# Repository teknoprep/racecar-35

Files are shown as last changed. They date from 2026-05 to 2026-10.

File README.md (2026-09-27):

# racecar-35

Two-MCU dash for a track car.

**Latest Rev C target:** add a third MCU—an on-board ESP32-S3 WiFi coprocessor—to
upload directly from Teensy SD over local SPI, while the screen keeps WiFi for
unchanged OTA and optional upload fallback. Add a replaceable CR2032 on Teensy VBAT
for RTC retention. This is an architecture update, **not an implemented new uplink**;
see [WiFi/RTC requirements](hardware/teensy-integrated-revc/WIFI_RTC_ARCHITECTURE.md).
Rev C has an **internal WiFi PCB antenna** and **all screw terminals on the LEFT
edge**, labelled by function/pin. **Actual 130 × 140 mm routed electrical CAD,
Gerber/drill ZIP, BOM, assembly documents and an assembled view now exist:**
[Rev C engineering prototype](hardware/teensy-integrated-revc/README.md).
It passes ERC/DRC/netlist checks but is unbuilt and not independently approved;
new WiFi firmware, oil/coolant conversions and bench validation remain.
A/B are retired under `hardware/_archive/`, not alternative orderable designs.

**WiFi-only on the CrowPanel since v0.1.148.** Ethernet/W5500 support
and the Internet-route setting have been removed. WiFi credentials/status are
always visible; old saved Ethernet selections are ignored. NTP/OTA/uploads run
through the screen. See [CLAUDE.md](CLAUDE.md) and [BUILD.md](BUILD.md) for current
architecture/toolchains; much of the original overview below is historical.
The integrated Rev C board is an unbuilt electrical prototype. **v0.1.149 source adds
opt-in AFR/lambda logging from the external AEM 30-0300 gauge output** (WHITE signal
and BROWN reference), not a direct oxygen sensor. A protected/scaled ADC input
is implemented in Rev C with clamps and powered-off isolation, but requires
independent review and physical validation. See
[AFR_INTERFACE.md](hardware/teensy-integrated-revc/AFR_INTERFACE.md).

```
+--------------+   Serial2 (UART)   +--------------+   Serial3 (UART)   +--------------+
|              |  pin 7 RX2 / 8 TX2 |              | pin 14 TX3 / 15 RX |              |
|  u-blox GNSS | <----------------> | Teensy 4.1   | -----------------> | CrowPanel S3 |
|              |   38400/9600 baud  |              |    115200 baud     |  7" 800x480  |
+--------------+                    +--------------+                    +--------------+
                                                                         (LovyanGFX UI)
```

The Teensy reads GNSS PVT data from a SparkFun u-blox module and publishes
ASCII CSV lines on Serial3. The CrowPanel ESP32-S3 listens on UART0 and
renders the dash with LovyanGFX. UART is one-way, Teensy → CrowPanel.

## Repository layout

| Path | Project | Target |
| --- | --- | --- |
| `platformio.ini`, `src/main.cpp` | Teensy firmware | Teensy 4.1 |
| `crowpanel-ui/platformio.ini`, `crowpanel-ui/src/main.cpp` | Dash UI | CrowPanel ESP32-S3 7" v3.0 |

Each subproject is its own PlatformIO env. Build them from their own
directory.

## Wire protocol

ASCII CSV lines, `\n`-terminated, 115200 8N1, ~5 Hz:

```
GPS,<fix>,<sats>,<lat_deg>,<lon_deg>,<speed_mph>,<heading_deg>
```

| Field | Meaning |
| --- | --- |
| `fix` | 0=None 1=DR 2=2D 3=3D 4=3D+DR 5=Time-only |
| `sats` | satellites in view |
| `lat_deg`, `lon_deg` | decimal degrees, 6 decimals |
| `speed_mph` | mph, 1 decimal |
| `heading_deg` | course over ground in degrees, 1 decimal |

Example: `GPS,3,12,40.123456,-74.123456,67.5,123.4`

## Wiring

| Link | From | To |
| --- | --- | --- |
| GPS → Teensy | u-blox TX | Teensy pin 7 (Serial2 RX) |
| Teensy → GPS | Teensy pin 8 (Serial2 TX) | u-blox RX |
| Teensy → Dash | Teensy pin 14 (Serial3 TX) | CrowPanel UART0 RX (GPIO 44) |
| Dash → Teensy | Teensy pin 15 (Serial3 RX) | CrowPanel UART0 TX (GPIO 43) |
| Common ground | Teensy GND | CrowPanel GND |
| Power | USB-C to CrowPanel | (Teensy powered separately by its own USB) |

Teensy ↔ CrowPanel is two devices both on 3.3 V logic — no level shifter.
A common ground is required.

## Flashing

### Teensy firmware

```powershell
pio run -t upload
```

The first time, you may need to physically tap the program button on the
Teensy. After that, `teensy_reboot` resets the board over USB.

### CrowPanel firmware

> [!IMPORTANT]
> **Disconnect the two UART jumpers between the Teensy and the CrowPanel
> before flashing the CrowPanel.** UART0 (GPIO 43/44) is shared with the
> CH340 USB-serial chip used to upload firmware. If the Teensy is
> connected, both devices will drive the same wire and the upload will
> fail or corrupt.

```powershell
cd crowpanel-ui
pio run -t upload
```

After the upload finishes ("Hash of data verified"), unplug USB-C, wire
the Teensy back in, then power the CrowPanel via USB-C again.

## End-to-end smoke test

1. Flash both firmwares (Teensy first or CrowPanel first, doesn't matter).
2. Wire everything per the table above. Double-check common GND.
3. Power the CrowPanel via USB-C. The dash should boot and show 0.0 mph
   with `LINK STALE` in red — that's correct: nothing on the wire yet.
4. Plug in the Teensy. Within a second, `LINK` should turn green and you
   should see the speed/heading/lat/lon updating at ~5 Hz, even with no
   GPS fix yet (those fields will read 0 until `FIX` shows `2D`/`3D`).
5. Take it outside or near a window. `FIX` will go yellow → green and
   `SATS` will climb as the module gets a fix.

## Debugging

- Open `pio device monitor` on the Teensy to see the same CSV stream the
  Teensy is sending — useful for confirming the GPS half is working
  before chasing UART issues on the dash side.
- Open `pio device monitor` on the CrowPanel (with the Teensy
  disconnected, and a `Serial.print` of incoming bytes added if you want
  to see what's hitting UART0). Note that with `ARDUINO_USB_CDC_ON_BOOT=0`
  the CrowPanel's `Serial` object IS UART0 — the same wire the Teensy
  uses — so you can't tap it from USB and the Teensy at the same time.
- If the panel boots black, retry the power-only test (USB-C only, no
  Teensy wires) to confirm the panel itself is alive before suspecting
  firmware.

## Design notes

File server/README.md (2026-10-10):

# racecar-35 cloud receiver

Tiny FastAPI service that accepts NDJSON session uploads from the race dash
and stores them on disk. Designed to run as a single Docker container behind
an nginx reverse proxy that terminates TLS — **this service speaks plain HTTP
only**, on port `8089`.

For initial LAN testing you can point the dash directly at this port over
plain HTTP without nginx in the path. Set Internet Protocol = HTTP and use the
LAN IP of the host running the container.

## Endpoints

| Method | Path | Purpose |
| --- | --- | --- |
| POST | `/upload` | Whole-file AfterRace upload (NDJSON). Overwrites by `X-Session-Id` so retries are idempotent. |
| POST | `/stream` | Live-stream append (NDJSON). Reserved for the future Ethernet-mode live path. |
| POST | `/upload/aim` | **Import AiM Race Studio files.** Body = the raw `.xrk` or AiM `.csv`; name via the `X-File-Name` header or `?filename=`. Converted to session NDJSON server-side and filed exactly like a dash upload, so laps/map/replay/coaching all work. The untouched original is archived under `/data/aim/<user>/`. `?coach=0` skips the auto-coach pass. |
| GET | `/` | HTML index of the sessions you're allowed to see (see *Session visibility*). |
| GET | `/sessions` | JSON listing of the sessions you're allowed to see. |
| GET | `/sessions/<user>/<file>` | Download one session file. |
| GET | `/sessions/<user>/<file>/laps` | Auto-detected lap list + times for the review UI (JSON). Start/finish is detected from the GPS trace — no track table needed. |
| POST | `/sessions/<user>/<file>/ai` | **AI corner analysis.** Body `{prompt, region:{points:[[lat,lon],…]}, model?}`. Extracts the telemetry inside the drawn polygon, computes per-lap metrics (entry/min/exit/max speed, time, distance, peak lateral/longitudinal g, max rpm), and asks the LLM for coaching. Returns `{ok, model, metrics, answer}`. Requires `RACECAR_AI_API_KEY`. |
| GET | `/ai/models` | `{enabled, default, models:[{id,name}]}` — the model picker for the review UI. `default` is the resolved analysis model (Haiku 5.5) and is always included in `models`; the gateway catalogue is fetched on a worker thread (cached ~10 min). |
| GET | `/health` | Healthcheck for Docker / nginx. Returns `{"ok":true}`. |
| GET | `/account` | Per-user account page (any signed-in user): view + copy + refresh your upload API key. |
| GET | `/account/apikey` | JSON `{email, api_key}` for the signed-in user (creates a key if missing). |
| POST | `/account/apikey/refresh` | Regenerate the signed-in user's API key. Old key stops working immediately. |
| GET | `/admin` | Admin portal (admins only): add authorized Gmail accounts, grant/revoke admin. |
| GET | `/admin/sessions/targets` | Emails an admin may reassign a session to (all known accounts). Admins only. |
| POST | `/admin/sessions/move` | **Reassign a session to another user.** Body `{user, filename, target}` (target = destination email). Moves the `.ndjson` **and its AI history** into the target's dir; refuses if the target already has a same-named session. Admins only. |
| POST | `/admin/users` | Add an account or change its admin flag (JSON `{email, is_admin}`). Admins only. |
| POST | `/admin/users/delete` | Remove a managed account (JSON `{email}`). Admins only. |
| GET | `/admin/user/<email>` | Per-user screen: ALL USERS toggle + manage who this account can see. Admins only. |
| GET | `/admin/canbus` | CAN-capture portal: upload + list captures, links to review. Admins only. |
| POST | `/admin/canbus/upload?name=` | Upload a CAN sniffer CSV (raw body). Admins only. |
| GET | `/admin/canbus/<file>` | Review a capture: per-ID stats + byte/word signal inspector. Admins only. |
| GET | `/admin/canbus/<file>/data` | Parsed JSON (per-ID frame counts, byte ranges, downsampled series). Admins only. |
| GET | `/admin/canbus/<file>/raw`  | Download the raw CSV. Admins only. |
| POST | `/admin/canbus/<file>/delete` | Delete a capture. Admins only. |
| POST | `/admin/users/visibility` | Set the ALL USERS flag (JSON `{email, view_all}`). Admins only. |
| POST | `/admin/users/grant` | Let an account see another's sessions (JSON `{email, target}`). Admins only. |
| POST | `/admin/users/revoke` | Remove a granted account (JSON `{email, target}`). Admins only. |
| GET | `/docs` | OpenAPI / Swagger UI for poking around. |

## Access control / admin portal

There are three layers, lowest to highest precedence for *display*, but all
additive for *who may sign in*:

1. `RACECAR_ADMIN_EMAILS` (env) — **bootstrap admins**. Always allowed to sign
   in, always admin, and the only accounts that can use `/admin` on a fresh
   deploy. Editable only by changing `.env` + restarting.
2. `RACECAR_ALLOWED_EMAILS` (env) — optional legacy static allowlist (non-admin).
3. **Managed accounts** added from the `/admin` portal at runtime, persisted to
   `/data/users.json` (survives rebuilds; no redeploy needed to add a driver).

If **none** of the three are set, the server stays in open dev mode (any
verified Google account can sign in). Setting `RACECAR_ADMIN_EMAILS` activates
the allowlist: only listed/managed accounts can sign in from then on.

The `/admin` link appears in the header for admin accounts. From there an admin
can add a Gmail address (optionally as admin) and toggle/remove any
portal-managed account. Bootstrap admins show as `locked` and can't be edited
from the UI.

## Session visibility

The sessions index (`/` and `/sessions`) is **scoped per account**:

- Every account always sees **its own** uploaded sessions.
- **Admins** (bootstrap or portal-granted) see **everyone's** sessions.
- A non-admin account can be granted visibility of specific other accounts, or
  of **everyone**, from the admin portal.

In `/admin`, click a managed user (or its **manage** button) to open
`/admin/user/<email>`. That screen has:

- an **ALL USERS** checkbox — tick it and the account sees every user's
  sessions, with no list to maintain (`view_all` on the account record);
- a **can-view list** — type/pick another account's email and **add user** to
  share just that account's sessions; **remove** revokes it.

Visibility is enforced on the index, the JSON listing, downloads, the review
page, the parsed-data endpoint, and web deletes. Device uploads via `X-API-Key`
are unaffected. Settings persist in `/data/users.json` (fields `view_all` and
`can_view`).

## Per-user API keys

Every authorized account gets a unique 12-char API key, minted on first Google
login (or when an admin adds the account) and persisted in `/data/users.json`.
A user views/refreshes their own key from the **account** link in the header
(`/account`). Refreshing replaces the old key immediately.

Send the key as `X-API-Key` on uploads. When no `X-User-Email` header is
supplied, the upload is filed under the key owner's email automatically. This
is independent of the global `RACECAR_API_KEY` env var (which, when set, gates
all ingestion with a single shared secret).

## Request headers honored

These match the dash and Teensy firmware exactly:

```
Content-Type:  application/x-ndjson
X-API-Key:     <secret>           (optional; required if RACECAR_API_KEY is set)
X-User-Email:  user@example.com   (used to namespace files on disk)
X-Session-Id:  1714942567         (used in the saved filename; usually unix epoch)
X-Track-Name:  Lime_Rock_Park     (used in the saved filename)
```

## On-disk layout

```
/data/sessions/<email>/<session_id>_<track>.ndjson
/data/aim/<email>/<session_id>_<original name>.xrk|.csv
```

Where:

- `<email>`, `<track>` are sanitized — anything outside `[A-Za-z0-9._@+-]` becomes `_`.
- `<session_id>` is whatever the dash put in `X-Session-Id` (the start unix epoch).
- `/data/aim/` holds the **unmodified original** of every AiM import, so the
  logger file survives even if a conversion is later found wanting.

## Importing AiM Race Studio files

Race Studio gives you a run in two containers and `POST /upload/aim` takes both:

| | `.xrk` | AiM `.csv` |
| --- | --- | --- |
| how it is read | `libxrk` (chunked, per-channel timecodes, laps table, metadata) | stdlib `csv` |
| units | **metric** — altitude m, speed m/s, WATER_TEMP C, OIL_PRESSURE bar | **imperial** — altitude ft, speed mph, WATER TEMP °F, OIL PRESSURE psi |
| lap boundaries | `laps` table | `Beacon Markers` preamble row |
| sample rate | resampled to 20 Hz | native (20 Hz) |

The two containers do **not** agree on units, so every mapping is driven by the
file's own declaration — Arrow field metadata for `.xrk`, the units row for
`.csv` — and a mismatch aborts the import instead of silently writing wrong
numbers. Cross-check on the reference files: the same run reads 515.25 ft
(CSV) and 157.04 m (XRK) of altitude. (One quirk: AiM labels the `.xrk` AFR
channel `lambda` while the samples are actually A/F, so that channel is
disambiguated from its own values rather than from the label.)

Imported sessions then go through the ordinary `validate_ndjson_body` gate, and
the server's own lap detection reproduces AiM's segment times to within 50 ms.

```bash
# import an .xrk for a given user
curl -X POST 'http://HOST:8089/upload/aim' \
     -H 'X-File-Name: JJ_Summit Main_20261009_152404_a_0318.xrk' \
     -H 'X-User-Email: user@example.com' \
     --data-binary @JJ_Summit_Main.xrk
# {"ok":true,"source":"xrk","session":"1791559444_Summit_Main.ndjson",
#  "samples":30678,"laps":16,...}
```

## Run with Docker

```bash
cp .env.example .env
# edit .env if you want to require an API key

docker compose up -d --build
docker compose logs -f
```

The container exposes port `8089` on the host. Data is persisted to `./data/`
on the host. Health probe runs every 30 s.

To check that everything is responsive:

```bash
curl http://localhost:8089/health
# {"ok":true,"service":"racecar-35 cloud","data_dir":"/data"}
```

## Configure the dash for this server

Settings → cloud rows on the dash, when **Internet mode = WiFi**:

```
Cloud host:   <LAN IP of the docker host>   e.g. 192.168.1.50
Cloud port:   8089
Protocol:     HTTP                          (HTTPS is the default; switch to HTTP for LAN test)
User email:   anything you want (used to namespace files)
API key:      match RACECAR_API_KEY, or any value if RACECAR_API_KEY is empty
Record cloud: ON
```

Then TOOLS → **Start test mode** → wait ~10 s → **Stop test mode**.

If everything is wired up correctly, you'll see (in `docker compose logs -f`):

```
INFO racecar.cloud: received 192.168.1.123 mode=w email=anon session=1714... track=TEST bytes=14352 lines=58 -> sessions/anon/1714..._TEST.ndjson
```

And opening `http://<host>:8089/` in a browser shows the new session in the table.

## Basemap for the session map (review page)

The review page's Leaflet map takes its tiles from `RACECAR_MAP_TILES`, and the
default is **keyless Esri imagery** — the same source `/tools/sfpicker` and the
lineview popout already use.

Why it is configurable: the previous basemap was CARTO's `dark_nolabels`, and
CARTO's raster basemaps now **require an API key**. Without one,
`basemaps.cartocdn.com` returns a 256x256 **“API KEY REQUIRED”** placeholder
tile instead of map data — the giveaway is that two different tile coordinates
come back byte-identical. So no key is needed at all; the map simply moved to a
provider that does not require one.

Read at startup, so **`docker compose up -d` is enough — no `--build`**:

| Var | Default | Notes |
| --- | --- | --- |
| `RACECAR_MAP_TILES` | Esri `World_Imagery` | Tile URL template; empty = no basemap |
| `RACECAR_MAP_ATTRIB` | `Imagery © Esri, Maxar, Earthstar Geographics` | Attribution shown in the corner |
| `RACECAR_MAP_MAXZOOM` | `19` | Leaflet max zoom |
| `RACECAR_MAP_DEM` | AWS `terrarium` tiles | Elevation for `/track3d`; `none` = flat ground |

Dark map instead of imagery (keeps the old look; Esri's canvas basemaps have
native data only to z16, so zooming past that upscales):

```bash
RACECAR_MAP_TILES='https://server.arcgisonline.com/ArcGIS/rest/services/Canvas/World_Dark_Gray_Base/MapServer/tile/{z}/{y}/{x}'
RACECAR_MAP_ATTRIB='Tiles (c) Esri'
```

⚠️ Esri tile paths are `/{z}/{y}/{x}` (row/col) — **not** `/{z}/{x}/{y}`.
Swapping those two gives you a map of the wrong place, not an error.

## 3D drive view (`/track3d/<user>/<file>`)

Opened from the review page's **3D drive ↗** button (or copied straight out of
the URL bar). It is the same session in the driver's seat: satellite imagery
**draped over real terrain**, the line you drove painted on the ground, brake /
apex / throttle markers, a HUD (mph, rpm, lap, lap time, altitude) and a chase
camera that drives the trace on the same playback clock — play/pause,
¼×–8×, scrub, zoom. Drag the map and the camera releases so you can look
around; **follow** grabs it back.

Layers are toggles on one map, so nothing is refetched when you flip them:
**satellite** off = black ground (the lines read like a light table), **terrain**
off = flat. Both choices are remembered per browser (`localStorage`). The same
**satellite** checkbox sits under the map on the review page and on the lineview
popout.

The ground is raster imagery draped on a surface mesh — **not** photogrammetry:
true 3D buildings/trees would need a keyed source such as Google Photorealistic
3D Tiles. Elevation comes from `RACECAR_MAP_DEM` (keyless AWS `terrarium`),
native to ~z15.

Hand a lasso polygon over (`?pts=lat,lon|lat,lon|…`, which the review-page
button does automatically when a section is circled) and the page also draws the
**ideal line** (fastest real traverse on record, green) and **your session best
through it** (blue) over the ground, with that lap's brake point — the
"what I did vs what the data says is fastest" comparison, in the driver's view.

## AI corner analysis (review page)

The review page has an **AI Corner Analysis** card. Click **circle a section**,
then drag a loop around a corner (or a set of corners) on the track map — the
samples inside that polygon, **across every lap**, become the context for an LLM
coaching prompt. Preset buttons cover the common questions (brake zones, entry
speed, exit speed, best line, consistency) and there's a free-text box for
anything else.

How it works:
1. The browser sends the drawn polygon + question to `POST /sessions/<u>/<f>/ai`.
2. The server reprojects every sample through the same auto lap-detector the
   review page uses, keeps the points inside the polygon, and computes **per-lap
   metrics** for that section: entry / min / exit / max speed, time, distance,
   peak lateral & longitudinal g, max rpm.
3. Those metrics become a compact table in a race-engineer system prompt, sent to
   **Open WebUI** (`ai.blueuc.com`) via its OpenAI-compatible
   `POST /api/chat/completions` (Bearer key). The reply is rendered in the card.

**Config (`.env`):**

| Var | Purpose |
| --- | --- |
| `RACECAR_AI_API_KEY` | Open WebUI API key. **Blank = the AI card is hidden entirely.** |
| `RACECAR_AI_BASE_URL` | Open WebUI base (default `https://ai.blueuc.com`). |
| `RACECAR_AI_ANALYSIS_MODEL` | Model for **AI corner analysis + the ideal-line AI** (and the model the review dropdown preselects). **Blank = Haiku 5.5.** |
| `RACECAR_AI_COACH_MODEL` | Model for the **automatic coach checklist** (runs on every upload). **Blank = Haiku 5.5.** |
| `RACECAR_AI_HAIKU_MODEL` | The built-in Haiku id used by the two vars above (default `anthropic.anthropic/claude-haiku-5.5`). |
| `RACECAR_AI_MODEL` | **Legacy/allowlist seed only** — it no longer selects the model for the checklist or the analysis. It seeds `RACECAR_AI_MODELS` when that is unset. |
| `RACECAR_AI_MODELS` | CSV ALLOWLIST: the only models the UI may offer and the server will accept. Unset ⇒ full live catalogue. |
| `RACECAR_AI_TIMEOUT_SECONDS` | Upstream timeout (default 120). |

The two SURFACES (checklist, analysis) default to **Haiku 5.5** because the
checklist runs on every upload and the analysis card is used many times a
session. Their configured id is matched against the gateway's live catalogue, so
a naming variant (`anthropic.anthropic/claude-haiku-5.5` vs `…claude-haiku-5-5`,
provider prefix, date suffix) still resolves; if nothing matches, the configured
id is sent as-is — never silently swapped for another model. `GET /caps` reports
both (`ai_models`) so one curl proves a switch landed.

The review UI also fetches the live model list (`GET /ai/models`) into a
dropdown, so a user can override the model per question; the analysis model is
the fallback (and is always present in the list). After setting these, recreate
the container (`docker compose … up -d`) — no rebuild needed since it's just
env.

**Persistent history + cascade delete.** Every question + answer is saved per
session under `RACECAR_DATA_DIR/ai_history/<user>/<sessionfile>.json` and shown
as a collapsible list in the AI card (newest first; each item has *show region*
— redraws the polygon on the map — and *delete*). `GET .../ai/history` lists them,
`POST .../ai/delete {id}` removes one. **Deleting the session deletes its entire
AI history** (session `DELETE` / `/delete` cascade). Open WebUI's `<details>`
cost/token footer is stripped server-side (admin-only info) so only the coaching
text is stored/shown.

## Lap detection + review page

The review page (`/review/<user>/<file>`) shows a **lap table** and a
**delta-vs-best trace** in addition to the map / playback / G-meter.

Laps are detected server-side (`/sessions/<user>/<file>/laps`) straight from
the GPS trace — the cloud has no track table, so it **auto-detects the
start/finish line**: it anchors on the first moving fix, then closes a lap
each time the car returns within 40 m of that anchor (after leaving by >80 m),
guarded by a 20 s minimum lap time. Lap boundaries come back as
seconds-from-start so the browser can map them onto its sample array at any
stride. Constants live at the top of `_detect_laps()` in `app/main.py`
(`_LAP_RADIUS_KM`, `_LAP_MIN_SEC`, `_LAP_MOVING_MPH`).

On the page:
- the **lap table** lists every lap with its time, gap to best, and max speed;
  the fastest lap is highlighted.
- clicking a lap makes it the **primary lap**: it's highlighted on the map
  (the reference/ghost lap overlaid as a dashed green line), playback is
  scoped to just that lap, and the **delta trace** redraws — a
  distance-aligned time delta of the primary lap vs the reference lap (below
  zero / green = faster, above / red = slower).
- a **follow-dot** rides the delta trace in sync with playback (and with the
  map marker), so you can scrub to any corner and read whether you were up or
  down there. The live delta at the cursor is shown to the right of the chart.

### Comparison mode (incl. across sessions)

By default the reference lap is **this session's best lap**. You can instead
compare against **any lap from any session you're allowed to see** — e.g. an
admin diffing their own quick lap against another driver's lap in the same car:

- a **filterable session picker** (type to filter; backed by `/sessions`)
  chooses the comparison session;
- a **lap picker** then lists that session's laps, each labelled with its time
  and either `(fastest)` or the gap from that session's fastest lap;
- **best lap** resets back to this session's best.

Cross-session laps are fetched on demand (`/data` + `/laps`) and cached. The
delta is distance-aligned, so it only makes sense for laps of the **same
track**.

### Sync mode

A **sync** toggle controls how the comparison lap is sampled against the
primary lap during playback:

- **time** — the comparison car is shown at the **same elapsed time** into the
  lap, which is generally a *different* place on track, so it gets its own
  **red map dot** alongside the amber primary dot. Watch the gap open/close.
- **location** — the comparison is sampled at the **same place** on track (one
  dot), and its telemetry (speed / RPM / heading) is shown in **red** beneath
  the primary values so you can read "here I was 112 vs 118 mph" corner by
  corner.

The dash firmware does its own on-car lap timing (predictive lap time + live
delta vs the session best, shown in the middle column of the dash). The cloud
view is the post-session analysis counterpart.

## CAN-bus captures (admin)

The dash's CAN sniffer (Tools → Start CAN capture) writes a CSV per run
(`t_ms,id,ext,dlc,d0..d7`, data bytes in hex) to reverse-engineer the MS3Pro
broadcast byte layout. Instead of pulling the SD card, you can now upload that
CSV straight into the **admin → CAN captures** portal and analyse it in the
browser:

- **Upload** is a plain file picker (sent as a raw POST body — no extra deps).
  Files land in `RACECAR_DATA_DIR/canbus/<name>.csv`.
- The **review page** parses the capture server-side and shows, per CAN ID,
  the frame count + rate and each data byte's min/max/range. Pick an ID and:
  - the **bytes plot** draws d0–d7 over time (the changing bytes are enabled by
    default — a flat line means that byte never moved, a ramp means it carries
    a live signal);
  - the **16-bit word inspector** combines an adjacent byte pair (selectable
    start byte + big/little-endian) into a single value and plots it, so you
    can confirm e.g. "0x5F0 bytes 6–7 BE" ramps cleanly with RPM.

Capture while sweeping the throttle: the byte/word that tracks engine speed is
your RPM field. Note the ID + start byte + endianness and lock them into
`pumpCAN()` in `src/main.cpp`. Everything here is **admin-only** and the
filename is sanitised (no path traversal, single `.csv` on disk).

## Firmware / OTA hosting

The server also hosts the dash OTA feed, so updates don't depend on GitHub
raw's CDN (which ignores query-string cache-busting and serves ~5 min stale
after a push — the "new version isn't immediately available" problem).

| Method | Path | Auth | Notes |
| --- | --- | --- | --- |
| GET | `/firmware/manifest.json` | none | Served **`Cache-Control: no-store`** → dash sees a new version instantly |
| GET | `/firmware/list` | none | JSON: each stored artifact's name + size + sha256 |
| GET | `/firmware/{file}` | none | Serves a stored `.bin`/`.hex` (device verifies sha256 from the manifest) |
| POST | `/firmware/upload?name=<file>` | `X-API-Key` | Body = raw artifact bytes. Only `.bin`/`.hex`/`.json` names allowed |

Stored under `RACECAR_DATA_DIR/firmware/` (survives container rebuilds). The
dash firmware's `OTA_MANIFEST_URL` points at `/firmware/manifest.json`; the
manifest's artifact URLs point back at `/firmware/<file>`.

### Publishing a release to the server

Build the four artifacts (see [../BUILD.md](../BUILD.md)), then:

```bash
RACECAR_API_KEY=<server RACECAR_API_KEY> \
  ./server/publish_firmware.sh 0.1.73 https://racecar.api.blueuc.com
```

This uploads all four binaries, then a **server-pointed manifest** (artifact
URLs = `<base>/firmware/<file>`, every `version` = the arg, legacy `crowpanel`
alias = `crowpanel7`), and prints the live manifest to verify. Binaries upload
first so the manifest never references a not-yet-present artifact.

### One-time transition off GitHub

Devices only start reading the server after they run firmware whose
`OTA_MANIFEST_URL` is the server. So the switch is a **single transition
release** published to BOTH places:

1. Rebuild + redeploy this container (so `/firmware/*` exists).
2. `publish_firmware.sh <ver>` → populate the server.
3. Cut the transition firmware (the one with the server `OTA_MANIFEST_URL`) to
   **GitHub** as usual, so devices still on the old GitHub-pointed firmware can
   OTA up to it one last time.
4. From then on, publish only with `publish_firmware.sh` — no CDN lag.

## The “update server” button (host updater)

The `/admin` header has an **update server** button. It cannot rebuild the app
from inside the container (no docker socket, no git checkout), so it only
**writes a request** (`<data>/update_request.json`); a small host-side watcher,
`server/host_updater.sh`, runs `git pull && docker compose … up -d --build` and
writes progress back to `<data>/update_status.json`, which the button polls.

### One-time install (on the server host, as root)

```bash
cd /docker/racecar.api.blueuc.com
sudo bash ./server/host_updater.sh --install    # use `bash` — see the note below
sudo apt-get install -y inotify-tools          # optional: instant instead of 10 s polling
```

It installs `racecar-updater.service` (blocks on inotify, reacts instantly) and
a 5-minute safety timer that catches a request the watcher missed. Do **not**
copy the script to `/usr/local/bin` — it self-locates the repo/data paths from
its own position.

⚠️ Call it as `bash ./server/host_updater.sh` (or `chmod +x` it once). If the
executable bit is missing, `sudo ./server/host_updater.sh --install` just says
`Permission denied` — an easy 30 minutes to lose.

### “It just says queued… waiting for host watcher”

That means the request file is there and **nothing consumed it** — nearly always
the watcher was never installed. One command answers it:

```bash
sudo bash ./server/host_updater.sh --doctor     # read-only health check + verdict
```

It checks the checkout, compose file, docker daemon, data-dir writability,
inotify, the systemd units, the watcher/timer state and origin reachability, then
prints either `VERDICT: the updater is healthy` or the exact fix. Related:

| Symptom | Cause | Fix |
| --- | --- | --- |
| queued forever, `host: …` never appears | watcher not installed / not running | `--doctor`, then `--install` |
| `Permission denied` on install | exec bit missing in the checkout | call it with `bash` (fixed in git, but old checkouts are 644) |
| `host: failed` — `git pull: …` | host checkout can’t reach/authenticate to origin | fix the remote on the host; `--doctor` tests it |
| `host: failed` — `compose: …` | image build error | read the tail in `update_status.json`, fix, `--now` |
| button appears to do nothing at all | request written but UI had no answer | the admin UI now shows the reason + the command to run |

Ship a pending change **right now**, synchronously, printing the result:

```bash
sudo bash ./server/host_updater.sh --now
```

## Behind nginx (production)

Minimal nginx server block, assuming you've already got TLS termination on
some public hostname:

```nginx
server {
    listen 443 ssl http2;
    server_name racecar.api.blueuc.com;

    # ... ssl_certificate / ssl_certificate_key / etc ...

    client_max_body_size 96M;          # allow long sessions

    location / {
        proxy_pass http://127.0.0.1:9000;   # RACECAR_HOST_PORT (default 9000)
        proxy_set_header Host              $host;
        proxy_set_header X-Real-IP         $remote_addr;
        proxy_set_header X-Forwarded-For   $proxy_add_x_forwarded_for;
        proxy_set_header X-Forwarded-Proto $scheme;
        proxy_read_timeout 120s;
    }
}
```

uvicorn is started with `--proxy-headers --forwarded-allow-ips "*"` in the
Dockerfile so it will trust the `X-Forwarded-*` headers nginx sets.

## Local sanity test without the dash

```bash
echo '{"t":1,"speed_mph":42.0}' > /tmp/one.ndjson
curl -i -X POST http://localhost:8089/upload \
     -H 'Content-Type: application/x-ndjson' \
     -H 'X-User-Email: test@example.com' \
     -H 'X-Session-Id: 1714999999' \
     -H 'X-Track-Name: BenchTest' \
     --data-binary @/tmp/one.ndjson
# {"ok":true,"mode":"upload",...}

curl http://localhost:8089/sessions
# {"sessions":[{"user":"test_example.com","filename":"1714999999_BenchTest.ndjson",...}],"count":1}
```

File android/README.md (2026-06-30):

# RaceDash Mobile (Android)

A standalone, **phone-only** track dash + data logger for non-MS3Pro cars. Uses
the phone's own sensors — no car wiring required:

| Channel | Source on the phone |
| --- | --- |
| GPS (position / speed / heading / sats) | `FusedLocationProvider` + `GnssStatus` |
| Gyro + accelerometer (lateral / longitudinal G) | `SensorManager` (TYPE_GYROSCOPE / TYPE_ACCELEROMETER) |
| **RPM** | **Microphone** — acoustic estimate from the engine's firing frequency, configured by cylinders + stroke |
| Lap timing | GPS start/finish geofence + ghost-lap predictive engine (ported from the firmware dash) |
| Recording | NDJSON to app storage (same descriptive-key shape the web analyzer consumes) |

## How the acoustic RPM works
A 4-stroke engine fires `cylinders/2` times per crank revolution, so the exhaust
note has a fundamental at `f_fire = (RPM/60) × (cylinders/2)` Hz — **hundreds of
Hz, not thousands** (an 8000-RPM four-cylinder is ~267 Hz; an F1 V8 at 18,000 RPM
is ~1.2 kHz). The "high-pitched scream" your ear hears is the *harmonics*, not the
fundamental.

Pipeline (`sensors/AcousticRpm.kt`): `AudioRecord` (UNPROCESSED, no AGC) →
box-decimate → Hann window → FFT → **Harmonic Product Spectrum** over the firing
band (rejects 2×/½× octave errors) → parabolic peak interp → confidence gate →
EMA + slew-limit smoothing. Set **Cylinders / Stroke / Idle / Redline** in
Settings — these define the search band and the Hz→RPM conversion.

> Honest expectation: a *rough* tach (≈±200–500 RPM in good conditions), not
> logging-grade. It's the price of "no extra hardware." Confidence is shown live
> next to the RPM number (`mic NN%`); low-confidence frames read `----`.

## Build
No Gradle wrapper jar is committed — open the **`android/`** folder in
**Android Studio** (Hedgehog or newer) and let it sync; it provisions Gradle
8.7 from `gradle/wrapper/gradle-wrapper.properties` automatically. Then Run on a
device.

CLI alternative (with a local Gradle 8.7 + Android SDK installed):
```bash
cd android
gradle wrapper          # one-time: generates the wrapper jar/scripts
./gradlew assembleDebug # -> app/build/outputs/apk/debug/app-debug.apk
```

Requirements: JDK 17, Android SDK 34, a device on Android 8.0+ (minSdk 26) with
Google Play Services (for fused location). Grant **Location** + **Microphone**
when prompted.

## Project layout
```
app/src/main/java/com/racedash/mobile/
  data/      Tracks, Settings (SharedPreferences), SessionRecorder (NDJSON)
  sensors/   LocationProvider, MotionProvider, AcousticRpm (+ Fft)
  lap/       LapTimer (ghost-lap predictive)
  vm/        DashViewModel (sensor fusion, 20 Hz state + logging), DashState
  ui/        MainActivity, DashScreen, SettingsScreen, TrackPickerScreen, theme/
```

## Recorded data
`<app external files>/sessions/session_<unixtime>_<track>.ndjson`, one JSON
object per ~50 ms:
```json
{"t":1714942567.234,"fix":3,"sats":12,"lat":40.123456,"lon":-74.123450,
 "alt_m":123.4,"speed_mph":67.5,"heading_deg":123.4,"rpm":5800,"rpm_conf":0.74,
 "ax":-0.92,"ay":0.31,"az":0.05,"gx":1.2,"gy":-3.4,"gz":0.8,"lap":2,"lap_ms":48213}
```
Pull via `adb pull` or USB MTP, or wire up the upload endpoint later.

## Not done yet (deliberately, v0.1.0)
- Foreground service for screen-off / backgrounded recording (currently the
  screen is kept on and the app must stay foreground).
- Cloud upload (the NDJSON shape is already analyzer-compatible).
- Editable track list / on-device start-finish naming.
- On-device validation of the acoustic estimator against a known tach.

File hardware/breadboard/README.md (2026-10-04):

# Solderable breadboard — Teensy 4.1 (no Rev C PCB)

This is the **build you solder**. Rev C Gerbers are parked. All car wires land on
**screw terminals along the LEFT edge**. The Teensy sits on the right, USB facing
out for flashing.

Open [BREADBOARD.svg](BREADBOARD.svg) in a browser for the picture. This file is
the soldering notes + parts list. **For the wire-by-wire pinout sheet see
[PINOUT.md](PINOUT.md)**, and for the tach front end see
[OPTO_WIRING.svg](OPTO_WIRING.svg) (PC817 pinout, schematic, bench check).

**Pi 5 is a separate box.** Only three 3.3 V UART wires come here (J3). Cameras
and the USB stick do **not** plug into this board.

## What goes on this board

| On the protoboard | Off the board |
| --- | --- |
| Teensy 4.1 | CrowPanel (cabin) via J2 |
| PC817 tach opto + 1 kΩ + 4.7 kΩ | Raspberry Pi 5 video box via J3 |
| Oil 10 kΩ / 20 kΩ divider | ELP cameras + USB stick (on the Pi) |
| Coolant 150 Ω pull-up | AEM 30-0300 **gauge** (powered from the car, not us) |
| AEM 20 kΩ / 20 kΩ + 1 kΩ / 100 nF | 12 V → 5 V buck (feeds J1, not raw 12 V) |
| Optional: GPS + IMU modules | |

## Screw terminals — LEFT edge, top to bottom

Same idea as Rev C: one edge, labelled, nothing on the other three sides.

| Block | Positions (left → right as you face the screws) | Car / cable |
| --- | --- | --- |
| **J1 POWER** | `5V` · `GND` | Output of a **5 V** buck (3 A+). **Never 12 V.** Also feeds J2 5V. Cut Teensy **VUSB–VIN** if USB and J1 are both live. |
| **J2 SCREEN** | `GND` · `5V` · `TX` · `RX` | CrowPanel **J10 only** (XH2.54, the large one). `TX` = Teensy pin 14 → screen RX. `RX` = Teensy pin 15 ← screen TX. **Never CrowPanel J2 / HY2.0** (5 V there kills the ESP32). |
| **J3 VIDEO** | `GND` · `TX` · `RX` | Pi 5 header 6 / 10 / 8. `TX` = Teensy pin 1 → Pi GPIO15. `RX` = Teensy pin 0 ← Pi GPIO14. **3.3 V only. No 5 V.** 1 kΩ in series on both data lines on this board. |
| **J4 TACH** | `SIG` · `GND` | Conditioned ECU / cluster tach **only**. Not coil-neg, spark, or injector. |
| **J5 OIL** | `5V` · `SIG` · `GND` | 5 V 0.5–4.5 V transducer (150 PSI typical). |
| **J6 NTC** | `SIG` · `GND` | Two-wire coolant sender. Dedicated GND — do not rely on the engine block. |
| **J7 AEM** | `WHT` · `BRN` | AEM 30-0300 Power/IO **pin 9 WHITE** and **pin 10 BROWN**. Gauge keeps its own 12 V / 5 A fuse. We take analogue only. |

## Circuits you solder (values are firmware contracts)

### Tach — PC817 on the board (J4 → pin 9)

Full diagram: **[OPTO_WIRING.svg](OPTO_WIRING.svg)**. The LED is inside the PC817
(1 = anode, 2 = cathode); you never add one.

```
J4 SIG ── 1 kΩ ── PC817 pin 1 (anode)
J4 GND ────────── PC817 pin 2 (cathode) ── board GND

3.3 V ── 4.7 kΩ ──┬── PC817 pin 4 (collector) ── Teensy pin 9
                  └── 100 nF to GND (optional, right at pin 9)
GND ─────────────── PC817 pin 3 (emitter)
```

DIP-4, notch up: pin 1 is top-left. Output is inverted; firmware does not care.
Tach at pin 9 must swing 0–3.3 V. LOW must go below ~0.8 V.

### Oil — 10 kΩ / 20 kΩ (J5 → pin 16 / A2)

Firmware expects `V_adc = V_sensor × 2/3`.

```
J5 5V  ──────── Teensy 5V (or J1 5V)
J5 GND ──────── board GND
J5 SIG ── 10 kΩ ── Teensy pin 16 (A2) ── 20 kΩ ── GND
                         └── 10 nF to GND (optional, at the pin)
```

At atmosphere a 0.5–4.5 V sender reads ~0.5 V on J5 SIG (~0.33 V on A2).

### Coolant — 150 Ω to 3.3 V (J6 → pin 17 / A3)

VDO 1600–22 Ω curve. Different sender = different pull-up (see WIRING.md).

```
3.3 V ── 150 Ω ──┬── Teensy pin 17 (A3)
J6 SIG ──────────┘
J6 GND ──────────── board GND
```

### AEM AFR — 0.500 gain, NEVER raw 5 V (J7 → pin 20 / A6)

WHITE can be 5 V. Teensy ADC dies at 3.6 V. This divider is not optional.

```
J7 WHT ── 20 kΩ 0.1% ──●── 20 kΩ 0.1% ── J7 BRN ── board GND
                       │
                       └── 1 kΩ ── Teensy pin 20 (A6) ── 100 nF ── GND
```

Settings → **AEM 30-0300 AFR input** stays OFF until this is soldered and
metered: 5.00 V on WHT-BRN must read ~2.50 V on pin 20.

## UART (two different links — do not mix)

| Link | Teensy | Other end | Baud | Levels |
| --- | --- | --- | --- | --- |
| Dash | 14 TX, 15 RX, GND | CrowPanel **J10** RX / TX / GND (+5 V if the screen is powered from J1) | 921600 | Screen J10 is 5 V-tolerant via its shifters |
| Video | 1 TX, 0 RX, GND | Pi 5 GPIO15 / GPIO14 / GND | 115200 | **3.3 V both ends** |

TX/RX are **crossed** on both cables.

## Optional modules on the protoboard (no extra terminals)

| Module | Teensy | Power |
| --- | --- | --- |
| u-blox NEO-M9N | pin 7 RX ← GPS TX, pin 8 TX → GPS RX | 3.3 V / GND |
| GY-521 MPU-6050 | pin 18 SDA, pin 19 SCL | **3.3 V** (not 5 V), AD0 to GND |
| CAN transceiver module | pin 22 TX, pin 23 RX | **5 V VCC + 3.3 V VIO — NOT 3.3 V on VCC. See the warning below.** |

⚠️ **The Amazon "3-Pack SN65HVD230 CAN Transceiver Module" (ASIN B0FDLDXCK9) is
MISLABELLED — the SOIC-8 on it behaves as a TJA1051T/3-class chip, not an SN65HVD230.**
The two parts share the footprint but not the pin meanings, so wire it as a TJA1051T/3:

| Module pin | SN65HVD230 would be | What the fitted chip actually needs |
| --- | --- | --- |
| 3 (VCC) | 3.3 V | **5 V** (needs 4.5–5.5 V; the driver is locked out below that) |
| 5 | Vref — leave floating | **VIO = 3.3 V** — floating it lets TXD phantom-feed RXD (measures ~2.1 V) |
| 8 | Rs | **S / standby → GND** (high = receive-only, never ACKs) |

Wired the SN65HVD230 way (VCC = 3.3 V, pin 5 floating, pin 8 floating) the logger
**receives but never transmits a dominant bit**, so it never ACKs; the sender then
retransmits ~3,800 identical frames/s and values update only a few times a second.
With VCC 5 V / pin 5 3.3 V / pin 8 GND it runs at exactly 200 frames/s, both IDs, 0
errors. Full analysis and the un-foolable acceptance tests:
`../CAN-TRANSCEIVER-FINDINGS-2026-10-04.md`.

## Parts to buy for this board

| Qty | Part | Why |
| ---:| --- | --- |
| 1 | Solderable protoboard ≥ 100 × 150 mm (plated holes, 2.54 mm) | Everything lives here |
| 1 | Teensy 4.1 + 2× 24-pin headers (socket if you want it removable) | |
| 7 | Screw-terminal blocks, 5.08 mm, mix of 2- and 3-position (J2 is 4-pos) | Left-edge harness |
| 1 | PC817 (or 4N35) DIP-4 | Tach |
| 1 | 1 kΩ ¼ W (tach LED) | |
| 1 | 4.7 kΩ ¼ W (tach pull-up) | 10 kΩ is also fine |
| 1 | 150 Ω ¼ W (coolant) | |
| 1 | 10 kΩ ¼ W (oil series) | |
| 1 | 20 kΩ ¼ W (oil bottom) | |
| 2 | 20 kΩ **0.1%** (AEM divider) | Gain is a firmware constant |
| 1 | 1 kΩ (AEM filter) | |
| 2 | 1 kΩ (video UART series) | |
| 3 | 100 nF ceramic | AEM filter + decoupling |
| 1 | 10 nF ceramic | Oil (optional) |
| 1 | 5 V ≥ 3 A buck, 12 V in, screw terminals out | Feeds J1. Not the Pi 5 supply. |

## Solder order

1. Headers / socket for the Teensy. Confirm pin 0 is the corner next to GND/USB.
2. Seven terminal blocks on the **left** edge. Label them **before** wires go in.
3. Star GND: one fat jumper from J1 GND to a ground rail, then every circuit GND to that rail. Do not daisy-chain sensor grounds through each other.
4. Tach PC817 + 1 kΩ + 4.7 kΩ. Bench: pulse J4 SIG with 12 V through the 1 kΩ, pin 9 should toggle.
5. Oil divider. Meter A2 < 3.3 V with the sender at 5 V full-scale.
6. Coolant 150 Ω.
7. AEM divider. Meter pin 20 with a 5 V bench supply on J7 **before** enabling `afraem`.
8. J2 four wires to CrowPanel J10. Disconnect them whenever you USB-flash the screen.
9. J3 three wires + 1 kΩ series to the Pi 5. Power the Pi from its own 5 V 5 A USB-C.

Firmware v0.1.150: Settings → **Video interconnect** ON only after J3 is wired.
Settings → **AEM 30-0300 AFR input** ON only after J7 is metered.

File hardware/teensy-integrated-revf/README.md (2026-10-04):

# Rev F — four-layer integrated trunk logger

**UNBUILT ENGINEERING PROTOTYPE. NOT INDEPENDENTLY REVIEWED OR PHYSICALLY
VALIDATED.** A clean CAD report is not electrical approval, a thermal test, an
RF measurement, or evidence that the board works.

Produced to close three gaps in Rev C: the missing Raspberry Pi video UART and the
missing throttle-position and brake-pressure analog inputs.

**Rev E closed two more:** the 5 V rail is **our own TPS54560B converter** instead of a
Pololu module that could not be sourced, and the **car's own input voltage is measured on
the board** instead of being inferred from the ECU or a Bluetooth dongle.

**Rev F closes the CAN gap.** The external SN65HVD230 plug-in module and its `J7` header
are **deleted**; a **TCAN1042HGV-Q1** is soldered on with its **STB pin hard-tied to GND**,
and `J14` presents `CANH` / `CANL` / `GND` with switchable split termination. See
[Onboard CAN (Rev F)](#onboard-can-rev-f--no-plug-in-module).

## Deliverable

- **`Racecar-RevF-GERBERS-ENGINEERING-PROTOTYPE.zip`** — 11 Gerber layers
  (4 copper + both masks/silkscreens/pastes + Edge.Cuts), separate metric
  **PTH and NPTH** Excellon drills with maps, schematic PDF, BOM, assembly
  positions CSV, fabrication/assembly/bring-up notes, editable CAD, validation
  reports and a SHA-256 manifest. Verified CRC and per-file hashes.

## Status at export

| Check | Result |
|---|---|
| ERC | **0 violations** |
| DRC (full severity) | **0 violations** |
| Unconnected items | **0** |
| Pin-contract / geometry / calculation assertions | **749 passed** |
| Schematic ↔ PCB connected pads | **538 agree** |
| Footprints / nets / routed items | 193 / 104 / 1,647 segments with 131 vias |

## Onboard CAN (Rev F) — no plug-in module

**Problem (root-caused on the bench, 2026-10-04).** The external CAN module on `J7` received
frames but **never drove the bus**, so it never ACKed and the sender retransmitted ~3,800
identical frames/s. The module — sold as an "SN65HVD230" — actually carries a
**TJA1051T/3-class chip**, and the two share a footprint but not a pinout: pin 3 (VCC) needs
**5 V** (the driver locks out below 4.5 V), pin 5 is **VIO** not Vref, and pin 8 is **S /
standby**. Driven the SN65HVD230 way (VCC = 3.3 V, pin 5 floating, pin 8 floating) the driver
was locked out, and a floating VIO was phantom-fed from TXD (~2.1 V), so RXD collapsed
whenever TXD went low — an internal echo that made every Teensy-side self-test *look* like a
working transmitter. Rewired as VCC 5 V / pin 5 3.3 V / pin 8 GND it ran at exactly 200
frames/s, both ids, 0 errors. Full analysis:
`../../CAN-TRANSCEIVER-FINDINGS-2026-10-04.md`.

A plug-in module therefore has three failure modes the carrier cannot control: the wrong chip
on the board, the wrong wiring to it, and no 5 V rail on a USB-only bench. Rev F removes all
three by **soldering down a known part with the rails and mode pin hard-wired**.

**Fix: a soldered transceiver whose supply and mode pin cannot be wrong.**

* `U21` = **TI TCAN1042HGVDRQ1** (`TCAN1042HGV-Q1`), SOIC-8, AEC-Q100, ±70 V bus fault
  protection, **`VIO` on pin 5** for 3.3 V logic. **Authorized distribution only; no
  substitution without written approval.** Approved alternates, in order: `TCAN1042VDRQ1`,
  then NXP `TJA1051T/3/1J` (its pin 8 `S` must also go to GND).
  ⚠️ **The `V` suffix is mandatory** — it *is* the VIO pin. `TCAN1042DRQ1` / `TCAN1042HDRQ1`
  / `TCAN1042GDRQ1` have **pin 5 = NC**, so RXD would swing to 5 V and destroy Teensy pin 23.
  **Never** an SN65HVD23x, a plain `TJA1051T` (no `/3`), a `TJA1050`, or any clone.
* Pins: 1 `TXD`→`CAN_TX` (Teensy pin 22 = U1 pad 29), 2 `GND`, 3 `VCC`→`+5V_MAIN`,
  4 `RXD`→`CAN_RX` (Teensy pin 23 = U1 pad 28), 5 `VIO`→`+3V3_MCU`, 6 `CANL`, 7 `CANH`,
  **8 `STB` hard-tied to GND**. `STB` high is standby = receive-only with no ACK — exactly
  the state being designed out — so there is no pull-up, no resistor and no jumper on it.
* Decoupling `C49`/`C50` 100 nF at VCC/VIO and `C51` 1 µF on VCC. `U21` needs the 5 V rail,
  so **CAN does not work on Teensy-USB power alone**; the bench needs `J1` powered. That a
  powered `VIO` with `VCC` off (USB-only bench) leaves the bus passive must be confirmed
  against the TCAN1042 datasheet — this document does not claim it.
* `J14` "CAN" (Phoenix **1729021**, 3-position 5.08 mm, the same family as J4/J11/J12):
  **1 `CANH`, 2 `CANL`, 3 `GND`** (signal-ground reference to the ECU).
* **Switchable split termination**: `R58` + `R59` = two **60.4 Ω 1 %** in series (120.8 Ω
  across the pair), midpoint to GND through `C52` 4.7 nF (50 V), in series with **`JP2`**.
  **Fit the JP2 shunt only if this board is an end of the bus.**
* `D25` = **onsemi NUP2105LT1G** dual CAN TVS at `J14` (alternates: Nexperia `PESD2CAN,215`
  or TI `ESD2CAN24DBZRQ1`).
* Test points `TP6` (`CAN_TX`) and `TP7` (`CAN_RX`). `J7` and its BOM line are deleted —
  two RXD drivers would otherwise fight on U1 pad 28.
* **No common-mode choke.** The optional TDK `ACT45B-510-2P-TL003` with 0 Ω bypass links is
  **omitted**: there was no room for it and its links beside `U21` without displacing the
  analog front ends. Add it on a future revision only if conducted/radiated emissions
  measurements show it is needed.
* **No firmware change:** 500 kbit/s, normal (ACKing) mode. The TCAN1042's TXD dominant
  time-out (≈1 ms) will cut the firmware's `CANHOLD` diagnostic short — that is expected,
  real CAN traffic never holds dominant that long.
* **Not claimed:** automotive transient qualification or a working vehicle bus. The ESD
  and termination parts are selected but `CAN` has not been built, measured or reviewed.

**Also new in Rev F — the silkscreen was restored.** Rev C–E's generator moved *every*
footprint's silk to `F.Fab`, which left the fabricated board with **no component markings
at all** (0 of 193 footprints had any `F.SilkS`): no pin-1 dots, no diode cathode bands, no
electrolytic polarity marks, no outlines. Rev F keeps them (only the ESP32 module's
outline, which crosses the antenna-notch edge, stays on `F.Fab`) — so `U21` now carries a
pin-1 dot and every diode/electrolytic shows its polarity on the board.
* **Layout limitation of this pass:** the autorouter routed the logic pair
  `CAN_TX`/`CAN_RX` at roughly **80–90 mm** over two inner layers and `CANH`/`CANL` at
  roughly **30–45 mm** (`U21`↔`J14` ≈23 mm). Longer than a hand layout would give and
  harmless at 500 kbit/s — the lengths vary between autorouter runs and are quoted as a
  range — but a future pass should shorten the logic-side pair to U1 pads 29/28.

## Rev E — our own 5 V rail and the on-board input monitor

* **The 5 V rail is our own converter.** U2 is a **TI TPS54560B** 60 V / 5 A asynchronous
  buck at 400 kHz, built from TI's own 5 V/5 A design example (SLVSBN0C 8.2) with the input
  range narrowed to the car's real 10–20 V: `RT/CLK` 240 k (400 kHz), feedback 52.3 k/10 k
  (5.0 V), UVLO 680 k/100 k (**~9.4 V start** — car-appropriate, not TI's 6.5 V),
  compensation 16.9 k + 4.7 n + 47 p, output 3 × 47 µF, inductor 6.8 µH, catch diode `SS56`.
  The **Pololu D36V50F5 module and its 2×6 socket are gone**.
* **Reverse-polarity protection is explicit and ours.** The module provided it internally via
  `VRP`; Q3 (`AO4485` P-channel) now sits high-side with its **DRAIN on the raw input and
  SOURCE on the protected load** so the body diode blocks a reversed battery. R51 holds the
  gate low, D24 (`BZX84C15`) clamps |Vgs| against the 32 V TVS clamp. ⚠️ Wired the other way
  round the body diode conducts — asserted in `electrical/verify.py`.
* **Car input voltage monitor.** 180 k/20 k **0.1 %** divider (1:10) on the protected input
  with its own LM4040 3.0 V shunt, Schottky clamp, 1 k/100 nF filter, switched by the free
  4th channel of U15 (TMUX1511) onto **Teensy pin 40 = A16 = U1 pad 41** (an **ADC1** pin;
  A14/A15 are ADC2-only). 8 mV/LSB, saturating near 30 V.
* ⚠️ **The new buck dissipates ~1.5 W more** than the synchronous module it replaces (catch
  diode instead of a low-side FET; ≈87 % vs ≈90 % at 5 A). The continuous-5 A claim stays
  **gated on bench thermal testing**, and the PowerPAD depends on the copper it is given.

## What changed from Rev C

- **Four copper layers.** `In1.Cu` is a **continuous ground reference plane**
  (declared to the router as a plane layer so signals cannot consume it), with
  the WiFi antenna and GNSS RF rule areas cut out of it. `F.Cu`, `In2.Cu` and
  `B.Cu` carry routing. This is the single biggest electrical improvement: the
  Rev C two-layer board had to buy ground return out of the signal layers.
- **No long locked ground trunk.** Rev C required a hand-locked 4 mm `B.Cu`
  ground path. With a real plane that trunk became unnecessary — and as a
  **wall** it left `DASH_RX_5V`, `+5V_SCREEN→C33` and `NET_RESET_ASSERT`
  unroutable. Removing it is what allowed the autorouter to finish.
- **ICM-42670-P** replaces the MPU-6050 on I²C 18/19 at address 0x68
  (`AP_AD0`=GND, `AP_CS`=VDDIO selects I²C), polling only, INT1/INT2 unconnected.
  **Its land pattern is DERIVED** from DS-000451 (TDK publishes none) and has
  been checked against the datasheet: 0.50 mm pitch, 0.26 x 0.55 mm pads, 1.00 mm
  edge span, 0.14 mm mask web — all match and all are inside fab capability.
- **Throttle (J11) and brake (J12)** analog inputs on Teensy **A7 (pin 21)** and
  **A10 (pin 24)** — the last two free ADC-capable outer-row pins. Both use the
  same protected 0.500-gain front end as oil/AFR/NTC (20k/20k 0.1 %, LM4040 3.0 V
  shunt, Schottky clamp, 1 kΩ/100 nF, TMUX1511 isolation) and their own
  PTC-fused 5 V branch. Oil/coolant/AFR stay on A2/A3/A6.
- **Raspberry Pi 5 video UART (J13)** on Teensy pins 0/1, 3.3 V, with 1 kΩ
  series resistors and ESD. Deliberately separate from the 5 V screen UART.
- **Second TMUX1511** for the two new analog channels.

## Envelope and mechanical

**150 × 155 mm** (Rev C was 130 × 140 mm). The board had to grow: eight screw
terminals at 5.08 mm pitch plus three analog front ends do not fit the old
outline. All eight field terminals still face **one left edge**:

`J3` TACH · `J4` OIL · `J5` NTC · `J6` AEM AFR · **`J11` THROTTLE** ·
**`J12` BRAKE** · `J1` POWER · `J2` SCREEN

Power/tach terminals first, then the analog terminals, so high-current wiring
stays away from sensor routing. The Pi video UART is a **JST XH** rather than a
screw terminal, which saved ~16 mm of edge.

**`J14` (CAN) is the one field terminal that is NOT on the left edge.** The left edge
cannot take a ninth 5.08 mm screw terminal without ~1 mm body gaps, and no room would
remain beside it for the transceiver, termination and TVS. `J14` therefore sits
mid-board at the old `J7` position, where `U21` is within ~20 mm of it and `CANH`/`CANL`
stay short. The eight left-edge field terminals and their order are unchanged.

WiFi antenna notch is at the bottom edge (x 44–92), all-layer keepout retained.

## Manufacturing notes

1. **ICM-42670-P land pattern** — derived from DS-000451 rev 1.2 s10.2 and
   verified against the datasheet (pitch, pad size, edge spans, mask web). It is
   not a vendor-published pattern, but it is arithmetically correct and
   manufacturable. A pin-1 silkscreen marker is on the board.
2. **Copper weight** — 1 oz. The screen branch fuse is **3 A** (`F2`,
   Littelfuse `0451003.MRL`), so the 3.5 mm `+5V_MAIN` trunk is adequate at 1 oz.
3. **GNSS feed** — 0.38 mm microstrip over `In1.Cu`. The standard 4-layer 1.6 mm
   stackup (7628 x1 prepreg, H = 0.1955 mm, eps_r 4.2-4.6) gives **49.6-50.6 ohm**.
   Order with impedance control and state the 50 ohm target.
4. **Silkscreen** — Rev F keeps each footprint's own silk: **pin-1 dots, diode cathode
   bands, electrolytic polarity marks and outlines.** Rev C–E moved *all* footprint silk
   to `F.Fab`, so the board carried none of them (0 of 193 footprints had any `F.SilkS`).
   The only exception is the ESP32 module, whose outline crosses the antenna-notch board
   edge. Six terminal pin labels are still dropped where the dense left column cannot
   clear the solder-mask apertures; the `J14` pin labels and the `CAN TERM FIT ONLY AT BUS
   END` note are placed clear of every mask aperture. Full pinouts are in
   `design/ASSEMBLY.md`.

## Firmware is NOT done

This is hardware only. Still required:

- **ICM-42670-P driver** plus automatic identity detection (`0x67`) alongside
  legacy MPU-6050 (`0x68`). Tag the `ImuCalStore` EEPROM record with a sensor type
  so a removable Teensy cannot reuse the wrong offsets.
- **Throttle and brake channels** need conversions, plausibility limits and
  logging fields.
- Sensor axis mapping depends on final physical placement.
- Oil/coolant conversions must match the Rev C/D analog front end, not the
  legacy firmware values.
- The ESP32-S3 network coprocessor firmware/transport is still unimplemented;
  **Teensy pin 13's heartbeat must stop before SPI is enabled.**

## BOM revision 1 — procurement substitutions (2026-09-29)

Applied after the PCBWay quote **T-2SJ3W1113248A** (5 units) came back with five
out-of-stock lines. **No footprint, net, or routing change** — every substitution
below is the same package, so the Gerbers are unchanged; the shipped fab package
was re-exported so its `BOM.csv` matches. Details and sourcing:
`pcbway/PARTS-AVAILABILITY-REVIEW.md`; the reply sent to PCBWay:
`pcbway/PCBWAY-REPLY-2026-09-29.pdf`.

| Ref | Was | Now | Why |
|---|---|---|---|
| F3 F4 F5 | `1206L010/30YR` | `1206L010/60WR` | the old part number does not exist in the Littelfuse 1206L series |
| D5 | `PESD3V3U1UL,315` | `PESD5V0F1BL,315` | unobtainable; same SOD-882, 5.5 V standoff (antenna bias is 3.3 V) and 0.4 pF instead of 2.6 pF |
| D2 | `SS14` (Diodes Inc) | `SS14` (**onsemi**) | the bare MPN is not orderable from Diodes Inc |
| C10 | `GRM21BR71H103KA01L` | `CL21B103KBANNNC` (Samsung) | no stock; same 10 nF 50 V X7R 0805 |
| C11 | `GRM21BR71H225KA01L` | `CC0805KKX7R9BB225` (Yageo) | no stock; X7R (PCBWay's proposed X5R part is only rated to 85 °C) |
| C18 | `GRM21BR71H102KA01L` | `CC0805KRX7R9BB102` (Yageo) | no stock; same 1 nF 50 V X7R 0805 |

**U2 is a converter we build, not a module.** PCBWay sources and fits every part from stock:
TI `TPS54560BDDAR`, Vishay `IHLP4040DZER6R8M01`, `AO4505`-class `AO4485`, `SS56`, `BZX84C15`
and Murata ceramics (see `pcbway/Racecar-RevF-BOM-pcbway-assembly.csv`). No consignment and
no Pololu module. **The only sockets on the board are the two 1x24 headers at U1** — that
part of the BOM reads `SSW-124-01-G-S` because the **Teensy 4.1 is customer supplied**
(buy it with pins installed) and PCBWay must NOT fit one; they fit the two sockets and we
plug the Teensy in. Left to us: the CR2032 cell (never reflowed), the JP1 and JP2 shunts
(JP1 after unloaded rail tests; **JP2 only at a CAN bus end**), plugging in the Teensy, and
the 2-wire J9 RTC lead.

The files to send are `pcbway/Racecar-RevF-PCBWAY-GERBERS.zip` (Gerbers+drills),
`pcbway/Racecar-RevF-BOM-pcbway-assembly.csv` and `pcbway/Racecar-RevF-CPL.csv`;
`pcbway/make_package.py` regenerates all three from `components.json` and the routed PCB,
so they cannot drift from the exported design. Board settings, the U1 fitting rule and the
CAN notes are in `pcbway/PCBWAY-ORDER-GUIDE.md`.

## Reproducing

```sh
python3 electrical/make_icm_footprint.py     # derived LAND pattern
python3 electrical/generate.py               # overwrites the routed PCB
python3 electrical/schematic.py
python3 electrical/route.py                  # locked power/RF + DSN
java -jar freerouting-1.9.0.jar -de design/racecar-integrated-revf.dsn \
     -do design/racecar-integrated-revf.ses -mp 60
python3 electrical/route.py --finish         # import SES, fill the GND plane
python3 electrical/complete_routes.py        # last connections + cleanup
python3 electrical/verify.py
python3 fabrication/export.py --engineering-prototype
python3 pcbway/make_package.py               # PCBWay BOM + CPL + gerber-only ZIP
```

Rev C is retained unchanged at `../teensy-integrated-revc/`.

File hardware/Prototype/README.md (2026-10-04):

# Prototype board — wiring sheets

Hand-soldered Teensy 4.1 protoboard. **These are the sheets for everything
except the tach optocoupler** — that one lives next door in
[../breadboard/OPTO_WIRING.svg](../breadboard/OPTO_WIRING.svg) (PC817, pins
1–4, R1 1 kΩ, R2 4.7 kΩ). Physical board layout:
[../breadboard/BREADBOARD.svg](../breadboard/BREADBOARD.svg).

Open the `.png`; the `.svg` is the source. Same visual language as the opto
sheet: schematic on top, warnings, then a tick-list.

| Sheet | Covers |
| --- | --- |
| [00-Teensy-pin-map.png](00-Teensy-pin-map.png) | Every wire on the Teensy, pin by pin, plus the J1–J7 terminal map |
| [01-Power-and-ground.png](01-Power-and-ground.png) | 12 V → buck → J1, the 5 V and 3.3 V rails, star ground, pre-power checks |
| [02-UART-screen-and-video.png](02-UART-screen-and-video.png) | J2 → CrowPanel J10 (921600) and J3 → Pi 5 (115200, 3.3 V) |
| [03-GPS-and-IMU.png](03-GPS-and-IMU.png) | NEO-M9N on Serial2, MPU-6050 on Wire, boot banner, IMU mounting |
| [04-Analogue-inputs.png](04-Analogue-inputs.png) | Oil 10k/20k, coolant 150 Ω, AEM 20k/20k, optional CAN transceiver + SD |

## Terminals — left edge, top to bottom

| Block | Positions | Goes to |
| --- | --- | --- |
| J1 POWER | 5V · GND | 5 V buck output only (never 12 V) |
| J2 SCREEN | GND · 5V · TX · RX | CrowPanel **J10** only (XH2.54), 921600 |
| J3 VIDEO | GND · TX · RX | Pi 5 header 6 / 10 / 8, 3.3 V, 115200 |
| J4 TACH | SIG · GND | PC817 input via R1 1 kΩ |
| J5 OIL | 5V · SIG · GND | 0.5–4.5 V transducer, divider at A2 |
| J6 NTC | SIG · GND | Coolant sender, 150 Ω pull-up at A3, own ground wire |
| J7 AEM | WHT · BRN | AEM 30-0300 pin 9 / pin 10, divider at A6 |

## Numbers that are firmware contracts

- Oil divider **10 kΩ / 20 kΩ** ⇒ `V_adc = V_sensor × 2/3`, 150 PSI full scale.
- Coolant pull-up **150 Ω** to 3.3 V, VDO 1600–22 Ω curve (Steinhart-Hart in `src/main.cpp`).
- AEM divider **20 kΩ / 20 kΩ 0.1%** + 1 kΩ/100 nF ⇒ 0.500 gain, `AFR = 2.3750·V + 7.3125`.
- Tach: PC817 plus **4.7 kΩ** pull-up to 3.3 V on pin 9; pulses/rev default **2.0**.
- Teensy 3.3V pin: about **250 mA** of external load (PJRC). GPS + IMU + pull-ups only.
- Baud: screen **921600**, Pi **115200**, GPS raised to **230400**.

## Regenerating

```bash
python3 generate.py        # writes the .svg and, with cairosvg, the .png
```

Edit `generate.py` rather than the generated files. Keep this folder in sync with
[../breadboard/PINOUT.md](../breadboard/PINOUT.md) — that file is the full
pin-by-pin build sheet, and `WIRING.md` at the repo root is the older
reference (its baud and GPS sections have been corrected).

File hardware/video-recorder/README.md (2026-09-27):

# Dual USB camera video box — Raspberry Pi 5

**Locked hardware: Raspberry Pi 5** (you already have them). This is a
**separate box**. The Teensy breadboard only gains a 3-pin 3.3 V UART header.
USB cameras and the stick plug into the Pi, never into the Teensy.

```
Pi 5 box                                         Teensy breadboard
+--------------------------------------+         +------------------+
| USB2: ELP front 1080p MJPEG          |  UART   | pin 1 TX1 ------> Pi GPIO15 RX (hdr 10)
| USB2: ELP rear  1080p MJPEG (opt)    | 115200  | pin 0 RX1 <------ Pi GPIO14 TX (hdr 8)
| USB3: thumb drive / T7               | 3-wire  | GND ------------- GND (hdr 6)
| ffmpeg: 1080p front + rear PIP BR    |         |                  |
|         + HUD from UART stats        |         | CrowPanel START  |
| own 12V → 5V 5A USB-C (not Teensy)   |         | still owns REC   |
+--------------------------------------+         +------------------+
```

Screen START/STOP already sends `REC,1` / `REC,0` to the Teensy. Firmware
forwards those to this box **only when Settings → Video interconnect is ON**.
The same UART carries overlay stats. Files stay on the USB stick — not on
Teensy SD.

## Why Pi 5 is enough (and what it is not)

You do **not** encode two 1080p files. The Pi:

1. Pulls **MJPEG** 1080p30 from each ELP (already compressed on the camera).
2. Decodes both, scales rear to 480×270, PIP bottom-right.
3. Burns HUD text onto **one** 1920×1080 frame.
4. Software-encodes that **one** stream with `libx264 veryfast` (~8 Mbps, ~4 GB/h).

Pi 5 has **no** H.264 hardware encoder. One 1080p30 x264 + dual MJPEG decode
is a normal A76 workload. Dual *independent* 1080p encodes would not be.

Must-haves on Pi 5 or USB/cameras starve and frames drop:

- **Official active cooler** (or equivalent fan). Not optional in a car.
- **5 V 5 A** on USB-C. A Pi 4 3 A supply will brown out under REC.
- `/boot/firmware/config.txt` must contain `usb_max_current_enable=1`
  (without PD handshake, Pi 5 caps USB peripherals at ~600 mA — two cameras
  plus a stick exceed that).

## What you still need (you have the Pi 5s)

| Qty | What | Notes |
| ---:| --- | --- |
| 1 | Pi 5 you already have + **active cooler** | 4 GB is enough |
| 2 | [ELP 1080p USB varifocal](https://www.amazon.com/ELP-Varifocal-Definition-Android-Industrial/dp/B07D57PQB7/) | Front / rear. UVC MJPEG only — never YUYV |
| 1 | Samsung BAR Plus 128 GB **or** T7 SSD | USB 3. Cheap sticks drop frames. exFAT |
| 1 | **12 V → 5 V 5 A USB-C** buck | Fuse 5 A on 12 V. **Do not** use Teensy 5 V |
| 1 | 3-wire 22 AWG + 2× 1 kΩ | Teensy 0/1/GND ↔ Pi header 8/10/6 |
| 1–2 | USB 2.0 **active** 5 m extension if a camera won’t reach | Passive USB 2 dies ~3–5 m |

Ports: FRONT → USB 2.0, REAR → USB 2.0, stick → USB 3.0, power → USB-C.

## Breadboard UART (3.3 V only)

Both ends are 3.3 V. **Never** CrowPanel J10 (5 V). Common GND is mandatory.

```
Teensy 4.1                         Pi 5 40-pin
pin 1  TX1  ── 1 kΩ ──>            GPIO15 RXD  header pin 10
pin 0  RX1  <── 1 kΩ ──            GPIO14 TXD  header pin 8
GND         ──────────             GND         header pin 6
```

Pi 5 also has a tiny 3-pin JST UART by the RTC battery — ignore it; use the
40-pin so you can use DuPont/breadboard wire.

Firmware: Teensy `Serial1` 115200 8N1. Dash NVS `viden`, `CFG,viden,0|1`.
Breadboard UART header is **J3 VIDEO** — see [hardware/breadboard](../breadboard/).

## Protocol (Teensy Serial1 ↔ Pi)

`\n`-terminated.

Teensy → Pi:

```
VIDEN,1
TRACK,Summit Point
REC,1
HUD,<rpm>,<mph_x10>,<lap>,<last_ms>,<pred_ms>,<best_ms>,<oil_x10>,<clt_x10>,<afr_x10>,<lat>,<lon>
REC,0
VIDEN,0
```

`HUD` ~10 Hz while interconnect is on and a session is running. Times are
milliseconds; `-1` = unknown. Dash sends `HUDLAP,...` to the Teensy so PRED
matches the screen.

Pi → Teensy (forwarded to Settings → **Video box**):

```
VID,HELLO,<ver>
VID,READY,<ncam>,<usb_ok>
VID,REC,1,<filename>
VID,REC,0
VID,ERR,<reason>          nousb / nocam / ffmpeg / ...
```

No second record button. START on the dash is the only trigger.

## Pi 5 image (once cameras + stick are on the desk)

1. Raspberry Pi OS **Lite 64-bit**, SSH on. Boot.
2. `sudo raspi-config` → Interface Options → Serial Port:
   login shell **No**, serial hardware **Yes**.
3. Append to `/boot/firmware/config.txt`:

   ```
   dtparam=uart0=on
   usb_max_current_enable=1
   ```

   Reboot. `ls -l /dev/serial0 /dev/ttyAMA0` — serial0 should point at a real UART.

4. `sudo apt update && sudo apt install -y ffmpeg v4l-utils python3-serial fonts-dejavu-core exfatprogs`
5. Copy this directory to `/home/pi/racecar-video/`.
   `cp config.env.example config.env` and edit if needed.
6. Stick: `sudo mkfs.exfat /dev/sda1` if needed, mount at `/media/usb`
   (see `racecar-video.service`).
7. Cameras: `v4l2-ctl --list-devices`. Set `FRONT=` / `BACK=` in `config.env`
   if the ports come up swapped. **Force MJPEG** — YUYV 1080p will fail.
8. Bench: `python3 recorder.py` then `REC,1` on the UART. Confirm an `.mp4`.
   `REC,0` finalizes. Files are **fragmented MP4** so a master-cut is still
   playable. 15 s UART silence while recording stops the file.
9. `sudo cp racecar-video.service /etc/systemd/system/ && sudo systemctl enable --now racecar-video`

`recorder.py` uses stock ffmpeg `libx264` (no Rockchip MPP, no Pi-4 v4l2m2m).

## Not doing

- Video on the CrowPanel / a second screen UART (no free RGB pins)
- Recording video onto Teensy SD
- Live preview on the dash
- Rev C PCB — parked; this is a box + one header
- Pi updates via dash OTA — scp/git until we decide otherwise

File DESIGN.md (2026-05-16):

---
version: alpha
name: Pit Wall
description: >
  Visual identity for the racecar-35 cloud review UI. A dark, instrument-cluster
  aesthetic that mirrors the in-car dash so the at-home review surface feels
  continuous with the at-track experience.
colors:
  primary: "#FFB020"
  secondary: "#8A92A3"
  tertiary: "#6CD07A"
  neutral: "#E6E8EE"
  bg: "#0E1014"
  surface: "#181B22"
  surface-2: "#20242E"
  surface-3: "#2A2F3A"
  line: "#2A2F3A"
  on-surface: "#E6E8EE"
  on-surface-muted: "#8A92A3"
  on-primary: "#1A1300"
  accent-dim: "#6A4A10"
  error: "#FF5D5D"
  warn: "#F2C14E"
  good: "#6CD07A"
  track-line: "#FFB020"
  car-dot: "#FFB020"
typography:
  display:
    fontFamily: Inter
    fontSize: 28px
    fontWeight: 600
    lineHeight: 1.1
    letterSpacing: -0.01em
  headline:
    fontFamily: Inter
    fontSize: 16px
    fontWeight: 600
    lineHeight: 1.2
    letterSpacing: 0.02em
  body-md:
    fontFamily: Inter
    fontSize: 14px
    fontWeight: 400
    lineHeight: 1.45
  body-sm:
    fontFamily: Inter
    fontSize: 13px
    fontWeight: 400
    lineHeight: 1.45
  label-caps:
    fontFamily: Inter
    fontSize: 11px
    fontWeight: 600
    lineHeight: 1
    letterSpacing: 0.08em
  telemetry-lg:
    fontFamily: JetBrains Mono
    fontSize: 36px
    fontWeight: 600
    lineHeight: 1
    fontFeature: "'tnum' 1, 'zero' 1"
  telemetry-md:
    fontFamily: JetBrains Mono
    fontSize: 18px
    fontWeight: 500
    lineHeight: 1.1
    fontFeature: "'tnum' 1, 'zero' 1"
  telemetry-sm:
    fontFamily: JetBrains Mono
    fontSize: 13px
    fontWeight: 400
    lineHeight: 1.3
    fontFeature: "'tnum' 1, 'zero' 1"
rounded:
  none: 0px
  sm: 4px
  md: 8px
  lg: 12px
  xl: 16px
  full: 9999px
spacing:
  xs: 4px
  sm: 8px
  md: 16px
  lg: 24px
  xl: 32px
  xxl: 48px
  gutter: 16px
  margin: 24px
components:
  surface-card:
    backgroundColor: "{colors.surface}"
    textColor: "{colors.on-surface}"
    rounded: "{rounded.md}"
    padding: 16px
  button-primary:
    backgroundColor: "{colors.primary}"
    textColor: "{colors.on-primary}"
    rounded: "{rounded.sm}"
    padding: 8px
    typography: "{typography.label-caps}"
  button-primary-hover:
    backgroundColor: "#FFC04A"
  button-ghost:
    backgroundColor: "{colors.surface-2}"
    textColor: "{colors.on-surface}"
    rounded: "{rounded.sm}"
    padding: 8px
  input-text:
    backgroundColor: "{colors.surface}"
    textColor: "{colors.on-surface}"
    rounded: "{rounded.sm}"
    padding: 8px
  pill:
    backgroundColor: "{colors.surface-2}"
    textColor: "{colors.on-surface-muted}"
    rounded: "{rounded.full}"
    padding: 2px
    typography: "{typography.label-caps}"
  row-hover:
    backgroundColor: "#1F1A0F"
  telemetry-tile:
    backgroundColor: "{colors.surface}"
    textColor: "{colors.on-surface}"
    rounded: "{rounded.md}"
    padding: 16px
  slider-track:
    backgroundColor: "{colors.surface-3}"
    height: 4px
    rounded: "{rounded.full}"
  slider-thumb:
    backgroundColor: "{colors.primary}"
    size: 16px
    rounded: "{rounded.full}"
---

## Overview

**Pit Wall** is the visual identity for the at-home review surface of the
racecar-35 telemetry system. The driver sees a dark dash in the car (RPM bar
across the top, big saffron speed digits, technical labels in mono). The
review UI is its continuation: when an engineer pulls up a session after
the session, the screen should feel like *the same instrument*, not a
generic web app.

The product feels closest to **a pit-wall timing tool** (think MoTeC i2,
AiM RaceStudio, Garmin Catalyst): purposeful, dense without being crowded,
high-contrast, and unambiguously technical. Levity and decoration are
deliberately absent. The brand's whole personality is in:

- the saffron accent (`#FFB020`) inherited from the in-car RPM bar,
- monospaced telemetry numerals with tabular figures,
- generous negative space around dense data so the eye can lock on
  one value at a time.

Target user is a driver/engineer reviewing a session on a laptop or a tablet
trackside, usually outdoors, usually in a hurry. Decisions favor legibility
under glare over visual delight.

## Colors

Two-tier dark palette with a single warm accent. Every saturated color does
exactly one job — there is no "decorative" color in this system.

- **Primary / Saffron (#FFB020):** The single interaction and live-data accent.
  Used for the car dot on the map, the slider thumb, the recording indicator,
  the in-car RPM bar, and exactly one primary action per screen. Never use
  for body text or decorative elements.
- **Secondary / Slate (#8A92A3):** Captions, axis labels, metadata, table
  headers. The "quiet" text that supports without competing.
- **Tertiary / Track Green (#6CD07A):** Reserved for positive state — fix
  acquired, upload complete, recording started.
- **Background (#0E1014):** Near-black. Not pure black, to avoid OLED blooming
  on glossy laptop screens and to leave room for a deeper "void" below cards.
- **Surface / Surface-2 / Surface-3 (#181B22 / #20242E / #2A2F3A):** Three
  flat elevation tiers. Cards sit on surface; nested controls (chips,
  pills, slider track) sit on surface-2; pressed/hovered states use surface-3.
- **Error (#FF5D5D):** Reserved for upload failure, RPM redline, no-fix.
  Never used for ambient state.

## Typography

The system uses two type families:

- **Inter** for all UI prose, headlines, labels, table content.
- **JetBrains Mono** for any telemetry numeral, timestamp, lat/lon, RPM,
  speed, file size. Tabular figures (`tnum`) are mandatory so digits do
  not shift left/right as values tick — the dash uses a fixed-width
  background pad for the same reason, and the review surface inherits
  the discipline.

Sizes are deliberately few. The hierarchy is `display` (page title) →
`headline` (card title) → `body-md` (default prose) → `label-caps`
(uppercase, tracked-out, used for column headers and unit annotations).
Telemetry comes in three sizes: `telemetry-lg` for the current-value
hero readout (speed, RPM), `telemetry-md` for secondary tiles (lat, lon,
heading), `telemetry-sm` for in-table cells.

**Label-caps** is uppercase with `0.08em` letter-spacing. This is the
single typographic "tell" of the system; it should appear on every
card title strip and column header.

## Layout

Max content width is **1400px**, centered. Below that the layout is fluid.

The review page uses a two-pane composition:
- **Left pane (60%)**: map. Track centerline drawn from the GPS samples,
  car dot rendered at the currently-scrubbed sample.
- **Right pane (40%)**: telemetry tiles, stacked. Hero speed at top,
  RPM + lat/lon + heading + fix below in a 2×2 grid.

Below both panes spans the full-width **scrub bar**: a slider whose value
is the sample index, plus play/pause, plus a timestamp readout.

Spacing follows a strict 8-px scale (`spacing.sm` = 8, `md` = 16, `lg` = 24).
Card internal padding is always `md`. Gap between cards in a grid is `md`.
Page padding (`margin`) is `lg`.

## Elevation & Depth

Flat. No shadows, no blurs. Hierarchy is conveyed by **tonal layering**:
content on `surface` is above the page, nested controls move up to
`surface-2`, hover/pressed states move up to `surface-3`. The 1-px
`line` border between cards and rows replaces the role a shadow would
play in a light theme.

The single exception is the saffron accent glow on the header status dot
(`box-shadow: 0 0 8px primary`) — a deliberate echo of an instrument-cluster
indicator lamp, used only on the small "live" indicator and the car dot
on the map.

## Shapes

Slightly soft. `rounded.sm` (4px) for inputs, buttons, pills inside dense
tables. `rounded.md` (8px) for cards and tiles. `rounded.full` for the
small status dot, the slider thumb, and the car dot. **Never mix sharp
and rounded corners in the same composition** — every interactive shape
in this system has at least `rounded.sm`.

## Components

- **Buttons.** Primary buttons use the saffron accent on near-black text
  (`on-primary`). One per screen — usually "Play" on the review page or
  "Download" on the index. Ghost buttons (surface-2 background) for
  everything else.
- **Input fields.** Surface background, 1-px line border. On focus the
  border switches to saffron — no glow, no shadow. The search input on
  the index page is the canonical example.
- **Pills.** Tiny rounded-full chips used for inline metadata (sample
  count, file size badges). Uppercase label-caps text in muted slate
  on surface-2.
- **Telemetry tiles.** Surface card with a label-caps title strip at the
  top in muted slate, followed by the telemetry-lg/md value in saffron
  for "live" readouts and on-surface white for static metadata.
- **Slider (scrub bar).** 4-px tall surface-3 track, 16-px saffron thumb,
  no tick marks. Below the track sits a tiny mono-typed timestamp that
  updates as you drag.
- **Map.** OpenStreetMap "dark" tiles. Track centerline drawn as a 3-px
  saffron polyline at 40% opacity. Car position drawn as an 8-px saffron
  filled circle with a 2-px solid stroke at 100% opacity — high enough
  contrast to stay readable when the centerline runs underneath it.

## Do's and Don'ts

- **Do** use the saffron accent for exactly one purpose per surface:
  current state / current position / primary action.
- **Don't** use saffron for prose, dividers, or decoration. If it appears
  more than ~3 times on a screen, something is wrong.
- **Do** use JetBrains Mono with tabular figures for every numeral that
  changes over time (RPM, speed, lat/lon, file size, timestamp).
- **Don't** use Inter for telemetry numerals — proportional digits will
  jitter horizontally as values tick.
- **Do** maintain WCAG AA contrast (4.5:1) for all body text against
  surface. The neutral-on-surface pair clears 13:1.
- **Don't** introduce a second saturated accent color. New states map onto
  the existing tertiary (green, success) or error (red, failure).
- **Do** uppercase + letter-space all card and column titles (`label-caps`).
- **Don't** add drop shadows, glows, or gradients to cards. Tonal layering
  only. The single permitted glow is the header status dot.

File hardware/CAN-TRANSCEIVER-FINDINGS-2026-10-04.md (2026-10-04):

# CAN transceiver root cause (bench, 2026-10-04) — what Rev F must guarantee

**For the agent owning the Rev F PCB / PCBWay order. Read all of it.**

## What happened
The bench logger (Teensy 4.1 + Amazon "3-Pack SN65HVD230 CAN Transceiver Module", ASIN
B0FDLDXCK9) received CAN perfectly but **never transmitted a single dominant bit**, so it
never ACKed. A lone sender (CANable / MS3) then retransmits its highest-priority frame
forever: ~3,800 identical frames/s, values updating only 3–4×/s, 0x701 never arriving.
Swapping to another module from the same pack changed nothing.

**Root cause: the chip on those boards is NOT an SN65HVD230.** It behaves as a
TJA1051T/3-class part (same SOIC-8 footprint, different pin meaning):

| Pin | SN65HVD230 (what the board is built for) | Chip actually fitted |
|---|---|---|
| 3 VCC | 3.3 V | **needs 4.5–5.5 V** — transmitter locked out below that |
| 5 | Vref (output, left floating) | **VIO** = logic supply for TXD/RXD |
| 8 | Rs | **S / standby** — high = receive-only |

With VCC = 3.3 V the driver was locked out; with VIO floating it was phantom-fed from
TXD (measured **2.1 V**), so RXD collapsed whenever TXD went low — an internal TXD→RXD
echo that made every Teensy-side self-test look like a working transmitter.
**Fix that worked: VCC 5 V, pin 5 (VIO) 3.3 V, pin 8 to GND** → exactly 200 frames/s,
both IDs, 0 errors.

## Rev F status — design is correct, verified from `design/checked-netlist.xml`
`U21` (TCAN1042HGV-Q1): pin 3 VCC = `+5V_MAIN` (C49, C51), **pin 5 VIO = `+3V3_MCU`**
(C50), **pin 8 STB = GND**, pin 1 TXD = `CAN_TX` → U1.29 (pin 22), pin 4 RXD = `CAN_RX`
→ U1.28 (pin 23). **Do not change this.** The remaining risks are below.

## Required actions
1. **No unapproved substitution of U21.** In the PCBWay order notes and BOM comment:
   "U21 = TI `TCAN1042HGVDRQ1` from authorized distribution only (TI / Mouser / Digi-Key /
   LCSC-original). Do NOT substitute without written approval. No clones, no re-marked parts."
   Approved alternates only: `TCAN1042VDRQ1`, then NXP `TJA1051T/3/1J` (pin 8 S → GND).
   - ⚠️ The **`V` suffix is mandatory** (it is the VIO pin). `TCAN1042DRQ1`, `TCAN1042HDRQ1`,
     `TCAN1042GDRQ1` etc. have **pin 5 = NC** → RXD swings to 5 V → destroys Teensy pin 23.
   - **Never** an SN65HVD23x, plain `TJA1051T` (no /3), `TJA1050`, or any "pin-compatible"
     Chinese equivalent (SIT/clone) for U21.
2. **Incoming inspection when the boards arrive:** read U21's top marking and compare it
   with the "Device Marking" column of TI's Package Option Addendum for the ordered part
   number. Photo it into `logs/`. Mismatch = reject before power-up.
3. **Bring-up must be done with J1 (12 V) powered.** `+5V_MAIN` comes from the buck; on
   Teensy-USB power alone U21 VCC = 0 and the board shows the **identical "no ACK"
   symptom**. That is not a fault, and nobody should "fix" it.
4. **Make `design/BRINGUP.md` CAN acceptance un-foolable** (it already has DC levels and
   the CANable test — add/keep these, they are the tests that actually discriminate):
   - DC: U21.3 = **5.0 V**, U21.5 = **3.3 V** (NOT ~2 V — a floating VIO reads ~2 V),
     U21.8 = **0 V**.
   - **Single-frame ACK test (decisive):** CANable (Elmue slcan, `ME` error reports on)
     sends **one** frame; the logger's `CANDIAG total` must rise by **exactly 1**.
     Thousands = no ACK = FAIL. CANable must report no `E?3……` (protocol error 3 = No ACK).
   - Bench feed at 100 Hz: logger `CANDIAG frames/s` ≈ **200 (= sent rate ±2 %)**, both
     `0x700` and `0x701`, `oil`/`afr`/`batt` ≠ -1. **~3,800 frames/s is a retransmit
     storm and is a FAIL even though it looks like "receiving".**
   - `CANTX,10` from the Teensy: CANable receives each frame exactly once; Teensy TEC stays 0.
5. **Known misleading diagnostics — do not use them as pass criteria:**
   - Firmware `CANDRIVE` / `CANPROBE` "TX PATH OK": an internal TXD→RXD echo passes it.
   - Bench console verdict "fps ≥ 50 → ACKING": a storm passes it.
   - `CANHOLDON` + multimeter on CANH–CANL: on Rev F the **TCAN1042 TXD dominant time-out
     (~ms) releases the bus**, so a healthy board reads ~0 V. Not a valid test on Rev F.
     (It was valid on the old module only because that chip had no time-out.)
6. **Bench modules (pre-Rev F) from that Amazon pack:** document in `WIRING.md` /
   `hardware/breadboard/README.md`: **VCC = 5 V, pin 5 = 3.3 V, pin 8 = GND** — never
   3.3 V on VCC, never 5 V on pin 5.

No firmware change is needed for Rev F (500 kbit/s, normal ACKing mode).

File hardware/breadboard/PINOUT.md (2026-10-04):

# Solderable breadboard — complete wire-by-wire pinout

**This is the hand-soldered protoboard build (Teensy 4.1 + discrete parts), NOT the
Rev C/Rev D PCBway board and NOT the Rev A carrier.** Everything the car connects to
lands on screw terminals along the **left edge**; the Teensy sits on the **right**,
USB-C facing out. Picture: [BREADBOARD.svg](BREADBOARD.svg). Build order/parts:
[README.md](README.md).

Firmware target: **v0.1.150** (`FIRMWARE_VERSION` in [src/main.cpp](../../src/main.cpp)).

```
         12 V battery
              |
      [fuse]  |  5 V buck  3 A+        (Pi 5 has its OWN 5 V 5 A supply)
              v
   J1 5V ──┬── Teensy VIN
           ├── J2 5V   ──> CrowPanel J10 +5V_IN
           └── J5 5V   ──> oil transducer

   Teensy 3.3V ──┬── GPS VCC
                 ├── IMU VCC
                 ├── 4.7k tach pull-up
                 ├── 150R coolant pull-up
                 └── SN65HVD230 VCC (optional)

   GND RAIL (star) ── every GND below + Teensy GND + J1 GND
```

---

## 1. Teensy 4.1 pin map — every pin this build touches

`[bracketed]` = wire on this board. Verify against the silkscreen on *your* board
before soldering; pin numbers below are the GPIO numbers used in code.

```
                              +-------[USB-C]-------+      <- USB outboard (flash here)
                         GND -|                     |- 5V (VIN)   [<- J1 5V]
        [J3 RX  <- Pi TX]  0 -|                     |- GND         [-> GND rail]
        [J3 TX  -> Pi RX]  1 -|                     |- 3.3V        [-> 3.3V rail]
                           2 -|                     |- 23  A9      [CAN1 RX  (opt)]
                           3 -|                     |- 22  A8      [CAN1 TX  (opt)]
                           4 -|                     |- 21  A7
                           5 -|  [RESERVED NET]     |- 20  A6      [J7 AEM (divided)]
                           6 -|  [RESERVED NET]     |- 19  SCL     [IMU SCL]
        [GPS TX -> RX2]     7 -|                     |- 18  SDA     [IMU SDA]
        [GPS RX <- TX2]     8 -|     T E E N S Y     |- 17  A3      [J6 coolant]
        [J4 TACH (opto out)]9 -|        4 . 1        |- 16  A2      [J5 oil]
                          10 -|  [RESERVED NET]     |- 15  RX3     [J2 RX <- screen TX]
                          11 -|  [RESERVED NET]     |- 14  TX3     [J2 TX -> screen RX]
                          12 -|  [RESERVED NET]     |- 13  LED     [heartbeat - LEAVE ALONE]
                        3.3V -|                     |- GND         [-> GND rail]
                          24 -|                     |- 41
                          25 -|                     |- 40
                          26 -|                     |- 39
                          27 -|                     |- 38
                          28 -|                     |- 37
                          29 -|                     |- 36
                          30 -|                     |- 35
                          31 -|                     |- 34
                          32 -|                     |- 33
                              |   +-------------+   |
                              |   |  SD (SDIO,  |   |
                              |   |   built-in) |   |
                              +---+  no wiring  +---+
```

| Pin | Net on this board | Don't |
| --- | --- | --- |
| 0 / 1 | Serial1 → Pi 5 video box (RX / TX), 115200, **3.3 V only** | never 5 V |
| 5, 6, 10, 11, 12, 13 | **Reserved** for the unimplemented trunk WiFi/SPI module | don't reuse, don't remove the LED heartbeat yet |
| 7 / 8 | Serial2 ← GPS TX / → GPS RX, raised to 230400 at boot | don't skip pin 8 — firmware configures the module over it |
| 9 | Tach, `FreqMeasureMulti` (opto output only) | plain `FreqMeasure` uses pin 22 — wrong here |
| 14 / 15 | Serial3 → screen RX / ← screen TX, **921600** | unplug before USB-flashing the screen |
| 16 (A2) | Oil pressure ADC | Serial4 lost |
| 17 (A3) | Coolant NTC ADC | Serial4 lost |
| 18 / 19 | Wire SDA / SCL → MPU-6050 (0x68) | 3.3 V only, keep wires short |
| 20 (A6) | AEM 30-0300 gauge output through the 20k/20k divider | **never** AEM WHITE directly |
| 22 / 23 | CAN1 TX / RX → SN65HVD230 (only for MegaSquirt mode) | never an MCP2551 (5 V — it will damage the Teensy) |
| 3.3V | GPS, IMU, tach pull-up, coolant pull-up, CAN transceiver | don't hang the screen or a 5 V load off it |
| 5V (VIN) | J1 5 V in | cut **VUSB–VIN** (pad on the Teensy underside) if USB and J1 are both live |

Alt-function notes for anything you add later: Serial6 = 24 TX / 25 RX, Serial7 = 28 RX /
29 TX, SPI1 = 26 MOSI / 27 SCK / 39 MISO, extra ADC = A7 (pin 21).

---

## 2. J1 POWER — do this first

| From | To | Note |
| --- | --- | --- |
| 12 V battery (+), fused 5 A | buck IN+ | buck must be **5 V out, 3 A or better** |
| buck OUT+ | **J1 pin `5V`** | ~5.0 V measured before connecting the Teensy |
| buck OUT− | **J1 pin `GND`** | also the buck's reference for OUT |
| battery (−) | buck IN− | ground the buck to the car at one point only |

Then, with J1 still **off**:

| From | To | Note |
| --- | --- | --- |
| J1 `5V` | Teensy **5V (VIN)** | top-right header pin |
| J1 `5V` | J2 `5V` | feeds the CrowPanel J10 +5V_IN |
| J1 `5V` | J5 `5V` | oil transducer supply |
| J1 `GND` | **GND rail** | fat jumper — this is the star point |
| Teensy GND (both header GNDs) | GND rail | |

- **Never 12 V on J1. Never 5 V on the Teensy 3.3V pin.**
- Powering from USB on the bench with J1 also live requires the **VUSB–VIN cut pad**
  on the Teensy's underside, or the two 5 V sources fight.
- The Teensy 3.3V rail feeds GPS + IMU + pull-ups only. Don't add servos/displays.
- The Raspberry Pi 5 gets its **own** 5 V 5 A USB-C supply; J3 is a 3-wire 3.3 V UART,
  no power.

---

## 3. J4 TACH — PC817 optocoupler you build by hand

**Diagram: [OPTO_WIRING.svg](OPTO_WIRING.svg)** (open in a browser) — physical pinout,
full schematic, bench check, and the weak-tach-line variant.

### 3.0 What "by hand" means here — the LED is INSIDE the chip

The PC817 is a **bare DIP-4 chip**, not a module. It contains everything: an infra-red
**LED across pins 1 (+) and 2 (−)** and a **phototransistor across pins 4 (collector) and
3 (emitter)**. You add **no LED** and there is nothing to configure or range-jumper.

- A plain silicon diode (1N4148 / 1N4007 / any rectifier) **emits no light** and can never
  be the input of an optocoupler. The only diode you add here is **D1**, the *optional*
  reverse clamp across pins 1–2.
- If you literally have no PC817 and want to build the isolation from loose parts you need
  an **IR LED (≈940 nm)** facing a **phototransistor or photodiode**, black-heatshrunk face
  to face. A PC817 is cheaper, matched, and far more reliable than that.

**Source limit: ECU / instrument-cluster conditioned tach ONLY.** Never coil negative,
ignition lead, spark, or injector drive. Read
[TACH_INTERFACE.md](../teensy-integrated-revc/TACH_INTERFACE.md) before wiring it to a car.

### 3a. Pinout — DIP-4, TOP view, notch up (pin 1 is left of the notch)

```
        ┌───── notch ─────┐
        │   ┌─────┐       │
   ─────┤1  │     │      4├─────       1 = LED anode     (+)    ← R1 1 kΩ ← J4 SIG
   pin1 │   │     │       │  pin4      2 = LED cathode   (−)    → J4 GND / board GND
        │   │     │       │            4 = collector            → 3.3 V via R2 + Teensy pin 9
   ─────┤2  │     │      3├─────       3 = emitter              → board GND
   pin2 │   └─────┘       │  pin3
        └─────────────────┘
```

The dot or dimple on the package also marks pin 1. If you have an SMD/optically-similar
part, check its datasheet before assuming this order.

### 3b. The circuit (simple version — what the SVG and README show)

```
                    3.3 V
                      │
                    [4.7 kΩ]  R2
                      │
 PC817                ├───────────────► Teensy pin 9
 ┌───────────┐        │                   │
 │ 1 (A) ──►|  (LED)  4 (C) ──────────────┘
 │                     │                [100 nF]  (optional, at pin 9)
 │ 2 (K)         3 (E) │                   │
 └──┬──────────┬───────┘                  GND
    │          │
    │        GND (board star)
    │
 J4 SIG ──[1 kΩ]──┬── pin 1            R1 = 1 kΩ ¼ W → ≈11 mA LED current at 12 V
                  │                    R2 = 4.7 kΩ (10 kΩ also fine) → pull-up, REQUIRED
               [D1 1N4148]  optional   D1 = cathode to pin 1, anode to pin 2 (reverse clamp)
 J4 GND ──────────┴── pin 2
```

| Part | Value | Why |
| --- | --- | --- |
| `R1` J4 SIG → pin 1 | **1 kΩ ¼ W** | 12 V pulse minus the LED drop ⇒ ~11 mA through the internal LED |
| `R2` 3.3 V → pin 9 | **4.7 kΩ** (10 kΩ fine) | the phototransistor is a bare transistor — the pull-up IS the signal |
| `C1` pin 9 → GND | 100 nF | optional, kills tach hash |
| `D1` across pins 1–2 | 1N4148, anti-parallel | optional; the PC817's reverse rating is only ~6 V |

Output is **inverted** (pin 9 pulled LOW while the tach pulses). Firmware doesn't care —
`FreqMeasureMulti` counts edges either way.

### 3c. ⚠️ If the tach line is a weak ECU/cluster/open-collector output

The simple version draws **~11 mA out of the car's tach wire at 12 V**. A healthy ECU
tach driver or instrument cluster usually tolerates that, but a factory
cluster output with a weak internal pull-up may not — and that's exactly the failure
mode the Rev C interface document forbids. If in doubt, don't load the line: add a
**2N3904 pre-driver** so the opto LED current comes from your board's 5 V instead.

```
 J4 SIG ── 100 kΩ ──┬── base  2N3904
                    │
                  10 kΩ  (to board GND)              collector ── 1 kΩ ── PC817 pin 1
                    │                                emitter   ── board GND
 J4 GND ────────────┴─ 2N3904 emitter/GND            5 V ───────────── PC817 pin 2 (return)
```

Input impedance is now ~110 kΩ, ~0.5 mA out of the car's line. The opto
output half is unchanged (4.7 kΩ to 3.3 V → pin 9). Either version gives the same
firmware behaviour; the pre-driver version is the one that matches the Rev C
electrical contract.

### 3d. Bench test before it goes near the car

1. Power off, ohm meter: `J4 SIG` → `J4 GND` should **not** read 0 Ω (that would be a short).
2. Power on, no pulses: pin 9 must sit at **~3.3 V** (pull-up high, opto off).
3. Feed `J4 SIG` with **12 V pulses** (bench supply through the 1 kΩ, or the car's signal)
   at a few hundred Hz: pin 9 must swing to **below 0.8 V** on each pulse.
   A pin that only dips to ~1.5 V is the classic "reads constant HIGH, RPM = 0" fault —
   check the LED current and the ground, not the firmware.
4. 8000 RPM at 2 pulses/rev = **267 Hz**. PC817 is fine to several kHz.
5. `RPM_PULSES_PER_REV` defaults to **2.0** in `src/main.cpp`; if idle reads 2× or ½×,
   change it (Settings → tach pulses/rev, NVS `rpmppr`, sent as `CFG,rpmppr,<x10>`).

---

## 4. J5 OIL — 10 kΩ / 20 kΩ divider → pin 16 (A2)

5 V output transducer, Teensy ADC is **not** 5 V tolerant. The divider is mandatory.

```
 J5 5V  ── Teensy 5V / J1 5V
 J5 GND ── board GND
 J5 SIG ── 10 kΩ ──●── Teensy pin 16 (A2)
                   │
                  20 kΩ
                   │
                  GND            (+ optional 10 nF from A2 to GND, right at the pin)
```

Firmware contract: `V_adc = V_sensor × 2/3`, `OIL_V_AT_ZERO_PSI = 0.5 V`,
`OIL_PSI_FULL_SCALE = 150 PSI`.

| Input at J5 SIG | Expect on A2 |
| --- | --- |
| 0.5 V (0 PSI at atmosphere) | ~0.33 V |
| 4.5 V (150 PSI) | ~3.00 V |

Meter both ends before trusting a reading. Note the Teensy has a ~50 kΩ **internal
pull-down** enabled on A2 by firmware (`INPUT_PULLDOWN`) which sits in parallel with the
20 kΩ leg — readings can come out roughly 10 % low; that's expected, do not "fix" it by
changing the resistors (it would break the firmware ratio). Wire colour check: a genuine
0.5–4.5 V sender reads **~0.5 V at atmosphere**; a 0–5 V variant reads ~0 V and needs a
firmware constant change instead.

---

## 5. J6 NTC — 150 Ω pull-up to 3.3 V → pin 17 (A3)

```
 3.3 V ── 150 Ω ──●── Teensy pin 17 (A3)
 J6 SIG ───────────┘
 J6 GND ────────────── board GND     <- dedicated wire, NOT the engine block
```

- Sender: VDO 1600–22 Ω curve (firmware is fitted to 100 F = 700 Ω, 180 F = 110 Ω,
  250 F = 22 Ω via Steinhart-Hart `COOLANT_SH_A/B/C`).
- A **different** sender needs a different pull-up (GM-style ~3.3 kΩ @ 100 F → ~2.2 kΩ)
  and new Steinhart-Hart coefficients.
- Single-terminal senders **must** get a dedicated return wire — grounding through the
  threads injects ignition noise straight into the ADC.
- Firmware also enables an internal ~50 kΩ pull-down on A3, so a disconnected sender
  reads ~0 V and reports a fault instead of a plausible temperature.

---

## 6. J7 AEM 30-0300 gauge output — 0.500 gain → pin 20 (A6)

The gauge's WHITE analogue line can be **5 V**; A6 dies at 3.6 V. This divider is not
optional, and its ratio is a firmware constant (`AFR = 2.3750·V + 7.3125`).

```
 J7 WHT ── 20 kΩ 0.1% ──●── 20 kΩ 0.1% ── J7 BRN ── board GND
                        │
                       1 kΩ
                        │
                    Teensy pin 20 (A6) ── 100 nF ── GND
```

- Use **both** AEM wires: the Power/IO harness's solid **WHITE = pin 9** (analogue +)
  and solid **BROWN = pin 10** (reference). BROWN is the divider's bottom — not a
  random chassis point.
- The gauge keeps its own 12 V supply and fuse; we take analogue only. No onboard
  heater/controller, no direct-sensor connector.
- Bench check: **5.00 V WHITE-to-BROWN must read ~2.50 V on pin 20.**
- Settings → **AEM 30-0300 AFR input** stays **OFF** until that measurement checks out.
- Valid range 0.50–4.50 V ⇒ 8.50–18.00 AFR. This is the gasoline-equivalent
  (14.65) AFR the firmware reports.
- The hand-built version has only the divider — it does **not** have the Rev C board's
  LM4040 shunt clamps, Schottky clamps or TMUX1511 powered-off isolation. Treat the
  gauge wiring and grounds with that in mind; see
  [AFR_INTERFACE.md](../teensy-integrated-revc/AFR_INTERFACE.md).

---

## 7. J2 SCREEN — CrowPanel UART, 921600

| From | To | Note |
| --- | --- | --- |
| J2 `GND` | CrowPanel **J10 GND** | shared ground is mandatory |
| J2 `5V` | CrowPanel **J10 +5V_IN** | or power the screen from its own USB-C |
| J2 `TX` (Teensy **pin 14**) | CrowPanel **J10 RXD0_H** | crossed |
| J2 `RX` (Teensy **pin 15**) | CrowPanel **J10 TXD0_H** | crossed |

- **Use J10 only — the larger XH2.54 4-pin header.** Its `+5V_IN` is the only
  power-capable pin; TX/RX sit behind level shifters.
- **NEVER the small HY2.0 header (J2 on the screen).** Its `3V3_OUT` is an *output*
  from the ESP32's 3.3 V rail — 5 V there kills the chip.
- **Disconnect J2 TX/RX before USB-flashing the CrowPanel** (UART0 is shared with the
  CH340) or the flash silently corrupts.
- Baud **921600 8N1**, line-oriented `\n`.

---

## 8. J3 VIDEO — Raspberry Pi 5, 115200, 3.3 V (v0.1.150)

| From | To | Note |
| --- | --- | --- |
| J3 `GND` | Pi header **pin 6** (GND) | |
| J3 `TX` → 1 kΩ → Teensy **pin 1** | Pi header **pin 10** (GPIO15 RXD) | crossed |
| J3 `RX` ← 1 kΩ ← Teensy **pin 0** | Pi header **pin 8** (GPIO14 TXD) | crossed |

- **3.3 V logic both ends. Never put 5 V on J3 or on a Pi GPIO.**
- Pi side: `dtparam=uart0=on`, `usb_max_current_enable=1`.
- Cameras and the USB stick live on the Pi, not on this board.
- Settings → **Video interconnect** only after this cable is verified. With it OFF the
  Teensy ignores Serial1, and a missing Pi does not block START.
- Firmware forwards `REC` / `TRACK` / `HUD` and relays `VID,...` status to the dash.

Two links, two voltages, two bauds — do not mix them up.

---

## 9. GPS — u-blox NEO-M9N (Serial2)

| Module pin | Teensy | Note |
| --- | --- | --- |
| `VCC` / `3V3` | **3.3V** | SparkFun RTK boards tolerate 3.3–5 V in; feed 3.3 V |
| `GND` | **GND rail** | star, not through the engine block |
| `TX` | **pin 7** (RX2) | module → Teensy |
| `RX` | **pin 8** (TX2) | **required** — boot config + baud change go over it |

- Boot scan: `230400 → 38400 → 9600` (SparkFun default 38400, bare module 9600), then
  the firmware raises the link to **230400** and calls `saveConfiguration()` so a module
  brownout reboots straight back into UBX auto-PVT.
- Settings → **GPS baud** can change it live; the firmware rescans if the pick fails.
- External active antenna on the SMA; the module body needs a clear sky view.
- Keep GPS wires short and away from the tach/oil harness — this module's resets are a
  known symptom of power/ground noise.

---

## 10. IMU — MPU-6050 on a GY-521 breakout (Wire)

| GY-521 pin | Teensy | Note |
| --- | --- | --- |
| `VCC` | **3.3V** | **not 5 V** — the module's pull-ups reference VCC |
| `GND` | **GND rail** | |
| `SDA` | **pin 18** | Wire (I2C0) |
| `SCL` | **pin 19** | Wire (I2C0) |
| `AD0` | **GND** | floating/high ⇒ address 0x69 ⇒ "MPU-6050 NOT found" |
| `XDA`, `XCL`, `INT` | leave open | not used |

- Address **0x68**, 400 kHz, raw 14-byte burst at 0x3B, ±2 g / ±250 °/s, DLPF 44 Hz.
- 3.3 V only; I2C0 (18/19) — not 16/17 (`Wire1`, those are the ADCs), not 24/25.
- Detection is **one-shot at boot**. If it isn't ACKed then, every `IMU` line is
  `0.00,...,0.0` for the whole session — that's "not detected", not a calibration
  artifact. Re-seat/solder the header before suspecting code.
- Boot auto-cal (`calibrateIMU()`) removes gyro bias and normalizes accel to 1.00 g,
  gated by a stillness check, and caches last-good values in Teensy EEPROM (addr 0).
  Boot the car **stationary** or the cal is rejected (the previous good cal stands).
- Mounting: board **flat, component side up, header pins toward the rear** ⇒
  +X forward, +Y right, +Z up.

---

## 11. CAN — MS3Pro via SN65HVD230 (optional, only for `sensor_type = 1`)

| Transceiver pin | Goes to |
| --- | --- |
| `3V3` / `VCC` | Teensy **3.3V** |
| `GND` | **GND rail** |
| `CTX` / `TXD` | Teensy **pin 22** (CAN1 TX) |
| `CRX` / `RXD` | Teensy **pin 23** (CAN1 RX) |
| `CANH` | MS3Pro CAN-H |
| `CANL` | MS3Pro CAN-L |

- Must be an **SN65HVD230 / VP230 (3.3 V)**. An MCP2551 is 5 V and will damage the Teensy.
- The blue breakout usually has the 120 Ω terminator onboard (`R2 = 121`); it must sit at
  the **end** of the bus (Teensy ↔ MS3Pro = correct).
- TunerStudio: `CAN-Bus / Testmodes → Dash Broadcasting → Enable`, Automatic mode,
  500 kbps, base ID 1512 (0x5E8).
- Not required if you only use Direct sensors (opto tach + ADCs). RPM still comes off the
  tach in Direct mode either way — both sources always run.

---

## 12. SD card

Nothing to wire — the Teensy 4.1's built-in **SDIO socket** on the back of the board.
FAT32 micro-SD. Settings → Format SD card if the card is blank. Leave the socket clear of
the protoboard so the card can be removed.

---

## 13. Passive netlist — what to actually solder

| Qty | Part | End A | End B |
| --- | --- | --- | --- |
| 1 | 1 kΩ | J4 `SIG` / pre-driver collector | PC817 pin 1 (anode) |
| 1 | 4.7 kΩ | 3.3 V rail | PC817 pin 4 **and** Teensy pin 9 |
| 1 | 100 nF | Teensy pin 9 | GND |
| 1 | 1N4148 (opt) | PC817 pin 2 (cathode, K side) | PC817 pin 1 (anode, A side) |
| 1 | 10 kΩ | J5 `SIG` | Teensy pin 16 (A2) |
| 1 | 20 kΩ | Teensy pin 16 (A2) | GND |
| 1 | 10 nF (opt) | Teensy pin 16 (A2) | GND |
| 1 | 150 Ω | 3.3 V rail | J6 `SIG` **and** Teensy pin 17 (A3) |
| 1 | 20 kΩ 0.1 % | J7 `WHT` | divider midpoint |
| 1 | 20 kΩ 0.1 % | divider midpoint | J7 `BRN` / GND |
| 1 | 1 kΩ | divider midpoint | Teensy pin 20 (A6) |
| 1 | 100 nF | Teensy pin 20 (A6) | GND |
| 2 | 1 kΩ | Teensy pin 1 / pin 0 | J3 `TX` / J3 `RX` (series, in the cable) |
| 1 each | 100 nF ×3, 10 µF (opt) | 5 V rail / 3.3 V rail | GND (decoupling, near the Teensy) |
| — | PC817 (DIP-4) | see §3 | |
| — | 2N3904 + 100 kΩ + 10 kΩ | only for the §3b high-impedance version | |

Bare-wire jumpers: J1 `5V` → Teensy 5V; J1 5V → J2 5V; J1 5V → J5 5V;
J1 `GND` → GND rail → Teensy GND ×2 + every terminal GND below.

---

## 14. Continuity / meter checks before first power-up

With the 5 V buck **off** and the Teensy **out of its socket** if possible:

- [ ] `5V` rail to `GND` rail is **not** a short (expect >1 kΩ, or your DMM's diode reading).
- [ ] `3.3V` rail to `GND` rail is **not** a short.
- [ ] J4 `SIG` to J4 `GND` is not a short.
- [ ] J6 `SIG` to 3.3 V = **150 Ω**; J6 `SIG` to Teensy pin 17 = **0 Ω**.
- [ ] J5 `SIG` to Teensy pin 16 = **10 kΩ**; pin 16 to GND = **20 kΩ**.
- [ ] J7 `WHT` to J7 `BRN` = **40 kΩ** (both 0.1 % legs); midpoint to pin 20 = **1 kΩ**.
- [ ] J2 `TX`/`RX` land on Teensy **14**/**15** (not swapped, not 43/44).
- [ ] J3 `TX`/`RX` land on Teensy **1**/**0**, with the 1 kΩ in series.

Then power up and check in order: 5.0 V on J1, 3.3 V on the Teensy rail, GPS fix,
`MPU-6050 ready` on the USB serial banner, `FreqMeasureMulti on pin 9: armed`,
and RPM/Coolant/Oil responding before turning on AEM or the video link.

---

## 15. Settings to enable, and only when the wire exists

| Setting | Enable when |
| --- | --- |
| Sensor data source | Direct (opto tach + ADCs) unless you wired CAN or BLE |
| Tach pulses/rev | after comparing tach RPM against a trusted reference |
| AEM 30-0300 AFR input | J7 soldered and **pin 20 meters 2.50 V at 5.00 V in** |
| Video interconnect | J3 wired and the Pi UART answers |
| Debug logging (SD) | only when chasing a problem (default OFF) |
| RPM spike filter / GPS drift filter | default Normal — leave alone until the car runs |

---

## 16. Not on this board (don't go looking for them)

These exist only on **Rev D** (`hardware/teensy-integrated-revd/`) and have **no
firmware**: the ESP32-S3 trunk WiFi coprocessor over SPI0 (pins 10/11/12/13 + 5/6),
the CR2032 VBAT cell, the ICM-42670-P IMU (this build uses the MPU-6050), the
THROTTLE/BRAKE analogue inputs, and the Rev D oil/coolant gain changes. Pin 13 stays the
heartbeat LED here. The screen's own WiFi remains the only network path, and the OTA
path is unchanged.

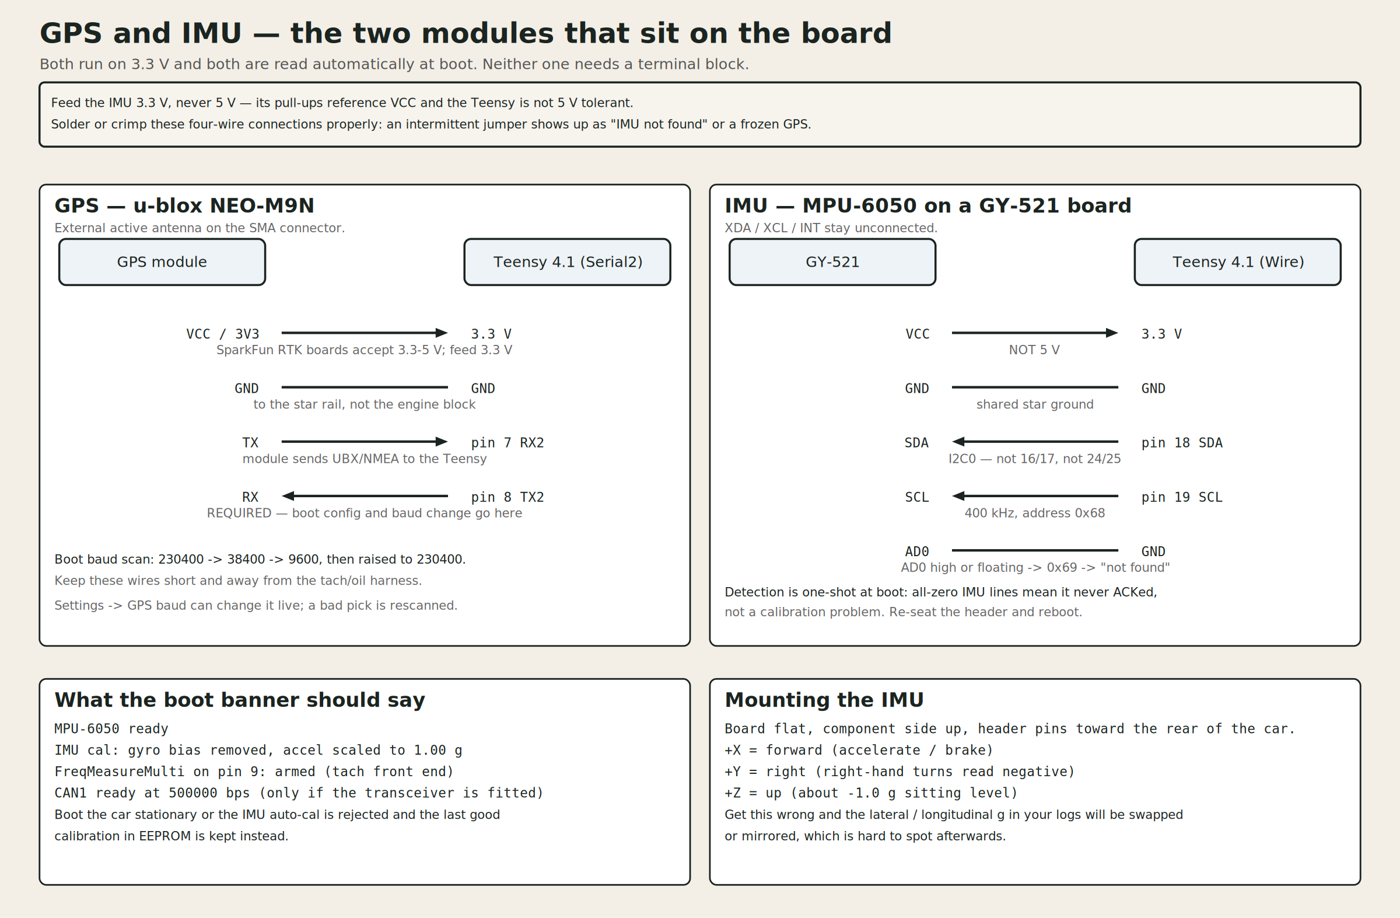
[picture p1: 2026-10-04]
hardware/Prototype/03-GPS-and-IMU.png

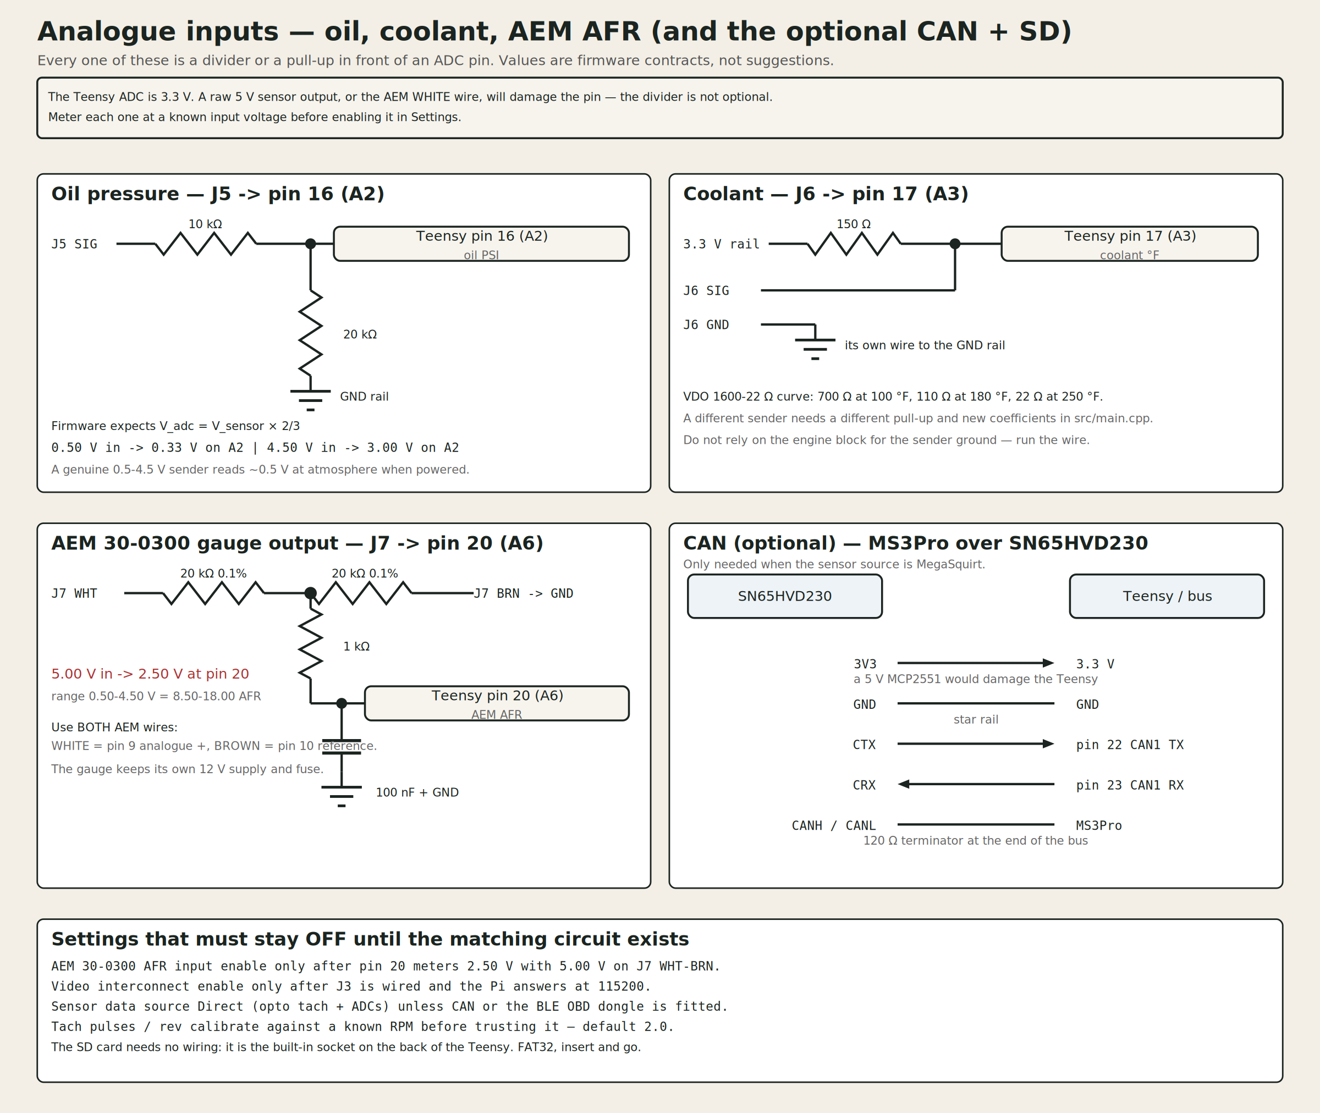
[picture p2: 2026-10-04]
hardware/Prototype/04-Analogue-inputs.png

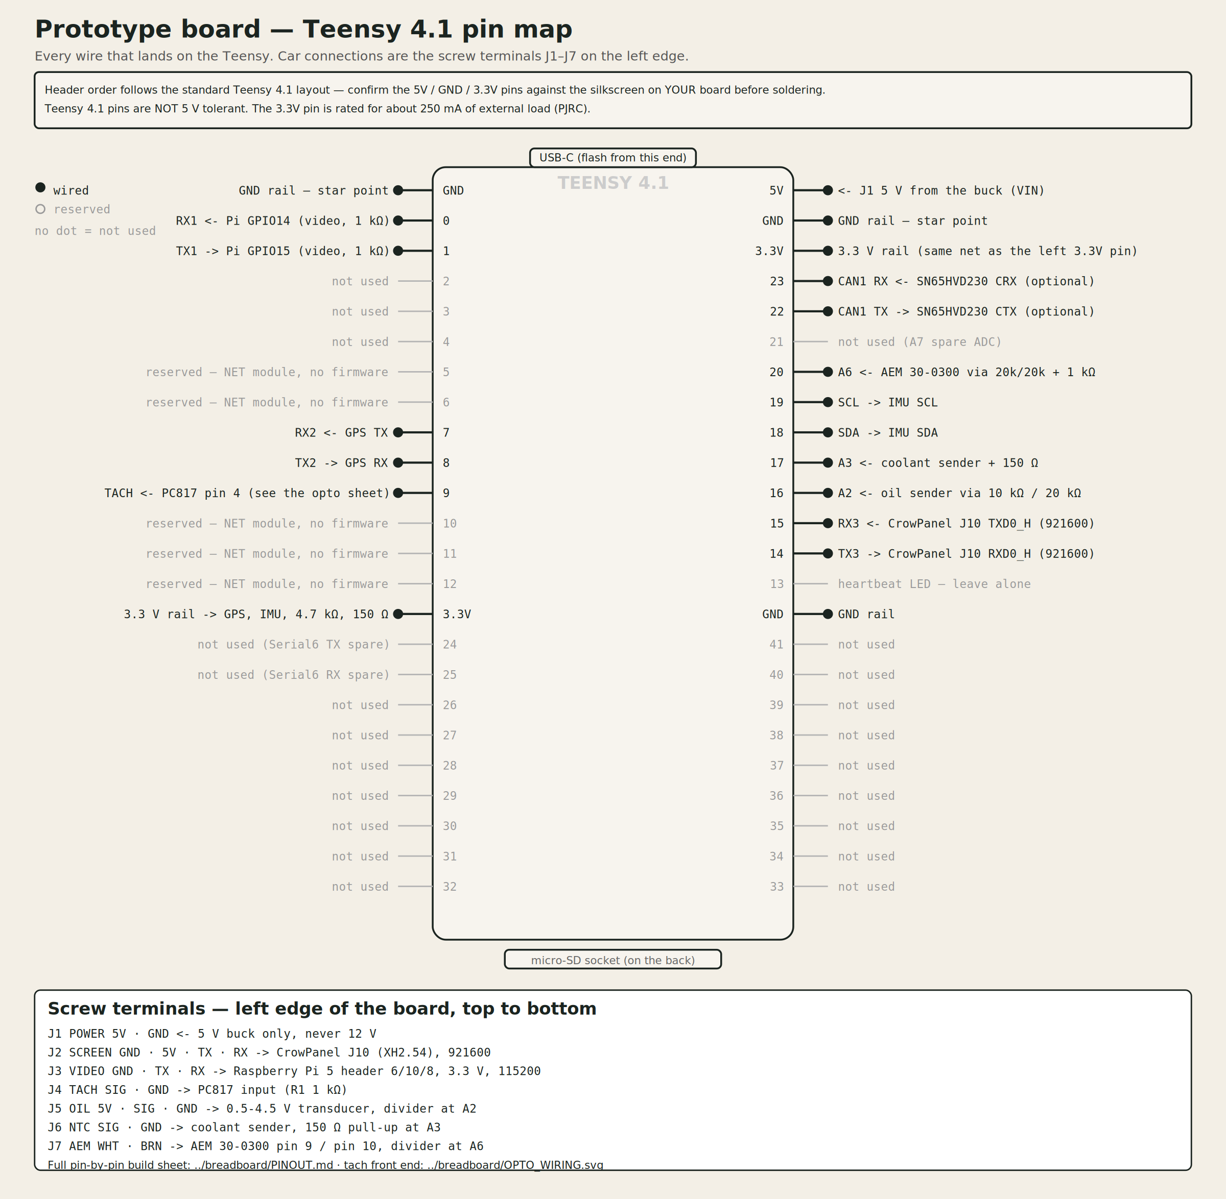
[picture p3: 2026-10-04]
hardware/Prototype/00-Teensy-pin-map.png

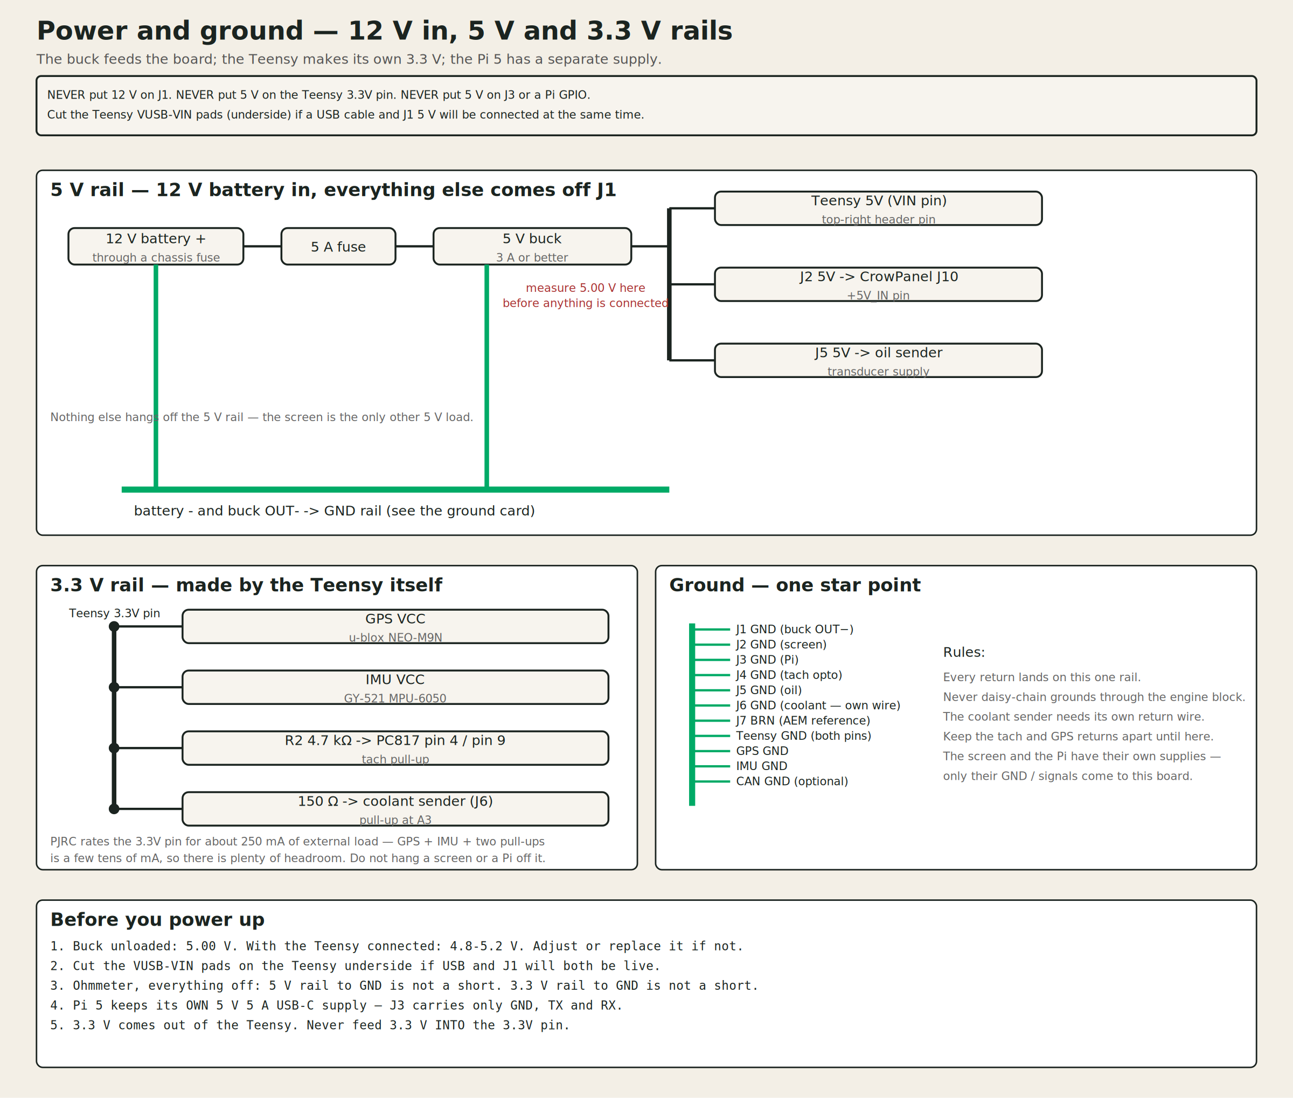
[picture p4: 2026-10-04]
hardware/Prototype/01-Power-and-ground.png

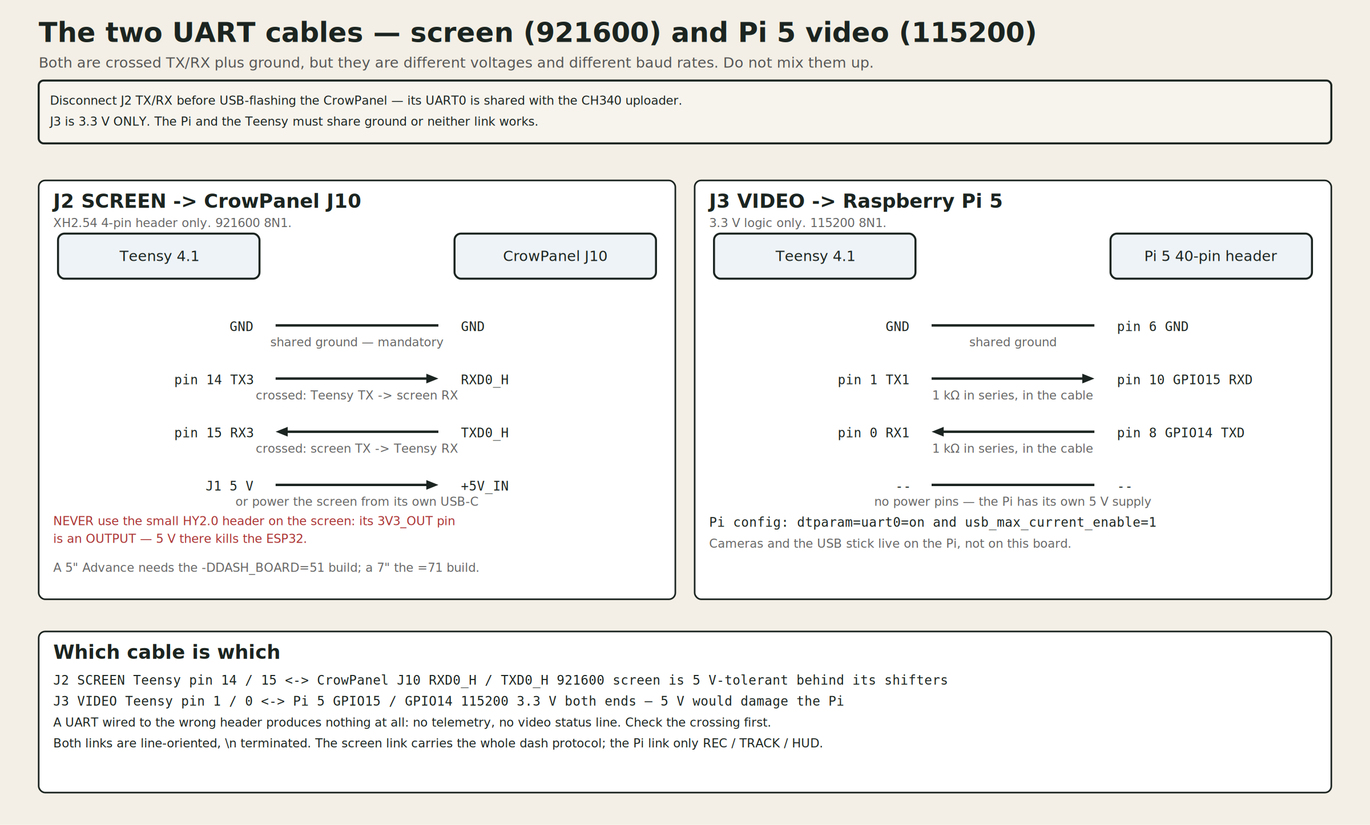
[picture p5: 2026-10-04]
hardware/Prototype/02-UART-screen-and-video.png

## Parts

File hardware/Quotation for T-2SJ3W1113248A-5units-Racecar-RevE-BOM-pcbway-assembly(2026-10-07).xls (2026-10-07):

PCBWay Bom Quotation, Product No.:T-2SJ3W1113248A
Item # | *Designator | *Qty | Manufacturer | *Mfg Part # | Description / Value | *Package/Footprint | *Unit Price(5 units) | *Total | *Delivery Time | *Actual Purchase Mfg Part # | *PCBWay Note | Customer Reply | PCBWay Update
1 | Q3 | 1 | Alpha & Omega Semiconductor | AO4485 | AO4485 P-FET 40V (Q_REV) | SOIC-8_3.9x4.9mm_P1.27mm | $0.370 | $1.850
2 | R51 R54 R3 R4 R9 R12 R37 R38 R39 R44 | 10 | Yageo | RC0805FR-0710KL | 10k 1% (R_REVG) | R_0805_2012Metric | $0.012 | $0.600
3 | D24 | 1 | Nexperia | BZX84C15 | BZX84C15 (D_REVZ) | SOT-23 | $0.055 | $0.275 |  | BZX84-C15,215 | The part we will supply is BZX84-C15,215 OK？
4 | C43 C3 C5 C7 C8 C9 C12 C15 C16 C17 C19 C20 C21 C22 C23 C24 C25 C26 C40 C27 C28 C29 C30 C31 C32 C33 C35 C37 C38 C39 | 30 | Murata | GRM21BR71H104KA01L | 100n (C_BOOT) | C_0805_2012Metric | $0.051 | $7.650
5 | U2 | 1 | Texas Instruments | TPS54560BDDAR | TPS54560B 5V 5A BUCK (U2) | SOIC-8-1EP_3.9x4.9mm_P1.27mm_EP2.41x3.3mm | $0.932 | $4.660
6 | C41 C42 | 2 | Murata | GRM32ER71H106KA12L | 10uF 50V X7R 1210 (C_IN1) | C_1210_3225Metric | $1.274 | $12.740
7 | D23 | 1 | MDD | SS56 | SS56 catch diode (D_MAIN) | D_SMB | $0.137 | $0.685 |  |  | The correct package for the listed Part Number [SS56] is indeed [SMA(DO-214AC)], not [SMB].Please confirm.
8 | L2 | 1 | Vishay | IHLP4040DZER6R8M01 | 6.8uH 8A RMS SHIELDED (L_MAIN) | L_Vishay_IHLP-4040 | $1.098 | $5.490
9 | C44 C45 C46 | 3 | Murata | GRM32ER61C476KE15L | 47uF 16V X5R 1210 (C_OUT1) | C_1210_3225Metric | $0.802 | $12.030
10 | R53 | 1 | Yageo | RT0805BRD0752K3L | 52.3k 0.1% (R_FBH) | R_0805_2012Metric | $0.270 | $1.350
11 | R55 | 1 | Yageo | RC0805FR-0716K9L | 16.9k 1% (R_COMP) | R_0805_2012Metric | $0.033 | $0.165
12 | C47 | 1 | Samsung | CL21B472KBANNNC | 4.7n (C_COMP) | C_0805_2012Metric | $0.087 | $0.435
13 | C48 | 1 | Samsung | CL21C470JBANNNC | 47p (C_CPOLE) | C_0805_2012Metric | $0.068 | $0.340
14 | R52 R8 | 2 | Yageo | RC0805FR-07240KL | 240k 1% (R_RT) | R_0805_2012Metric | $0.028 | $0.280
15 | R56 | 1 | Yageo | RC0805FR-07680KL | 680k 1% (R_UV1) | R_0805_2012Metric | $0.049 | $0.245
16 | R57 R13 R40 | 3 | Yageo | RC0805FR-07100KL | 100k 1% (R_UV2) | R_0805_2012Metric | $0.022 | $0.330
17 | U3 U6 | 2 | TRACO Power | TSR 1-2433 | TSR 1-2433 (U3) | Converter_DCDC_TRACO_TSR-1_THT | $9.475 | $94.750 | 7-10 Workdays
18 | C4 C6 C13 C34 | 4 | Murata | GRM21BR61E106KA73L | 10u (C_U3O) | C_0805_2012Metric | $0.450 | $9.000
19 | J1 J3 J5 J6 | 4 | Phoenix Contact | 1729018 | POWER IN (J1) | TerminalBlock_Phoenix_MKDS-1,5-2-5.08_1x02_P5.08mm_Horizontal | $0.419 | $8.380
20 | F1 | 1 | Littelfuse | 0451005.MRL | 5A fuse (F1) | Fuse_Littelfuse-NANO2-451_453 | $0.638 | $3.190
21 | F2 | 1 | Littelfuse | 0451003.MRL | 3A fuse (F2) | Fuse_Littelfuse-NANO2-451_453 | $0.250 | $1.250
22 | D1 | 1 | Littelfuse | SMBJ20CA | SMBJ20CA (D1) | D_SMB | $0.144 | $0.720
23 | C1 | 1 | Panasonic | EEU-FR1H101 | 100uF 50V (C1) | CP_Radial_D8.0mm_P3.50mm | $1.249 | $6.245
24 | C2 | 1 | Panasonic | EEU-FR1A471B | 470uF 10V (C2) | CP_Radial_D8.0mm_P3.50mm | $1.743 | $8.715 | 7-10 Workdays
25 | D2 | 1 | onsemi | SS14 | SS14 (D2) | D_SMA | $0.146 | $0.730
26 | JP1 | 1 | Samtec | TSW-102-07-G-S | MCU POWER (JP1) | PinHeader_1x02_P2.54mm_Vertical | $0.777 | $3.885
27 | U1 | 1 | PJRC | TEENSY41 | Teensy 4.1 SOCKETED (U1) | Teensy41_Socket |  |  |  |  | [It's out of stock. Please recommend substitutes or you can supply this part to us.]
28 | BT1 | 1 | Keystone | 1058 | CR2032 HOLDER (BT1) | BatteryHolder_Keystone_1058_1x2032 | $2.514 | $12.570 | 7-10 Workdays |  | The quoted part number is [1058], not [CR2032] as specified in description
29 | J9 | 1 | JST | B2B-XH-A(LF)(SN) | TO TEENSY VBAT/GND (J_BAT) | JST_XH_B2B-XH-A_1x02_P2.50mm_Vertical | $0.059 | $0.295
30 | J7 J13 | 2 | JST | B4B-XH-A(LF)(SN) | CAN MODULE LOGIC (J6) | JST_XH_B4B-XH-A_1x04_P2.50mm_Vertical | $0.111 | $1.110
31 | R1 R2 R18 R21 R24 R27 R30 R50 | 8 | Yageo | RC0805FR-071KL | 1k 1% (R_VIDTX) | R_0805_2012Metric | $0.008 | $0.320
32 | D3 D4 D19 D20 | 4 | Nexperia | PESD5V0S1BA,115 | UART ESD (D_VIDTX) | D_SOD-323 | $0.083 | $1.660
33 | U7 | 1 | TDK InvenSense | ICM-42670-P | ICM-42670-P (U_IMU) | InvenSense_LGA-14_2.5x3.0mm_P0.50mm | $3.140 | $15.700
34 | C10 | 1 | Samsung | CL21B103KBANNNC | 10n (C_IMUL) | C_0805_2012Metric | $0.074 | $0.370
35 | C11 | 1 | Yageo | CC0805KKX7R9BB225 | 2.2u (C_IMUR) | C_0805_2012Metric | $0.888 | $4.440
36 | U8 | 1 | u-blox | NEO-M9N-00B | NEO-M9N-00B (U_GPS) | ublox_NEO | $21.176 | $105.880
37 | J8 | 1 | Amphenol RF | 901-143 | GPS SMA FEMALE (J_ANT) | SMA_Amphenol_901-143_Horizontal | $41.123 | $205.615 | 7-10 Workdays
38 | C14 | 1 | Murata | GRM1555C1H101JA01D | 100pF C0G (C_RF) | C_0402_1005Metric | $0.069 | $0.345
39 | L1 | 1 | Murata | LQG15HS27NJ02D | 27nH RF choke (L_RF) | L_0402_1005Metric | $0.120 | $0.600
40 | D5 | 1 | Nexperia | PESD5V0F1BL,315 | RF ESD (D_RF) | D_SOD-882 | $0.132 | $0.660
41 | U9 | 1 | Texas Instruments | TPS2553DBVR | TPS2553 (U_ANT) | SOT-23-6 | $0.459 | $2.295
42 | R5 | 1 | Yageo | RC0805FR-0710RL | 10R 1% (R_ANT_FILTER) | R_0805_2012Metric | $0.072 | $0.360
43 | U10 U20 | 2 | Texas Instruments | SN74LVC1G125DBVR | SN74LVC1G125 (U_GTX) | SOT-23-5 | $0.065 | $0.650
44 | R6 | 1 | Yageo | RC0805FR-07180KL | 180k 1% (R_TTOP) | R_0805_2012Metric | $0.057 | $0.285
45 | R7 | 1 | Yageo | RC0805FR-0722KL | 22k 1% (R_TBOT) | R_0805_2012Metric | $0.035 | $0.175
46 | C18 | 1 | Yageo | CC0805KRX7R9BB102 | 1n (C_TFILTER) | C_0805_2012Metric | $0.049 | $0.245
47 | D6 | 1 | Texas Instruments | LM4040AIM3-2.5/NOPB | LM4040 2.5 (D_TPOS) | SOT-23 | $4.022 | $20.110 | 7-10 Workdays
48 | D7 D9 D11 D13 D15 D17 D22 D18 | 8 | Nexperia | PMEG2010ER,115 | PMEG2010ER (D_TNEG) | Nexperia_CFP3_SOD-123W | $0.226 | $9.040
49 | U11 | 1 | Texas Instruments | LM2903BIDR | LM2903B (U_CMP) | SOIC-8_3.9x4.9mm_P1.27mm | $0.093 | $0.465
50 | R10 | 1 | Yageo | RC0805FR-072M2L | 2.2M 1% (R_THYST) | R_0805_2012Metric | $0.044 | $0.220
51 | R11 R15 | 2 | Yageo | RC0805FR-074K7L | 4.7k 1% (R_TPULL) | R_0805_2012Metric | $0.030 | $0.300
52 | Q1 Q2 | 2 | Nexperia | MMBT3904,215 | MMBT3904 (Q_TLED) | SOT-23 | $0.072 | $0.720
53 | R14 | 1 | Yageo | RC0805FR-07680RL | 680 1% (R_TLED) | R_0805_2012Metric | $0.039 | $0.195
54 | U12 | 1 | Vishay | VO617A-3X017T | VO617A-3 (U_OPTO) | SMDIP-4_W9.53mm | $0.249 | $1.245
55 | U13 | 1 | Texas Instruments | SN74LVC2G17DBVR | SN74LVC2G17 (U_INPUT) | SOT-23-6 | $0.190 | $0.950
56 | J4 J11 J12 | 3 | Phoenix Contact | 1729021 | OIL 0.5-4.5V (J_OIL) | TerminalBlock_Phoenix_MKDS-1,5-3-5.08_1x03_P5.08mm_Horizontal | $0.727 | $10.905
57 | F3 F4 F5 | 3 | Littelfuse | 1206L010/60WR | 100mA PTC (F_SENSOR) | Fuse_1206_3216Metric | $0.226 | $3.390
58 | R16 R17 R19 R20 R22 R23 R25 R26 R28 R29 R49 | 11 | Yageo | RT0805BRD0720KL | 20k 0.1% (R_OILH) | R_0805_2012Metric | $0.184 | $10.120
59 | D8 D10 D12 D14 D16 D21 | 6 | Texas Instruments | LM4040AIM3-3.0/NOPB | LM4040 3.0 (D_OILP) | SOT-23 | $1.698 | $50.940
60 | R48 | 1 | Yageo | RT0805BRD07180KL | 180k 0.1% (R_VINMONH) | R_0805_2012Metric | $0.384 | $1.920
61 | R31 | 1 | Yageo | RC0805FR-07150RL | 150 1% (R_NTC_BIAS) | R_0805_2012Metric | $0.058 | $0.290
62 | U14 | 1 | Texas Instruments | LM4040AIM3-4.1/NOPB | LM4040 4.1 (U_NTC_REF) | SOT-23 | $2.095 | $10.475
63 | R32 | 1 | Yageo | RT0805BRD072K49L | 2.49k 0.1% (R_NTC_PU) | R_0805_2012Metric | $0.357 | $1.785
64 | U15 U16 | 2 | Texas Instruments | TMUX1511PWR | TMUX1511 (U_ADC) | TSSOP-14_4.4x5mm_P0.65mm | $0.537 | $5.370
65 | J2 | 1 | Phoenix Contact | 1729034 | SCREEN J10 ONLY (J2) | TerminalBlock_Phoenix_MKDS-1,5-4-5.08_1x04_P5.08mm_Horizontal | $3.638 | $18.190 | 7-10 Workdays
66 | U4 U5 | 2 | Texas Instruments | SN74LVC1T45DBVR | SN74LVC1T45 (U4) | SOT-23-6 | $0.065 | $0.650
67 | R33 R34 | 2 | Yageo | RC0805FR-07100RL | 100 1% (R_DTX) | R_0805_2012Metric | $0.024 | $0.240
68 | R35 R36 R45 R46 R47 | 5 | Yageo | RC0805FR-0747KL | 47k 1% (R_DTIDLE) | R_0805_2012Metric | $0.019 | $0.475
69 | U17 | 1 | Espressif | ESP32-S3-WROOM-1-N8R2 | ESP32-S3-WROOM-1-N8R2 (U_NET) | ESP32-S3-WROOM-1 | $4.226 | $21.130
70 | C36 | 1 | Murata | GRM21BR71H105KA12L | 1u (C_NETEN) | C_0805_2012Metric | $0.272 | $1.360
71 | U18 | 1 | Texas Instruments | SN74LVC125APWR | SN74LVC125A (U_SPI_TX) | TSSOP-14_4.4x5mm_P0.65mm | $0.280 | $1.400
72 | R41 R42 R43 | 3 | Yageo | RC0805FR-0733RL | 33 1% (R_NETCS) | R_0805_2012Metric | $0.018 | $0.270
73 | U19 | 1 | Texas Instruments | SN74LVC2G125DCUR | SN74LVC2G125 (U_SPI_RX) | VSSOP-8_2.3x2mm_P0.5mm | $0.163 | $0.815
74 | J10 | 1 | Samtec | TSW-103-07-G-D | NET 3V3 UART SERVICE (J_NET_SERVICE) | PinHeader_2x03_P2.54mm_Vertical | $0.848 | $4.240 | 7-10 Workdays
75 | H1 H2 H3 H4 | 4 | Assembly | M3 insulated hardware | M3 MOUNT (H1) | MountingHole_3.2mm_M3 |  |  |  |  | pls provide exact part number and brand
76 | TP1 TP2 TP3 TP4 TP5 | 5 | PCB | PCB test pad | GND (TP1) | TestPoint_THTPad_D2.0mm_Drill1.0mm |  |  |  |  | pls provide exact part number and brand
 |  |  |  |  |  |  | Component Cost | $716.77
 |  |  |  |  |  |  | Assembly Cost | $88.00
 |  |  |  |  |  |  | PCB Cost | $174.05
 |  |  |  |  |  |  | All Total 5 Units | $978.83

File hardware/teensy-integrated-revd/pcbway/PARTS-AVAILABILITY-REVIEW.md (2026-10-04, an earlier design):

# Rev D — parts availability review (PCBWay quote T-2SJ3W1113248A, 5 units)

> **STATUS: APPLIED (2026-09-29), with U1/U2 handled in the reply letter.** The six
> substitutions below are baked into `../components.json`, `../electrical/generate.py`,
> `../design/BOM.csv` and both `pcbway/*BOM*.csv`; the engineering fab ZIP was
> re-exported so its shipped `BOM.csv` matches (ERC/DRC 0 violations, 531
> assertions, 456 pads).
>
> **STATUS update (2026-09-30): U2 is now a SOCKET.** PCBWay's second attempt
> (quote `T-2SJ3W1113248A`, 2026-09-30) again could not source the Pololu 4091, so
> the module is **de-scoped from their sourcing**: they fit a **2×6 0.1 in THT female
> socket** (Samtec `SSW-106-01-G-D` proposed) into the U2 footprint and **we buy the
> five modules and plug them in**. No footprint change, no respin. See §4b.
>
> **Decision on the two modules:**
> * **U2 (Pololu D36V50F5) — socket fitted by PCBWay, module supplied by us.** It is
>   not an LCSC part; Pololu direct is *Rationed* and neither source would sell to
>   PCBWay. We buy 5× Pololu 4091 (US$36.75 ea at qty 5), solder their supplied pin
>   strips on, and plug them in; consignment to PCBWay for that step is offered in
>   the 09-30 letter.
> * **U1 (Teensy 4.1) — customer supplied**, bought *with pins* so the module needs
>   no soldering; PCBWay fits the two 1×24 sockets, we plug the Teensy in.
> * Left to us, all plug-in or hand steps: the CR2032 cell, the JP1 shunt (after
>   bench tests), plugging in the Teensy and the Pololu module, and the 2-wire J9
>   RTC lead.
>
> ⚠️ **The module can be plugged in the mirrored way round and that destroys it**
> (VIN would meet the 5 V rail, VOUT would meet 10–20 V). The carrier footprint has
> no silkscreen labels at all, so the orientation keys are the module's own four
> **square** GND holes, the **single rectangular U2 pad 1**, and the pre-power
> continuity check in `../design/BRINGUP.md` step 3 — all three are in §4b.
>
> The reply to send is **`PCBWAY-REPLY-2026-09-29.pdf`** with
> **`Racecar-RevD-BOM-pcbway-assembly-REV1.csv`** (identical content to the
> canonical `Racecar-RevD-BOM-pcbway-assembly.csv`, under a distinct name so
> PCBWay can tell it from the file they already have; the Comment column carries
> the U1/U2 fitting instructions).

Reviewed **2026-09-29** against the PCBWay Bom Quotation
`Quotation for T-2SJ3W1113248A-5units-Racecar-RevD-BOM-pcbway-assembly(2026-09-29).xls`
and the local `Racecar-RevD-BOM-pcbway-assembly.csv`.

**Result: 6 BOM lines need correcting** — three are outright bad MPNs (F3–F5,
D5, D2) and three are Murata capacitors with no LCSC stock (C10, C11, C18); on
the latter, two of PCBWay's proposed substitutes are fine and one must be
counter-proposed. There is also one clarification (BT1) and one price risk
(U8, u-blox). Everything else in the BOM is obtainable — the remaining risk is
*who* buys the consignment parts (see §4).

---

## 1. What PCBWay actually flagged

| Item | Ref | MPN | PCBWay note |
|---|---|---|---|
| 1 | U2 | `4091 / D36V50F5` | out of stock — recommend a substitute or supply it |
| 11 | D2 | `SS14` | out of stock — substitute or supply |
| 13 | U1 | `TEENSY41` | out of stock — substitute or supply |
| 28 | D5 | `PESD3V3U1UL,315` | out of stock — substitute or supply |
| 48 | F3 F4 F5 | `1206L010/30YR` | out of stock — substitute or supply |
| 21 | C10 | `GRM21BR71H103KA01L` | will supply `CL21B103KBANNNC` — OK? |
| 22 | C11 | `GRM21BR71H225KA01L` | will supply `CL21A225KBQNNNE` — OK? |
| 35 | C18 | `GRM21BR71H102KA01L` | will supply `CC0805KRX7R9BB102` — OK? |
| 14 | BT1 | `1058` | "the quoted part number is 1058, not CR2032 as in the description" |
| 24 | U8 | `NEO-M9N-00B` | "price is changing higher, final price subject to real price at order" |

Lead-time notes (7–10 workdays, i.e. ordered-in, **not** a problem): TSR 1-2433,
EEU-FR1A471B, 1058, 901-143, RT0805BRD0720KL, 1729034.

---

## 2. Required BOM changes

| # | Ref | Old MPN | Problem (verified) | New MPN | LCSC | LCSC stock | Other sources |
|---|---|---|---|---|---|---|---|
| 1 | F3 F4 F5 | `1206L010/30YR` | **This part number does not exist.** Littelfuse's own 1206L datasheet (rev BA 12/04/20) lists the 0.10 A device as **1206L010/60** only; there is no `/30` 100 mA variant (`/30` exists only at 0.20 A and 0.35 A). The `YR` reel code belongs to the 0.20–1.1 A rows. | **`1206L010/60WR`** | C2153714 | 6,922 | Digi-Key 4,861; Newark 10,764 |
| 2 | D5 | `PESD3V3U1UL,315` | Effectively unavailable: LCSC 2 pcs, Newark/Digi-Key/TME/Avnet all 0. | **`PESD5V0F1BL,315`** (recommended) or `PESD5V0U1UL,315` | C45961 / C85401 | 51,874 / 9,875 | standard Nexperia line |
| 3 | D2 | `SS14` (Mfr: Diodes Inc) | Bare `SS14` is not an orderable Diodes Inc PN, so PCBWay's supplier had nothing to match. | **onsemi `SS14`** (or Vishay `SS14-E3/61T`) | C83852 | 139,581 | LCSC also has 1.2 M generic-brand SS14; Digi-Key onsemi SS14 200,489 |
| 4 | U2 | `4091 / D36V50F5` | Not an LCSC part; Pololu direct is **Rationed / backorder-only**; PCBWay could not source it in **two** attempts. | **fit a 2×6 0.1 in THT female socket** (`SSW-106-01-G-D`); we plug the module in (§4b) | — | — | **Digi-Key 2183-4091-ND, 264 pcs, $39.95**; Pololu direct $36.75 @5 |
| 5 | U1 | `TEENSY41` | Not an LCSC part. | keep `TEENSY41` | — | — | **Digi-Key / SparkFun `DEV-16771`, 1,169 pcs, $31.50**; PJRC direct |
| 6 | C11 | `GRM21BR71H225KA01L` | Murata part has no LCSC stock. PCBWay's proposed `CL21A225KBQNNNE` is **X5R (85 °C)** — the original is **X7R (125 °C)**. | **`CC0805KKX7R9BB225`** (Yageo) or `CL21B225KBYNNNE` (Samsung) | C125847 / C2762602 | 110,671 / 83,283 | Digi-Key CC0805KKX7R9BB225 248,725 |

### Approve as-is (PCBWay's proposals are electrically equivalent)

| Item | Ref | Proposed | Verdict |
|---|---|---|---|
| 21 | C10 | `CL21B103KBANNNC` | **OK** — Samsung 10 nF 50 V **X7R** 0805, exactly the original spec (LCSC C1710, 2.3 M). |
| 35 | C18 | `CC0805KRX7R9BB102` | **OK** — Yageo 1 nF 50 V **X7R** 0805, exactly the original spec (LCSC C94121, 1.66 M). |
| 22 | C11 | `CL21A225KBQNNNE` | **Not as-is** — X5R/85 °C. Use the X7R part in row 6 above. |

### Clarification (no change needed)

| Item | Ref | Answer |
|---|---|---|
| 14 | BT1 | `1058` **is** the correct part. It is Keystone's SMD 20 mm coin-cell holder ("BATTERY HOLDER COIN 20MM SMD", Digi-Key `36-1058-ND`); *CR2032* in the description is the **cell**, which the BOM does not include and which is fitted by hand after reflow. Nothing to change — just confirm 1058 to PCBWay. |

---

## 3. Note on D5 — a better part than the original

`D5` sits on the **RF_ANT** net, i.e. the SMA antenna port
(`RF_ANT = C14 · D5 · J8 · L1`), and that port carries the **switched 3.3 V
active-antenna bias** (`+3V3_AUX → U9 TPS2553 → ANT_SWITCH → R5 10 R → ANT_BIAS → L1 → RF_ANT`).
The original `PESD3V3U1UL` has a **3.3 V standoff**, i.e. zero margin on a 3.3 V
bias line. Both replacements are in the same **SOD-882 / DFN1006-2** footprint
(no layout change) and are strictly better:

| Part | Standoff | Cd @ 0 V | Note |
|---|---|---|---|
| PESD3V3U1UL (original) | 3.3 V | 2.6 pF typ | out of stock |
| PESD5V0U1UL,315 | 5.0 V | 2.0 pF typ | unidirectional, closest like-for-like |
| **PESD5V0F1BL,315** | 5.5 V | **0.4 pF typ / 0.55 max** | bidirectional, femtofarad class, sold for antenna protection |

`PESD5V0F1BL` loses ~2 pF of shunt capacitance on a 1575 MHz feed, which is the
right direction for GNSS. Pin 1 marking is irrelevant on a bidirectional part.

---

## 4. Parts that are not LCSC line items — who gets them

Stock verified 2026-09-29. **U2 and U1 are the only two the quote's automatic
sourcing failed on; the letter asks PCBWay to buy U2 from Digi-Key/Pololu and ship
the sockets, and we supply the Teensy.** Everything else in this table PCBWay can
quote directly (they already price most of it in the quote).

| Ref | Part | Source (verified) | Stock | Price |
|---|---|---|---|---|
| U2 | Pololu 4091 / D36V50F5 | **Digi-Key 2183-4091-ND** | 264 | $39.95 (1) |
| U1 | Teensy 4.1 — **order the "with pins" version** | **Digi-Key** (SparkFun `DEV-16771`) or PJRC | 1,169 | $31.50 |
| U8 | u-blox NEO-M9N-00B | **LCSC C5119087** | 516 | $16.31 |
| U17 | ESP32-S3-WROOM-1-N8R2 | **LCSC C2913204** | 2,794 | $4.63 |
| U7 | TDK ICM-42670-P | **LCSC C3288646** (alt Newark) | 10,525 (LCSC) / 2,298 (Newark) | $2.28 |
| U3 U6 | TRACO TSR 1-2433 | **Digi-Key** (alt TME / Newark / Sager) | 9,405 / 5,162 / 573 / 11,697 | $6.28 (1) |
| J8 | Amphenol 901-143 SMA | **Digi-Key** | 1,730 | $26.31 (1) / $22.36 (10) |
| BT1 | Keystone 1058 | **Digi-Key 36-1058-ND** / TME | 1,610 / 458 | $1.34 (1) |
| J1 J3 J5 J6 | Phoenix 1729018 | **Digi-Key** | 13,434 | $0.95 (1) |
| J4 J11 J12 | Phoenix 1729021 | LCSC C3817836 (alt TME / Dynamic Solutions) | 857 / 180 / 1,800 | $0.78 |
| J2 | Phoenix 1729034 | **Digi-Key** 2,058 / Newark 2,630 | — | $1.94 (1) |
| J10 | Samtec TSW-103-07-G-D | **Digi-Key** (alt Avnet; LCSC only 73) | 10,111 / 16,238 | $0.69 (1) |
| J7 J9 J13 | JST B2B/B4B-XH-A | LCSC C158012 / C144395 | 344 k / 93 k | $0.04 / $0.06 |
| U12 | Vishay VO617A-3X017T | Digi-Key (alt LCSC C3035004) | 22,072 / 466 | — |

**⚠️ TRACO clone on LCSC:** LCSC *does* list a "TSR 1-2433" (C53183919, 1,791
pcs, $5.46) but the brand is **YLPTEC**, not TRACO Power. Do not accept it as the
TRACO part or as a PCBWay substitution. Buy the genuine part from Digi-Key /
TME / Newark / Sager.

**⚠️ Not in the BOM at all (assembly extras + hand-fit items).** `../design/ASSEMBLY-EXTRAS.csv`
is the full list; the ones that matter for this order:

| Qty/board | Part | Who | Stock / price |
|---|---|---|---|
| 2 | 1×24 2.54 mm female socket (Samtec `SSW-124-01-G-S`) — soldered into the U1 footprint | **PCBWay to fit** | Newark 427 @ $4.20 · Digi-Key 175 (we can consign the Samtec parts) |
| 1 | 2×6 0.1 in THT **female socket** (Samtec `SSW-106-01-G-D`) — soldered into the U2 footprint | **PCBWay to fit** | ≥3 A/pin; ~$1 (we can consign) |
| 1 | Pololu 4091 module + its two 1×6 pin strips — **plugs into that socket** | us — we solder the strips into the module, then plug it in | Pololu $36.75 ea @ qty 5 |
| 1 | Teensy 4.1 **with pins** (PJRC sells this variant) | us — plugs into the sockets, no soldering | Digi-Key / PJRC, $31.50 |
| 1 | CR2032 primary cell — **never reflowed**, fitted after cleaning | us | any |
| 1 | JP1 shunt (Harwin `M7566-05`) — **only after unloaded rail tests** | us | Digi-Key 5,393 · Newark 15,847, $0.30 |
| 1 | RTC lead: JST `XHP-2` housing + 2× `SXH-001T-P0.6` contacts + hook-up wire (J9 → Teensy VBAT/GND pads) | us | Digi-Key 262,854 · 1,329,000 |

---

### 4b. U2 — de-scoped to a fitted socket (2026-09-30)

PCBWay's second attempt (quote `T-2SJ3W1113248A`, 2026-09-30) still could not
source the Pololu 4091: item 1 is the **only unpriced line** in the quote and
neither Digi-Key nor Pololu would sell to them. Rather than ask a third time, the
module comes off their sourcing entirely.

| | Before (09-29 letter) | Now (09-30) |
|---|---|---|
| U2 BOM line, PCBWay | source **and fit** the Pololu 4091 | fit a **2×6 0.1 in THT female socket** (`SSW-106-01-G-D` proposed) |
| Pololu 4091 module | PCBWay buys it (Digi-Key `2183-4091-ND`) | **we buy 5×** (Pololu $36.75 ea at qty 5) and plug them in |
| Footprint, nets, Gerbers, CPL | — | **unchanged** — the socket uses the same 12 through-holes, so no respin and no re-export |
| Fitted cost | part + sourcing fee + shipping | ~$1 commodity socket; we pay the module ourselves |

Why this way round:

- It removes the **last unpriced line** immediately and depends on nobody's stock.
- A socket is a commodity part any assembler has in the house, and it has **no
  polarity** — the "which way round" problem moves to a mechanical key on the
  module instead of a soldering decision.
- Consignment (ship the five $40 modules to PCBWay so they solder the strips too)
  remains available **in writing** from them; the 09-30 letter asks them to quote
  it. Under the socket plan the only hand joint left is **soldering each module's
  two 1×6 strips into the module itself** — 12 joints, ~5 minutes each, nothing on
  the board.

Socket candidates (LCSC stock/ratings read 2026-09-30):

| LCSC | MPN | Rating | Body | Stock | Note |
|---|---|---|---|---|---|
| **C3323352** | Samtec `SSW-106-01-G-D` | **4.7 A/pin** | 8.51 mm, gold, −55…+125 °C | 17 | **primary** — same SSW family as the U1 socket PCBWay already bought |
| C2894967 | HCTL `PZ254-2-06-Z-8.5` | 3 A/pin | 8.5 mm, −40…+105 °C | 3,446 | commodity fallback |
| C239346 | CJT `A2541HWV-2x6P` | 3 A/pin | 8.5 mm | 2,134 | second fallback |

At the **5 A total** budget VIN and VOUT are each carried by 2 socket pins, so the
worst case is 2.5 A/pin: **≥3 A/pin is the requirement**, and the Samtec part has
real margin. Mounted stack height is ~19 mm above the carrier (8.5 mm socket +
9.5 mm module) against ~15 mm for the socketed Teensy beside it — a note for the
future enclosure, not a conflict: nothing else sits inside the U2 courtyard and the
nearest other pad is 10.4 mm away, so the extra height and the socket body are clear.

⚠️ **Orientation is now load-bearing.** The U2 footprint carries **no silkscreen
label at all** (verified: courtyard + fab lines only; pads are 1 rectangular + 11
round), and a socket accepts either orientation, so the module can be **inserted
the mirrored way round**. That puts the module's VIN where +5 V is and its VOUT
where 10–20 V is — immediate destruction. Three keys exist without touching the
board:

1. On the module the **four square plated holes are GND**; the **VOUT column is one
   column in** from them and the **EN/PG column is three columns** from them. True
   from either face, because they are the same physical holes.
2. **U2 pad 1 is the only rectangular pad** in the footprint (all others are round).
   It is VOUT, at the **north** end of the block (toward the terminal blocks) — the
   layout matches Pololu's *"top view with labels"* drawing (image 0J10742), so
   "VOUT at the north end" is the correct insertion.
3. **Continuity check before power:** inserted and unpowered, the four middle-row
   socket pads are GND and must read ~0 Ω to J1 pin 2 / the ground plane. In the
   mirrored orientation the module's VIN/VRP sit in those positions and the reading
   is not a solid short.

A **silk "VOUT / GND / VIN / VRP / EN·PG" label** and a pad-1 arrow next to the
block would remove the trap entirely. That is a **silkscreen-only** change (no
copper, no re-route, DRC unaffected) — but it does change the silkscreen Gerber, so
it needs a re-export before the PCB order is placed. Flagged, deliberately NOT done
in this revision.

---

## 5. Cost notes where the PCBWay quote is well above distributor pricing

| Line | Part | PCBWay unit | Distributor | Saving/board |
|---|---|---|---|---|
| 25 | Amphenol 901-143 | $39.32 | Digi-Key $26.31 (1) / $22.36 (10) | ~$13–17 |
| 2 | TRACO TSR 1-2433 | $9.48 | Newark $4.87, TME $5.35, Digi-Key $6.28 | ~$3.2–4.6 |
| 59 | Phoenix 1729034 | $3.64 | Digi-Key $1.94, Newark $2.69 | ~$1–1.7 |
| 20 | TDK ICM-42670-P | $3.56 | LCSC $2.28, Newark $2.42 | ~$1.1 |
| 14 | Keystone 1058 | $2.40 | Digi-Key $1.34, TME $1.19 | ~$1 |
| 63 | ESP32-S3-WROOM-1-N8R2 | $4.23 | LCSC $4.63 (comparable) | — |

Supplying the SMA jack, the two TRACO modules and the Keystone holder ourselves
saves roughly **$19–24 per board** before shipping, i.e. ~$100 on the 5-unit run.

---

## 6. The reply actually sent

**`PCBWAY-REPLY-2026-09-29.pdf`** (source: `PCBWAY-REPLY-2026-09-29.md`) — a
5-page letter answering every note in the quotation, plus
**`Racecar-RevD-BOM-pcbway-assembly-REV1.csv`** as the corrected BOM to re-match
from. Both are also copied to `~/Downloads/`. The letter's key asks:

1. approve C10/C18, counter-propose X7R `CC0805KKX7R9BB225` for C11;
2. use onsemi `SS14`, `PESD5V0F1BL,315`, `1206L010/60WR`;
3. **purchase and fit U2** (Digi-Key `2183-4091-ND` / Pololu 4091) — we pay part +
   sourcing fee, consignment only if they refuse;
4. **fit the two 1×24 sockets for U1**; we supply the Teensy (with pins) and plug it in;
5. do not fit the CR2032 cell, the JP1 shunt or the J9 lead;
6. confirm the `NEO-M9N-00B` price before production; genuine TRACO only.

---

## 7. Method and confidence

- **PCBWay notes** — read directly from the quotation `.xls` (converted with
  LibreOffice; single sheet, 68 line items).
- **LCSC stock/price** — JLCPCB's public component-search API
  (`jlcpcb.com/api/overseas-pcb-order/v1/shoppingCart/smtGood/selectSmtComponentList`),
  exact-MPN match, queried per BOM line. This is the same inventory PCBWay's
  turnkey flow draws on, so it is the relevant number for them.
- **US/EU distributor stock** — Findchips aggregation (Digi-Key, Newark, RS,
  Avnet, TME, Sager, Rochester, plus independents), exact-MPN match.
- **Datasheet facts** (Littelfuse ordering codes, Nexperia capacitance) — read
  from the manufacturer PDFs fetched from LCSC's document mirror, not from
  memory.
- **Vendor-direct** — pololu.com product page (rationed/backorder status),
  SparkFun/Adafruit listings, pjrc.com.

**Caveats.** Digi-Key and Mouser both block automated queries, so their numbers
come only via the Findchips feed — which returns **0** for some perfectly
ordinary parts (e.g. it reports Digi-Key 0 for `LM2903BIDR`,
`SN74LVC1G125DBVR`, `GRM21BR71H105KA12L`). Treat any single-source "0" as
*unverified, ask the distributor*, and treat "in stock with a price break" as
good. Every part above is backed by at least two independent sources except the
Teensy/Pololu consign items (vendor + Digi-Key) and the u-blox module (LCSC
only, which is exactly the price risk PCBWay flagged).

**U2 socket change (2026-09-30).** Swapping the fitted module for a fitted
**socket** changes no copper either: the 12 through-holes, their nets, the
footprint and the CPL are untouched, so the Gerbers and the PCBWay Gerber ZIP stay
valid and nothing needs re-exporting. Only the BOM Comment/part mapping and the
assembly documents changed. (Adding silkscreen labels to the U2 footprint — §4b —
*would* change a Gerber and is deliberately not done.)

**Nothing in this document changes the schematic, the PCB or the Gerbers.** The
two part changes (D5, F3–F5) and the three capacitor substitutions are
same-footprint substitutions. `1206L010/60WR` is a 1206 PPTC like the part it
replaces, and `PESD5V0F1BL` is SOD-882 like `PESD3V3U1UL`. What *has* changed in
the repo is the parts metadata (`components.json`, `design/BOM.csv`, the
`pcbway/*.csv` files, and the notes/rationale in `electrical/generate.py`), plus a
freshly re-exported fab ZIP carrying the corrected BOM.

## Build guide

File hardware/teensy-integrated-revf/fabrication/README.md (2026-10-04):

# Rev F Gerber/drill exporter

The real electrical PCB is `../design/racecar-integrated-revf.kicad_pcb`, with a
fully annotated schematic and assigned nets — distinct from the netless
`../../teensy-integrated-revc/preview/` illustration. Two intentionally different
modes exist:

```sh
# Explicit UNAPPROVED engineering-prototype files (no invented human review):
/usr/bin/python3 hardware/teensy-integrated-revd/fabrication/export.py --engineering-prototype

# Reviewed release; remains BLOCKED until a genuine independent review exists:
/usr/bin/python3 hardware/teensy-integrated-revd/fabrication/export.py
```

Engineering output is `Racecar-RevF-GERBERS-ENGINEERING-PROTOTYPE.zip`. Its
status/manifest explicitly say **no independent approval and no physical
validation**. It is not the reviewed-release `Racecar-RevF-GERBERS-PROTOTYPE.zip`.
Both modes fail closed on missing documents or actual CAD failures and remove their
own stale output before attempting export.

Common checks: genuine integrated components and routing; independent pin-contract
assertions; full-severity ERC/DRC with zero unconnected items; exact real schematic /
PCB connected-pad equality; all copper/mask/silk/paste/outline layers; separate
PTH/NPTH Excellon drills; current assembled-image identity when included; unchanged
source hashes; ZIP CRC and SHA256 manifest verification. Editable CAD, schematic
PDF, BOM/positions and the fabrication/assembly/bring-up documents travel in the ZIP.

Reviewed mode additionally requires `design-review.json`: revision D, a named actual
reviewer, `approved_for_prototype_fabrication:true`, every `REVIEWS` check genuinely
completed, and an exact `source_sha256` mapping for all design sources/documents
listed by `preflight()`. **Do not generate an approval to get past this gate.**

The engineering export path has been exercised on the routed Rev F; unit rejection
tests alone would not establish that. Independent CAM re-reading, footprint/power/RF
review and measured bring-up are separate requirements before an order or vehicle
use. Neither mode claims validated firmware or automotive ratings.

**Note:** the documents in the engineering ZIP (`FABRICATION.md`, `ASSEMBLY.md`,
`DESIGN_NOTES.md`, `BRINGUP.md`) describe **Rev F**. The file sent to the fabricator
is the gerber-only `../pcbway/Racecar-RevF-PCBWAY-GERBERS.zip`, which contains no
documents — order settings must be taken from `../pcbway/PCBWAY-ORDER-GUIDE.md`.

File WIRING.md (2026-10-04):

# racecar-35 — Wiring Reference

Wiring reference for the existing two-MCU system. **WiFi-only on the CrowPanel
since v0.1.148: no Ethernet module or Internet-route setting.**
The current **solder-it-yourself** build is a protoboard, not Rev C:
[hardware/breadboard/](hardware/breadboard/) (terminals on the LEFT edge,
Teensy on the right, Pi 5 video box on Serial1). Rev C Gerbers stay parked.
**For the wire-by-wire build sheet — power, hand-built PC817 tach opto, GPS, IMU,
CAN, the passive netlist and the pre-power meter checks — use
[hardware/breadboard/PINOUT.md](hardware/breadboard/PINOUT.md).** Sections 5/5b/5c
and 9 below still describe the circuits, but the pinout sheet is the authoritative
build order. v0.1.149 firmware supports ONLY an external AEM 30-0300 gauge's
WHITE/BROWN analogue output through a reviewed scaled/protected input. No direct
oxygen sensor, onboard heater/controller or source-selection jumper.
See [CLAUDE.md](CLAUDE.md) and
[AFR_INTERFACE.md](hardware/teensy-integrated-revc/AFR_INTERFACE.md).

**New Rev C reservations (NOT wired or driven by current firmware):** on-board
ESP32-S3 WiFi over SPI0 (10/11/12/13 + IRQ5/reset6) and CR2032 backup to dedicated
Teensy VBAT/GND. Screen WiFi/OTA stays. See
[WIFI_RTC_ARCHITECTURE.md](hardware/teensy-integrated-revc/WIFI_RTC_ARCHITECTURE.md).
Never attach a cell to a generic GPIO; add the missing auxiliary VBAT contact.

```
Cabin (driver)                         Trunk (data + connectivity)
+-------------------+                 +-----------------------------+
|  CrowPanel ESP32  | <==UART (3 wires) ==>  Teensy 4.1            |
|  (cabin display)  |                 |  GPS (NEO-M9N)              |
|                   |                 |  Tach input (opto)          |
|                   |                 |  IMU (MPU-6050)             |
|  WiFi / NTP      |                 |  No network hardware        |
|                   |                 |  SD card (built-in slot)    |
+-------------------+                 +-----------------------------+
```

---

## 1. Teensy 4.1 — full pin assignments

| Teensy 4.1 pin | Function | Notes |
|---:|---|---|
| **3.3V** | Legacy GPS/IMU and logic pull-ups | Respect the MCU current budget; proposed carrier has a separate auxiliary rail |
| **GND** | Common ground for everything | Multiple GND pins on the header — any will do |
| **VIN / 5V** | Power in (5 V, USB or ext) | Or use USB-C |
| **5V** | Output — feed downstream 5 V devices if needed | Same rail as VIN |
| Pin 0 | Serial1 RX1 — **from Pi 5 TX** | Video box UART, 3.3 V, 115200. See [hardware/breadboard](hardware/breadboard/) |
| Pin 1 | Serial1 TX1 — **to Pi 5 RX** | Crossed with pin 0; common GND; NEVER 5 V |
| Pins 5 / 6 | Proposed NET READY / reset | Reserved for new WiFi coprocessor; not implemented |
| Pin 7 | Serial2 RX2 — **GPS TX** | u-blox NEO-M9N TX → here |
| Pin 8 | Serial2 TX2 — **GPS RX** | Optional (config); often unused |
| Pin 9 | **Tach input via FreqMeasureMulti** | Conditioned opto output only; plain FreqMeasure uses pin 22 and is WRONG here |
| Pins 10–12 | Proposed NET CS / MOSI / MISO | Reserved for local WiFi SPI; not yet driven |
| Pin 13 | Current heartbeat / proposed SCK  | MUST disable heartbeat GPIO writes before SPI |
| Pin 14 | Serial3 TX3 — to CrowPanel `RX` | Dash telemetry out (921600 baud) |
| Pin 15 | Serial3 RX3 — from CrowPanel `TX` | Dash commands in (REC, TRACK, TZ, SDFORMAT) |
| Pin 16 / A2 | **Oil pressure ADC** | 0.5–4.5 V transducer via 10 kΩ / 20 kΩ divider |
| Pin 17 / A3 | **Coolant temp ADC** | NTC thermistor with 150 Ω pullup to 3.3 V |
| Pin 18 | Wire SDA — **IMU SDA** | I²C data |
| Pin 19 | Wire SCL — **IMU SCL** | I²C clock |
| Pin 20 / A6 | AEM 30-0300 gauge-output ADC | Opt-in `afraem`; requires protected 0.500 gain front end; NEVER raw 5 V |
| Pins 22 / 23 | CAN1 TX / RX | Used by MS3Pro; requires a CAN transceiver |
| (built-in SDIO)| **SD card slot** | Dedicated socket on the board, no header pins |

---

## 2. CrowPanel ESP32-S3 V3.0 — relevant pins

The CrowPanel uses most of its GPIOs internally for the LCD, touch, and
expander. The only thing **we** wire on the back-side header is UART0 to the
Teensy.

| CrowPanel pin | Function | Notes |
|---:|---|---|
| **3.3V / 5V** | Power in (USB-C or 5V pin) | Don't share with Teensy unless you tie the grounds first |
| **GND** | Must be **common with Teensy GND** | Critical — UART won't work without shared ground |
| GPIO 43 | UART0 TX → Teensy pin 15 (RX3) | Dash → trunk commands |
| GPIO 44 | UART0 RX ← Teensy pin 14 (TX3) | Trunk → dash telemetry |

> **Critical — UART0 is shared with USB upload.** Disconnect the two UART
> jumpers (43 / 44) before flashing the CrowPanel via `arduino-cli upload`.
> If the Teensy is driving GPIO 44 while esptool is trying to upload, the
> upload silently corrupts or fails with `The serial TX path seems to be down`.

---

## 3. UART telemetry link (Teensy ↔ CrowPanel)

Three wires total. **The TX/RX pair is crossed.**

On the prototype carrier / protoboard this lands on the screen's **J10** (XH2.54)
header, not bare GPIO pins:

| Teensy 4.1 | Direction | CrowPanel J10 |
|---:|:---:|:---|
| Pin 14 (TX3) | → | RXD0_H |
| Pin 15 (RX3) | ← | TXD0_H |
| GND | — | GND |

Baud: **921600** 8N1 (not 115200 — both sides must agree), line-oriented with `\n` terminators. Wire format is
documented in [CLAUDE.md](CLAUDE.md#wire-protocol-teensy--crowpanel-uart).

---

## 4. GPS — u-blox NEO-M9N (or any UBX-compatible u-blox)

4 wires.

| u-blox module pin | Teensy 4.1 pin | Notes |
|---:|:---|---|
| `VCC` (3V3) | **3.3V** | NEO-M9N is 3.3 V; SparkFun RTK boards have onboard regulator and accept 3.3–5 V |
| `GND` | **GND** | |
| `TX` | **Pin 7** (RX2) | Module sends UBX/NMEA *to* Teensy |
| `RX` | **Pin 8** (TX2) | Optional — only used if you want to send config to the module |

Bauds tried at boot: **230400** (persisted by `saveConfiguration()` on a module we
have already configured, and the target rate), **38400** (SparkFun RTK default),
then **9600** (bare module factory default). The firmware then raises the link to
230400 so 25 Hz UBX-NAV-PVT has headroom (38400 was ~65 % utilised → chronic STALE).
If none handshakes the lib goes "raw bytes" mode and just observes Serial2.

Antenna: external active GPS antenna recommended for moving vehicle. SMA
connector on most modules.

---

## 5. Tach input — opto-isolated pulse to pin 9

The Teensy measures pulse frequency on pin 9 via `FreqMeasure` (FlexPWM
input capture — pin 9 is the *only* pin this works on for T4.x).

### Recommended front-end

```
Engine tach signal (12 V noisy)         Teensy 4.1
┌──────────────────────────┐            ┌──────────┐
│  Coil-neg / ECU tach out │            │          │
│         ─o─              │            │          │
│          │               │            │   3.3V o─┴──┐
│  ┌───────┴──────┐        │            │          │  │
│  │  PC817 opto  │        │            │   Pin 9  │  │
│  │   1───┐ ┌──4 │────────┼────────────┤──────────│──┤  
│  │       │ │    │        │            │          │  R = 4.7 kΩ – 10 kΩ pull-up
│  │   2───┘ └──3 │────────┼────────────┤   GND    │  │  (3.3V → pin 9)
│  └──────────────┘        │            │          ├──┘
│  R_in: 1k from tach      │            └──────────┘
│       → opto pin 1       │
│  Pin 2 → engine GND      │
└──────────────────────────┘
```

| Component | Value | Notes |
|---|---|---|
| Optocoupler | PC817-class | Plenty of margin for ≤270 Hz (4-cyl × 2-pulse-per-rev @ 8k RPM) |
| `R_in` (input side) | 1 kΩ | Limits LED current at 12 V (~11 mA) |
| `R_pullup` (output) | **4.7 kΩ – 10 kΩ** | From 3.3 V to pin 9; required, opto output is open-collector |

Output is **inverted** (opto pulls pin 9 low when tach pulses), but
FreqMeasure counts edges either way — no software change needed.

`RPM_PULSES_PER_REV` in [src/main.cpp](src/main.cpp) defaults to **2.0**
(typical 4-cyl 4-stroke from coil-neg or ECU tach output). Calibrate against
a known idle RPM if it reads 2× / ½×.

---

## 5b. Oil pressure — generic 5 V 0.5–4.5 V transducer to pin 16 (A2)

3 wires from the transducer; **divider on the signal line is mandatory** (sensor is 5 V output, Teensy ADC is not 5 V tolerant).

```
Sensor 5V ──── Teensy 5V (or external clean 5V rail)
Sensor GND ─── Teensy GND (star point)
Sensor SIG ──┬─── R1 = 10 kΩ ──── Teensy pin 16 (A2)
             │                    │
             │                    R2 = 20 kΩ
             │                    │
             │                   GND
             └─── (optional 10 nF cap from A2 to GND, right at the pin)
```

Sensor output 0.5 V (0 PSI) → ADC 0.33 V; sensor 4.5 V (full scale) → ADC 3.00 V. Conversion math lives in `readOilPsiX10()` in [src/main.cpp](src/main.cpp); change `OIL_PSI_FULL_SCALE` if you swap to a 100 PSI or 200 PSI variant.

Wire colour check before trusting the listing photo: signal-to-GND should read **~0.5 V at atmosphere** when powered. If it reads ~0 V instead, you have a 0–5 V (not 0.5–4.5 V) variant — change `OIL_V_AT_ZERO_PSI` to 0.0f.

## 5c. Coolant temp — NTC thermistor (VDO 1600–22 Ω curve) to pin 17 (A3)

2-wire (with dedicated ground if the sender is single-terminal — do NOT rely on engine-block grounding through threads, the noise will trash readings).

```
                    Teensy 3.3V ─┬─── R_pullup = 150 Ω
                                 ├─── Teensy pin 17 (A3)
Sender signal ───────────────────┘
Sender body  ────── dedicated 18 AWG wire ──── Teensy GND (star)
```

Pullup is sized for ~22–700 Ω working range (full-scale span 100–250 °F). If using a different thermistor (GM-style ~3.3 kΩ at 100 °F, AEM 30-2014), bump the pullup to ~2.2 kΩ.

Calibration: the Steinhart-Hart `COOLANT_SH_A/B/C` constants in [src/main.cpp](src/main.cpp) are fitted to the typical VDO 1600–22 Ω curve. For your specific sender, measure R at three known temps (ice bath, room, boiling), feed into [the SRS NTC calculator](https://www.thinksrs.com/downloads/programs/therm%20calc/ntccalibrator/ntccalculator.html), and replace the coefficients.

## 6. IMU — MPU-6050 (GY-521 module)

4 wires. I²C address `0x68` (with AD0 tied low — most GY-521 boards have
this internally).

| GY-521 pin | Teensy 4.1 pin | Notes |
|---:|:---|---|
| `VCC` | **3.3V** | Module has onboard regulator and accepts 3.3 or 5 V; 3.3 V is safer |
| `GND` | **GND** | |
| `SCL` | **Pin 19** | Wire SCL |
| `SDA` | **Pin 18** | Wire SDA |
| `XDA`, `XCL`, `AD0`, `INT` | **leave floating** | Not used |

### Mounting orientation

For the dash to read forward/lateral G correctly, mount the GY-521 with:
- **board flat** (component side up)
- **header pins facing the rear** of the car

Then:
- **+X axis = forward** (longitudinal — braking/accel)
- **+Y axis = right** (lateral — right-hand turns read **negative** Ay)
- **+Z axis = up** (vertical — gravity ≈ −1.0 g on Az when level)

---

## 7. Networking — WiFi only (v0.1.148)

No Ethernet/W5500 module is used or probed. Set WiFi SSID/password on the
CrowPanel; those settings are always visible. Uploads and OTA use that WiFi link.
NTP runs on the screen and relays `SETTIME` over UART. Current source does NOT
set the RTC from GPS UTC (older documentation overstated that behaviour).
The WiFi/BLE arbiter still turns WiFi off while Bluetooth owns the radio.

Old saved `inet=0` selections are ignored. The new dash sends `CFG,inet,1` only
for compatibility with old Teensy firmware. Retired `ETH,` lines cannot overwrite
the screen's WiFi address/status.

---

## 7b. CAN transceiver — MS3Pro / bench (Teensy CAN1, pins 22 / 23)

The Teensy's `FlexCAN1` is on **pin 22 (CTX/TX) and pin 23 (CRX/RX)**. Wiring the module
to those pins is trivial; **powering it correctly is what has bitten us**, so read this
before wiring any plug-in board.

### The Amazon "SN65HVD230" modules are mislabelled

The "3-Pack SN65HVD230 CAN Transceiver Module" (ASIN B0FDLDXCK9) carries a SOIC-8 that
behaves as a **TJA1051T/3-class** part. Same footprint as an SN65HVD230, different pin
meanings. Bench-verified 2026-10-04 — see `hardware/CAN-TRANSCEIVER-FINDINGS-2026-10-04.md`.

| Module pin | If it were an SN65HVD230 | What the fitted chip needs |
| --- | --- | --- |
| 3 (VCC) | 3.3 V | **5 V** — below 4.5 V the transmitter is locked out |
| 5 | Vref — leave floating | **VIO = 3.3 V** — floating it phantom-feeds RXD from TXD (~2.1 V) |
| 8 | Rs | **S / standby → GND** — high means receive-only, no ACK |

**Correct bench wiring: `VCC = 5 V`, pin 5 = `3.3 V`, pin 8 = `GND`**, plus of course
`TXD → pin 22`, `RXD → pin 23`, `CANH`/`CANL` to the bus, common ground, 120 Ω at the
ends. Wrong wiring gives the exact "receives but never ACKs" symptom: ~3,800 identical
frames/s retransmitted. Correct wiring gives ~200 frames/s at a 100 Hz feed, both IDs,
0 errors.

⚠️ Never put **3.3 V on VCC**, and never put **5 V on pin 5**.

### On Rev F the transceiver is on the board

Rev F (and later) has a soldered **`U21` = TI `TCAN1042HGV-Q1`** — VCC = `+5V_MAIN`,
VIO = `+3V3_MCU`, STB tied to GND. There is no module to wire. Because `VIO` is the
Teensy's own 3.3 V rail, **CAN needs both `J1` (12 V, for the 5 V buck) and the Teensy
seated**; on Teensy-USB power alone VCC = 0 and CAN re-shows the same "no ACK" symptom.
That is not a fault. Acceptance tests: `hardware/teensy-integrated-revf/design/BRINGUP.md`.

---

## 8. SD card

The Teensy 4.1 has a **built-in SDIO socket** on the back of the board.
Insert a FAT32-formatted micro-SD card. No external wiring needed.

If the card has no filesystem, the dash settings page surfaces a
"Format SD card" action. The Teensy formats it in place via `FatFormatter`
on `SDFORMAT` command.

---

## 9. Power

| Source | Goes to |
|---|---|
| 12 V battery  | DC-DC step-down to 5 V (~2 A) |
| 5 V (regulated) | Teensy `VIN` (or USB-C if bench testing) |
| 5 V (regulated) | CrowPanel USB-C input (or 5 V pin) |
| Teensy `3.3V` | Legacy GPS, IMU and tach pull-up within the rail budget |
| **Common GND**| **All grounds tied together** — engine, Teensy, CrowPanel, every module |

> **Star-ground rule of thumb:** run separate ground wires from each module
> back to a single common point at the Teensy GND header. Don't daisy-chain
> grounds through the engine block; tach noise will couple into the GPS.

---

## 10. Quick wiring checklist

When rebuilding:

- [ ] 5 V supply common to Teensy + CrowPanel
- [ ] All grounds tied together at one star point
- [ ] UART crossover: T14↔C44, T15↔C43, plus shared GND (3 wires)
- [ ] GPS: 4 wires (VCC, GND, TX→T7, RX←T8)
- [ ] Tach: opto front-end + 4.7–10 kΩ pull-up from 3.3 V to T9
- [ ] Oil PSI: 5V, GND, signal via 10 kΩ/20 kΩ divider → T16 (A2)
- [ ] Coolant temp: 150 Ω pullup from 3.3 V → T17 (A3); dedicated body ground
- [ ] IMU: 4 wires (VCC, GND, SCL→T19, SDA→T18)
- [ ] WiFi SSID/password configured on the CrowPanel; no Ethernet module
- [ ] SD card inserted in Teensy 4.1 built-in socket
- [ ] **Disconnect the UART jumpers before flashing the CrowPanel**

---

## 11. COM port mapping (Windows dev machine)

| COM | Device | Used by |
|-----|---|---|
| COM3| CrowPanel CH340 USB-UART | `arduino-cli upload`, ESP32 monitor |
| COM4| Teensy native USB-CDC | PlatformIO upload + monitor |

Pinned in [platformio.ini](platformio.ini) (`monitor_port = COM4`) so the
PIO monitor can't grab the wrong port when both are plugged in.

---

## 12. Teensy 4.1 pinout — quick reference

Orientation: USB-C at the top, component side facing you, SD card slot at the
bottom (built-in SDIO socket on the back of the board). Pin numbers are the
GPIO numbers used in code (`pinMode(N, ...)`). Labels on the outside are the
peripheral alt-functions; `[bracketed]` callouts are the pins **this project
currently uses**.

```
                              +-------[USB-C]-------+
                         GND -|                     |- 5V (VIN)
     [Video Pi] RX1    0 -|                     |- GND
     [Video Pi] TX1    1 -|                     |- 3.3V
                           2 -|                     |- 23   A9          [CAN1 RX]
                           3 -|                     |- 22   A8          [CAN1 TX]
                           4 -|                     |- 21   A7 / RX5
                           5 -|                     |- 20   A6 / TX5    [AEM AFR via scaled/protected input]
                           6 -|                     |- 19   A5 / SCL    [IMU SCL]
       [GPS] RX2           7 -|                     |- 18   A4 / SDA    [IMU SDA]
       [GPS] TX2           8 -|     T E E N S Y     |- 17   A3 / TX4    [Coolant temp ADC]
     [Tach in]             9 -|        4 . 1        |- 16   A2 / RX4    [Oil PSI ADC]
                          10 -|                     |- 15   A1 / RX3    [Dash RX  <- CrowPanel TX]
                          11 -|                     |- 14   A0 / TX3    [Dash TX  -> CrowPanel RX]
                          12 -|                     |- 13   SCK / LED   [Heartbeat LED]
                        3.3V -|                     |- GND
                          24 -|                     |- 41   A17
      Serial6 TX          25 -|                     |- 40   A16
      Serial6 RX          26 -|                     |- 39   A15
                          27 -|                     |- 38   A14
      Serial7 RX          28 -|                     |- 37
      Serial7 TX          29 -|                     |- 36
                          30 -|                     |- 35
                          31 -|                     |- 34
                          32 -|                     |- 33
                              |                     |
                              |   +-------------+   |
                              |   |             |   |
                              |   |     S D     |   |
                              |   |   (SDIO,    |   |
                              |   |   built-in) |   |
                              |   +-------------+   |
                              +---------------------+
```

### What's free vs spoken for

| Status | Pins | Notes |
|---|---|---|
| **In use** | 7, 8, 9, 13, 14, 15, 16, 17, 18, 19, 22, 23, SDIO | CAN1 uses 22/23; network module removed |
| **Opt-in AFR** | 20 / A6 | AEM gauge output through reviewed 0.500 gain front end; no internal pull |
| **Reserved for new WiFi** | 5, 6, 10–13 | Local SPI/READY/reset proposal; no new driver yet |
| **No firmware assignment** | 0–4, 21, 24–41 | Review carrier/peripheral wiring before reuse |
| **Caveat** | Pins 16/17 used as analog (A2/A3) | Serial4 (RX4/TX4) is no longer available |
| **Caveat** | Pin 13 doubles as SPI0 SCK and the on-board LED | Stop heartbeat GPIO writes before enabling new WiFi SPI |
| **FreqMeasureMulti** | Pin 9 | The configured tach pin; plain FreqMeasure incorrectly uses CAN TX pin 22 |

### Common alt-functions for currently-unused pins

If you need to add something, these are the natural pin choices:

| Function | Best free pin | Alt |
|---|---|-----|
| Another UART | Serial6 (pins 24=TX, 25=RX) | Serial7 (28=RX, 29=TX) |
| Another I²C bus | Wire1 (SDA 17 / SCL 16) is already occupied by the ADC inputs | Wire2 (SDA 25 / SCL 24); verify any other allocations first |
| Another SPI bus | SPI1 (pins 26=MOSI1, 27=SCK1, 39=MISO1) | — |
| More ADC inputs | A7 (21) | A6 (20) reserved for AEM AFR; 22/23 already used by CAN1 |
| CAN bus | CAN1 (TX 22 / RX 23) is ALREADY IN USE | Verify PJRC pin mapping before assigning another controller |
| PWM output | Most pins support FlexPWM; 2, 3, 4, 33 are clean | See PJRC PWM table |

Full reference: [Teensy 4.1 pinout card](https://www.pjrc.com/store/teensy41.html).

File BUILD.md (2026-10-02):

# BUILD.md — full build requirements for racecar-35

This documents **everything** required to build all four release artifacts from a clean
machine, plus the exact commands that produce them. It is the operational companion to the
release contract in [CLAUDE.md](CLAUDE.md) ("STANDING ORDERS" / "OTA release").

There are **two independent toolchains** — they are NOT interchangeable (see CLAUDE.md):

| Artifact(s) | Toolchain | Source |
| --- | --- | --- |
| `teensy41-dash.hex` | **PlatformIO** (`platform = teensy`, `board = teensy41`) | `src/main.cpp`, `platformio.ini` |
| `crowpanel5adv-dash.bin`, `crowpanel7adv-dash.bin` | **arduino-cli** + `esp32:esp32@2.0.14` | `crowpanel-arduino/RaceDash/` |

> The two CrowPanel bins are one source (`RaceDash.ino`) built twice with a different
> `-DDASH_BOARD` (51 = 5" Advance, 71 = 7" Advance); both are `FlashSize=16M`.
>
> **RETIRED after v0.1.146: the Basic panels (`crowpanel7` / `crowpanel5`, 4M).** That
> hardware was scrapped. They are no longer built, published, or in the manifest, and
> `board_config.h` makes `-DDASH_BOARD=7|5` a hard `#error` (override with
> `-DDASH_ALLOW_RETIRED_BOARDS` only for archaeology).

---

## 0. Host prerequisites

- Linux x86-64 (this was built on one; macOS works with path changes).
- **`python3`** on `PATH`. Note: a stock python3 may ship **without `pip`/`ensurepip`** — the
  steps below bootstrap pip manually with `get-pip.py`, so that's fine.
- `curl`, `tar`, `unzip`, `git`, `sha256sum`, `stat`.
- Internet access to GitHub + PyPI + the Espressif package index on first setup.
- **~2–3 GB free disk** for the two toolchains + cores.

### ⚠️ Where to install the tools

On this machine `~/chrisrawlings/…` (the repo lives under
`~/chrisrawlings/Documents/vscode/racecar-35`) is **OneDrive-synced** — do NOT put toolchains,
caches, or venvs there (sync churn + huge upload). Install everything to a **non-synced**
location. This doc uses:

```
/home/chris/racecar-tools/          # all build tooling lives here (NOT synced)
  bin/arduino-cli                    # arduino-cli binary
  arduino-cli.yaml                   # config: data/downloads/user dirs -> adata/
  adata/                             # esp32 core + libraries (arduino-cli data dir)
  pylibs/                            # pyserial (pure-python) on PYTHONPATH for esptool
  pio-venv/                          # python venv holding PlatformIO
  pio-core/                          # PLATFORMIO_CORE_DIR (teensy platform + packages)
```

---

## 1. arduino-cli + ESP32 core (the three CrowPanel bins)

### 1a. Install arduino-cli
```bash
mkdir -p /home/chris/racecar-tools/bin && cd /home/chris/racecar-tools
curl -fsSL https://github.com/arduino/arduino-cli/releases/download/v1.0.4/arduino-cli_1.0.4_Linux_64bit.tar.gz -o acli.tgz
tar xzf acli.tgz -C bin arduino-cli
./bin/arduino-cli version   # -> 1.0.4
```

### 1b. Config file (keeps all data OFF the synced tree)
`/home/chris/racecar-tools/arduino-cli.yaml`:
```yaml
directories:
  data: /home/chris/racecar-tools/adata/data
  downloads: /home/chris/racecar-tools/adata/downloads
  user: /home/chris/racecar-tools/adata/user
board_manager:
  additional_urls:
    - https://raw.githubusercontent.com/espressif/arduino-esp32/gh-pages/package_esp32_index.json
```

### 1c. Install the ESP32 core — **pinned to 2.0.14** (newer boot-loops this board; see CLAUDE.md)
```bash
CLI="./bin/arduino-cli --config-file /home/chris/racecar-tools/arduino-cli.yaml"
$CLI core update-index
$CLI core install esp32:esp32@2.0.14
```

### 1d. Libraries
Two from the registry, one bundled in `_vendor/`:
```bash
LIBDIR=/home/chris/racecar-tools/adata/user/libraries
$CLI lib install "LovyanGFX"     # 1.2.24 verified
$CLI lib install "TAMC_GT911"    # 1.0.2 verified — GT911 touch on Wire (see CLAUDE.md)

# PCA9557 is NOT in the registry — copy it from the vendor course files + add library.properties
V=_vendor/CrowPanel-ESP32-Display-Course-File/CrowPanel_ESP32_Tutorial/File/PCA9557
mkdir -p "$LIBDIR/PCA9557"
cp "$V/PCA9557.cpp" "$V/PCA9557.h" "$LIBDIR/PCA9557/"
cat > "$LIBDIR/PCA9557/library.properties" <<'EOF'
name=PCA9557
version=1.0.0
author=Elecrow
maintainer=Elecrow
sentence=PCA9557 IO expander (bundled from CrowPanel vendor course files)
paragraph=
category=Device Control
url=
architectures=*
EOF
```
(paths above are relative to the repo root.)

### 1e. pyserial for esptool (the non-obvious gotcha)
The esp32 core's post-compile image step runs `esptool.py`, which `import serial`. A stock
python3 without pip can't provide it, so drop the **pure-python** pyserial wheel onto
`PYTHONPATH` and export it for every compile:
```bash
cd /home/chris/racecar-tools && mkdir -p pylibs
curl -fsSL https://files.pythonhosted.org/packages/07/bc/587a445451b253b285629263eb51c2d8e9bcea4fc97826266d186f96f558/pyserial-3.5-py2.py3-none-any.whl -o pyserial.whl
unzip -oq pyserial.whl -d pylibs
PYTHONPATH=/home/chris/racecar-tools/pylibs python3 -c "import serial; print(serial.__version__)"  # 3.5
```
Symptom if you skip this: build fails with `ModuleNotFoundError: No module named 'serial'` at
the "Creating esp32s3 image" step (compile itself is fine — it dies in the image tool).

### 1f. Build the three dash bins
```bash
cd <repo root>
export PYTHONPATH=/home/chris/racecar-tools/pylibs          # <-- required (1e)
CLI="/home/chris/racecar-tools/bin/arduino-cli --config-file /home/chris/racecar-tools/arduino-cli.yaml"
base="esp32:esp32:esp32s3:USBMode=default,CDCOnBoot=default,MSCOnBoot=default,DFUOnBoot=default,UploadMode=default,CPUFreq=240,FlashMode=qio,PartitionScheme=default,DebugLevel=none,PSRAM=opi,LoopCore=1,EventsCore=1,EraseFlash=none"
# NimBLE size trim (v0.1.109): we are BLE central+observer only — compiling out the
# peripheral/broadcaster roles + single connection saves ~15.5 KB of the 1.31 MB OTA slot.
# Must go to BOTH c and cpp flags (the NimBLE host core is C).
trim="-DCONFIG_BT_NIMBLE_ROLE_PERIPHERAL_DISABLED -DCONFIG_BT_NIMBLE_ROLE_BROADCASTER_DISABLED -DCONFIG_BT_NIMBLE_MAX_CONNECTIONS=1"

# (7"/5" Basic builds REMOVED — retired hardware, see the note at the top.)
# 5" Advance (crowpanel5adv), 16M
# v0.1.152: upload.maximum_size MUST match the 6 MB app slot from the sketch-local
# partitions.csv, or the compile-time percentage is a lie (it would say 96 % not 20 %).
$CLI compile --fqbn "${base},FlashSize=16M" --build-property "compiler.cpp.extra_flags=-DDASH_BOARD=51 $trim" --build-property "compiler.c.extra_flags=$trim" --build-property "upload.maximum_size=6291456" --build-path /tmp/rdadv_build --output-dir /tmp/rdadv_out crowpanel-arduino/RaceDash
# 7" Advance (crowpanel7adv), 16M  (v0.1.145+; same electrical config as the 5" Advance)
$CLI compile --fqbn "${base},FlashSize=16M" --build-property "compiler.cpp.extra_flags=-DDASH_BOARD=71 $trim" --build-property "compiler.c.extra_flags=$trim" --build-property "upload.maximum_size=6291456" --build-path /tmp/rd7adv_build --output-dir /tmp/rd7adv_out crowpanel-arduino/RaceDash
```
**A fresh `--build-path` compiles the whole ESP32 core (~10+ min).** Run first-time builds
of a new variant in the background (`nohup … &`) or they'll blow past an agent's command
timeout; subsequent builds in the same path take under a minute.
Rules (from CLAUDE.md): use `compiler.cpp.extra_flags` (NOT `build.extra_flags`, which carries
the required USB-mode flags), and a **distinct `--build-path` per board** so the `-DDASH_BOARD`
define can't cross-contaminate the cache. The APP binary is `RaceDash.ino.bin` in each
`--output-dir`.

**Flash-size ceiling (v0.1.152).** `crowpanel-arduino/RaceDash/partitions.csv` is picked up
automatically by arduino-esp32's prebuild hook (a **sketch-local** `partitions.csv` wins over
the platform tables), giving **two 6 MB A/B OTA slots** (`app0` 0x10000, `app1` 0x610000) plus
a 3 MB reserved data partition, with `nvs`/`otadata` left at their stock offsets so deployed
units keep their settings. That is why the builds above pass
`--build-property "upload.maximum_size=6291456"`: it makes the compiler's size report truthful
(`20 %` instead of `96 %`). **The partition table can only be written by a USB flash** — OTA
writes the app slot only — so **every unit needs one bench flash** to adopt the 6 MB layout;
until then its OTA is capped by its own table and an oversized image fails cleanly inside
`Update.begin()` (no brick). Verify a unit with `esptool read_flash 0x8000 0x600`.

---

## 2. PlatformIO (the Teensy hex)

### 2a. Bootstrap pip into a venv, then install PlatformIO
Stock python3 here has no `ensurepip`, so create the venv `--without-pip` and bootstrap:
```bash
cd /home/chris/racecar-tools
python3 -m venv --without-pip pio-venv
curl -fsSL https://bootstrap.pypa.io/get-pip.py -o get-pip.py
./pio-venv/bin/python get-pip.py
./pio-venv/bin/pip install platformio        # 6.1.19 verified
./pio-venv/bin/pio --version
```

### 2b. Build (core dir kept off the synced tree)
```bash
cd <repo root>
export PLATFORMIO_CORE_DIR=/home/chris/racecar-tools/pio-core
/home/chris/racecar-tools/pio-venv/bin/pio run     # -> .pio/build/teensy41/firmware.hex
```
First run downloads the `teensy` platform + toolchain into `pio-core/`. `platformio.ini` pins
`monitor_port = COM4` (Windows) — harmless on Linux; monitor via `-t monitor` with the right
`/dev/tty*` if needed. Do **not** add a CrowPanel env to `platformio.ini` (PIO boot-loops that
board — see CLAUDE.md).

---

## 3. Assemble the release (the four artifacts + manifest)

```bash
cd <repo root>
cp .pio/build/teensy41/firmware.hex firmware/teensy41-dash.hex
cp /tmp/rdadv_out/RaceDash.ino.bin  firmware/crowpanel5adv-dash.bin
cp /tmp/rd7adv_out/RaceDash.ino.bin firmware/crowpanel7adv-dash.bin

sha256sum firmware/teensy41-dash.hex firmware/crowpanel5adv-dash.bin firmware/crowpanel7adv-dash.bin
stat -c'%n %s' firmware/teensy41-dash.hex firmware/crowpanel5adv-dash.bin firmware/crowpanel7adv-dash.bin
```
Then hand-edit `firmware/manifest.json`: set **every** `version` to the new number, paste the
recomputed `sha256` + `size` into each entry, keep each `board` field. (The legacy `crowpanel`
alias and the Basic entries are gone since 0.1.146.) A stale sha aborts OTA on the device.

**Version bump (do FIRST, before building):** both defines must match:
```bash
NEW=0.1.69
sed -i "s/#define FIRMWARE_VERSION .*/#define FIRMWARE_VERSION \"$NEW\"/" src/main.cpp
sed -i "s/#define FIRMWARE_VERSION .*/#define FIRMWARE_VERSION \"$NEW\"/" crowpanel-arduino/RaceDash/RaceDash.ino
```

---

## 4. Flashing (optional — OTA is the normal path)

- **CrowPanel over USB**: disconnect the Teensy↔CrowPanel UART jumpers first (shared with the
  CH340). ALWAYS `esptool flash_id` first: **16M = an Advance** (the only live panels); a 4M
  reading is a retired Basic — do NOT flash it. Flash-size can't tell the 5" Advance from the
  7" Advance (both 16M) — go by the glass in front of you, then read the boot banner @ 921600 to
  confirm the `crowpanel-…-adv` board id + version. See CLAUDE.md "ALWAYS verify which board".
- **Teensy over USB**: `pio run -t upload` (HalfKay; press the button if "Error opening USB
  device").
- **OTA**: bump + rebuild all four + publish `manifest.json` (below); devices self-update.

---

## 5. Publish

```bash
git add src/main.cpp crowpanel-arduino/RaceDash/RaceDash.ino crowpanel-arduino/RaceDash/board_config.h firmware/ BUILD.md CLAUDE.md
git commit -m "Release vX.Y.Z: <what changed>"
git push origin main
curl -s https://raw.githubusercontent.com/teknoprep/racecar-35/main/firmware/manifest.json   # verify
```
Auth: the remote is HTTPS token auth (`https://github.com/teknoprep/racecar-35.git`). On the
original build host `$HOME` was unset, so git ops needed a `HOME=/root` prefix (store helper) or
an explicit token URL. On this host `$HOME=/home/chris`; use whatever supplies the token.

---

## Publishing OTA to the server (racecar.api.blueuc.com) — the normal path (v0.1.74+)

Since **v0.1.73** the dash checks our OWN server for updates, not GitHub. This means a future
agent can ship an OTA **entirely from this build host with no laptop** — build the four
artifacts, then push straight to the server, which serves them `no-store` (instantly fresh, no
CDN lag). See [server/README.md](server/README.md) for the endpoint reference.

### The firmware-upload API key (already provisioned)
- **Value** lives OFF the repo at **`/home/chris/racecar-tools/secrets/racecar_api_key.env`**
  (mode 600, outside the git tree — never committed). Read it with `grep RACECAR_API_KEY <file>`
  or `grep -oE '[0-9a-f]{64}' <file>`.
- The SAME value is set on the server as env **`RACECAR_FIRMWARE_KEY`** (gates `POST
  /firmware/upload`). It is DELIBERATELY separate from `RACECAR_API_KEY` (session-upload auth) —
  reusing one key for both previously 401'd every dash session upload mid-stream.
- The server is reachable over public HTTPS from this host; no SSH needed to publish.

### Publish command (after building all four — sections 1–2 above put them in `firmware/`)
```bash
export RACECAR_API_KEY=$(grep -oE '[0-9a-f]{64}' /home/chris/racecar-tools/secrets/racecar_api_key.env)
./server/publish_firmware.sh 0.1.NN https://racecar.api.blueuc.com
```
`publish_firmware.sh` uploads the THREE binaries (teensy, crowpanel5adv, crowpanel7adv) then a
server-pointed manifest (artifact URLs = `<base>/firmware/<file>`, every `version`=the arg) and
prints the live manifest to verify. The script sends `X-API-Key: $RACECAR_API_KEY` — that env
var is the FIRMWARE key here, matching the server's `RACECAR_FIRMWARE_KEY` (naming is a bit
confusing: the script variable is `RACECAR_API_KEY` but it must hold the firmware key).

### Verify a server release
```bash
curl -s https://racecar.api.blueuc.com/firmware/manifest.json | grep -E '"version"|"url"'
curl -s https://racecar.api.blueuc.com/firmware/list                 # name+size+sha256 of all
# hash-check one artifact against the manifest:
curl -s https://racecar.api.blueuc.com/firmware/crowpanel5adv-dash.bin | sha256sum
```

### GitHub is now only the transition channel (frozen at 0.1.73)
GitHub `firmware/manifest.json` stays at **0.1.73** (the build whose `OTA_MANIFEST_URL` is the
server) so any panel still on ≤0.1.72 can OTA that far from GitHub and then hop to the server.
**0.1.74+ ship server-only** via the script above; do NOT add them to the GitHub manifest, and
keep the committed GitHub `firmware/` binaries at the 0.1.73 build (see the racy-index note
below). You still commit the SOURCE (both `FIRMWARE_VERSION` defines + `RaceDash.ino`) to GitHub
for provenance on every release.

### ⚠ Networked-FS racy git index (bites every release)
This working tree is on a filesystem whose stat-cache confuses git: an artifact that changed but
kept the **same byte length** (the teensy `.hex` is always 610714 B; the manifest is a fixed
size) gets treated as “clean” and silently NOT committed. Symptoms: `git show HEAD:firmware/x`
differs from the working file while `git status` says clean. **Always** stage firmware/manifest
changes with an index eviction:
```bash
git rm --cached firmware/teensy41-dash.hex firmware/manifest.json ... 2>/dev/null; git add firmware/ ...
git cat-file -p :firmware/manifest.json | grep -m1 version   # CONFIRM the staged blob is right
```
And for GitHub releases, pin the manifest's artifact URLs to the commit SHA (immutable path →
GitHub CDN can never serve a stale bin): commit artifacts first, `X=$(git rev-parse HEAD)`,
`sed -i "s#/main/firmware#/$X/firmware#g" firmware/manifest.json`, evict+add+commit+push.

## Verified versions (this build, 2026-07-01)

| Tool / lib | Version |
| --- | --- |
| arduino-cli | 1.0.4 |
| esp32:esp32 core | 2.0.14 (pinned) |
| LovyanGFX | 1.2.24 |
| TAMC_GT911 | 1.0.2 |
| PCA9557 | bundled (`_vendor/…/File/PCA9557`) |
| pyserial (for esptool) | 3.5 |
| PlatformIO Core | 6.1.19 |
| teensy platform | installed on first `pio run` |

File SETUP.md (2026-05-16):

# racecar-35 — Dev Environment Setup

This document is written for an AI coding agent (Claude Code, Cursor, etc.) to drive a clean install of the toolchains needed to build and flash this repo on a fresh machine. Both **Windows** and **Linux** are supported. macOS is not covered but mostly mirrors Linux.

The repo has **two MCUs with two separate toolchains**, both of which must be installed:

| Target | MCU | Toolchain | Source location |
| --- | --- | --- | --- |
| Trunk | Teensy 4.1 | **PlatformIO** | [src/main.cpp](src/main.cpp) |
| Cabin dash | CrowPanel ESP32-S3 V3.0 | **arduino-cli** + `esp32:esp32@2.0.14` | [crowpanel-arduino/RaceDash/RaceDash.ino](crowpanel-arduino/RaceDash/RaceDash.ino) |

⚠️ **Do not try to build the CrowPanel sketch with PlatformIO.** PIO's `espressif32@^6.7.0` bootloader boot-loops on the V3.0 board. Use arduino-cli only. See [CLAUDE.md](CLAUDE.md) for the full reasoning.

---

## 0. Prerequisites (both OSes)

- **Git**
  - Windows: `winget install Git.Git` (or [git-scm.com](https://git-scm.com/))
  - Linux (Debian/Ubuntu): `sudo apt install git`
  - Linux (Fedora/RHEL): `sudo dnf install git`
- **Python ≥ 3.9** (for PlatformIO)
  - Windows: `winget install Python.Python.3.12`
  - Linux: usually preinstalled; otherwise `sudo apt install python3 python3-pip python3-venv`
- **A USB cable for each board** (CrowPanel uses CH340 over USB-C; Teensy uses USB micro-B native CDC)

Clone the repo:

```bash
git clone <repo-url> racecar-35
cd racecar-35
```

---

## 1. Install PlatformIO (for Teensy 4.1)

PlatformIO is OS-portable. Either the VS Code extension or the CLI works; the CLI is what the build/flash commands assume.

### Windows
```powershell
python -m pip install --user platformio
```
PIO ends up at `%USERPROFILE%\.platformio\penv\Scripts\platformio.exe`. The commands in [CLAUDE.md](CLAUDE.md) use this absolute path.

### Linux
```bash
python3 -m pip install --user platformio
# Add to PATH if not already:
echo 'export PATH="$HOME/.local/bin:$PATH"' >> ~/.bashrc
source ~/.bashrc
```
PIO ends up on PATH as `pio` / `platformio`.

### Teensy-specific extras (Linux only)
Linux needs a udev rule so non-root users can flash the Teensy:
```bash
sudo wget -O /etc/udev/rules.d/00-teensy.rules https://www.pjrc.com/teensy/00-teensy.rules
sudo udevadm control --reload-rules
sudo udevadm trigger
```
Also add your user to `dialout` (covers serial AND Teensy programming port):
```bash
sudo usermod -aG dialout $USER
# log out and back in for this to take effect
```

### Verify
```bash
# Windows
& "$env:USERPROFILE\.platformio\penv\Scripts\platformio.exe" --version
# Linux
pio --version
```
First-time `pio run` will auto-download the Teensy GCC toolchain and required libraries (~5 min, one-time).

---

## 2. Install arduino-cli (for CrowPanel ESP32-S3)

### Windows
The Arduino IDE 2.x installer ships `arduino-cli.exe` inside its install dir:
```
C:\Users\<you>\AppData\Local\Programs\Arduino IDE\resources\app\lib\backend\resources\arduino-cli.exe
```
Either install Arduino IDE 2.x (`winget install ArduinoSA.IDE.unstable`) and use that path, **or** download the standalone CLI:
```powershell
# Standalone (recommended for headless / scripted use)
Invoke-WebRequest -Uri "https://downloads.arduino.cc/arduino-cli/arduino-cli_latest_Windows_64bit.zip" -OutFile arduino-cli.zip
Expand-Archive arduino-cli.zip -DestinationPath "$env:USERPROFILE\arduino-cli"
# Add $env:USERPROFILE\arduino-cli to PATH
```

### Linux
```bash
curl -fsSL https://raw.githubusercontent.com/arduino/arduino-cli/master/install.sh | BINDIR=$HOME/.local/bin sh
```
(Or use a distro package if one is current — most are stale.)

### Configure arduino-cli
```bash
# Create the config file if it doesn't exist
arduino-cli config init

# Add the ESP32 board package URL
arduino-cli config add board_manager.additional_urls https://raw.githubusercontent.com/espressif/arduino-esp32/gh-pages/package_esp32_index.json

# Update the index
arduino-cli core update-index

# Install the EXACT version. 2.0.14 is required — newer versions have not been validated against the V3.0 board's PCA9557 / GT911 init sequence.
arduino-cli core install esp32:esp32@2.0.14
```

### Point arduino-cli at this project's libraries directory
The CrowPanel build depends on a bundled **PCA9557 library** that is not in the Arduino registry. It lives at [_vendor/CrowPanel-ESP32-Display-Course-File/CrowPanel_ESP32_Tutorial/Code/7.0 v3.0 touch new code/File/PCA9557/](_vendor/CrowPanel-ESP32-Display-Course-File/CrowPanel_ESP32_Tutorial/Code/7.0%20v3.0%20touch%20new%20code/File/PCA9557/).

Find your `directories.user` path:
```bash
arduino-cli config dump | grep -i user
```
Default locations:
- **Windows:** `C:\Users\<you>\Documents\Arduino\` (or wherever your Documents folder redirects — on this dev machine it's OneDrive: `C:\Users\<you>\OneDrive - <Org>\Documents\Arduino\`)
- **Linux:** `~/Arduino/`

Copy the bundled PCA9557 library into `<directories.user>/libraries/PCA9557/`:

**Windows (PowerShell):**
```powershell
$src = ".\_vendor\CrowPanel-ESP32-Display-Course-File\CrowPanel_ESP32_Tutorial\Code\7.0 v3.0 touch new code\File\PCA9557"
$dst = (arduino-cli config dump | Select-String 'user:').ToString().Split(':',2)[1].Trim() + "\libraries\PCA9557"
New-Item -ItemType Directory -Force -Path $dst | Out-Null
Copy-Item "$src\*" $dst -Recurse -Force
```

**Linux:**
```bash
src="./_vendor/CrowPanel-ESP32-Display-Course-File/CrowPanel_ESP32_Tutorial/Code/7.0 v3.0 touch new code/File/PCA9557"
dst="$HOME/Arduino/libraries/PCA9557"
mkdir -p "$dst"
cp -r "$src"/* "$dst"/
```

The PCA9557 directory must contain a `library.properties` file. If it's missing, see [CLAUDE.md](CLAUDE.md) — the agent should hand-write one.

### Other libraries the CrowPanel sketch uses
TFT_eSPI, LovyanGFX, etc. are pulled in as needed. Install via:
```bash
arduino-cli lib install "TFT_eSPI"
```
Re-run `arduino-cli compile` (below) and install whatever it complains about until it links cleanly.

---

## 3. Identify serial ports

Both boards must be plugged in to flash, but **NOT at the same time during a CrowPanel flash** (see warning below).

### Windows
```powershell
[System.IO.Ports.SerialPort]::GetPortNames()
# Or check Device Manager → Ports (COM & LPT)
```
- **CrowPanel** enumerates as a `USB-SERIAL CH340` device → typically `COM3`
- **Teensy 4.1** enumerates as `USB Serial Device` (native CDC) → typically `COM4`

### Linux
```bash
# Plug in one board at a time and watch:
dmesg -w
# Or list current:
ls /dev/serial/by-id/
```
- **CrowPanel** → `/dev/ttyUSB0` (CH340, kernel built-in)
- **Teensy 4.1** → `/dev/ttyACM0` (native CDC)

Update [platformio.ini](platformio.ini) `monitor_port =` to match the Teensy's port if it differs from `COM4`.

---

## 4. Build & flash

### Teensy (both OSes — the only difference is the `pio` binary path)

**Windows:**
```powershell
& "$env:USERPROFILE\.platformio\penv\Scripts\platformio.exe" run -t upload
& "$env:USERPROFILE\.platformio\penv\Scripts\platformio.exe" device monitor
```

**Linux:**
```bash
pio run -t upload
pio device monitor
```

The Teensy upload uses the GUI loader (`teensy-gui`) which pops a window asking you to press the reset button if it's not already in HID-bootloader mode.

### CrowPanel — ⚠️ READ THIS BEFORE FLASHING

**Disconnect the Teensy↔CrowPanel UART jumpers (GPIO 43/44) before flashing the CrowPanel.** UART0 is shared with the CH340 used for upload; Teensy contention silently corrupts the flash, or you get `The serial TX path seems to be down` from esptool.

The exact FQBN is mandatory — every option matters:
```
esp32:esp32:esp32s3:USBMode=default,CDCOnBoot=default,MSCOnBoot=default,DFUOnBoot=default,UploadMode=default,CPUFreq=240,FlashMode=qio,FlashSize=4M,PartitionScheme=default,DebugLevel=none,PSRAM=opi,LoopCore=1,EventsCore=1,EraseFlash=none
```

**Windows:**
```powershell
$cli = "C:\Users\ChrisRawlings\AppData\Local\Programs\Arduino IDE\resources\app\lib\backend\resources\arduino-cli.exe"
# Or if installed standalone:
# $cli = "arduino-cli"
$fqbn = "esp32:esp32:esp32s3:USBMode=default,CDCOnBoot=default,MSCOnBoot=default,DFUOnBoot=default,UploadMode=default,CPUFreq=240,FlashMode=qio,FlashSize=4M,PartitionScheme=default,DebugLevel=none,PSRAM=opi,LoopCore=1,EventsCore=1,EraseFlash=none"
$sketch = ".\crowpanel-arduino\RaceDash"
& $cli compile --fqbn $fqbn $sketch
& $cli upload  --fqbn $fqbn -p COM3 $sketch
```

**Linux:**
```bash
fqbn="esp32:esp32:esp32s3:USBMode=default,CDCOnBoot=default,MSCOnBoot=default,DFUOnBoot=default,UploadMode=default,CPUFreq=240,FlashMode=qio,FlashSize=4M,PartitionScheme=default,DebugLevel=none,PSRAM=opi,LoopCore=1,EventsCore=1,EraseFlash=none"
sketch="./crowpanel-arduino/RaceDash"
arduino-cli compile --fqbn "$fqbn" "$sketch"
arduino-cli upload  --fqbn "$fqbn" -p /dev/ttyUSB0 "$sketch"
```

To watch the CrowPanel serial output after flash:
```bash
# Windows
& "$env:USERPROFILE\.platformio\penv\Scripts\platformio.exe" device monitor --port COM3 --baud 115200
# Linux
pio device monitor --port /dev/ttyUSB0 --baud 115200
# Or any terminal: minicom, screen, picocom, etc.
```

---

## 5. Smoke tests

After both boards are flashed:

1. **Teensy alone** — open serial monitor at 115200, you should see `GPS,...` lines (even with `gps_status=0` if antenna unplugged) and a 1 Hz heartbeat.
2. **CrowPanel alone** — display should boot to the dash page, show `RPM 0`, `0.0 mph`, `FIX 0`, `SATS 0`. Touch START → track picker should open.
3. **Both connected via UART jumpers** (only after each is verified solo) — dash should start showing real GPS/RPM values from the Teensy. Tapping START on the dash should make the Teensy serial monitor print `[dash] REC=1 ...`.

---

## 6. Common install-time problems

| Symptom | Cause | Fix |
| --- | --- | --- |
| `arduino-cli: command not found` after install on Linux | `$HOME/.local/bin` not on PATH | `export PATH="$HOME/.local/bin:$PATH"` in `~/.bashrc` |
| `Permission denied` opening `/dev/ttyUSB0` on Linux | User not in `dialout` group | `sudo usermod -aG dialout $USER` + relogin |
| Teensy upload hangs | Teensy not in bootloader mode | Press the white button on top of the Teensy |
| CrowPanel upload: `The serial TX path seems to be down` | UART jumpers to Teensy still connected | Unplug jumpers, retry |
| CrowPanel boots but display is black | Stale arduino-esp32 version installed | Verify `arduino-cli core list` shows `esp32:esp32 2.0.14` exactly — `arduino-cli core install esp32:esp32@2.0.14` if not |
| `PCA9557.h: No such file or directory` | Bundled library not copied to user libs dir | Re-run section 2's PCA9557 copy step; verify path with `arduino-cli config dump \| grep user` |
| PIO compile fails on Linux with `libudev not found` | Missing build dep | `sudo apt install libudev-dev` |

---

## 7. Things to NOT do (project-specific footguns)

These are documented in [CLAUDE.md](CLAUDE.md) but worth surfacing to anyone setting up fresh:

- **Don't create a PlatformIO env for the CrowPanel.** The PIO bootloader boot-loops the V3.0 board. arduino-cli only.
- **Don't flash the CrowPanel with the Teensy↔CrowPanel UART wires connected.** Disconnect, flash, reconnect.
- **Don't install `esp32:esp32` at a version other than `2.0.14`** without testing the full PCA9557 + GT911 + 15 MHz pclk init sequence end-to-end.
- **Don't edit code under [crowpanel-baseline/](crowpanel-baseline/) or [crowpanel-ui/](crowpanel-ui/)** — those are dead PIO experiments kept for reference only. Live CrowPanel code is [crowpanel-arduino/RaceDash/RaceDash.ino](crowpanel-arduino/RaceDash/RaceDash.ino).

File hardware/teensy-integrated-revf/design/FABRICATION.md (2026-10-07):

# Rev F — ENGINEERING-PROTOTYPE fabrication specification

**UNBUILT, UNAPPROVED, NOT INDEPENDENTLY REVIEWED.** This is a first-build
electrical prototype, not an automotive-qualified product. It passes CAD checks
(ERC/DRC zero, exact schematic/netlist pad equality) but has had no independent
review, no fabricator DFM sign-off and no physical validation. Do not order
production quantities and do not put it in a vehicle before the `BRINGUP.md`
sequence. A clean CAD report is not proof that an unbuilt board works.

## Board and process

- **Envelope 150 × 155 mm** (Edge.Cuts 150.05 × 155.05 with the 0.05 mm outline
  stroke). Use the supplied Edge.Cuts, including the **48 × 6 mm internal-WiFi
  antenna notch** cut into the bottom edge at x = 44…92. Never manufacture the
  netless illustration under `../teensy-integrated-revc/preview/`.
- **Four copper layers**, 1.60 mm finished FR-4, Tg ≥ 150 °C, **ENIG**, green mask,
  white legend, lead-free process compatible with the supplied modules.
  - `F.Cu` — signals + GND pour
  - `In1.Cu` — **continuous GND reference plane, no routing** (declared to the
    router as a plane layer so signals cannot consume it)
  - `In2.Cu` — signals
  - `B.Cu` — signals + GND pour
- **1 oz / 35 µm outer copper.** That is adequate because the screen branch is fused
  at **3 A** (`F2`, Littelfuse `0451003.MRL`) and the `+5V_MAIN` trunk is 3.5 mm
  wide. Do **not** raise the screen fuse back to 4 A on this build, and do not
  silently substitute a thinner outer copper weight. Inner layers use the
  fabricator's standard 4-layer construction.
- Design rules actually used: **0.20 mm minimum track width and 0.15 mm minimum
  clearance** (CAD rule floor 0.15 mm), 0.30 mm copper-to-edge, 0.30 mm minimum
  hole, 0.25 mm hole-to-hole and hole-to-copper, **0.60 mm via land / 0.30 mm via
  drill** (0.15 mm annular ring), vias **tented** on both sides.
- Separate metric Excellon **PTH and NPTH** files. Four **3.2 mm NPTH** mounting
  holes. The ESP32 ground-pad vias are 0.30 mm drills / 0.60 mm lands — not laser
  microvias. Do not plug/change land connectivity.
- Main 5 V / screen and return trunks are deliberately wide (up to 3.5 mm); local
  regulator pad fanouts are narrower parallel branches. **Do not let CAM thin these
  into signal tracks.** 5 A is a TOTAL supply design target, not a tested continuous
  rating.
- Four 3.2 mm NPTH mounting holes; insulated standoffs, clearance below soldered
  leads. Do not clamp a metal enclosure against traces, the cell holder or headers.
- Inspect all mask slivers, annular rings, plane necks, module lands, drill
  alignment, outline and silkscreen in the CAM viewer before ordering.

## Impedance control — the GNSS feed

Order with **impedance control ON** and state the target: **50 Ω single-ended on
`RF_ANT` / `RF_GNSS`, from J8 to the NEO-M9N `RF_IN`.**

The trace is **0.38 mm wide microstrip over `In1.Cu`**. With the standard 4-layer
1.6 mm construction (one 7628 prepreg each side of a 1.065 mm core → prepreg
H = 0.1955 mm, εr 4.2–4.6) that gives **49.6–50.6 Ω**. An `F.Cu` ground pour runs
alongside it at 0.15 mm, which makes the real impedance partly coplanar and pulls it
slightly below 50 Ω.

**Ask for the finished stackup first.** If the L1→L2 dielectric is not ≈0.1955 mm
the width must change: 0.10 mm → 0.19 mm, 0.15 mm → 0.29 mm, 0.20 mm → 0.38 mm,
0.25 mm → 0.48 mm, 0.36 mm → 0.69 mm (50 Ω at εr 4.4). This is a starting geometry,
not an impedance certificate; coupon/VNA measurement remains outstanding.

## RF / enclosure requirements

- WiFi is **ESP32-S3-WROOM-1-N8R2 with its built-in PCB antenna**. Its stock
  all-layer antenna keepout is retained and the carrier is notched away beneath the
  antenna tip. **No copper, vias, traces, screws, battery, cable or metal enclosure
  may intrude into the antenna region.** Use a plastic enclosure or an
  RF-transparent window; a closed metal trunk/enclosure can still block the signal.
- The **SMA is GPS only**, Amphenol **901-143-6RFX** (the brass-body variant of the 901-143: same
  PCB hole pattern and same SMA interface at ~1/3 the price; its body is ~0.65 mm longer). Inspect its
  mechanical drawing against
  the actual board edge, solder tails and enclosure hole before assembly.
- Active GPS antenna: **3.3 V bias**, current limited by a TPS2553 whose ILIM is tied
  to IN → datasheet-limited to **50 / 75 / 100 mA** (min/typ/max). Specify an antenna
  whose draw works at the minimum limit. The external gauge, display and WiFi antenna
  are **not** powered through this SMA.

## Before an order

Obtain independent schematic/footprint/power-off review and fabricator DFM feedback.
Check availability of genuine **ICM-42670-P** (its land pattern is derived from
DS-000451, not vendor-published), **NEO-M9N-00B**, **ESP32-S3-WROOM-1-N8R2**,
**TI TPS54560BDDAR** (U2 — there is no Pololu module in this revision),
**TI TCAN1042HGVDRQ1** (U21, or the listed VIO alternates) and genuine
**TRACO TSR 1-2433** (a same-name LCSC module is not TRACO Power). No
pin-compatible-looking substitutions without a design/firmware revision.

Firmware for the ICM-42670-P, the throttle/brake channels, the Pi 5 video link and
the ESP32 network coprocessor **does not exist**, and the revised oil/coolant
conversions are not implemented. See `ASSEMBLY.md` and `DESIGN_NOTES.md`. The
archive's Rev A Gerbers and the Rev C illustration are not substitutes for these
layers.

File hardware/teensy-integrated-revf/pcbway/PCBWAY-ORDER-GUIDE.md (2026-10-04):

# Racecar-35 Rev F — PCBWay order guide

Everything needed to quote and order is in this folder. **Read "Before you click Buy"
at the end — it lists the things PCBWay's DFM check will ask about.**

Revision F · four-layer · 150.05 × 155.05 mm · 193 placements · 104 nets.

> ⚠️ **This is an UNAPPROVED engineering prototype.** The CAD passes ERC/DRC/unconnected
> at zero and the pin contract is asserted by script, but there is **no independent
> human review and no physical, thermal or RF validation**. Ordering prototypes is
> exactly what that status permits; winning races is not.

---

## Files in this folder

| File | What it is |
|---|---|
| `Racecar-RevF-PCBWAY-GERBERS.zip` | **This is the file you upload for the bare board.** 16 files: 4 copper layers, both masks, both silkscreens, both pastes, `Edge.Cuts`, separate **PTH** and **NPTH** Excellon drills with maps, and the `.gbrjob`. |
| `Racecar-RevF-BOM-pcbway-assembly.csv` | Turnkey-assembly BOM in PCBWay's column layout, with the "fit this, not that" instructions in the Comment column. |
| `Racecar-RevF-CPL.csv` | Pick-and-place, origin at the board lower-left, Y positive up, 182 rows (mounting holes and test pads are deliberately absent — nothing to place). |
| `REVF-CHANGES-AND-ORDER.md` | What changed since Rev D/E and why (the CAN fix, the 5 V rail, the input monitor). |
| `make_package.py` | Regenerates the three files above from `components.json` + the routed PCB. |

The full engineering package (schematic PDF, editable CAD, reports, manifest) is the
parent folder's `Racecar-RevF-GERBERS-ENGINEERING-PROTOTYPE.zip`. The fab file you
upload is the gerber-only ZIP above; **every order setting still comes from this guide.**

---

## Step 1 — Order the bare PCB

**pcbway.com → PCB Instant Quote → Quote Now → Upload Gerber File**, select
`Racecar-RevF-PCBWAY-GERBERS.zip`. PCBWay auto-detects size, layer count and outline —
**check these against the table before continuing**; if auto-detection disagrees, stop and
find out why.

| Setting | Value | Why |
|---|---|---|
| Board type | **FR-4** | |
| Layers | **4** | Auto-detected. `In1.Cu` is a continuous ground plane. |
| Dimensions | **150.05 × 155.05 mm** | Auto-detected. |
| Quantity | 5 (minimum) | |
| Thickness | **1.6 mm** | Matches the native stackup. |
| Min track / spacing | **0.20 mm / 0.15 mm** | The design's real minimums. |
| Min hole size | **0.30 mm** | The via drill. Standard for 4 layers. |
| Copper weight | **1 oz outer** | The screen branch is fused at **3 A** (`F2`), which is what makes 1 oz adequate. |
| Surface finish | **ENIG** | |
| Solder mask | **Green** | |
| Silkscreen | **White** | |
| Impedance control | **Yes** | The GNSS feed needs 50 Ω. |
| Castellation / edge plating / gold fingers | **No** | |

### About the outline
The profile includes a **48 × 6 mm WiFi antenna notch** cut into the bottom edge — it is
part of `Edge.Cuts`, just normal profile routing, **not** an internal slot. Four
**3.2 mm NPTH** mounting holes are in the NPTH drill file. Leave PCBWay's panelisation
**off** (connectors on one edge + a battery holder).

---

## Step 2 — Turnkey assembly: fit this, NOT that

Upload `Racecar-RevF-BOM-pcbway-assembly.csv` **and** `Racecar-RevF-CPL.csv` in PCBWay's
**Assembly → Turnkey** flow. The BOM Comment column carries the rules; the important ones:

| Ref | Fit | Do **NOT** fit |
|---|---|---|
| **U1** | 2× 1×24 2.54 mm THT female socket (`SSW-124-01-G-S`) | **a Teensy** — it is customer supplied, bought with pins, plugged in |
| **U2** | the soldered TI `TPS54560BDDAR` buck | — (there is no Pololu module and **no socket** at U2) |
| **JP1 / JP2** | the two 2-pin headers (`TSW-102-07-G-S`) | **the 2.54 mm shunts** — customer fits JP1 after rail tests, JP2 only at a bus end |
| **BT1** | the Keystone `1058` holder | **the CR2032 cell** — customer fits it after reflow/cleaning (primary cell, never charge) |
| **J9** | the JST `B2B-XH-A` connector | the two-wire RTC lead — hand-made by the customer to the Teensy VBAT/GND pads |

Check every MPN/package PCBWay matches against LCSC before paying — expect a few to be
unmatched and to need the substitutes already agreed (see `REVF-CHANGES-AND-ORDER.md` §4).

### Customer-supplied / hand-fitted (not ordered here)
Full list in `../design/ASSEMBLY-EXTRAS.csv`: Teensy 4.1 + its two male strips, the JP1/JP2
shunts, the CR2032 cell, the J9 RTC lead (housing + contacts + wire), M3 standoffs, and the
3.3 V active GPS antenna.

---

## Step 3 — CAN (new in Rev F)

The external CAN module and its `J7` header are **gone** — don't expect them in the
Gerbers or BOM. In their place the board is built with a soldered **`TCAN1042HGV-Q1`**
(`U21`) whose `STB` pin is tied to GND, a **`NUP2105L`** bus TVS, a third Phoenix
**`1729021`** field terminal (`J14` = **1 CANH / 2 CANL / 3 GND**) and a switchable
**split 120.8 Ω** termination behind the **`JP2`** shunt.

⚠️ **`U21` must not be substituted.** Order `TCAN1042HGVDRQ1` from **authorized
distribution only**, and do not swap it without written approval — no clones, no re-marked
parts. The reason is a bench-proven one: the module this replaces was **mislabelled** (a
TJA1051T/3-class chip sold as an SN65HVD230), and the pinout difference caused the failure.
Approved alternates, in order: `TCAN1042VDRQ1`, then NXP `TJA1051T/3/1J` (its pin 8 `S` must
also go to GND). The **`V` suffix is mandatory** — `TCAN1042DRQ1` / `TCAN1042HDRQ1` /
`TCAN1042GDRQ1` have **pin 5 = NC**, which would put 5 V on Teensy pin 23 and destroy it.
**Never** an SN65HVD23x, a plain `TJA1051T` (no `/3`), a `TJA1050`, or a "pin-compatible"
clone.

**When the boards arrive, check `U21`'s top marking against TI's *Device Marking* for
`TCAN1042HGVDRQ1` before power-up and reject on mismatch** (procedure in
`../design/BRINGUP.md`).

CAN is **not built or measured**. Bring-up acceptance (U21 VCC/VIO/STB voltages, ~60 Ω at
J14 with the jumper, a CANable `CANTX,10` test) is in `../design/BRINGUP.md`.

---

## Before you click Buy

1. **Quote, don't guess.** Send the quote to us first — a wrong layer stack or copper
   weight is expensive to discover after fabrication.
2. **U1 is a socket pair, not a Teensy.** If your BOM tool flags `SSW-124-01-G-S`, that is
   correct and intended.
3. **Do not fit the shunts or the CR2032 cell.**
4. **The board is not panelised** on purpose.
5. **No independent review has happened.** Do not present this package as reviewed or
   production-qualified.

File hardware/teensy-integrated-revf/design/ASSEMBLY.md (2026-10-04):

# Rev F — engineering-prototype assembly

Use the actual `BOM.csv`, `COMPONENT-ALIASES.json`, schematic, editable PCB and
placement CSV together. Function aliases are descriptive names used by source;
physical reference designators are fully annotated (U1, U2, R1…). Placement CSV
rotations are KiCad conventions: the assembler must inspect IC pin 1 and polarity.
SMT/THT/module mixed assembly is required; a bare PCB is not a complete unit.

## External terminal bank — ALL EIGHT face LEFT in top view

Pin numbers increase **top to bottom**; connector entries point outward.

| PCB connector | Function | Pins, top to bottom |
|---|---|---|
| J3 | TACH | 1 conditioned SIGNAL, 2 RETURN |
| J4 | OIL | 1 +5 V sensor OUT, 2 RETURN, 3 analog SIGNAL |
| J5 | COOLANT | 1 dedicated NTC lead, 2 RETURN |
| J6 | AEM AFR | 1 solid WHITE signal+, 2 BROWN reference return |
| J11 | THROTTLE | 1 +5 V sensor OUT, 2 RETURN, 3 analog SIGNAL |
| J12 | BRAKE | 1 +5 V sensor OUT, 2 RETURN, 3 analog SIGNAL |
| J1 | POWER | 1 +10–20 V IN, 2 GND |
| J2 | SCREEN | 1 GND, 2 fused +5 V OUT, 3 RX FROM screen, 4 TX TO screen |

⚠️ **`J14` (CAN) is mid-board, not on the left edge.** It is a third Phoenix
**1729021** 3-position 5.08 mm terminal, next to the onboard transceiver rather than
with the left-edge bank (that edge cannot hold a ninth screw terminal with usable
clearances). Pinout, **left to right** in the board's normal orientation — the
**square pad is pin 1**:
**1 = CANH, 2 = CANL, 3 = GND** (signal-ground reference to the ECU).
`JP2` ("CAN TERM") is a 2-pin shunt **in series with the split-termination pair**:
**fit the shunt only if this board is an end of the CAN bus**; remove it on a mid-bus tap
and remove it entirely if the ECU end is already terminated at 120 Ω. `TP6`/`TP7` are the
`CAN_TX`/`CAN_RX` logic-side test points. **`U21` orientation:** the footprint's own
silkscreen is kept on the board (Rev F restores library footprint silk board-wide), so the
usual SOIC-8 **pin-1 dot** is printed at the `TXD` corner — the corner nearest `J14`/U1;
pin 8 (`STB`, already tied to GND on the board) is the far end of that row.

Other field connectors: **J8** GPS SMA, **J9** RTC cell lead, **J10** NET 3V3
service/programming 2×3 header, **J13** Pi 5 video UART (JST XH), **J14** CAN
(Phoenix 1729021). The old `J7` CAN-module header is deleted — the transceiver is on
the board and its `STB` pin is tied to GND, so there is no receive-only module to fit.

**J2 goes ONLY to the verified screen J10 5V_IN / TXD0_H / RXD0_H interface.** It must
NEVER feed the small screen HY2.0/J2 **3V3_OUT** pin — +5 V there destroys the
ESP32-S3. Verify the particular screen's connector orientation and levels before
connecting. Disconnect both UART conductors before a screen USB flash. These are TTL
UART signals, not RS232.

⚠️ **J4 / J11 / J12 supply +5 V to the sensor.** Connect only sensors that this board
powers. **Do not** parallel these +5 V pins onto a transducer the ECU or vehicle
harness already feeds — two supplies on one node can backfeed the other regulator.
If the sensor is already powered by the car, leave the recorder's +5 V pin
unconnected and take signal + ground only (verify the sensor's ground reference
first).

⚠️ **J5 is a dedicated two-wire NTC.** Do not tee into an ECU-biased coolant sender.

⚠️ **J6 takes the AEM 30-0300 gauge analog output, not an oxygen sensor.** The gauge
and its heater stay externally powered and fused per AEM (10–18 V gauge rating); do
not power them from this board, and do not apply the recorder's 20 V test input to
the gauge.

⚠️ **TACH (J3) is a conditioned ECU/cluster signal only.** No coil negative, ignition
or injector drive, VR pickup, or default pull-up into the vehicle. Verify the
specific car's waveform and pulses/revolution with a scope.

## Module / through-hole operations

1. Fit the BOM SMT parts with the verified manufacturer pinouts. Inspect bridges at
   the ICM-42670-P, the two analog switches (U15/U16) and the logic buffers before
   any module is installed.
2. Fit all terminals, SMA, TRACO modules, electrolytics, fuse parts and service
   headers. Observe C1/C2 polarity. **C1 positive is on VIN_PROTECTED, after the Q3
   reverse-polarity FET**, not on the raw/reversible input.
3. **U2 is a soldered TI `TPS54560BDDAR` buck — there is NO socket and NO Pololu module.**
   Do not fit a socket at U2 and do not source or fit a Pololu 4091 / D36V50F5: Rev E
   removed the module. Reflow U2 as an ordinary SMT part and confirm the **PowerPAD
   (pad 9) is fully soldered to the ground copper** — it carries the heat, and the
   continuous-5 A claim is gated on bench thermal testing. **C1 positive is on
   `VIN_PROTECTED`**, i.e. *after* the Q3 P-channel reverse-polarity FET, not on the
   raw/reversible input. Observe L2, D23 and the input/output ceramic positions as placed;
   the switch node is the noisy node to keep probes and fingers away from.
4. **U1 — fit two 1×24 2.54 mm female sockets; do NOT fit a Teensy.** Samtec
   `SSW-124-01-G-S` or any standard 1×24 socket, matching male pins on the Teensy.
   The socket is **mandatory for the RTC feature** (the J9 lead lands on the Teensy's
   underside VBAT/GND pads). If sockets cannot be sourced, **leave U1 completely
   unpopulated — do not substitute, and do not solder a Teensy down.** Confirm mating
   height and access to USB, SD and the Program button.
5. **Physically cut and verify the Teensy VUSB–VIN bridge before simultaneous USB and
   carrier power.** The carrier diode/jumper is NOT a substitute. Leave JP1 open until
   power-stage tests pass; fit a standard 2.54 mm shunt afterward.
6. RTC: J9 uses a short, keyed two-wire lead (JST XHP-2 housing, matching
   SXH-001T-P0.6 contacts) to the Teensy's labelled auxiliary **VBAT and GND** pads.
   J9 pin 1 → VBAT; pin 2 → GND. This manual lead is REQUIRED: the outer-row sockets
   do not carry VBAT. Leave Program and On/Off unconnected. Insulate and
   strain-relieve the lead; unplug it before removing the Teensy. Do NOT connect it
   to adjacent 3V3.
7. Fit the **Panasonic CR2032 primary 3 V cell** into the Keystone 1058 holder only
   AFTER soldering and cleaning. Verify `+` polarity. No LIR2032, no charger, no
   direct soldering or reflow of a coin cell. The battery retains RTC only — not the
   processor, SD, GPS, WiFi or screen.
8. Fit the soldered NEO-M9N and ESP32 modules, respecting orientation, underside
   ground/paste and antenna clearance (the module antenna sits over the board notch).
   Obtain a **genuine ICM-42670-P**; reject an unreviewed substitute, counterfeit or
   unknown salvage in a supplied assembly.

## Assembly extras (deliberately not BOM lines)

`ASSEMBLY-EXTRAS.csv` is the full list; the ones that matter:

| Qty | Part | Who |
|---|---|---|
| 2 | 1×24 2.54 mm female socket (Samtec SSW-124-01-G-S) into the U1 footprint | assembler, else customer |
| 2 | 1×24 2.54 mm male strip on the Teensy | customer |
| 1 | CR2032 cell — never reflowed | customer |
| 1 | JP1 shunt (Harwin M7566-05) — only after unloaded rail tests | customer |
| 1 | JP2 shunt (same 2.54 mm type as JP1) — **only if this board is a CAN bus end** | customer |
| 1 | RTC lead: JST XHP-2 + 2× SXH-001T-P0.6 + hook-up wire (J9 → Teensy VBAT/GND) | customer |
| 4 | M3 insulated standoffs and screws | customer |
| 1 | 3.3 V active GNSS antenna, SMA male, draw compatible with the 50 mA minimum bias limit | customer |

## Programming / firmware limitations — important

- Source/build version at this hardware checkpoint is **0.1.169**. These files do not
  flash or publish anything.
- **CAN (Rev F):** the onboard TCAN1042 needs **no firmware change** — 500 kbit/s, normal
  ACKing mode. `CANTX,<n>` and `ACKTEST` on the USB serial console are the bench
  transmit self-tests (see `BRINGUP.md`). The TCAN1042's TXD dominant time-out (~1 ms)
  cuts the firmware's `CANHOLD` diagnostic short; that is expected.
- **IMU:** the board carries an **ICM-42670-P**, register-incompatible with the
  MPU-6050 the current firmware drives. A new driver, identity detection (WHO_AM_I
  0x67 vs the legacy 0x68 path) and an `ImuCalStore` sensor-type tag are required
  before any IMU value is believable.
- **Oil** input gain is now **0.500**, not the legacy 2/3. **Coolant** uses
  **4.096 V / 2.49 kΩ excitation with a 0.500 sense divider**, not the old 150 Ω
  circuit. New conversions/calibration and a verified sender curve are required
  before believing those displayed values.
- **Throttle (A7) and brake (A10)** need conversions, plausibility limits and logging
  fields. They are not implemented.
- AEM retains the existing nominal 0.500 gain contract; calibrate measured ADC
  reference/gain and test fault/stale behaviour. The AEM setting remains default OFF.
- The **Pi 5 video link** (Serial1, pins 0/1) needs the `VID,` protocol implemented;
  the Pi-side recorder is a separate project.
- The **network ESP32 is a third programmable MCU**; its SPI upload / provisioning /
  recovery firmware is still required. **Teensy pin 13's old heartbeat must stop
  before SPI use.** No faster-upload claim follows from merely populating the module.
- J10 **on this carrier** is the network programming header (not the screen J10):
  1 GND, 2 3V3 reference OUT, 3 TX from NET, 4 RX to NET (buffered), 5 BOOT0, 6 EN.

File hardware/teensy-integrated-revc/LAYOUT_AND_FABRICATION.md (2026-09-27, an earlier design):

# Rev C layout and required Gerber release

**Active revision: C.** A/B are retired. The current C artwork remains a placement
concept, not an electrical PCB. **The user requires Gerber + drill files as the
final deliverable. A preview/review ZIP is NOT a substitute.**

## Connector bank — one edge, labelled

All six screw-terminal blocks are along the **LEFT edge in the top view**, with
wire entries facing LEFT and screwdriver access from above. Function names sit
above each block; proposed numbered pin labels sit alongside, not underneath it.
Reserve wire bend radius, tool access and enclosure openings in the mechanical design.

**Proposed order, top-to-bottom (NOT released wiring):**

| Block | Proposed pad 1 → last pad, top-to-bottom |
|---|---|
| TACH | 1 SIGNAL / 2 RETURN — conditioned ECU/cluster only, never coil/injector |
| OIL | 1 +5V OUT / 2 RETURN / 3 SIGNAL |
| COOLANT | 1 NTC / 2 RETURN |
| AEM AFR | 1 SIG+ (solid WHITE) / 2 RETURN (BROWN), gauge output only |
| POWER IN | 1 +10–20V IN / 2 GND |
| SCREEN | 1 GND / 2 +5V OUT / 3 RX FROM SCREEN / 4 TX TO SCREEN |

Final schematic nets, connector pad numbering and purchased part drawings must
agree before this becomes a wiring diagram. The earlier Rev A tach connector
used a different order and only accepted an external opto output; do NOT copy its
netlist or harness wiring into this proposal. Screen connection is verified
Advance J10 ONLY, never HY2.0/J2 3V3_OUT; verify the particular clone's pinout.

GPS SMA remains external. Service headers, optional CAN logic header and Teensy
USB/SD are NOT screw terminals; they still need enclosure/service access.

## Internal WiFi antenna

Use **ESP32-S3-WROOM-1-N8R2**, not the 1U module. Built-in PCB antenna; no WiFi
antenna jack, pigtail or external antenna. The antenna points down in the top
view and overhangs a proposed **48 x 6 mm carrier notch**. Its stock RF rule area
is retained. This changes the carrier outline but not its nominal **130 x 140 mm**
envelope. The notch/clearance remains subject to module-manufacturer RF/mechanical
review, not a proven layout recommendation for every enclosure.

Keep ALL host copper/layers, components, metal fixtures, battery and wire bundles
out of the antenna clearance. Use a plastic enclosure/RF-transparent window and
verify installed performance; short distance does not defeat metal shielding.
GPS RF, dual-WiFi upload ownership, screen-led OTA and RTC backup remain as specified
in `WIFI_RTC_ARCHITECTURE.md`.

## What still blocks actual Gerbers

1. **Electrical design:** no Rev C schematic/netlist exists. Complete GPS power/RF/
   antenna bias, selected IMU support, sensor protection/calibration, opto front
   end, AEM power-off isolation, new WiFi supply/SPI/reset and VBAT contact circuitry.
2. **Exact components/footprints:** representative packages and candidate BOM are
   not final. Verify pad numbering, genuine ordering codes, current/voltage/thermal
   budgets, source loading, power sequencing, USB backfeed and connector ratings.
3. **Actual layout/routing:** place final parts, define stackup/impedance/copper
   weights, route all nets, size power paths, pour planes and enforce RF keepouts.
4. **Checks/review:** electrical review plus ERC; compare every connected PCB pad
   with the exported schematic; DRC including unconnected items; footprint and
   silkscreen accessibility inspection. Passive-block ERC alone is insufficient.
5. **Export and inspect:** generate all used copper layers, both solder masks,
   silkscreens, appropriate paste, board outline and separate plated/non-plated
   Excellon drills. Inspect them in a Gerber viewer, verify outline/drill alignment
   and include fabrication specifications, approved BOM and assembly data.

`fabrication/export.py` is the fail-closed export pipeline for that future board.
It accepts only `design/racecar-integrated-revc.kicad_pcb` and its matching schematic,
not `preview/PLACEMENT-ONLY-NOT-FOR-FAB.kicad_pcb`. It requires a hash-pinned design
review, genuine nets/tracks, clean ERC/DRC and schematic/PCB net agreement. Its
current expected result is **BLOCKED: missing electrical design**, not a Gerber ZIP.
The exporter itself has not been validated against a completed Rev C board.

**No routing, electrical approval or Gerbers have been created by the preview
regeneration.** Do not rename the netless preview PCB or the archived Rev A Gerbers
to bypass these missing engineering steps. Even a future clean CAD export will
still be an unvalidated prototype requiring current-limited bring-up and physical
RF/thermal/load/vehicle testing before use.

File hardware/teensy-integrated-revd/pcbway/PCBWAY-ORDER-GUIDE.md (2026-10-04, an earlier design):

# Racecar-35 Rev D — PCBWay order guide

Everything in this folder is ready to upload. **Read the "Before you click Buy"
section at the end — there are two items PCBWay's DFM check may push back on.**

Revision D · four-layer · 150.05 × 155.05 mm · 158 placements · 89 nets

---

## Files in this folder

| File | What it is |
|---|---|
| `Racecar-RevD-PCBWAY-GERBERS.zip` | 16 files: 4 copper layers, both masks, both silkscreens, both pastes, `Edge.Cuts`, separate **PTH** and **NPTH** Excellon drills, drill maps, `.gbrjob`. This is the file you upload. |
| `Racecar-RevD-BOM-pcbway-assembly.csv` | Turnkey-assembly BOM in PCBWay's column layout. |
| `Racecar-RevD-BOM-purchasing.csv` | 68 unique parts aggregated by MPN with references — use this if you buy parts yourself. |
| `Racecar-RevD-CPL.csv` | Pick-and-place, origin at board lower-left, Y positive up, 158 rows. |
| `PARTS-AVAILABILITY-REVIEW.md` | **Read before replying to the PCBWay quote.** Six BOM lines must change, two capacitor subs need a counter-proposal, plus verified where-to-buy for the 12 consignment parts. |
| `BOM-CHANGES.csv` | The same change list in machine-readable form. |

> **⚠️ The BOM files in this folder are CORRECTED to BOM revision 1**
> (`1206L010/30YR` → `1206L010/60WR`, `PESD3V3U1UL,315` → `PESD5V0F1BL,315`,
> bare `SS14` → onsemi `SS14`, and three Murata caps with no stock → Yageo/Samsung
> X7R equivalents). The file to send to PCBWay is
> **`Racecar-RevD-BOM-pcbway-assembly-REV1.csv`** — it is the corrected BOM with
> **U1/U2 fitting instructions in its Comment column**: for **U2** PCBWay fits only
> a **2×6 0.1 in THT female socket** (`SSW-106-01-G-D`) — **we supply the Pololu 4091
> module and plug it in** (they could not source it in two attempts); for **U1** the
> Teensy 4.1 is customer supplied **with pins** — PCBWay fits the two 1×24 sockets
> and we plug the Teensy in.
> The canonical copy of the same BOM is
> `Racecar-RevD-BOM-pcbway-assembly.csv`. Reply document:
> **`PCBWAY-REPLY-2026-09-29.pdf`**. Background: `PARTS-AVAILABILITY-REVIEW.md`.

The full engineering package (schematic PDF, editable CAD, reports, manifest) is
the parent folder's `Racecar-RevD-GERBERS-ENGINEERING-PROTOTYPE.zip`. Its documents
(`FABRICATION.md`, `ASSEMBLY.md`, `DESIGN_NOTES.md`, `BRINGUP.md`) were regenerated
for **Rev D** — but the fab file you upload is the gerber-only zip above, and every
order setting still comes from **this** guide.

---

## Step 1 — Order the bare PCB

Go to **pcbway.com → PCB Instant Quote → Quote Now**, then **Upload Gerber File**
and select `Racecar-RevD-PCBWAY-GERBERS.zip`.

PCBWay will auto-detect the size, layer count and outline. **Check these against
the table before continuing** — if auto-detection disagrees, stop and look at
why rather than clicking past it.

| Setting | Value | Why |
|---|---|---|
| Board type | **FR-4** | |
| Layers | **4** | Auto-detected. `In1.Cu` is the ground plane. |
| Dimensions | **150.05 × 155.05 mm** | Auto-detected. |
| Quantity | 5 (typical minimum) | |
| Thickness | **1.6 mm** | Matches the native stackup. |
| Min track / spacing | **0.20 mm / 0.15 mm** | The design's real minimums. |
| Min hole size | **0.30 mm** | The via drill. Within standard for 4 layers. |
| Copper weight | **1 oz** | The screen branch is now fused at **3 A**, so 1 oz is adequate — see below. |
| Surface finish | **ENIG** | Specified in the design. |
| Solder mask | **Green** | |
| Silkscreen | **White** | |
| Impedance control | **Yes** | The GNSS feed needs 50 Ω. |
| Castellation | No | |
| Edge plating | No | |
| Gold fingers | No | |

### About the outline

The board profile includes a **48 × 6 mm WiFi antenna notch** cut into the bottom
edge. It is part of `Edge.Cuts` and is routed as normal board profile — you do
**not** need to order an internal slot. Four **3.2 mm NPTH** mounting holes are in
the NPTH drill file.

Leave the "Panel by PCBWay"/panelisation option **off** — this board has connectors
on one edge and a battery holder; a v-cut or tab panel will make assembly harder,
not easier.

---

## Step 2 — Decide how it gets assembled

**This board is mostly hand assembly.** Only 46 of the 68 unique parts are normal
SMD. The other 22 are modules, screw terminals and through-hole parts that
pick-and-place machines don't handle.

| Approach | What PCBWay does | What you do |
|---|---|---|
| **A — Bare PCB (recommended)** | Fabricates the board only | Buy parts from the purchasing BOM; hand-solder everything. |
| **B — Partial turnkey** | Machine-places the SMD passives and ICs | Hand-solder the 22 modules/connectors/THT parts. |
| **C — Full turnkey** | Would need every part consigned | Not practical — see below. |

**Recommendation: start with A.** It is the cheapest, it removes all part-availability
risk, and this board was designed for hand assembly of the connectors and modules.

If you want **B**, use PCBWay's **PCB Assembly → Turnkey** flow and upload
`Racecar-RevD-BOM-pcbway-assembly.csv` plus `Racecar-RevD-CPL.csv`. Their BOM tool
matches your MPNs to LCSC stock; **check every match it proposes** against the
MPN and package in the purchasing BOM. Expect some to be unmatched.

**Why C doesn't work:** these parts are not LCSC line items and would have to be
consigned (shipped to PCBWay) or sourced by them at a premium —

Teensy 4.1 · Pololu D36V50F5 · 2× TRACO TSR 1-2433 · u-blox NEO-M9N-00B ·
ESP32-S3-WROOM-1-N8R2 · TDK ICM-42670-P · Amphenol 901-143 SMA · Keystone 1058
holder · 8× Phoenix MKDS terminals · VO617A-3 optocoupler

---

## Step 3 — Ordering the parts yourself (approach A)

`Racecar-RevD-BOM-purchasing.csv` is grouped by MPN with quantities and reference
designators. Sourcing notes:

- **Passives (Yageo 0805, Murata 0805)** — Digi-Key / Mouser / LCSC. Note the BOM
  marks the analog divider resistors as **0.1 % thin-film** and the 150 Ω / 2.49 kΩ
  as precision. Do not substitute 1 % parts there; the analog front end depends on
  the ratio.
- **Teensy 4.1** — PJRC direct. Buy two 1×24 2.54 mm **female** headers as well
  (they are not in the BOM as a purchasable line — see assembly notes).
- **ICM-42670-P** — buy genuine, not a marketplace re-mark.
- **36 of the 158 placements are not purchased parts**: 5 test pads, 4 mounting
  holes, and the Pololu/TRACO modules' mechanical lines.

---

## Step 4 — Assembly notes that will bite if ignored

1. **Socket the Teensy — do not solder it.** Two 1×24 2.54 mm female headers go on
   the board; matching male headers go on the Teensy. This is what makes it
   removable and repairable.
2. **Cut the Teensy's VUSB–VIN bridge before USB and car power are ever both
   connected.** JP1 is *not* a substitute. Leave JP1 open until the rails have
   been tested unloaded.
3. **Fit the CR2032 cell last**, after reflow and cleaning. It is a primary cell —
   never reflow it, never solder a non-tabbed cell, never substitute a rechargeable
   LIR2032.
4. **J9 is a hand-made lead**, not a socket contact. It runs to the Teensy's
   labelled auxiliary **VBAT and GND pads**. The outer socket rows do not carry
   VBAT — do not hunt for it there.
5. **Fit JP1's shunt only after bring-up.**
6. **U1 — sockets, or nothing.** If PCBWay cannot source the two 1×24 sockets, tell
   them to leave U1 **completely unpopulated**: do not substitute, and never solder a
   Teensy down (the J9 RTC lead lands on the Teensy's *underside* VBAT/GND pads, so
   the module must stay removable). Hand-fitting 2× 1×24 sockets is 48 pins on a
   2.54 mm grid — the easiest joint on the board, and the planned fallback.
7. **U2 — a socket, and the module only fits one way.** PCBWay fits a 2×6 0.1 in
   female socket and the Pololu 4091 plugs into it. Insert it **TOP (labelled) face
   up, with the VOUT column over U2 pad 1** — the only *rectangular* pad in that
   footprint, at the north end of the block. The module's own key: the four
   **square** plated holes are GND, and VOUT is **one column** in from them while
   EN/PG is **three columns** from them. Mirrored, VIN meets the 5 V rail and VOUT
   meets 10–20 V — that destroys the module. Confirm with the continuity check in
   `../design/BRINGUP.md` step 3 before applying power. The carrier has **no U2
   silkscreen labels**; adding them would be a silkscreen-only change (see
   `PARTS-AVAILABILITY-REVIEW.md` §4b) and needs a re-export first.

---

## Before you click Buy — the two previously-open items are now resolved

### 1. Copper weight — settled at 1 oz

The screen branch fuse is **3 A** (`F2`, Littelfuse `0451003.MRL`). The
`+5V_MAIN` trunk is 3.5 mm wide, and at 1 oz / 35 µm that is adequate for the
fused screen load plus the Teensy and the three 100 mA sensor branches.

**Order 1 oz outer copper** — it is PCBWay's standard, cheaper, and no longer a
marginal call. Do **not** raise the screen fuse back to 4 A on this build.

### 2. GNSS feed — corrected, and the target is now explicit

The feed was **0.80 mm wide, which is about 30 Ω — badly wrong.** It has been
recalculated as a **microstrip over the In1.Cu plane**:

| Prepreg L1→L2 (H) | W for 50 Ω at εr 4.4 |
|---|---|
| 0.10 mm | 0.19 mm |
| 0.15 mm | 0.29 mm |
| **0.20 mm** | **0.38 mm** ← what the board now uses |
| 0.25 mm | 0.48 mm |
| 0.36 mm | 0.69 mm |

Validated with the Wheeler/Hammerstad closed form (agrees to <1 % against the
parallel-plate limit). **The board is set to 0.38 mm, which is 50 Ω if the
prepreg to `In1.Cu` is 0.20 mm.**

The trace still has the F.Cu ground pour alongside it at 0.15 mm, which makes it
partly coplanar and pulls the real impedance **below** 50 Ω. So:

- **Order with impedance control ON**, and tell them the target: **50 Ω
  single-ended on `RF_ANT`/`RF_GNSS`, from J8 to the NEO-M9N RF_IN.**
- **Ask for their finished stackup first** (prepreg thickness to L2 and Dk). If it
  is not 0.20 mm, the width must change — the table above gives the new value.

The standard 4-layer 1.6 mm construction is one 7628 prepreg each side of a
1.065 mm core; it sums to 1.596 mm, which is the 1.6 mm finished board. That fixes
H = 0.1955 mm, and the routed 0.38 mm gives **49.6-50.6 ohm** across eps_r 4.2-4.6.
Nothing further needs deciding.

---

## Checklist before ordering

- [ ] Gerber zip uploaded; auto-detected layers = **4**, size = **150.05 × 155.05 mm**
- [ ] Copper weight **1 oz** (screen fuse is 3 A)
- [ ] **ENIG** selected (not HASL)
- [ ] **Impedance control ON**, GNSS feed target 50 Ω stated in the order notes
- [ ] NPTH drill file present so the 3.2 mm mounting holes are not plated
- [ ] Antenna notch visible in the Edge.Cuts preview
- [ ] Panelisation **off**
- [ ] U1 instruction stated: **sockets only, else leave U1 unpopulated**
- [ ] DFM report read — not just accepted

---

## Standing caveat

This is an **unbuilt engineering prototype**. It has passed ERC, full-severity DRC
and netlist verification (0 violations, 0 unconnected, 456 pads matching the
schematic, 531 pin/geometry assertions) — but it has **not** been independently
reviewed or physically validated, and **no firmware exists for the ICM-42670-P,
throttle, brake or WiFi coprocessor yet**.

Clean CAD is not a working board. Review the DFM report, and bench-test before it
goes near a car.

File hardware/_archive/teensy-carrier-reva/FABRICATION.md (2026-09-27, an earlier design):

# Prototype fabrication / assembly order notes

**STATUS: unbuilt engineering prototype. Not released for permanent vehicle use.**
Obtain an independent schematic, power-protection, footprint and harness review
before placing even a prototype order. Do not order a production batch.

## Bare PCB specification

- Outline: **130.00 × 110.00 mm** rectangular, from Edge.Cuts only.
- Layers: **2** (F.Cu / B.Cu).
- Material: FR4, Tg >= 150 °C preferred, UL94 V-0.
- Finished board thickness: **1.6 mm**, normal manufacturer tolerance.
- **Finished copper: 2 oz / approximately 70 µm on BOTH sides. DO NOT substitute 1 oz.**
- Finish: ENIG preferred; lead-free HASL acceptable if assembler approves pads.
- Solder mask: both sides, any colour; silkscreen both sides.
- Min design track: 0.25 mm; routed signals normally 0.30 mm.
- Clearance: 0.20 mm board minimum; routing normally 0.25 mm.
- Vias: normally 0.80 mm pad / 0.40 mm finished drill.
- Through-hole module/header pads: generally 1.00 mm drill; use supplied drill files.
- Chassis holes: four **3.2 mm NPTH** for M3 insulating standoffs.
- Electrical net testing: REQUIRED. No intentional net ties or copper shorts.
- Main current paths: manually routed 3.0 mm tracks, 2.6 mm short module necks,
  wide GND return tracks plus both-side pours. Do not let fabrication software
  arbitrarily remove copper pours or narrow these paths.
- Prefer 2–5 prototypes initially, not a production order.

Gerbers do not encode a reliable purchase order for copper weight/material. Give
these notes to the fab explicitly. Confirm their 2 oz clearance/annular-ring rules
against the final files. The Gerber ZIP includes a front-paste layer for assembly;
it is not an extra copper layer. Plated and non-plated drill files are separate.

## Assembly

- Use `BOM.csv`, `BOM-extra.csv`, `assembly-positions.csv`, `assembly-top.pdf`, and
  `schematic.pdf` together. Position rotations are KiCad conventions, not guaranteed
  to match a particular assembler's zero-angle definition.
- The **Teensy is removable**, on two 1×24 female sockets, 2.54 mm pin pitch and
  15.24 mm row spacing. Top view: USB at the upper/short end shown in the drawing.
- **Do not populate a bare i.MX RT processor**: U1 is a complete PJRC Teensy 4.1.
- U2 is a complete **Pololu 4091 / D36V50F5** module, mounted above the PCB with its
  component side UP. Fit all twelve positions of a 2×6 male header. Solder both
  rows at both boards; use >=3 A/contact parts. Both output pins must carry current.
- The U2 outer and inner rows are NOT identical: final row is **EN outside / PG
  inside**. Working TOP view pin order is VOUT, GND, GND, VIN, VRP, EN/PG. Do not
  mirror a bottom-view photograph. The saved image explicitly labels the view.
- U2 underside has live components. Use a nonconductive support/spacer and clearance
  from the carrier; don't rest it on copper or metal screw heads. No guessed U2
  mechanical screw holes are drilled. The dual header supports the module; add
  nonconductive mechanical restraint appropriate for vibration after fit testing.
- U3 is a complete **Traco TSR 1-2433** module, pin 1 VIN, 2 GND, 3 3V3 OUT. The
  module is fed from U2 **VRP**, not raw reverse-polarity input or the 5 V rail.
- D1 **SMBJ20CA** is the bidirectional TVS. Do not replace with a unidirectional
  part without reviewing negative-input behaviour and fuse coordination.
- D2 SS14: pad 1 is cathode toward JP1/Teensy VIN; pad 2 anode toward main 5 V.
- C1 **EEU-FR1H101 (no B suffix)** is 8 mm diameter / **3.5 mm lead pitch**.
  The similar EEU-FR1H101B has **5 mm lead pitch** and is not a drop-in assembly
  substitution. C2 EEU-FR1A471B is 8 mm diameter / 3.5 mm pitch. Observe polarity.
- Direct GND pours need appropriate preheat/iron capability. Do not overheat modules
  trying to solder ground pins with an underpowered iron.
- Fit U4/U5 SN74LVC1T45**DBVR** and U6 SN74LVC2G17**DBVR** in SOT-23-6 packages.
  Other TI package suffixes are not footprint-compatible. Check pin-1 indicators.
- Leave JP1 **open** and the Teensy/GPS/IMU/screen disconnected for initial power
  testing. The shunt is fitted only at the stage described in BRINGUP.md.

## Mandatory pre-order checks

1. Open the KiCad project and PDFs; have another qualified person review power and
   MCU pin maps. A zero-DRC report does not verify the circuit will work.
2. Print the assembly drawing at **100% scale**, check with a ruler, and lay the
   purchased Teensy, sockets, Pololu and Traco modules on it. Confirm header pitch,
   row separation, module orientation, underside clearance and enclosure access.
3. Confirm the exact MPN/footprint match for every purchased connector and capacitor.
   Vendor substitutions require review, particularly electrolytic lead forming.
4. Confirm CrowPanel **clone** J10 power pin order and TTL levels against its own
   documentation/meter measurements. A USB MAC/chip ID is not evidence of connector
   compatibility. This is a release blocker until verified on that physical panel.
5. Read the bring-up plan. Use a current-limited supply and suitable loads; do not
   make an untested board's first power-up through an expensive screen or MCU.

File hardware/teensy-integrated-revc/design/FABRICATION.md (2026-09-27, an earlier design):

# Rev C — ENGINEERING PROTOTYPE fabrication specification

This is a first-build electrical prototype, not an automotive-qualified product.
The engineering export contains real copper, solder mask, paste, outline and drill
files. **A clean CAD report is not independent electrical approval, a load test,
or proof that this unbuilt board works.** Do not order production quantities.
The normal reviewed-release exporter remains separately gated.

## Board and process

- Envelope **130 × 140 mm**; use the supplied Edge.Cuts, including the **48 × 6 mm
  internal-WiFi antenna notch**. Never manufacture the former netless preview PCB.
- Two copper layers, **70 µm / 2 oz finished copper on BOTH sides**; 1.60 mm finished
  FR-4, Tg ≥150 °C. Quote capability for **0.15 mm copper clearance**, 0.20 mm signal
  routing, and the fine-pitch IC lands. Do not silently substitute 1 oz copper.
- ENIG, green mask, white legend. Lead-free process compatible with actual supplied
  modules/components. No automatic mirroring/scaling; all outputs share PCB origin.
- Separate metric Excellon **PTH and NPTH** files. The ESP32 ground-pad vias are
  0.30 mm drills / 0.60 mm lands, not laser microvias. Tented/plugged process must
  prevent paste draining under the module without changing land connectivity.
- Four 3.2 mm NPTH mounting holes; insulated standoffs, clearance below soldered
  leads. Do not clamp a metal enclosure against traces, cell holder, or headers.
- Main 5 V/screen and return trunks are deliberately wide; local regulator pad
  fanouts are narrower parallel branches. Do not let CAM thin these into signal
  tracks. **5 A is a TOTAL supply design target, not a tested continuous rating.**
- Inspect all mask slivers, annular rings, plane necks, module lands, drill alignment,
  outline and silkscreen in the CAM viewer before quoting/ordering.

## RF / enclosure requirements

- WiFi is **ESP32-S3-WROOM-1-N8R2 with its built-in PCB antenna**. Its stock all-layer
  antenna keepout is retained. No copper, vias, traces, screws, battery, cable or
  metal enclosure may intrude into the antenna region. The carrier is notched away
  beneath the antenna tip. Use a plastic enclosure/RF-transparent window; a closed
  metal trunk/enclosure can still block the signal.
- The **SMA is GPS only**, Amphenol 901-143. Inspect its mechanical drawing against
  the actual board edge, solder tails and enclosure hole before assembly.
- GNSS main RF traces target **50 Ω grounded coplanar waveguide**: nominal 0.80 mm
  width / 0.15 mm copper gap, with short 0.30 mm necks at tiny RF components. B-side
  routing/via keepout preserves the reference plane; stitching vias flank it.
  **These dimensions are a starting geometry, not an impedance certificate.** CAM
  must check the actual laminate Dk, finished copper and dielectric thickness and
  report the predicted impedance. Do not change the stackup or RF geometry without
  revising CAD and rerunning the checks. Coupon/VNA and GNSS reception tests remain.
- Active GPS antenna: **3.3 V bias**, current limited (TPS2553, nominal 75 mA setting,
  worst-case 50–100 mA). Specify an antenna whose draw works at the minimum limit.
  The external gauge, display and WiFi antenna are not powered through this SMA.

## Before an order

Obtain independent schematic/footprint/power-off review and fabricator DFM feedback.
Check availability of genuine **MPU-6050** (legacy/lifecycle risk) and NEO-M9N modules;
**no pin-compatible-looking substitutions** without a design/firmware revision.
The archive's Rev A Gerbers and the earlier Rev C illustration are not substitutes.
Firmware for the new WiFi processor and revised analog conversions is not supplied
by these manufacturing layers; see ASSEMBLY.md and DESIGN_NOTES.md.

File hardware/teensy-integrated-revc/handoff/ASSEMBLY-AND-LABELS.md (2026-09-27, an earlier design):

# Requested finished assembly / labels / test scope

**Design-review requirements, not released assembly instructions.** No final BOM,
CPL, component orientation drawing, PCB stackup or approved test limits exist yet.

## Finished assembly requested

- All approved PCB components installed, not a bare PCB plus loose component bags.
- Soldered GPS module and IMU IC, input protection/filtering/passives and onboard opto.
- All connectors, fuses, regulators, signal translators and auxiliary parts installed.
- Soldered **ESP32-S3-WROOM-1-N8R2 with INTERNAL PCB antenna**, dedicated NET
  3.3 V supply/decoupling and programming/recovery interface; no Ethernet or WiFi
  pigtail/bulkhead. Preserve antenna clearance and plastic/RF-window enclosure.
- ALL screw terminals at the LEFT edge, entries facing left; retain screw/tool/wire
  access. See `LAYOUT_AND_FABRICATION.md` for the labelled proposed bank.
- Replaceable vibration-retained CR2032 holder and the extra socket/contact for
  Teensy VBAT. Install the primary cell after soldering/cleaning; do not charge or
  reflow it. Agree cell/environmental rating and replacement interval.
- Teensy remains replaceable in sockets: install sockets and module headers, fit the
  Teensy, retain USB and SD access, and include suitable mechanical support.
- If the Pololu/Traco module approach is retained, include the modules, headers and
  secure supports. Verify that the assembler accepts their sourcing/consignment and
  manual assembly operations; availability alone does not establish suitability.
- Cut/verify the Teensy VUSB-VIN bridge according to PJRC before dual USB/carrier
  power use. A carrier diode or jumper is not a replacement for that modification.
- Provide test results and an agreed, compatible firmware image/programming procedure.
  Current firmware is not an approved integrated Rev C factory-test image.
- Treat the external GPS antenna, oil/coolant senders, their mating pigtails, external screen and car
  harness as explicit quoted inclusions or exclusions, not silently included in PCBA.

## Labels to implement in the finalized CAD

Request white silkscreen, readable AFTER components are fitted. Place connector
labels where tall terminal blocks do not obscure them. Include:

- Board name, revision and prototype status; optional separate serialized sticker.
- Power input voltage/polarity, GND and fuse identification/rating after validation.
- Screen connector: GND, +5V OUT, RX FROM SCREEN and TX TO SCREEN (PCB-relative).
  Mark verified Advance J10 only; do not confuse the display's HY2.0 3V3_OUT header.
- Oil: sensor supply OUT, dedicated sensor return and signal.
- Coolant: NTC input and dedicated sensor return.
- Tach: signal and reference/return; **ECU / CLUSTER ONLY - NO COIL / IGNITION**.
- GPS SMA/antenna designation; final antenna-power specification after RF design.
- `WIFI INTERNAL`, `NET SERVICE` and `3V3 NET`. No external WiFi port; external
  GPS SMA remains. Antenna clearance is not a place for labels/copper/metal fixtures.
- `RTC 3V CR2032`, polarity `+`, `DO NOT CHARGE` and VBAT contact/service identification.
- IMU axis orientation and test-point functions after placement/orientation is fixed.
- MCU power jumper function and the VUSB-VIN bridge warning.
- Optional CAN header explicitly described as a module logic interface, not CANH/CANL.
  Ethernet is permanently removed; BOTH trunk-module and screen WiFi are planned.
- AFR two-position connector: `AFR SIG+ / AFR RETURN`, for AEM 30-0300 solid
  WHITE / BROWN. No direct sensor, heater/controller or source-selection jumper.
  Verify the final footprint's pad numbering; complete scaled/protected input and
  power-off isolation review before assembly.

Printed labels must match the FINAL netlist and connector pin order. The current
rendering is not a wiring pinout and must not be copied as one without verification.

## Testing to scope and quote

AOI/X-ray/continuity inspection does not prove functional or automotive performance.
A qualified engineer must define safe fixtures and numeric pass/fail limits after
the circuit is completed. Expected work includes:

1. Assembly/identity/orientation inspection and unpowered short/power-path checks.
2. Controlled current-limited initial power-up, supplies and startup behaviour.
3. Input/sensor fault and powered/unpowered backfeed tests under defined conditions.
4. Load, startup, ripple and enclosure thermal testing at 10/14.4/20 V input; verify
   the requested 5 A TOTAL main-rail target before claiming that capability.
   The Rev A concept's screen branch was 4 A, not a 5 A screen output.
5. GPIO/tach waveform tests without loading the factory tach; independent RPM/PPR
   verification and year-specific vehicle checks. No raw-ignition testing on this input.
6. Oil zero/span checks and coolant resistance/temperature calibration and fault tests.
7. GPS power/RF/antenna operation and accepted update rate, plus IMU identity,
   orientation, static output and calibration/driver verification.
8. SD logging and the full-length 921600-baud screen cable, including power drop and
   activity under representative interference. Verify the particular clone's header.
9. New-module WiFi power-burst/thermal/RF testing, SPI correctness, real authenticated
   uploads under failure/retry/resume, screen fallback and unchanged OTA recovery.
10. RTC retention across main-power removal, no charging/backfeed, cell-loss/invalid
    time handling and fresh-Internet resync; document a battery service interval.
11. Documented firmware versions (including network module), test setup, results,
    anomalies and rework.

Automotive transient/EMC/environmental qualification is a separate engineering scope.
Do not apply uncontrolled automotive faults or a full load to an unverified circuit.

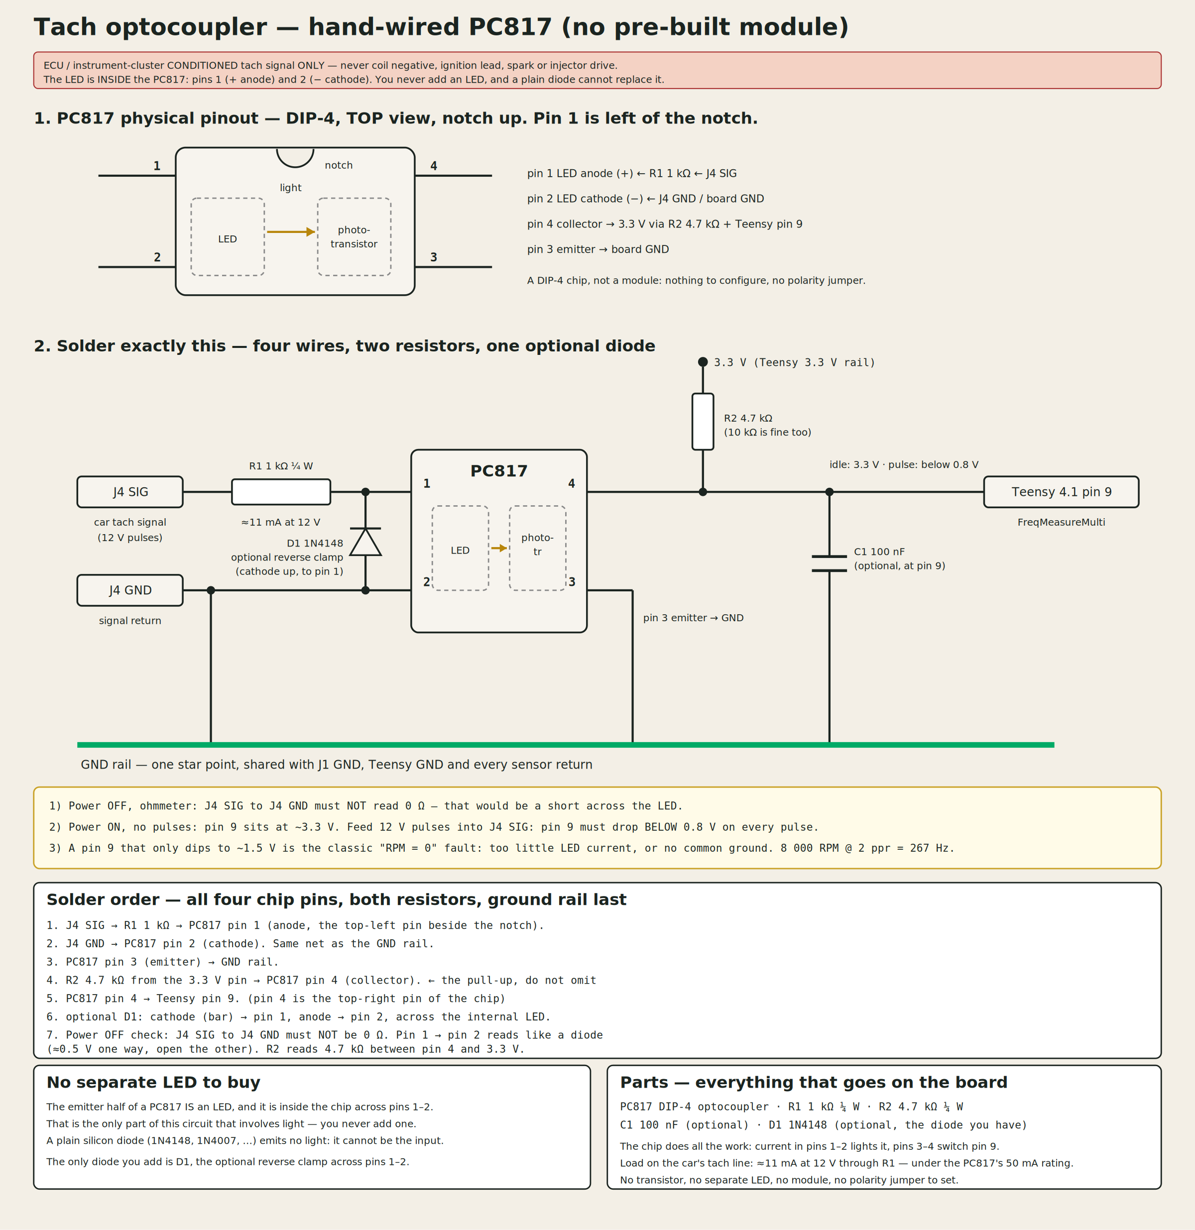
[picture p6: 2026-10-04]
hardware/breadboard/OPTO_WIRING.png

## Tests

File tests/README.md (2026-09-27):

# Host regression checks

Run `python3 -m unittest discover -s tests -v` from the repository root.
`test_wifi_only.py` checks removal of the retired Ethernet paths, compatibility
with legacy `inet`/`ETH` messages, WiFi/BLE radio guarding, NTP/time relay and
lockstep versions. It also extracts and compiles the real dash row-visibility
function to verify WiFi credentials/status stay visible across sensor/SD modes
(requires g++; that case is skipped if the compiler is unavailable).

These tests do not emulate the ESP32 radio, UART, SD or vehicle hardware. Build
the Teensy and both Advance display variants as the integration check; bench
verification is separate.

`test_aem_afr.py` compiles the real shared AEM decoder/parser, dash source selector
and Teensy SD serializer under UndefinedBehaviorSanitizer. It checks published
30-0300 scaling, all ADC codes, malformed frames, faults/nulls, source/staleness,
NVS/CFG opt-in, buffer overflow rejection and the server's actual data passthrough.
It does not verify a real ADC, reference voltage or the input protection circuit.

`test_fabrication_guard.py` checks Rev C fabrication-export rejection paths:
missing design inputs, stale output removal, absent/incomplete review, changed
source hashes and conflicting duplicate pad numbers. Explicit engineering mode
is also checked to ensure it never invents an independent approval. These unit
tests are NOT electrical, DRC, mechanical, RF or successful-Gerber-export tests.

The actual routed Rev C separately exercises the full engineering export path:
`electrical/verify.py` checks 427 pin/geometry/calculation assertions and 392 real
schematic/PCB connections; export runs fresh full ERC/DRC and package checks.
`fabrication/inspect_cam.py` re-reads Gerbers and compares drill locations/diameters
using Gerbonara. None of these checks proves physical performance or approval.

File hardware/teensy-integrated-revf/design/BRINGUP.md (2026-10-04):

# Rev F first-build bring-up — no vehicle connection initially

This is an unbuilt prototype. Obtain independent schematic/footprint and CAM review
first. Use a current-limited bench supply, DMM, oscilloscope, electronic load and
non-contact/attached temperature instrumentation. **Do not use a finger as a
thermometer.** Do not connect a Li-ion car battery directly to an untested assembly.

1. Inspect component orientation, solder bridges, polarity and header pin numbering.
   Teensy and CR2032 OUT, JP1 and JP2 open; no display, sensors, antenna or USB
   attached. Check for hard supply shorts with appropriate instrumentation; there is
   no universal ohms threshold that proves this mixed electronic load is healthy.
2. Verify the Teensy's cut VUSB–VIN bridge separately. Verify RTC lead continuity to
   the ACTUAL labelled VBAT/GND pads, not an inferred neighbouring contact.
3. **U2 is the soldered TI `TPS54560BDDAR` buck — there is no socket and no Pololu
   module to insert.** Before applying any power, confirm the PowerPAD solder joint and
   that C1 is on the protected rail. Start at 10 V with a conservative current limit and
   no external loads. Check protected input, +5 V MAIN, +5 V SCREEN, +3V3 AUX and
   +3V3 NET. **Without a good U2 joint, VIN_PROTECTED and all three derived rails are
   dead by design** — that is not a fault. Investigate a current-limit event rather than
   increasing the limit blindly. Check ripple, startup/restart and regulator temperature
   at 10, 14.4 and 20 V, and remember the asynchronous buck runs hotter than the module
   it replaced.
4. Confirm C1 is on the protected rail, diode orientation, and no charging/backfeed
   on VBAT. Perform power-off/source-sequencing checks with limited fault energy; do
   not improvise destructive reverse-battery or load-dump tests.
5. Fit the Teensy only after the rails pass. Verify 3V3, baseline supply current,
   CPU health and UART. Test carrier-only, USB-only (bridge cut), and controlled dual
   power. Test GPS/NET powered with the MCU off and vice versa for unintended
   backfeed on the Ioff buffers.
6. **IMU identity first.** The board carries an ICM-42670-P, not an MPU-6050: confirm
   the part and its I²C address (0x68) before trusting any driver, and expect the
   current firmware's MPU-6050 register accesses to be meaningless here.
7. With the display still disconnected, ramp an electronic load on the SCREEN branch;
   account for the MCU/sensor load in the **5 A TOTAL** budget. Characterize startup,
   inrush, ripple, cable drop and steady-state temperature. Do not label the assembly
   'continuous 5 A' until worst-case enclosure/ambient testing supports it.
8. Confirm the particular Advance screen's J10 pinout; use its 5V_IN interface, not
   3V3_OUT. Initially power with current limiting. Verify touch, boot identity and
   bidirectional 921600-baud communication over the intended full cable length.
9. Apply a low-energy test waveform to conditioned TACH: scope loading, trip levels
   (≈1.84 V rising / 1.56 V falling input-referred, before tolerance), optocoupler
   transitions and the final pin-9 swing. Check 3.3/5/12 V amplitudes and 1–500 Hz
   before any car connection. Establish actual vehicle PPR independently.
10. Analog testing with MCU on AND off, using precision sources and resistor decades.
    **All five channels (oil, AFR/coolant, throttle, brake) are 0.500 gain with a
    3.0 V shunt clamp.** Sweep oil/AFR/throttle/brake 0–5 V; verify gain, clamp,
    open/short behaviour and no power-off injection. Test overvoltage only with a
    current-limited fixture inside the reviewed fault budget. For coolant, use a
    resistor decade against the 4.096 V / 2.49 kΩ excitation and verify the 40 kΩ
    parallel-loading compensation. Compare displayed/logged values to instruments;
    DO NOT trust the legacy oil/NTC scaling.
11. Program the network module through its 3V3 UART fixture on J10 (1 GND, 2 3V3
    reference, 3 TX from NET, 4 RX to NET, 5 BOOT0, 6 EN). Then implement and validate
    SPI identity, flow control, CRC, reset, upload ownership/auth/resume and recovery.
    **Disable the Teensy's pin-13 heartbeat before enabling SPI (pin 13 is NET_SCK).**
    No uploader firmware is included here. Test RF while GNSS runs and while the
    screen uses WiFi/BLE; test video UART (J13) while RF is active. Record real
    throughput rather than a SPI theoretical rate.
12. After soldering/cleaning, install the CR2032. Measure retained RTC behaviour
    across hours/days without main power, cell removal/depletion handling, and
    fresh-time resync. Verify no cell charging in car/USB/off states and normal
    restart with VBAT fitted.
13. Finally test the real AEM output, the dedicated oil/coolant senders, the
    throttle/brake senders and the conditioned vehicle tach with appropriately fused
    harnesses. Keep gauge/heater power external, and do not parallel a car-powered
    sensor onto the board's +5 V sensor pins. Recording, warnings, SD integrity, GPS
    freezes, communications and temperatures need vehicle validation before track
    use. Retain original data on upload failure.

## CAN bring-up (Rev F) — must PASS before any car bus connection

> **Root cause this checklist exists to catch** (bench, 2026-10-04): the Amazon "SN65HVD230"
> modules are mislabelled TJA1051T/3-class chips. Wired the SN65HVD230 way (VCC = 3.3 V,
> pin 5 floating) the logger *receives* but never drives a dominant bit, never ACKs, and the
> sender storms ~3,800 frames/s. Full analysis:
> `../../../CAN-TRANSCEIVER-FINDINGS-2026-10-04.md`.

### 0. Prerequisites — get these right or the test lies

* **Power: `J1` at 12 V must be connected AND the Teensy must be seated.** `U21` VCC is
  `+5V_MAIN` (from the buck) and VIO is `+3V3_MCU` (**the Teensy's own 3.3 V rail**). On
  Teensy-USB power alone VCC = 0 and the board shows the *identical* "no ACK" symptom.
  That is not a fault — do not "fix" it.
* **Incoming inspection of `U21` BEFORE power-up.** Read the top marking and compare it
  with TI's *Device Marking* column in the Package Option Addendum for
  `TCAN1042HGVDRQ1`; photograph it into `logs/`. **Mismatch = reject the part.**
  The part is substituted at your peril: the **`V` suffix is mandatory** (it *is* the VIO
  pin). `TCAN1042DRQ1` / `TCAN1042HDRQ1` / `TCAN1042GDRQ1` have **pin 5 = NC**, so RXD
  would swing to 5 V and **destroy Teensy pin 23**. Never accept an SN65HVD23x, a plain
  `TJA1051T` (no `/3`), a `TJA1050`, or any "pin-compatible" clone for U21.
  Approved alternates, only: `TCAN1042VDRQ1`, then NXP `TJA1051T/3/1J` (its pin 8 `S`
  likewise goes to GND).

### 1. DC levels (with J1 powered and the Teensy seated)

| Point | Expected | Fail signature |
|---|---|---|
| U21 pin 3 (VCC) | **5.0 V** | 3.3 V / 0 V = wrong supply (the original bench bug) |
| U21 pin 5 (VIO) | **3.3 V** | **~2 V = VIO floating / phantom-fed by TXD** — reject |
| U21 pin 8 (STB) | **0 V** | non-zero = standby, receive-only, never ACKs |

### 2. Termination (everything unpowered)

Measure `CANH-CANL` at `J14`: about **60 Ω** with the ECU connected and the `JP2` shunt
fitted at the bus end (120.8 Ω here in parallel with the ECU's 120 Ω); a lone fitted shunt
reads about **120 Ω**.

### 3. Functional tests that cannot be fooled

With a **CANable 2.5** running slcan (Elmue firmware), **error reports on** (`ME`), on the
same bus:

1. **Single-frame ACK test (decisive).** Have the CANable send **one** frame. The logger's
   `CANDIAG total` must rise by **exactly 1**, and the CANable must report **no** `E?3……`
   (protocol error 3 = No ACK). Thousands = no ACK = **FAIL**. (On the old module the chip
   had no dominant time-out; on Rev F the TCAN1042 does — see §4.)
2. **Feed test.** A 100 Hz bench feed must read **≈200 frames/s** on `CANDIAG`, listing
   **both `0x700` and `0x701`**, with `oil`/`afr`/`batt` ≠ `-1` and roughly **0 %
   duplicates**. **~3,800 frames/s is a retransmit storm and is a FAIL**, even though it
   superficially looks like "receiving fine".
3. **Transmit test.** Teensy USB `CANTX,10` must deliver 10 frames the CANable receives
   **exactly once each**, with the Teensy transmit-error counter (`TXerr`) staying **0**.

### 4. Diagnostics that are NOT valid pass criteria on Rev F

* Firmware `CANDRIVE` / `CANPROBE` "TX PATH OK" — an internal TXD→RXD echo passes it
  (that echo is *why* the old module fooled every self-test).
* The bench console's "fps ≥ 50 → ACKING" verdict — a 3,800/s storm passes it.
* `CANHOLDON` + a multimeter on `CANH-CANL`: the Rev F **TCAN1042 TXD dominant time-out
  (~1 ms) releases the bus**, so a perfectly healthy board reads ≈0 V. It was only ever a
  valid test on the old module because that chip had no time-out.

Only then connect a real vehicle bus. These are bench acceptance criteria, not automotive
transient qualification.

---

Record instrument readings, ambient conditions, firmware identity, observed faults
and modifications. A passed software test or a green ERC/DRC report is not a
substitute for these measurements.

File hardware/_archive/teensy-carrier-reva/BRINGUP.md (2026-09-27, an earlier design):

# Rev A bring-up — no expensive boards connected first

**Never use a finger as a temperature probe.** If a part heats rapidly, smells, or
the supply unexpectedly enters current limit, switch off immediately. Do not keep
cycling power, press recovery buttons, or flash firmware to diagnose a hot chip.
Use an IR camera/thermometer or insulated contact probe. Let parts cool first.
Current limiting reduces fault energy; it does not guarantee protection from an
incorrect voltage, reverse polarity, or a semiconductor fault.

## 0. Tools and preparation

- Adjustable **current-limited bench supply**, 0–20 V or greater; NOT the car battery
  for first tests. A bare car battery can source destructive currents into mistakes.
- Multimeter, preferably oscilloscope, temperature probe, and suitable electronic
  load or resistor loads with safe heatsinking. Keep 25 W loads away from flammables.
- Regulator/screen/Teensy manufacturer pinouts, printed 1:1 assembly drawing.
- Remove all USB leads, the Teensy, external modules and screen cable. JP1 OPEN.
- Compare populated board to BOM and polarity drawings. Verify every connector's
  square pad/pin 1, not just the wire colour. No frayed strands or solder bridges.

## 1. Unpowered checks

1. Check J1/J2 pin order end-to-end through the actual harness. Verify J2 pin 2 ends
   at **screen +5V_IN on its verified J10**, not any 3V3_OUT terminal.
2. Check polarity of C1/C2 and D2; confirm U2 top-view orientation and both header
   rows. Confirm U3 pins 1/2/3 VIN/GND/VOUT and that its input is U2 VRP.
3. Confirm F1/F2 continuity and JP1 open. Confirm no solder bridge between AUX 3V3
   and MCU 3V3 or between either of those and the 5 V output.
4. Measure resistance from each supply net to GND: VIN_FUSED, 5V_MAIN, 5V_SCREEN,
   3V3_AUX and MCU 3V3. Capacitors can make the first reading low then rising.
   **There is no universal ohms threshold proving a CPU dead.** A sustained near-
   zero reading requires isolating the affected part/net before power is applied.
5. Check mounting screws/spacers cannot touch tracks or components under the modules.

## 2. Power section only — JP1 open; no peripherals

1. Set disconnected supply to **12.0 V**, confirm voltage/polarity with a meter,
   set a **100 mA starting input-current limit**, then switch its output OFF.
2. Connect J1 positive/negative. Enable power while watching current. Converter
   startup may briefly hit a low limit, but sustained limiting or a low output
   requires investigation, not blindly increasing the current limit.
3. Measure, referenced to TP1/GND:
   - TP2 / VIN_FUSED: about 12 V, positive.
   - U2 VRP / U3 input: close to input voltage, after reverse protection.
   - TP3 / +5V_MAIN: nominal **5 V**, within the module's published tolerance.
   - J2 pin 2 / +5V_SCREEN: nominal **5 V** after F2.
   - TP4 / +3V3_AUX: nominal **3.3 V** within U3 tolerance.
   - MCU VIN side of JP1 and TP5 / MCU 3V3: **unpowered** at this stage.
4. Check temperatures with an instrument and observe several minutes at no load.
   No rapidly heating logic device is acceptable. A switching module can be warm;
   compare with its datasheet, not an assumed universal temperature limit.
5. Turn OFF and discharge before changing wires. Repeat unloaded checks at 10 V
   and 20 V. Never test reverse polarity by deliberately risking attached boards.

## 3. Load tests — dummy loads, NOT the screen

- At 12 V input, start with a modest 5 V load, e.g. **10 Ω / >=5 W** (~0.5 A,
  2.5 W dissipation; the resistor will get hot). Raise the input current limit only
  after correct voltage, polarity, assembly and the expected load are confirmed.
- Increase load in steps, observing output voltage, input current, ripple, startup
  and temperature. With 25 W output at 10 V input, input current is roughly
  **2.8–3.2 A**, depending on efficiency, plus the separate AUX-regulator load.
- Test the **main rail** at 5 A with a proper rated fixture connected to the wide
  main bus/module output, not tiny test-pad wires. J2's 4 A fast fuse is not meant
  to pass a 5 A test. Do not bypass the fuse to make it pass. Use a qualified bench
  setup for high-current testing; the small test points are for measurements.
- Test the actual screen branch up to the measured intended screen current (below
  4 A, allowing startup margin). Test AUX initially to <=500 mA combined.
- Repeat at 10, 14.4 and 20 V; evaluate in the intended enclosure/ambient. Stop if
  voltage droops, a connector/neck gets too hot, oscillation/ripple is excessive,
  the fuse opens unexpectedly, or regulator thermal limiting starts.
- Check a long cable with a **remote load**: measure at its far end. Calculate
  voltage loss with the real wire gauge/length. Do not infer it from the source's
  display. This is also needed at screen startup and maximum brightness.
- Do NOT perform load-dump/EMC tests with ad-hoc battery switching. Proper automotive
  qualification needs specified waveforms, energy limits and suitable equipment.

## 4. Teensy alone

1. All supplies OFF. Keep GPS, IMU, opto, CAN, Ethernet and screen disconnected.
2. **Cut the Teensy 4.1 VUSB-to-VIN bridge** following PJRC's underside drawing.
   Inspect and verify the intended copper link is physically open. Do not cut by
   guessing from an upside-down photograph. Other circuit paths can affect an ohm
   reading; use the manufacturer procedure and isolate power sources.
3. Fit the Teensy in the two sockets, USB at the marked end. Confirm no one-pin
   offset. Fit JP1 only now. D2's drop means VIN will be slightly below main 5 V;
   it must remain in the Teensy's specified VIN range.
4. Start at 12 V with a modest ~200 mA input-current limit for the MCU-only stage;
   if startup or draw is abnormal, switch off and investigate. The expected input
   current is not the same as the Teensy's 5 V current because of the converter.
5. Verify MCU 3V3 with a meter, then firmware/USB enumeration and die-temperature
   telemetry. A normal die reading does not certify every other component is cool.
6. Once the VUSB/VIN isolation is verified, keep carrier power on as required while
   attaching USB for programming. With the bridge cut, USB alone no longer powers
   VIN. Do not feed an external 3.3 V source into the Teensy to compensate.

## 5. Modules, one at a time

All wiring changes with all power OFF; re-check current/temperature after each step.

- GPS: verify its exact VCC input permits J4's 3.3 V and its UART is 3.3 V logic.
  Cross TX/RX per README. Verify real PVT sample rate and fix acquisition. Do not
  promise M10/F10 plug-and-play without a firmware compatibility test.
- IMU: verify 18 SDA / 19 SCL, AD0 GND; check at-rest g magnitude and gyro readings.
- Tach: default is open collector into J3, output-side emitter to carrier GND.
  Check with an oscilloscope: idle ~3.3 V, pulses near 0 V, no negative/12 V spikes.
  Then confirm RPM on pin 9. Never use the raw ignition coil as a test source.
- CAN: J6 to a 3.3 V transceiver's LOGIC side; verify CANH/CANL and end termination
  on the external module before connecting to the ECU.
- Ethernet: verify the custom J7 cable against the exact W5500 breakout and ensure
  total AUX load stays within the commissioning budget.

## 6. Screen LAST

1. First measure all four cable conductors disconnected from the screen. Confirm
   +5 V is only on the power conductor and the grounds match.
2. On this particular **clone**, verify which connector truly accepts 5 V. Use its
   own documentation/pin labels/continuity measurements. Do not assume an Elecrow-
   looking connector is equivalent. If that cannot be established, STOP.
3. With both devices OFF, connect the verified screen J10: GND / +5V_IN /
   TXD0_H to carrier RX / RXD0_H to carrier TX. Use short bench wires first.
4. Observe supply draw and both ends' voltage on startup. Verify display, touch,
   telemetry, commands and long-duration uploads. Inspect serial errors, not just
   whether some characters arrive.
5. Test the full-length harness under realistic electrical conditions before a
   track session. Differential signalling is the next revision if TTL is unreliable.
6. Disconnect the Teensy UART from the screen before flashing the screen's CH340-
   shared UART0. Never run two push-pull transmitters onto that UART.

## Stop / release criteria

Do not install permanently until independent review, footprint fit, unloaded/load/
thermal/cable tests and an appropriate vehicle power-protection review are complete.
Log voltages, current, ambient and temperature with photos. A successful firmware
flash, a green LED, or a zero-DRC PCB is **not** proof of safe automotive hardware.

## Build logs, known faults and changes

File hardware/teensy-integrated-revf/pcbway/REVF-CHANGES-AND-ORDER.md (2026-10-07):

# Rev F — what changed, and what to order

**This replaces the Rev D quotation (`T-2SJ3W1113248A`) and the Rev E files.** The board
is the same size, the same 4 layers and the same process — **please re-quote the same
settings against the new Gerbers and BOM**, which are in this folder.

## 1. NEW: the CAN transceiver is ON THE BOARD (`J7` and its module are deleted)

On the bench the external module that was going to be fitted at `J7` **received but never
drove the bus**: it never ACKed, so the sender retransmitted ~3,800 identical frames/s.
**The root cause was NOT the transceiver concept — the module was mislabelled.** Sold as an
"SN65HVD230", it carries a **TJA1051T/3-class** chip (same footprint, different pins): pin 3
VCC needs **5 V** (the driver locks out below 4.5 V), pin 5 is **VIO** not Vref, pin 8 is
**S/standby**. Driven the SN65HVD230 way — VCC 3.3 V, pin 5 floating, pin 8 floating — the
driver was locked out and floating VIO was phantom-fed from TXD (~2.1 V), so RXD collapsed
whenever TXD went low; every Teensy-side self-test still looked like a working transmitter.
Rewired VCC 5 V / pin 5 3.3 V / pin 8 GND it ran at exactly 200 frames/s, both ids, 0
errors. Full analysis: `../../CAN-TRANSCEIVER-FINDINGS-2026-10-04.md`.

**Delete `J7` and do not fit any CAN module.** A plug-in board can carry the wrong chip and
be wired three ways wrong; the soldered transceiver below has its supplies and mode pin
hard-wired, so none of that can happen.

| Ref | Function | MPN | Manufacturer |
|---|---|---|---|
| U21 | CAN transceiver, VIO = 3.3 V, ±70 V bus fault, SOIC-8 | `TCAN1042HGVDRQ1` | Texas Instruments |
| D25 | Dual CAN bus TVS, SOT-23 | `NUP2105LT1G` | onsemi |
| J14 | CAN field terminal, 3-pos 5.08 mm (same family as J4/J11/J12) | `1729021` | Phoenix Contact |
| JP2 | CAN termination jumper, 2-pin (Samtec TSW-102 + shunt, as JP1) | `TSW-102-07-G-S` | Samtec |
| R58 R59 | Split-termination legs, 60.4 Ω 1 % 0805 | `RC0805FR-0760R4L` | Yageo |
| C49 C50 | 100 nF X7R 0805 decoupling at VCC / VIO | `GRM21BR71H104KA01L` | Murata |
| C51 | 1 µF 0805 bulk on VCC | `GRM21BR71H105KA12L` | Murata |
| C52 | 4.7 nF 50 V X7R 0805, termination midpoint | `CL21B472KBANNNC` | Samsung |

`U21` pin 8 (`STB`) is tied **directly to GND with no resistor** — `STB` high is standby /
receive-only, never ACKs. `J14` is **1 CANH / 2 CANL /
3 GND**. The split termination (`R58`+`R59` = 120.8 Ω across the pair, `C52` from the
midpoint to GND) is enabled by the `JP2` shunt and **must only be fitted when this board
is an end of the bus**. `TP6`/`TP7` are `CAN_TX`/`CAN_RX` test points, and the former
CAN-module header `J7` is gone from the Gerbers, CPL and BOM.

Orderable alternates for U21, in order: `TCAN1042VDRQ1`, then NXP `TJA1051T/3/1J` (its
pin 8 `S` must also go to GND).

⚠️ **No unapproved substitution of U21.** Order `TCAN1042HGVDRQ1` from **authorized
distribution only** (TI / Mouser / Digi-Key / LCSC-original) and do **not** substitute
without written approval — no clones, no re-marked parts. The **`V` suffix is mandatory**:
`TCAN1042DRQ1` / `TCAN1042HDRQ1` / `TCAN1042GDRQ1` have **pin 5 = NC**, which puts 5 V on
Teensy pin 23 and destroys it. **Never** an SN65HVD23x, a plain `TJA1051T` (no `/3`), a
`TJA1050`, or any "pin-compatible" equivalent.

This applies because the bench failure was a **mislabelled part** (a TJA1051T/3-class chip
sold as an SN65HVD230): correct marking is the whole defence here.

All eight new lines are standard **LCSC / TI / onsemi / Phoenix Contact / Samtec / Yageo /
Murata / Samsung** stock parts — no consignment and no customer-supplied module, exactly
like the rest of the board.

## 2. The Pololu module is GONE (this removes both sourcing problems you reported)

U2 is no longer a Pololu `4091 / D36V50F5` module and no socket is needed.
**Do not source or fit the Pololu 4091, and do not fit any socket at U2.**
It is replaced by a converter we designed from parts you can buy from stock:

| Ref | Function | MPN | Manufacturer |
|---|---|---|---|
| U2 | 5 V / 5 A buck regulator, 400 kHz | `TPS54560BDDAR` | Texas Instruments |
| L2 | 6.8 µH, 13.5 A sat / 8 A RMS shielded inductor | `IHLP4040DZER6R8M01` | Vishay |
| D23 | 5 A / 60 V catch diode (**SMB / DO-214AA only**) | `SS56` (BORN, SMB) — LCSC C2687867; alternate Diotec `SK56` | BORN |
| Q3 | P-channel reverse-polarity protection, 40 V, 15 mΩ | `AO4485` | Alpha & Omega |
| C41 C42 | 10 µF 50 V X7R 1210 input ceramics | `GRM32ER71H106KA12L` | Murata |
| C44 C45 C46 | 47 µF 16 V X5R 1210 output ceramics | `GRM32ER61C476KE15L` | Murata |
| D24 | 15 V gate clamp (SOT-23) | `BZX84C15` | Nexperia |
| R51–R57, C43, C47, C48 | passives | see BOM | — |

Everything is a standard LCSC/TI/Vishay/Murata part — **no consignment and no module
fitting.** U1 is unchanged: the assembly BOM asks for **two 1×24 sockets
(`SSW-124-01-G-S`)** — please source and fit those and **do NOT fit a Teensy** (the Teensy
4.1 is customer supplied, bought with pins, and plugs in). **Do not fit the JP1/JP2 shunts
or the CR2032 cell** either. Order settings and the full fit/no-fit list are in
`PCBWAY-ORDER-GUIDE.md`.

## 3. The car's input voltage is measured on the board

A sixth analog channel (a 180 k/20 k 0.1 % divider with its own 3.0 V shunt clamp and
filter, on the spare TMUX1511 switch) taps the protected car input. New refs R48, R49, R50,
D21, D22, C40 — all ordinary parts.

## 4. Other corrections already agreed

* **D5** = `PESD5V0F1BL,315` (your 09-30 quote reverted to the unavailable `PESD3V3U1UL,315` — please use the replacement).
* C10, C18, C11 substitutions as previously agreed; F3–F5 = `1206L010/60WR`; D2 = onsemi `SS14`.
* **Delete the two 1×24 male pin strips** (`TSW-124-07-G-S`) — we supply the Teensy with pins.
* U8 `NEO-M9N-00B`: please confirm the final price before production; genuine TRACO `TSR 1-2433` only.

## 5. Files in this folder

* `Racecar-RevF-PCBWAY-GERBERS.zip` — 16 files: 11 Gerbers, `Edge_Cuts`, PTH + NPTH drills
  with maps, and the job file. Board is **150.05 × 155.05 mm**, 4 layer, 1.6 mm, **1 oz outer**,
  ENIG, impedance control ON (50 Ω single-ended GNSS feed), green mask, white silk,
  **no panelisation** (connectors and a battery holder sit on the edges).
* `Racecar-RevF-BOM-pcbway-assembly.csv` — grouped BOM with designators.
* `Racecar-RevF-CPL.csv` — placement positions (Top layer, millimetres, Y already flipped to
  PCBWay's convention).
* `PCBWAY-ORDER-GUIDE.md` — **read this before quoting**: board settings, the fit/no-fit
  list for U1 / JP1 / JP2 / BT1 / J9, and the CAN notes.

## 6. Verification status (CAD only)

ERC **0**, DRC **0**, unconnected **0**, 749 pin/geometry/calculation assertions passed,
538 schematic↔PCB connected pads agree, 193 footprints / 104 nets / 1,647 routed segments
with 131 vias. This is a CAD check, **not** a physical or thermal validation, and it is not
an independent human review. The CAN interface in particular has never been built, measured
or reviewed, and no automotive transient qualification is claimed.

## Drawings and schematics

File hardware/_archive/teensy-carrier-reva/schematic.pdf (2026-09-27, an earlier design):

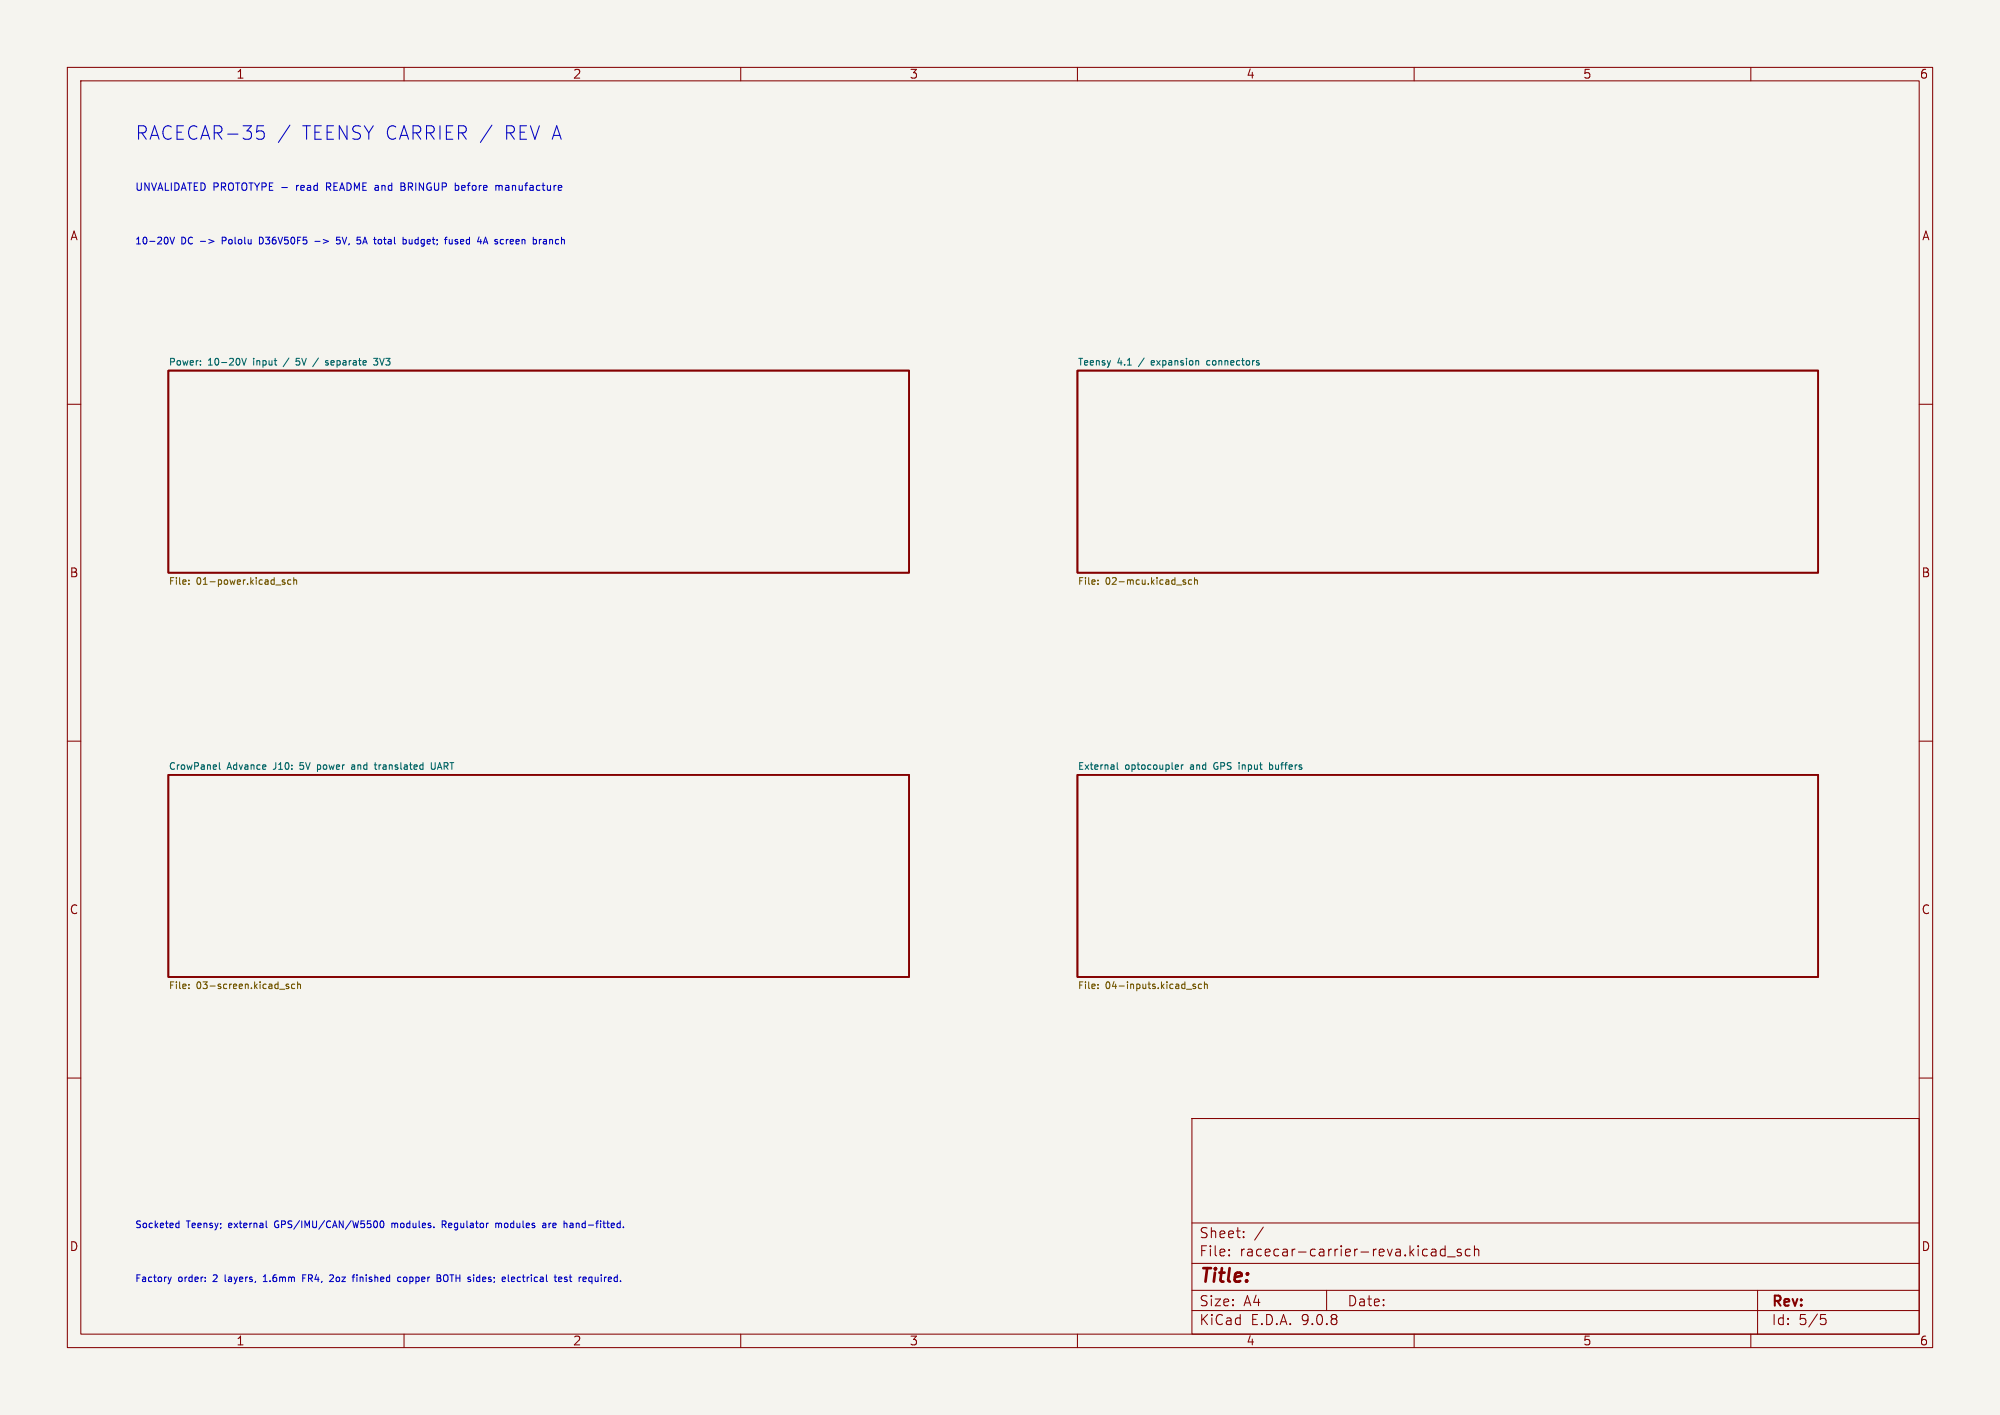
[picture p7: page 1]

UNVALIDATED PROTOTYPE - read README and BRINGUP before manufacture

Id: 5/5 Title: File: racecar-carrier-reva.kicad_sch Sheet: /

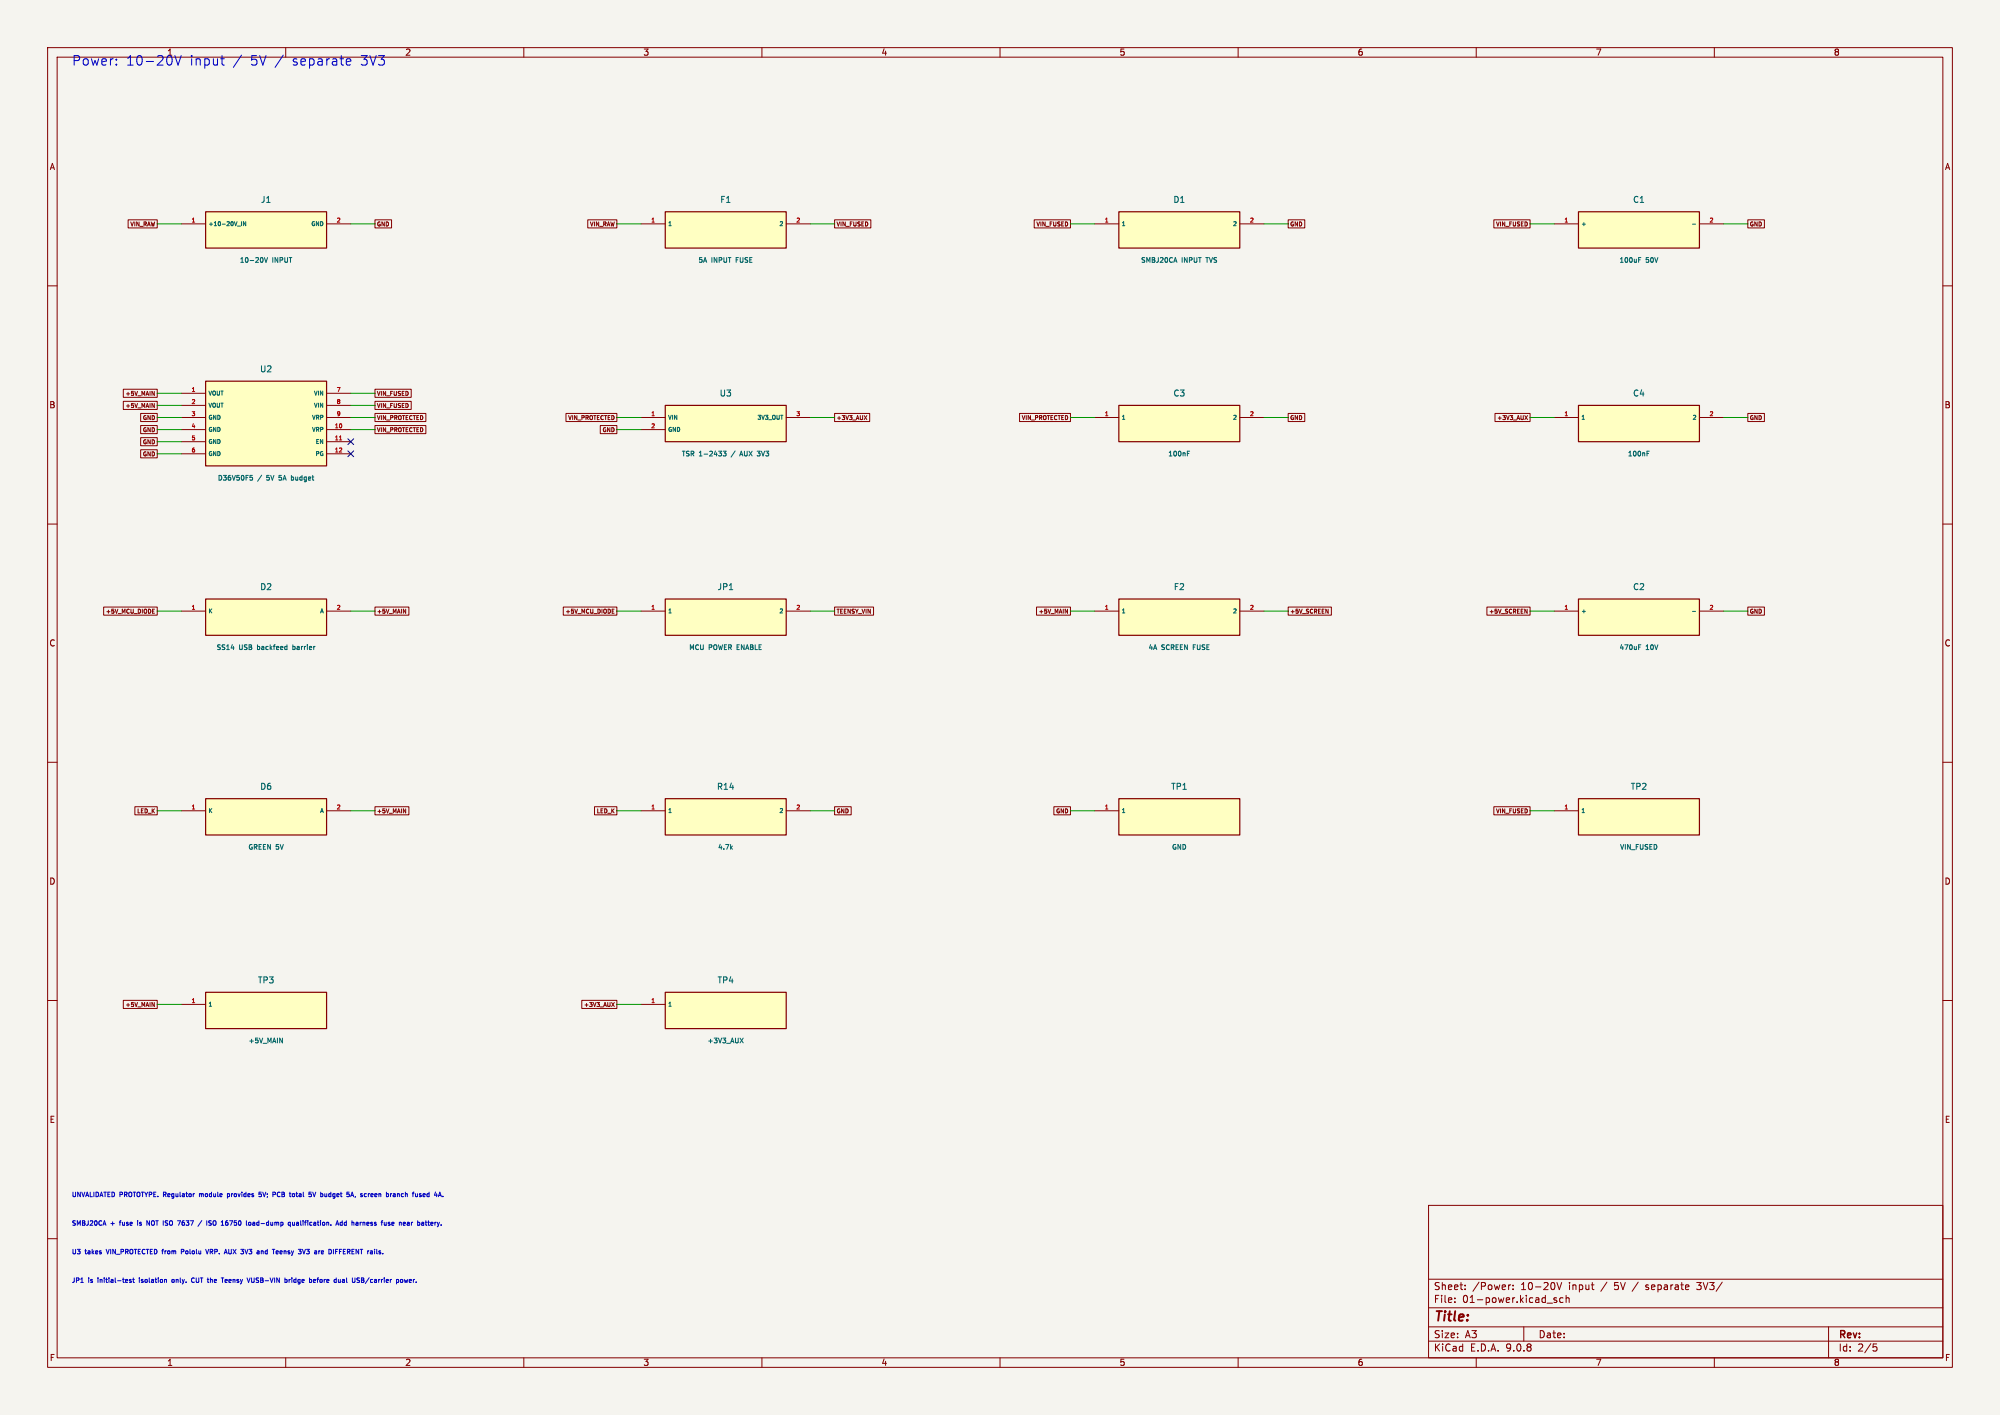
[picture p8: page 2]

+5V_MAIN U3 takes VIN_PROTECTED from Pololu VRP. AUX 3V3 and Teensy 3V3 are DIFFERENT rails.

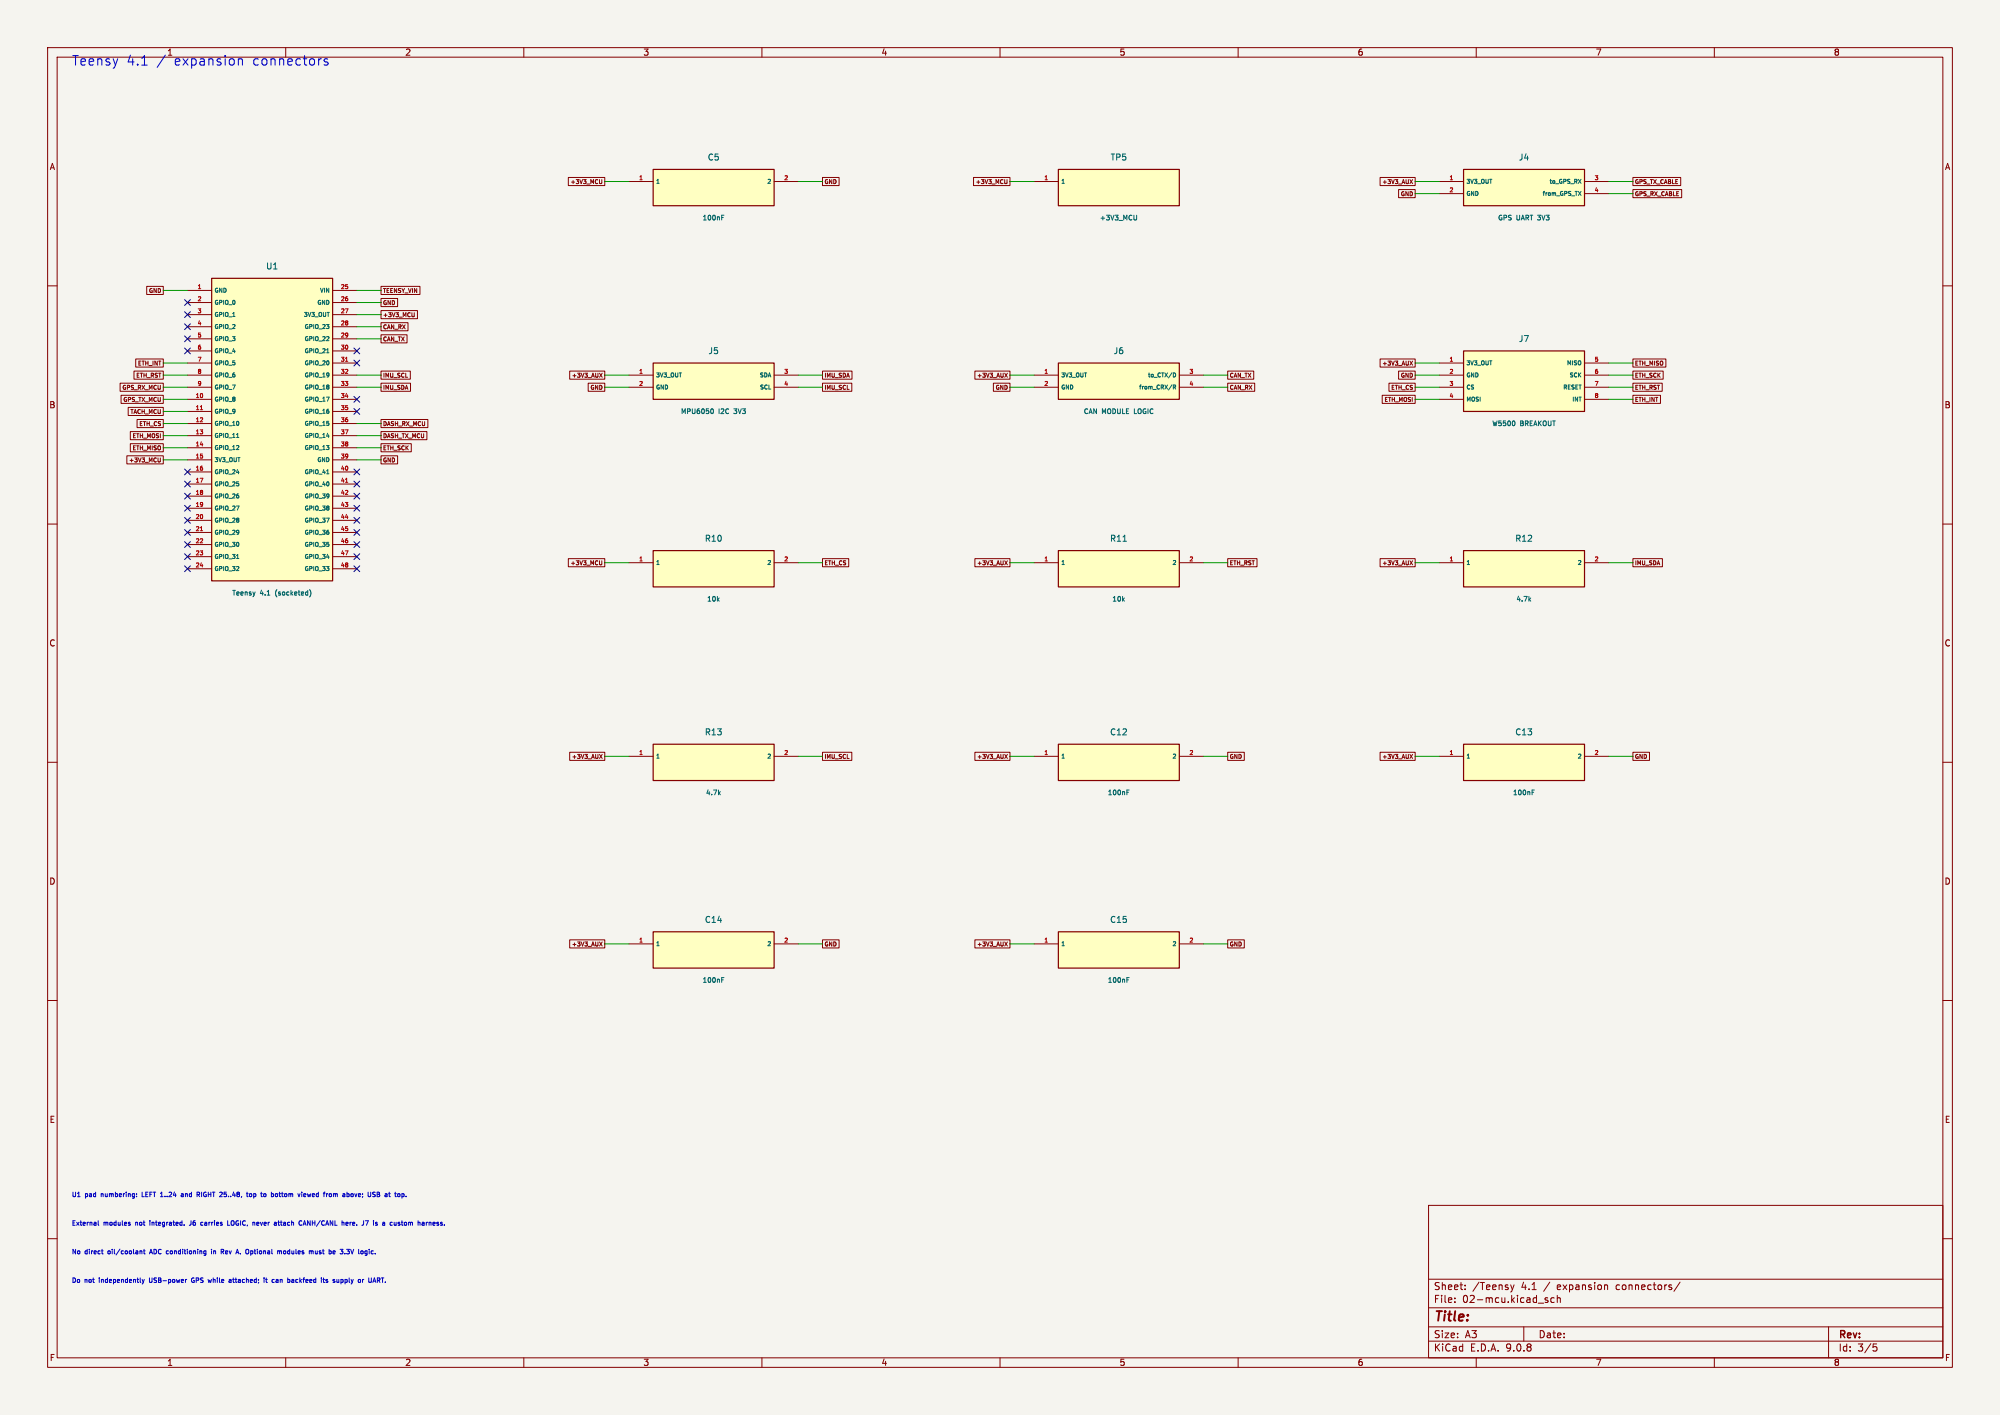
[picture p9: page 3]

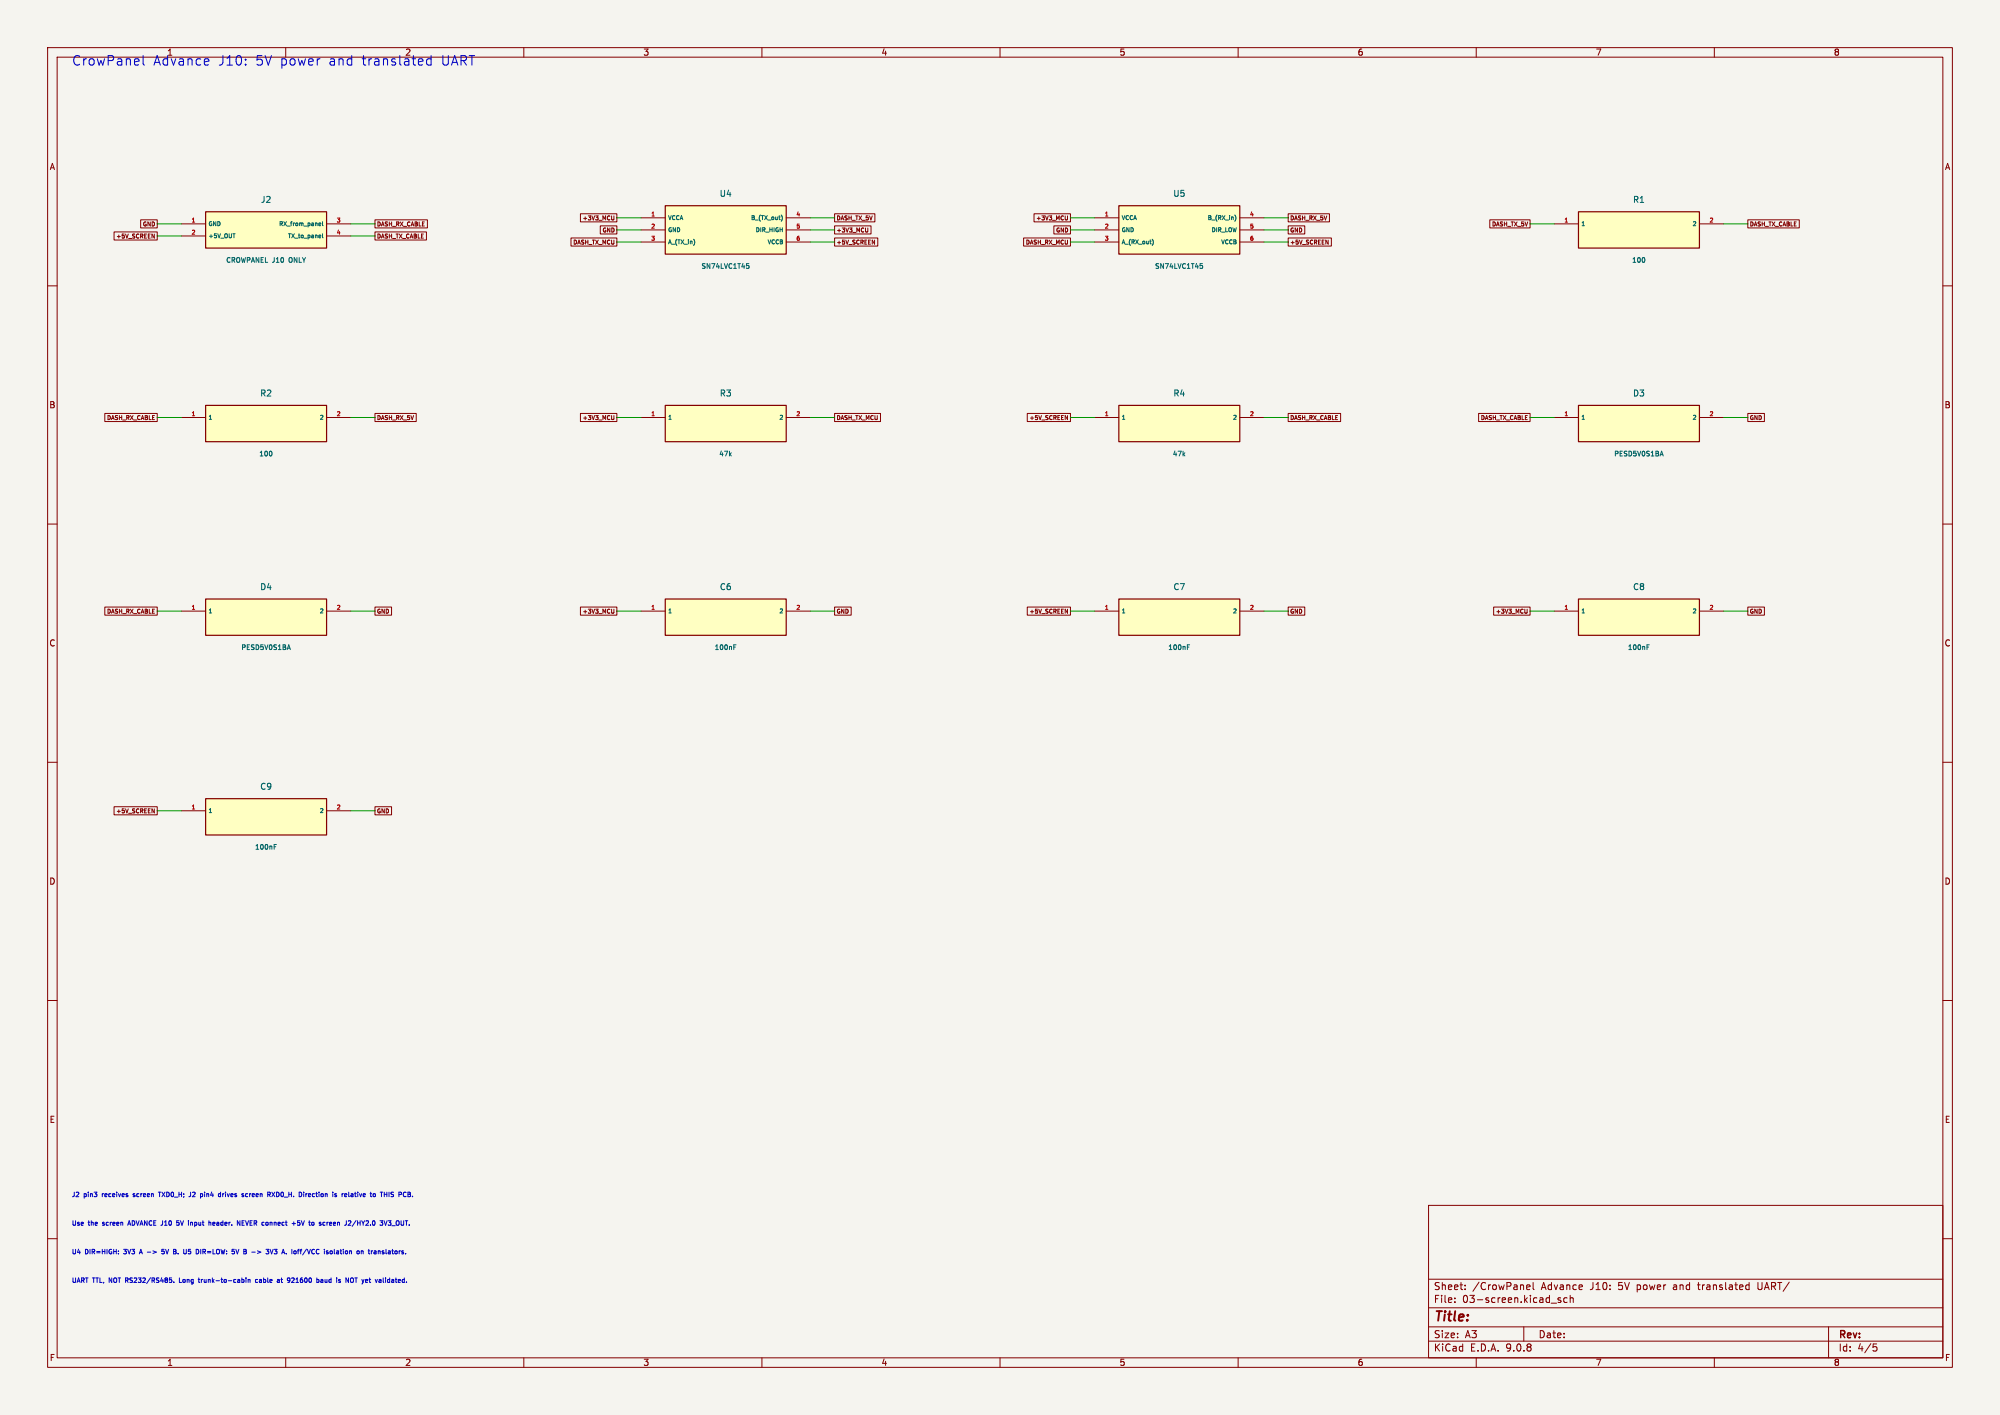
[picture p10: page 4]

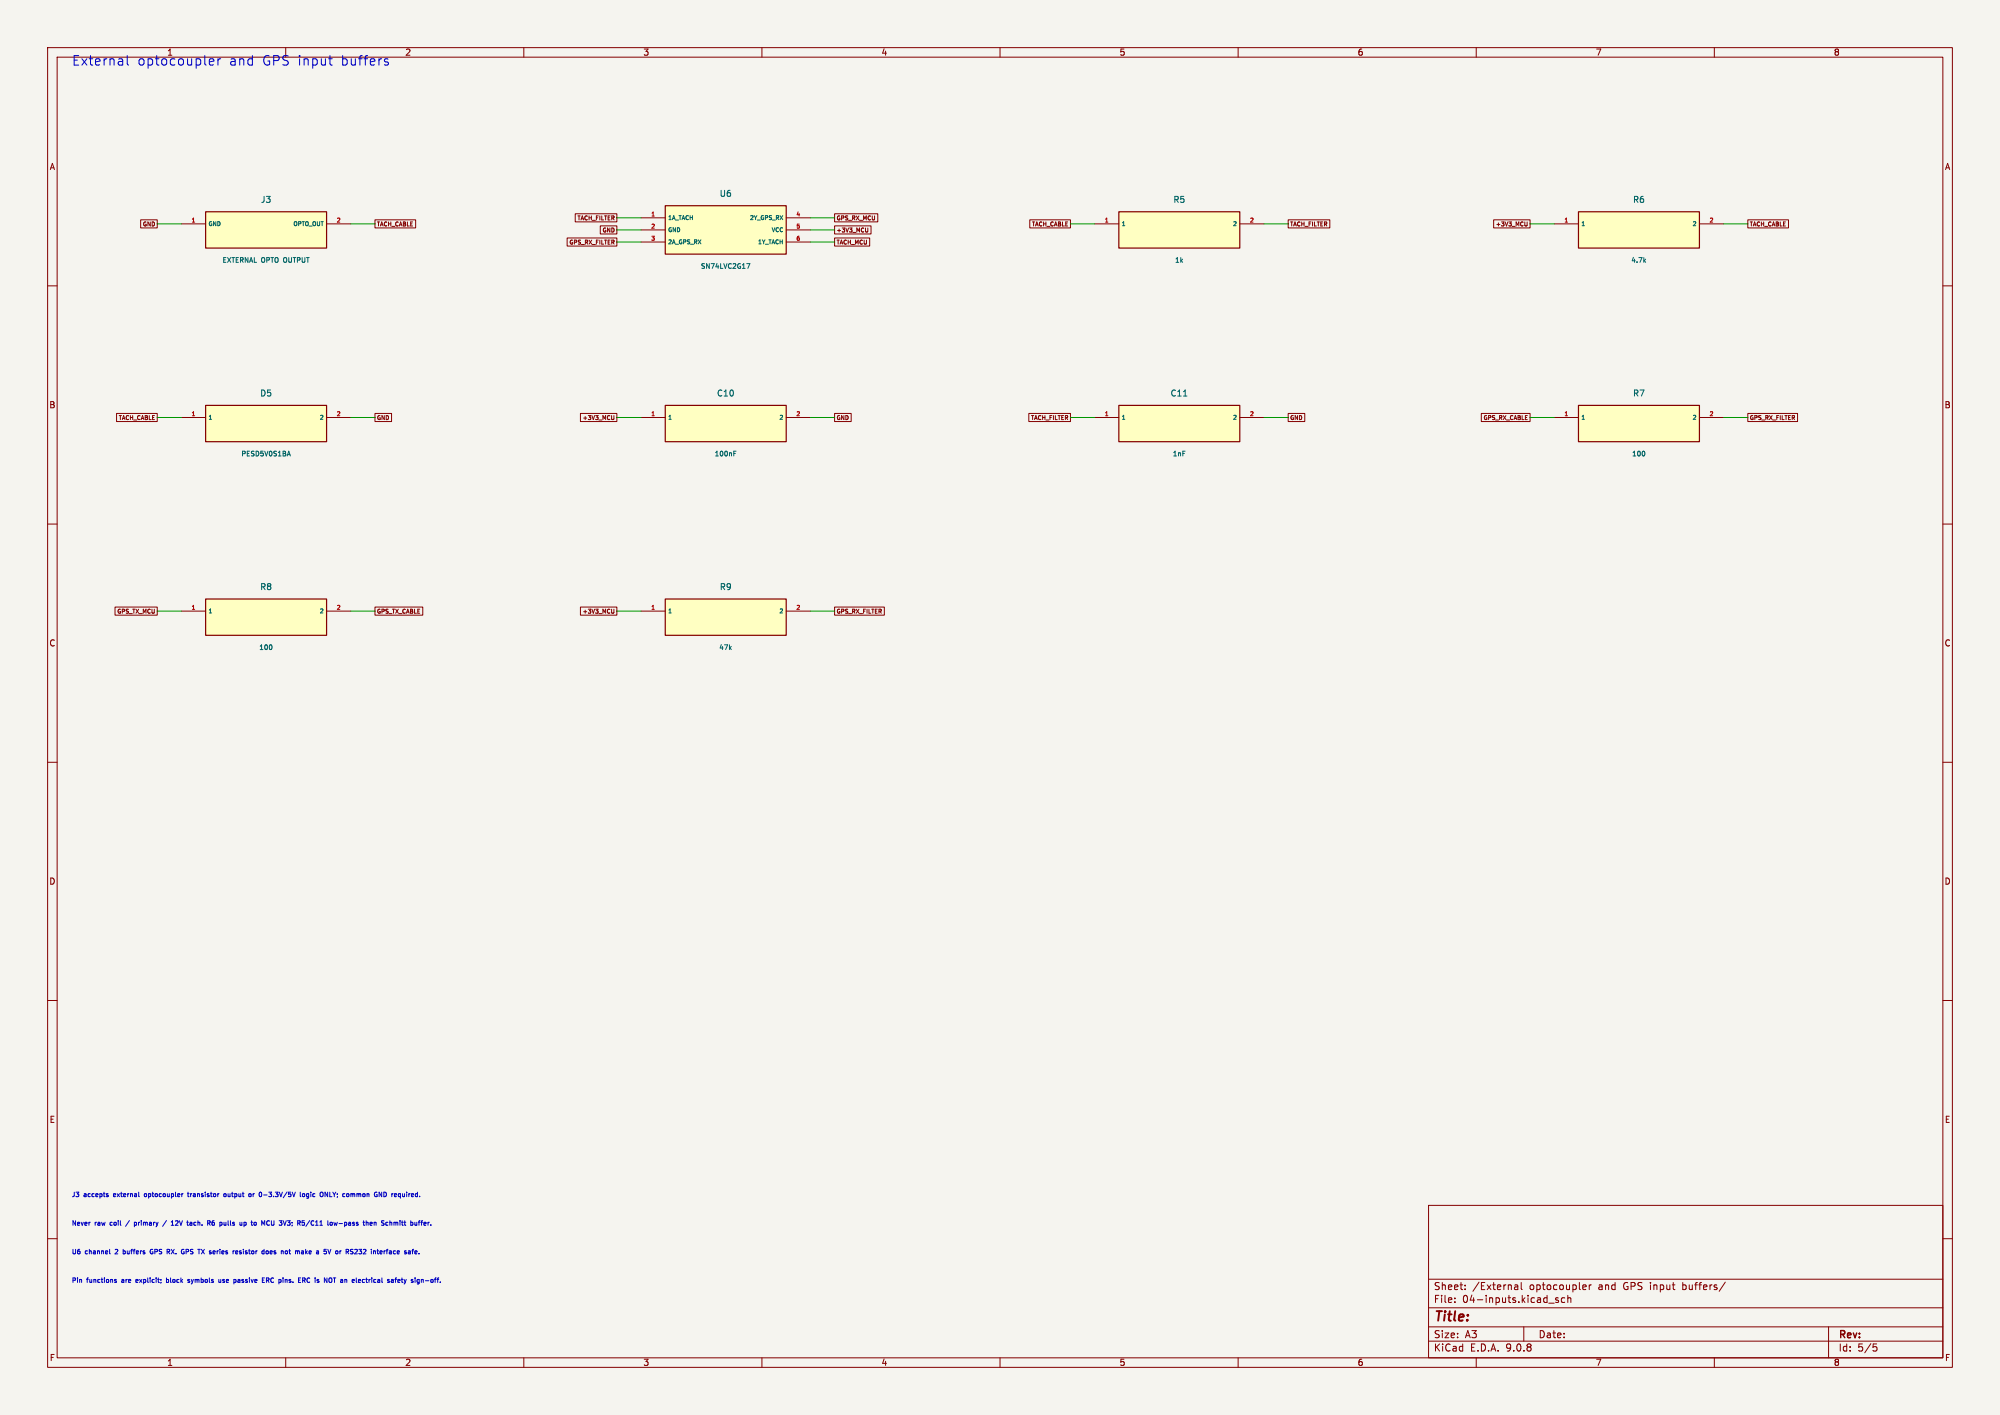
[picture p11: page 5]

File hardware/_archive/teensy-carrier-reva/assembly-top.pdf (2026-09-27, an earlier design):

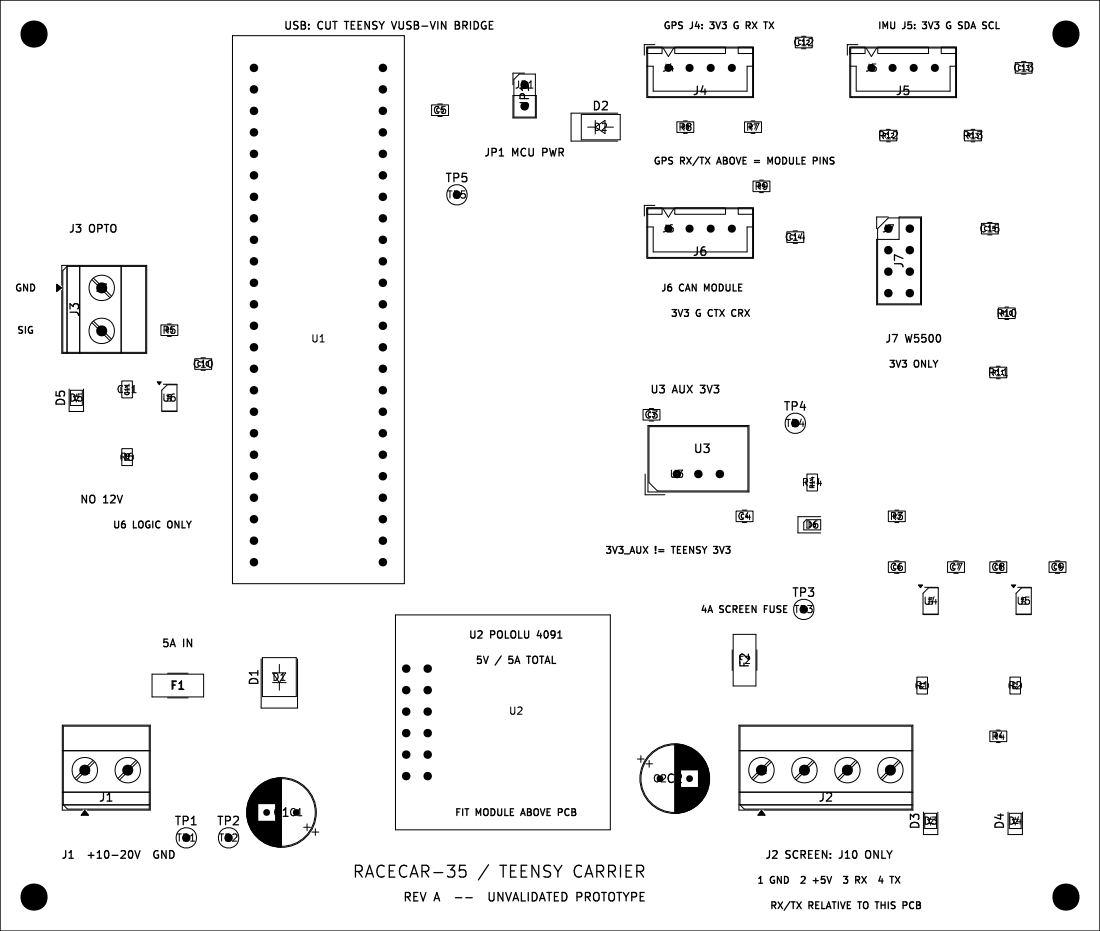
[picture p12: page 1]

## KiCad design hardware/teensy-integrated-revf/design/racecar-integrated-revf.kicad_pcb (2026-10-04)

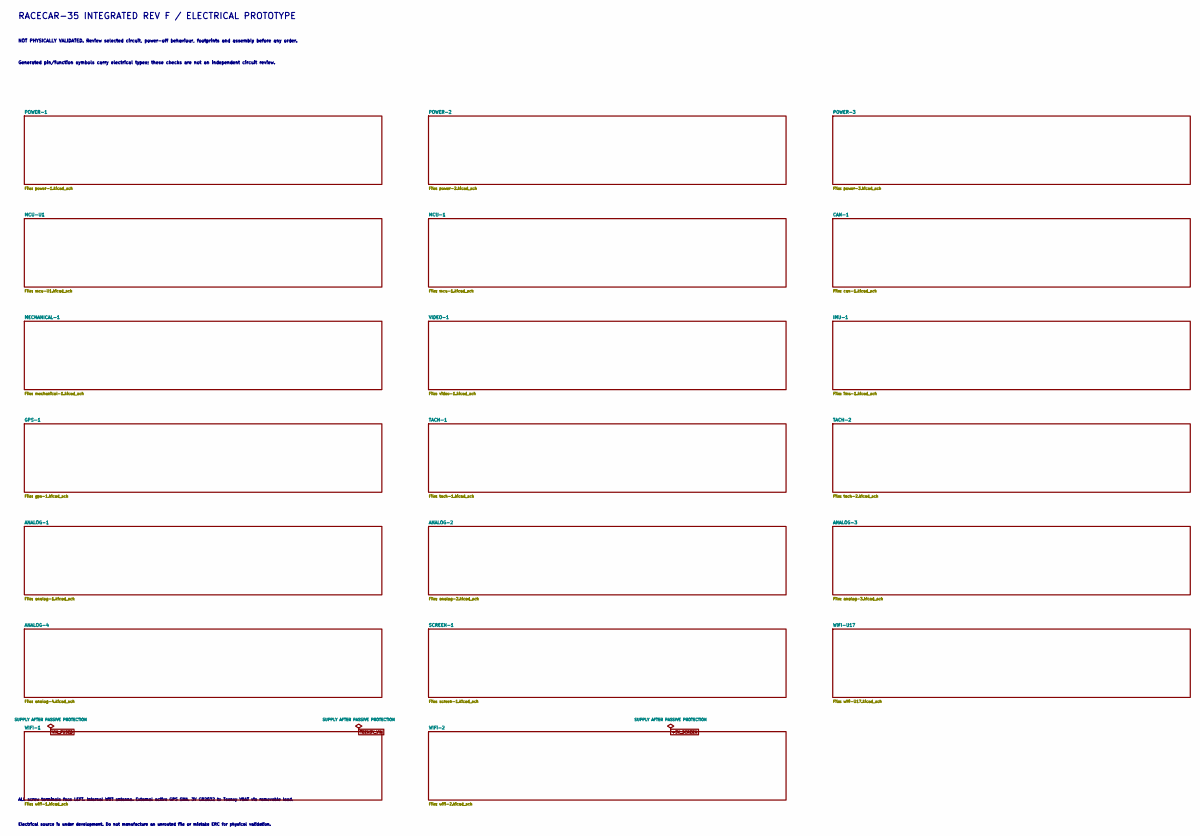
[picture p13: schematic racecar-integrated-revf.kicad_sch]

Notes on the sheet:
RACECAR-35 INTEGRATED REV F / ELECTRICAL PROTOTYPE
NOT PHYSICALLY VALIDATED. Review selected circuit, power-off behaviour, footprints and assembly before any order.
Generated pin/function symbols carry electrical types; these checks are not an independent circuit review.
ALL screw terminals face LEFT. Internal WiFi antenna. External active GPS SMA. 3V CR2032 to Teensy VBAT via removable lead.
Electrical source is under development. Do not manufacture an unrouted file or mistake ERC for physical validation.

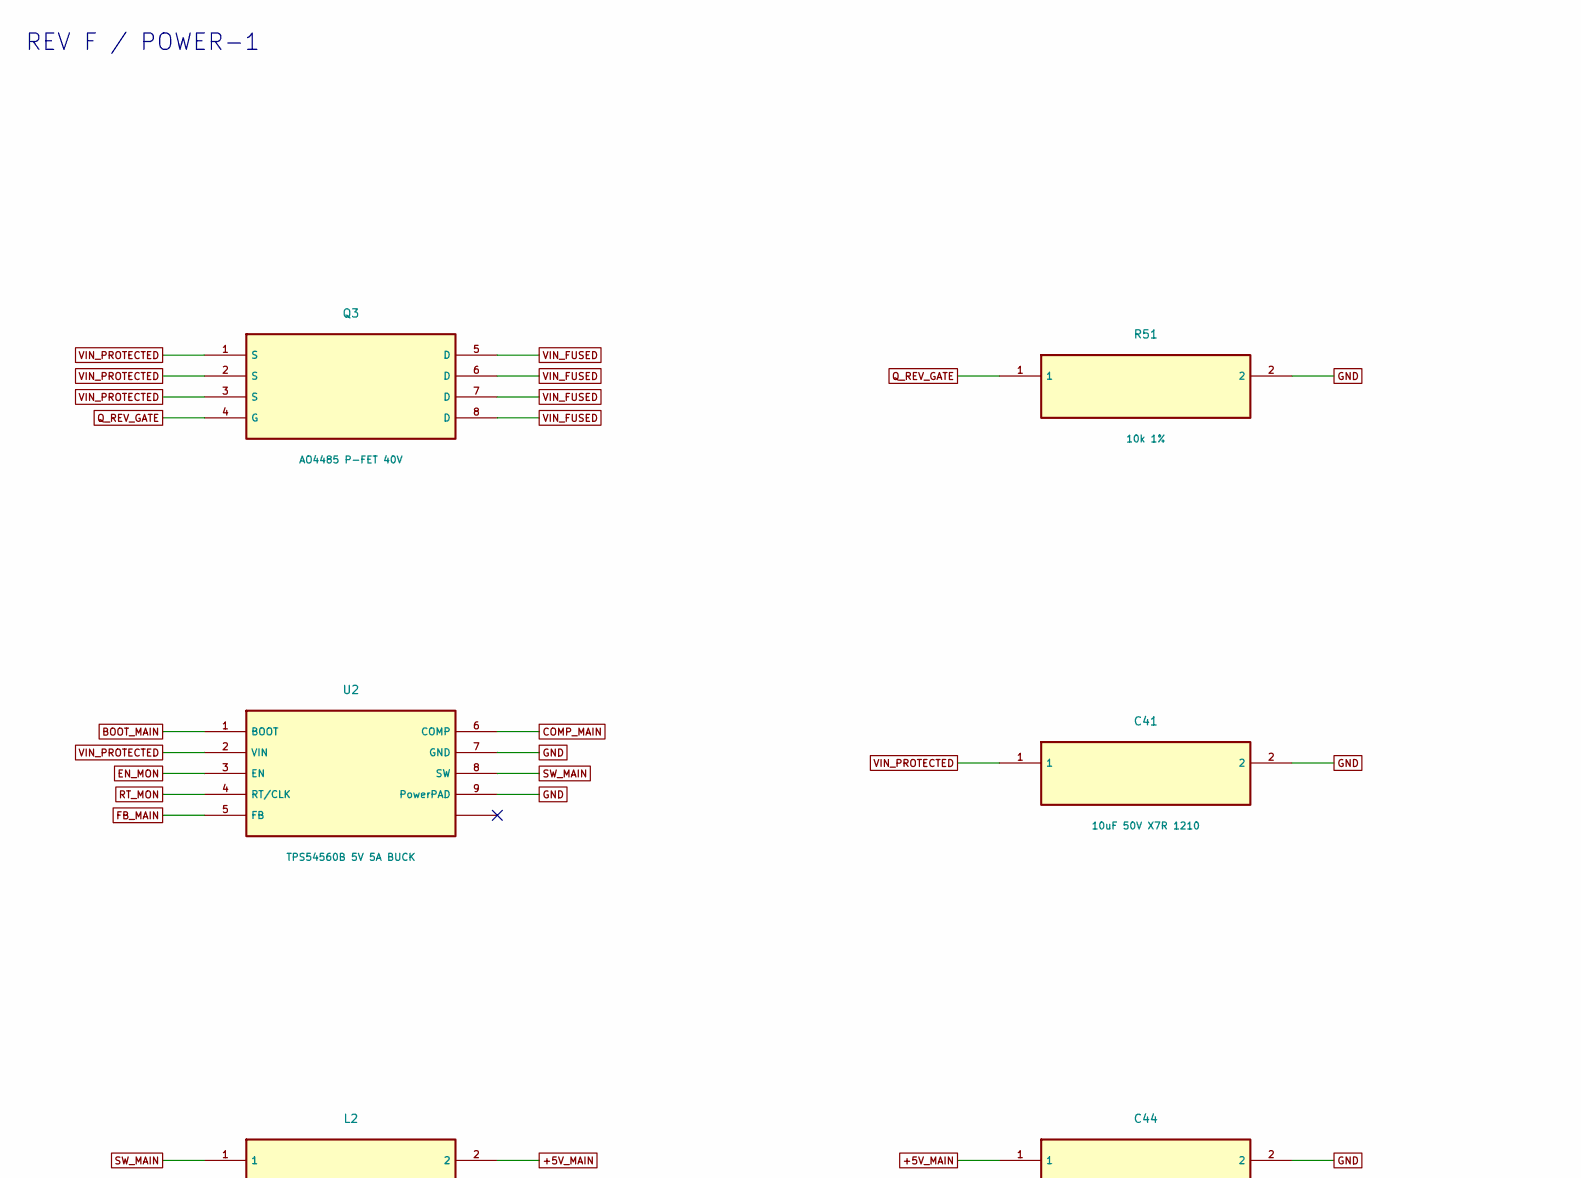
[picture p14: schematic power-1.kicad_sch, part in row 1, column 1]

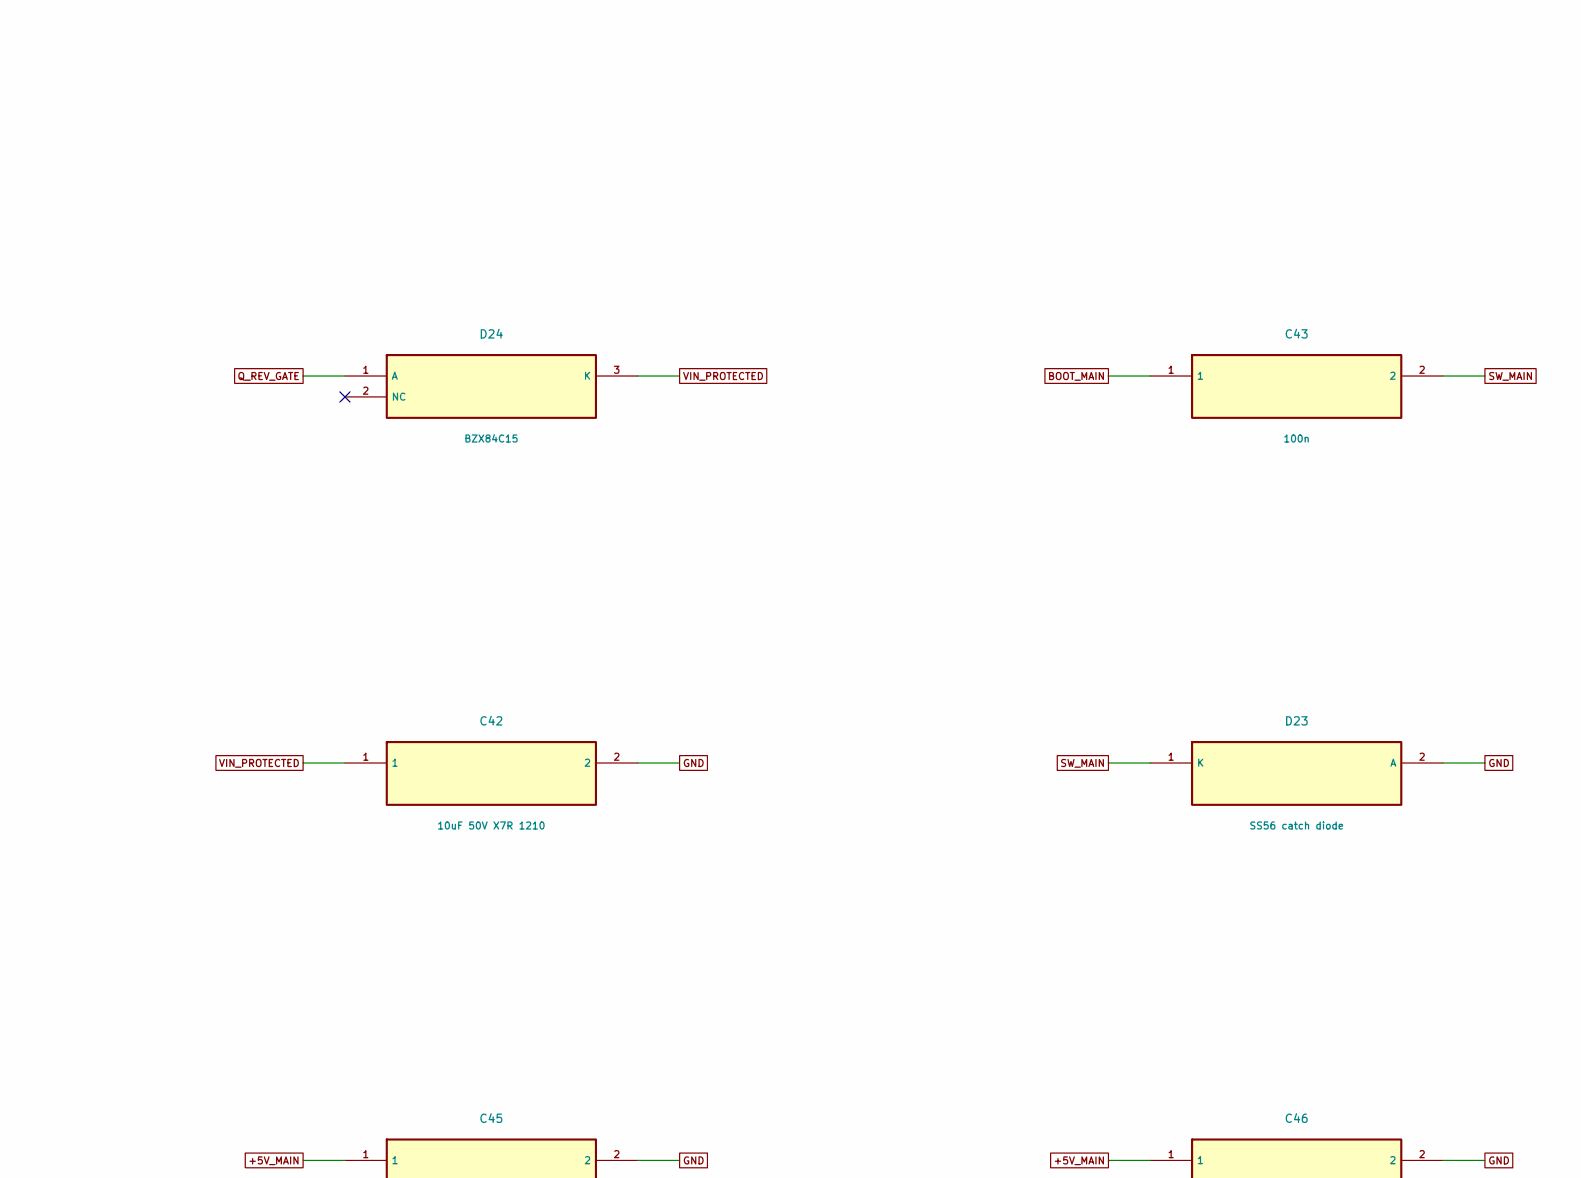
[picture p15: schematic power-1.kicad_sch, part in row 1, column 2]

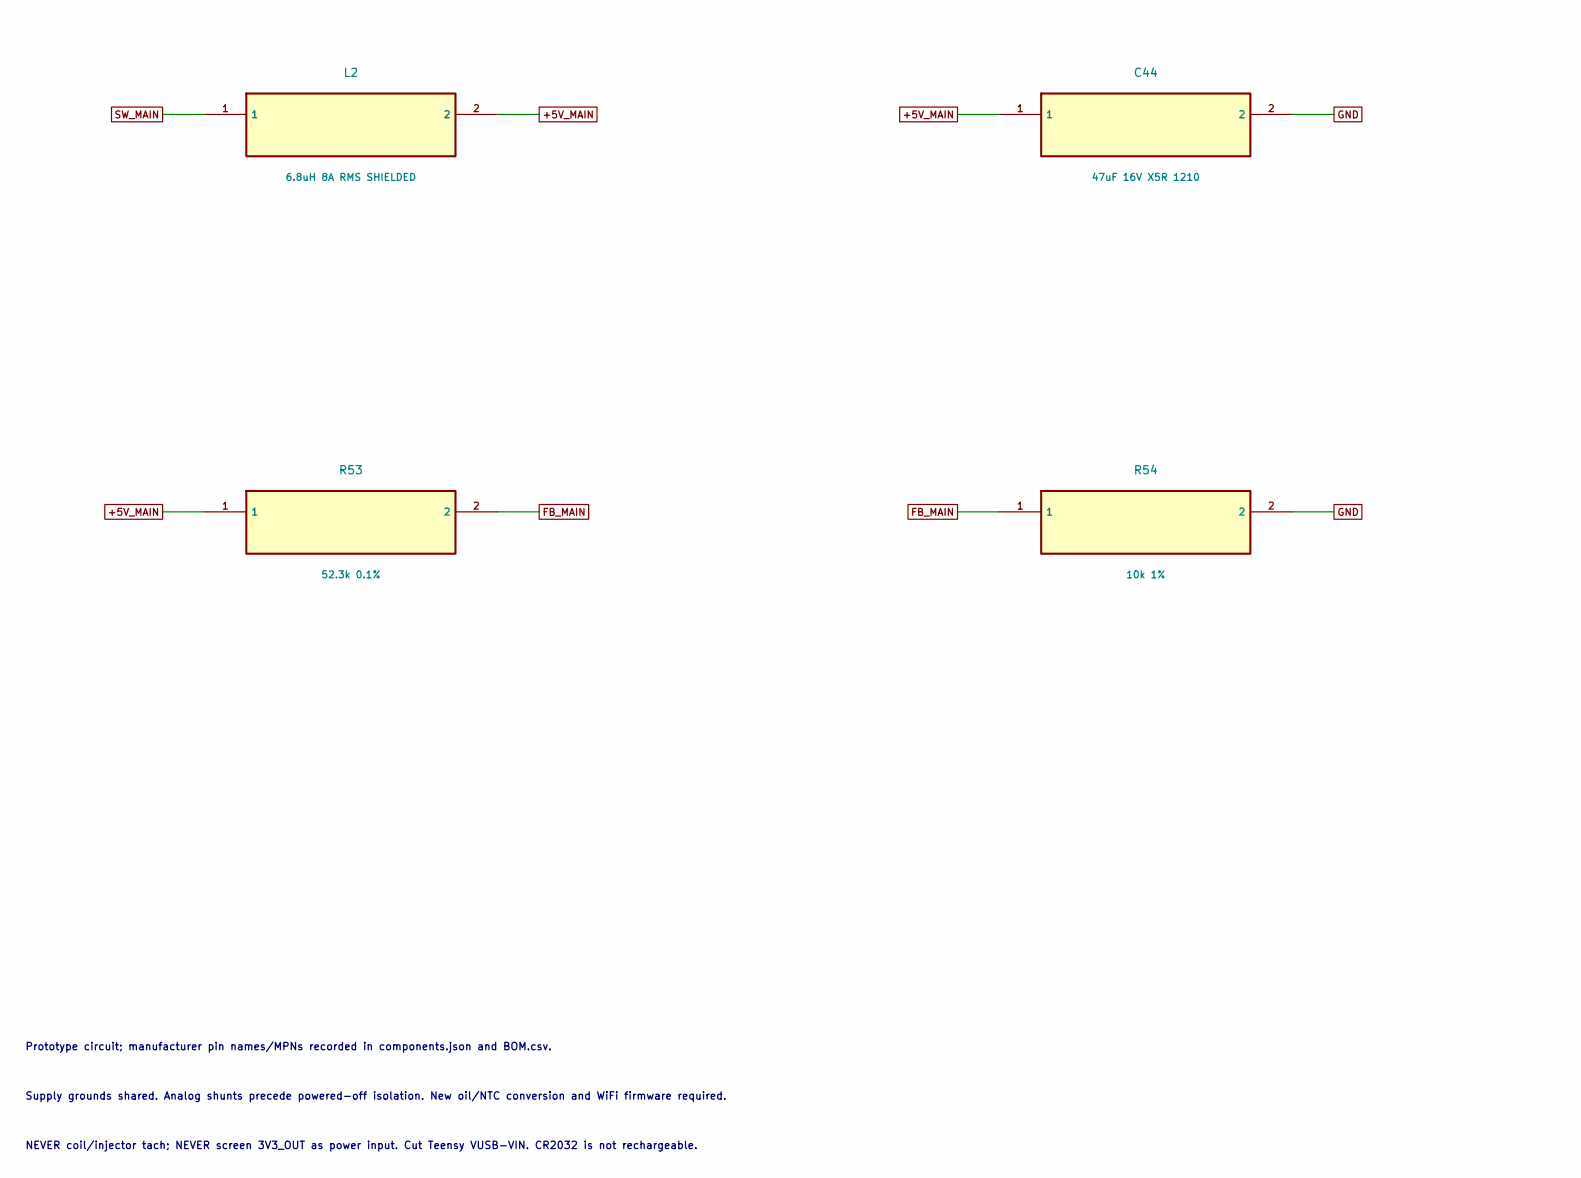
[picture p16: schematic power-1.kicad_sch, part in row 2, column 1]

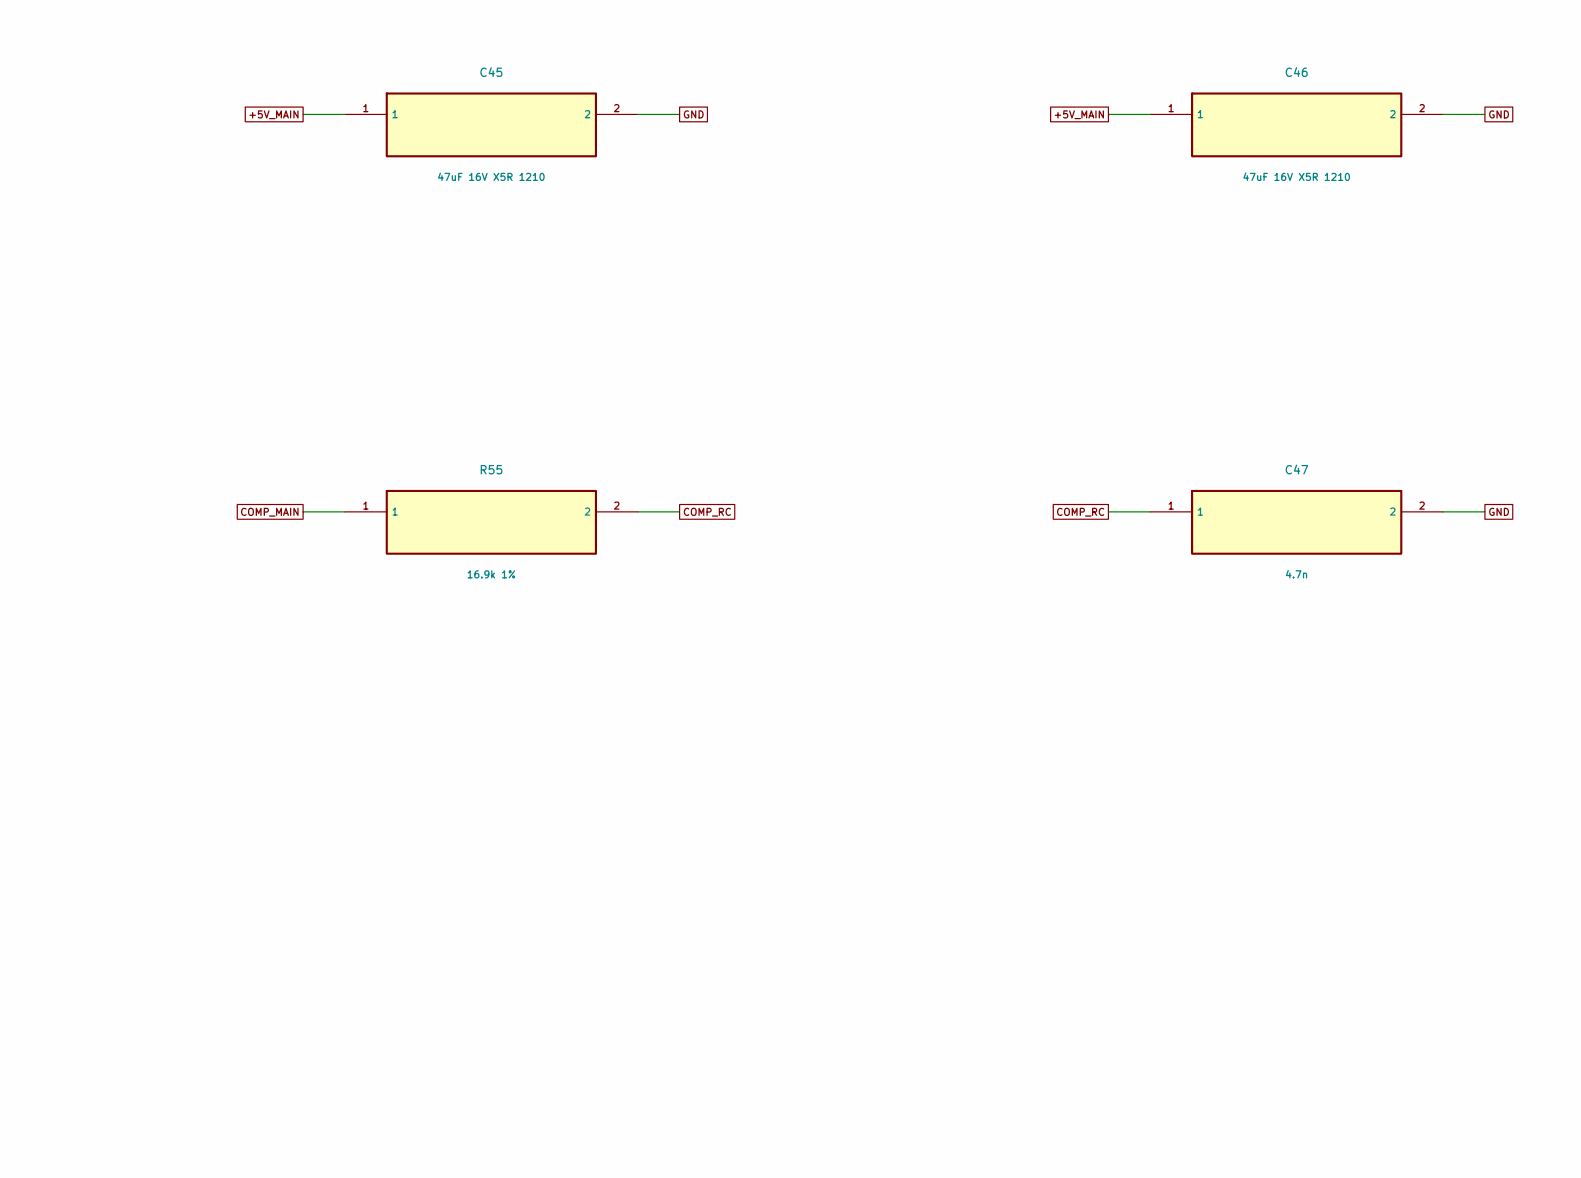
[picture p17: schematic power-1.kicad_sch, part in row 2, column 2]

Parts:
C41, C42: 10uF 50V X7R 1210; C_1210_3225Metric
C43: 100n; C_0805_2012Metric
C44, C45, C46: 47uF 16V X5R 1210; C_1210_3225Metric
C47: 4.7n; C_0805_2012Metric
D23: SS56 catch diode; D_SMB
D24: BZX84C15; SOT-23
L2: 6.8uH 8A RMS SHIELDED; L_Vishay_IHLP-4040
Q3: AO4485 P-FET 40V; SOIC-8_3.9x4.9mm_P1.27mm
R51, R54: 10k 1%; R_0805_2012Metric
R53: 52.3k 0.1%; R_0805_2012Metric
R55: 16.9k 1%; R_0805_2012Metric
U2: TPS54560B 5V 5A BUCK; SOIC-8-1EP_3.9x4.9mm_P1.27mm_EP2.41x3.3mm

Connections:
+5V_MAIN: C44.1, C45.1, C46.1, L2.2, R53.1; also elsewhere on the board
BOOT_MAIN: C43.1, U2.1 (BOOT)
COMP_MAIN: R55.1, U2.6 (COMP); also elsewhere on the board
COMP_RC: C47.1, R55.2
EN_MON: U2.3 (EN); also elsewhere on the board
FB_MAIN: R53.2, R54.1, U2.5 (FB)
GND: C41.2, C42.2, C44.2, C45.2, C46.2, C47.2, D23.2 (A), R51.2, R54.2, U2.7 (GND), U2.9 (PowerPAD); also elsewhere on the board
Q_REV_GATE: D24.1 (A), Q3.4 (G), R51.1
RT_MON: U2.4 (RT/CLK); also elsewhere on the board
SW_MAIN: C43.2, D23.1 (K), L2.1, U2.8 (SW)
VIN_FUSED: Q3.5 (D), Q3.6 (D), Q3.7 (D), Q3.8 (D); also elsewhere on the board
VIN_PROTECTED: C41.1, C42.1, D24.3 (K), Q3.1 (S), Q3.2 (S), Q3.3 (S), U2.2 (VIN); also elsewhere on the board

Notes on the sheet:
REV F / POWER-1
Prototype circuit; manufacturer pin names/MPNs recorded in components.json and BOM.csv.
Supply grounds shared. Analog shunts precede powered-off isolation. New oil/NTC conversion and WiFi firmware required.
NEVER coil/injector tach; NEVER screen 3V3_OUT as power input. Cut Teensy VUSB-VIN. CR2032 is not rechargeable.

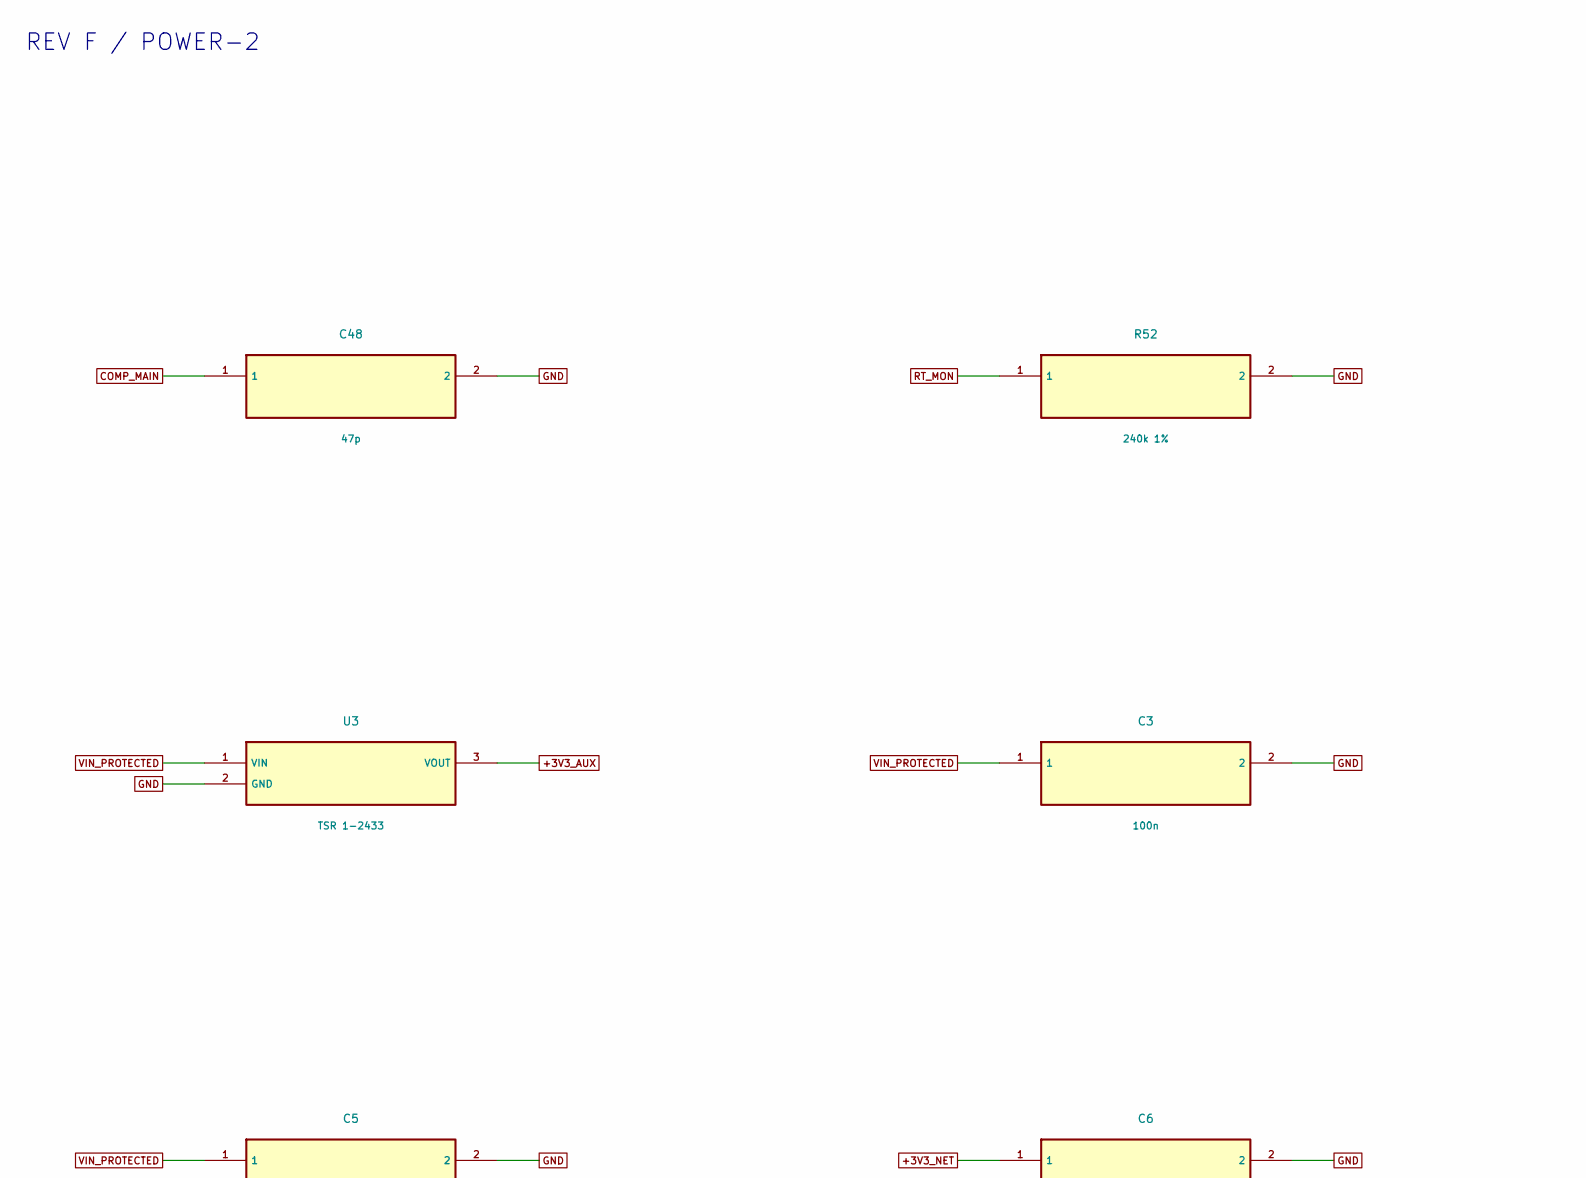
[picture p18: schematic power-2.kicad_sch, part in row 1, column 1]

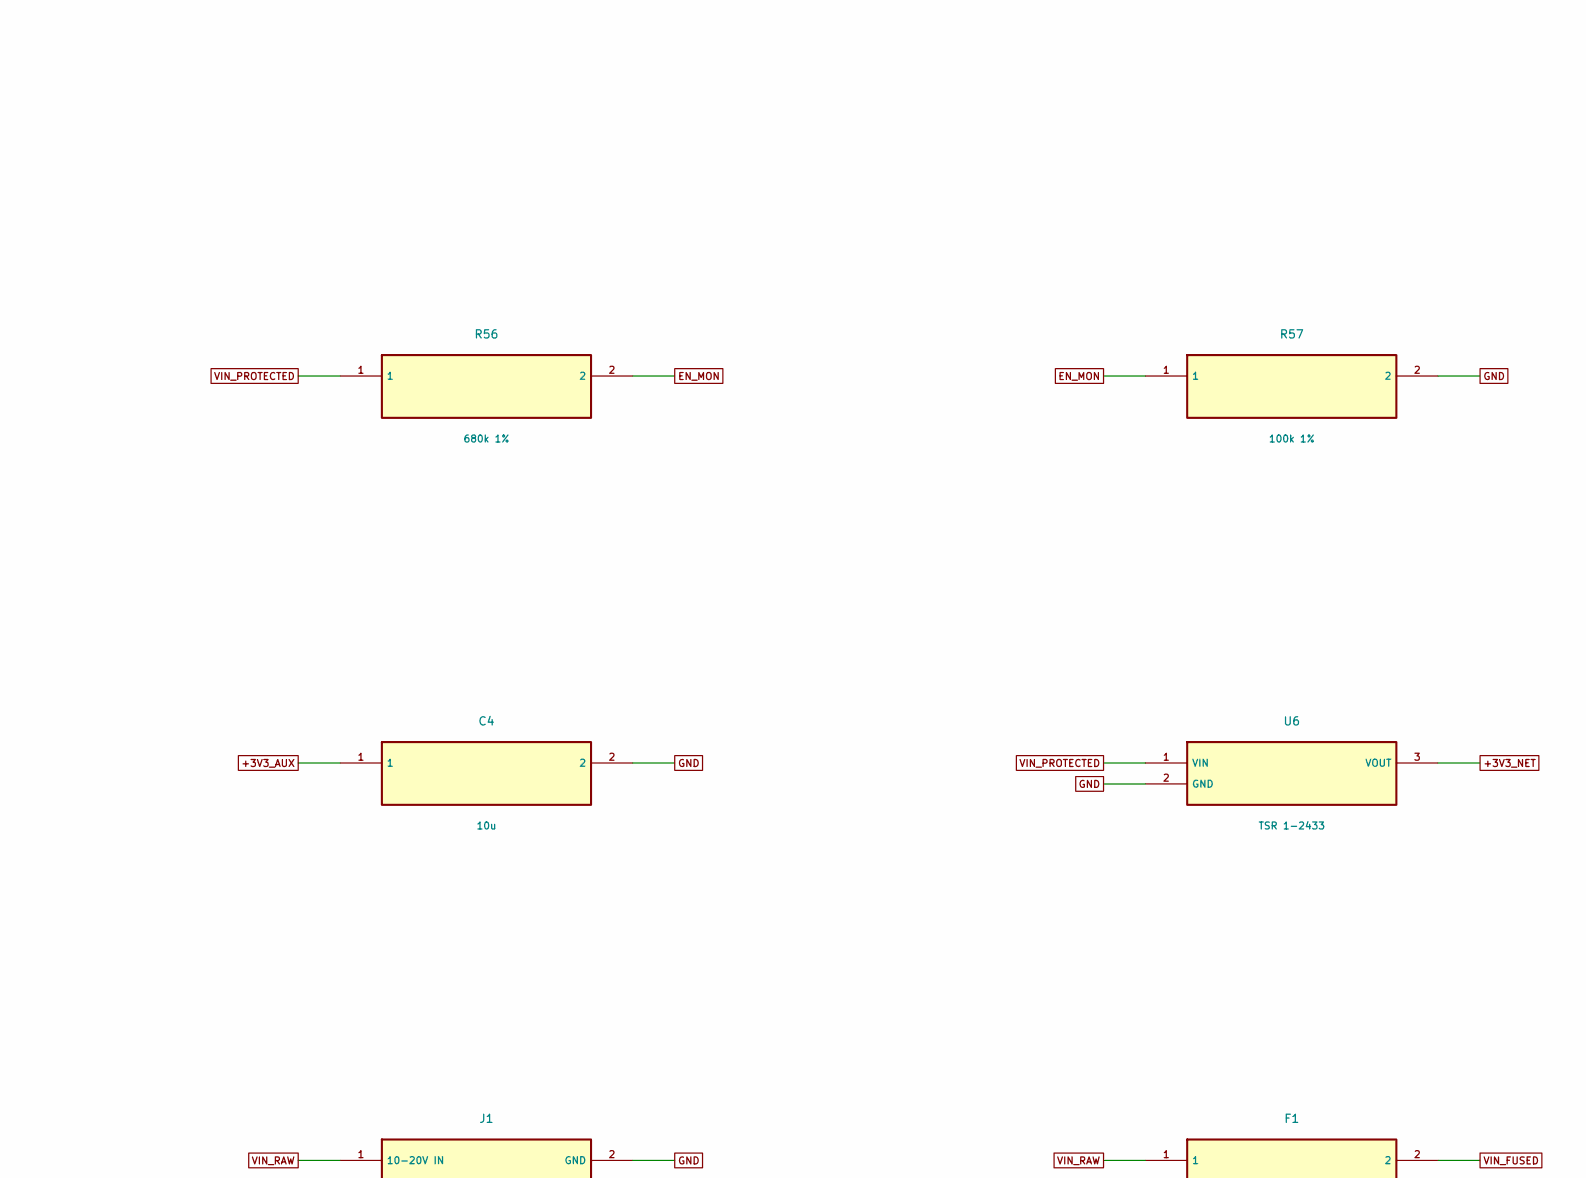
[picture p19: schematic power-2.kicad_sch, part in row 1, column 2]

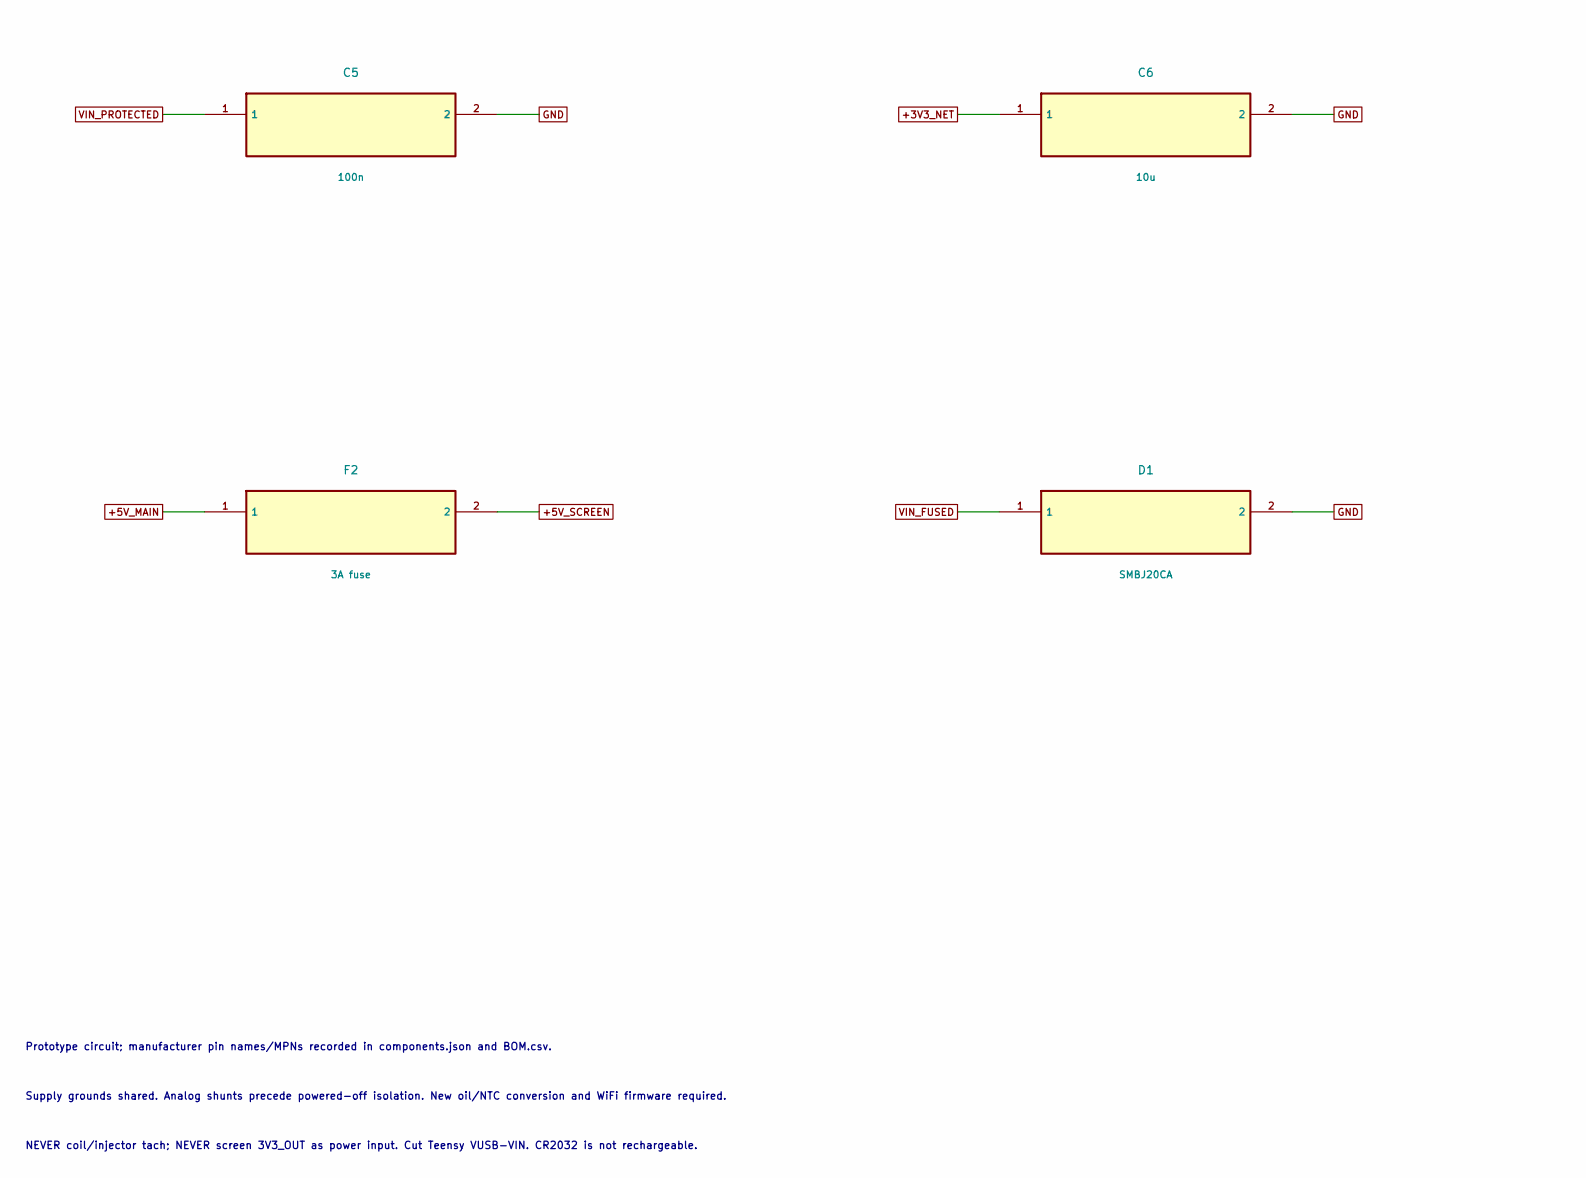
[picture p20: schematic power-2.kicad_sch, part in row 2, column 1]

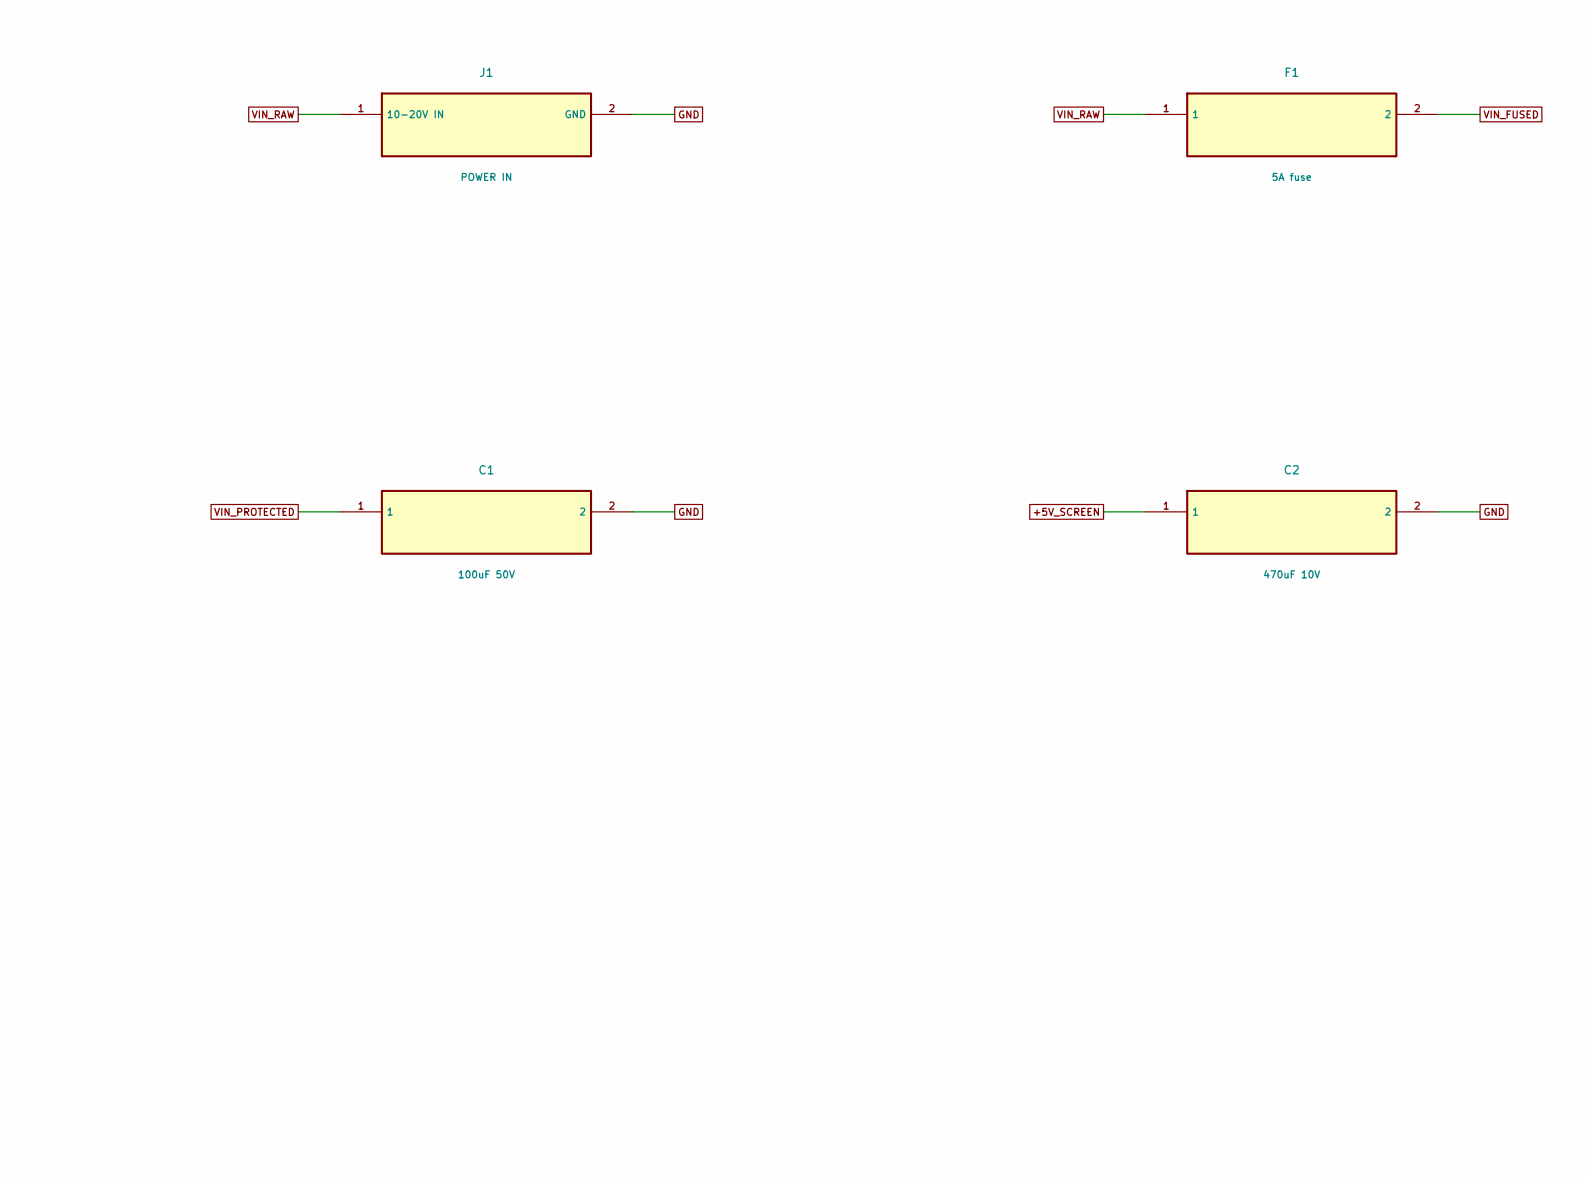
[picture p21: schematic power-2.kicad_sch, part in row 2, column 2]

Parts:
C1: 100uF 50V; CP_Radial_D8.0mm_P3.50mm
C2: 470uF 10V; CP_Radial_D8.0mm_P3.50mm
C3, C5: 100n; C_0805_2012Metric
C4, C6: 10u; C_0805_2012Metric
C48: 47p; C_0805_2012Metric
D1: SMBJ20CA; D_SMB
F1: 5A fuse; Fuse_Littelfuse-NANO2-451_453
F2: 3A fuse; Fuse_Littelfuse-NANO2-451_453
J1: POWER IN; TerminalBlock_Phoenix_MKDS-1,5-2-5.08_1x02_P5.08mm_Horizont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
R52: 240k 1%; R_0805_2012Metric
R56: 680k 1%; R_0805_2012Metric
R57: 100k 1%; R_0805_2012Metric
U3, U6: TSR 1-2433; Converter_DCDC_TRACO_TSR-1_THT

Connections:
+3V3_AUX: C4.1, U3.3 (VOUT); also elsewhere on the board
+3V3_NET: C6.1, U6.3 (VOUT); also elsewhere on the board
+5V_MAIN: F2.1; also elsewhere on the board
+5V_SCREEN: C2.1, F2.2; also elsewhere on the board
COMP_MAIN: C48.1; also elsewhere on the board
EN_MON: R56.2, R57.1; also elsewhere on the board
GND: C1.2, C2.2, C3.2, C4.2, C5.2, C6.2, C48.2, D1.2, J1.2 (GND), R52.2, R57.2, U3.2 (GND), U6.2 (GND); also elsewhere on the board
RT_MON: R52.1; also elsewhere on the board
VIN_FUSED: D1.1, F1.2; also elsewhere on the board
VIN_PROTECTED: C1.1, C3.1, C5.1, R56.1, U3.1 (VIN), U6.1 (VIN); also elsewhere on the board
VIN_RAW: F1.1, J1.1 (10-20V IN)

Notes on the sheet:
REV F / POWER-2
Prototype circuit; manufacturer pin names/MPNs recorded in components.json and BOM.csv.
Supply grounds shared. Analog shunts precede powered-off isolation. New oil/NTC conversion and WiFi firmware required.
NEVER coil/injector tach; NEVER screen 3V3_OUT as power input. Cut Teensy VUSB-VIN. CR2032 is not rechargeable.

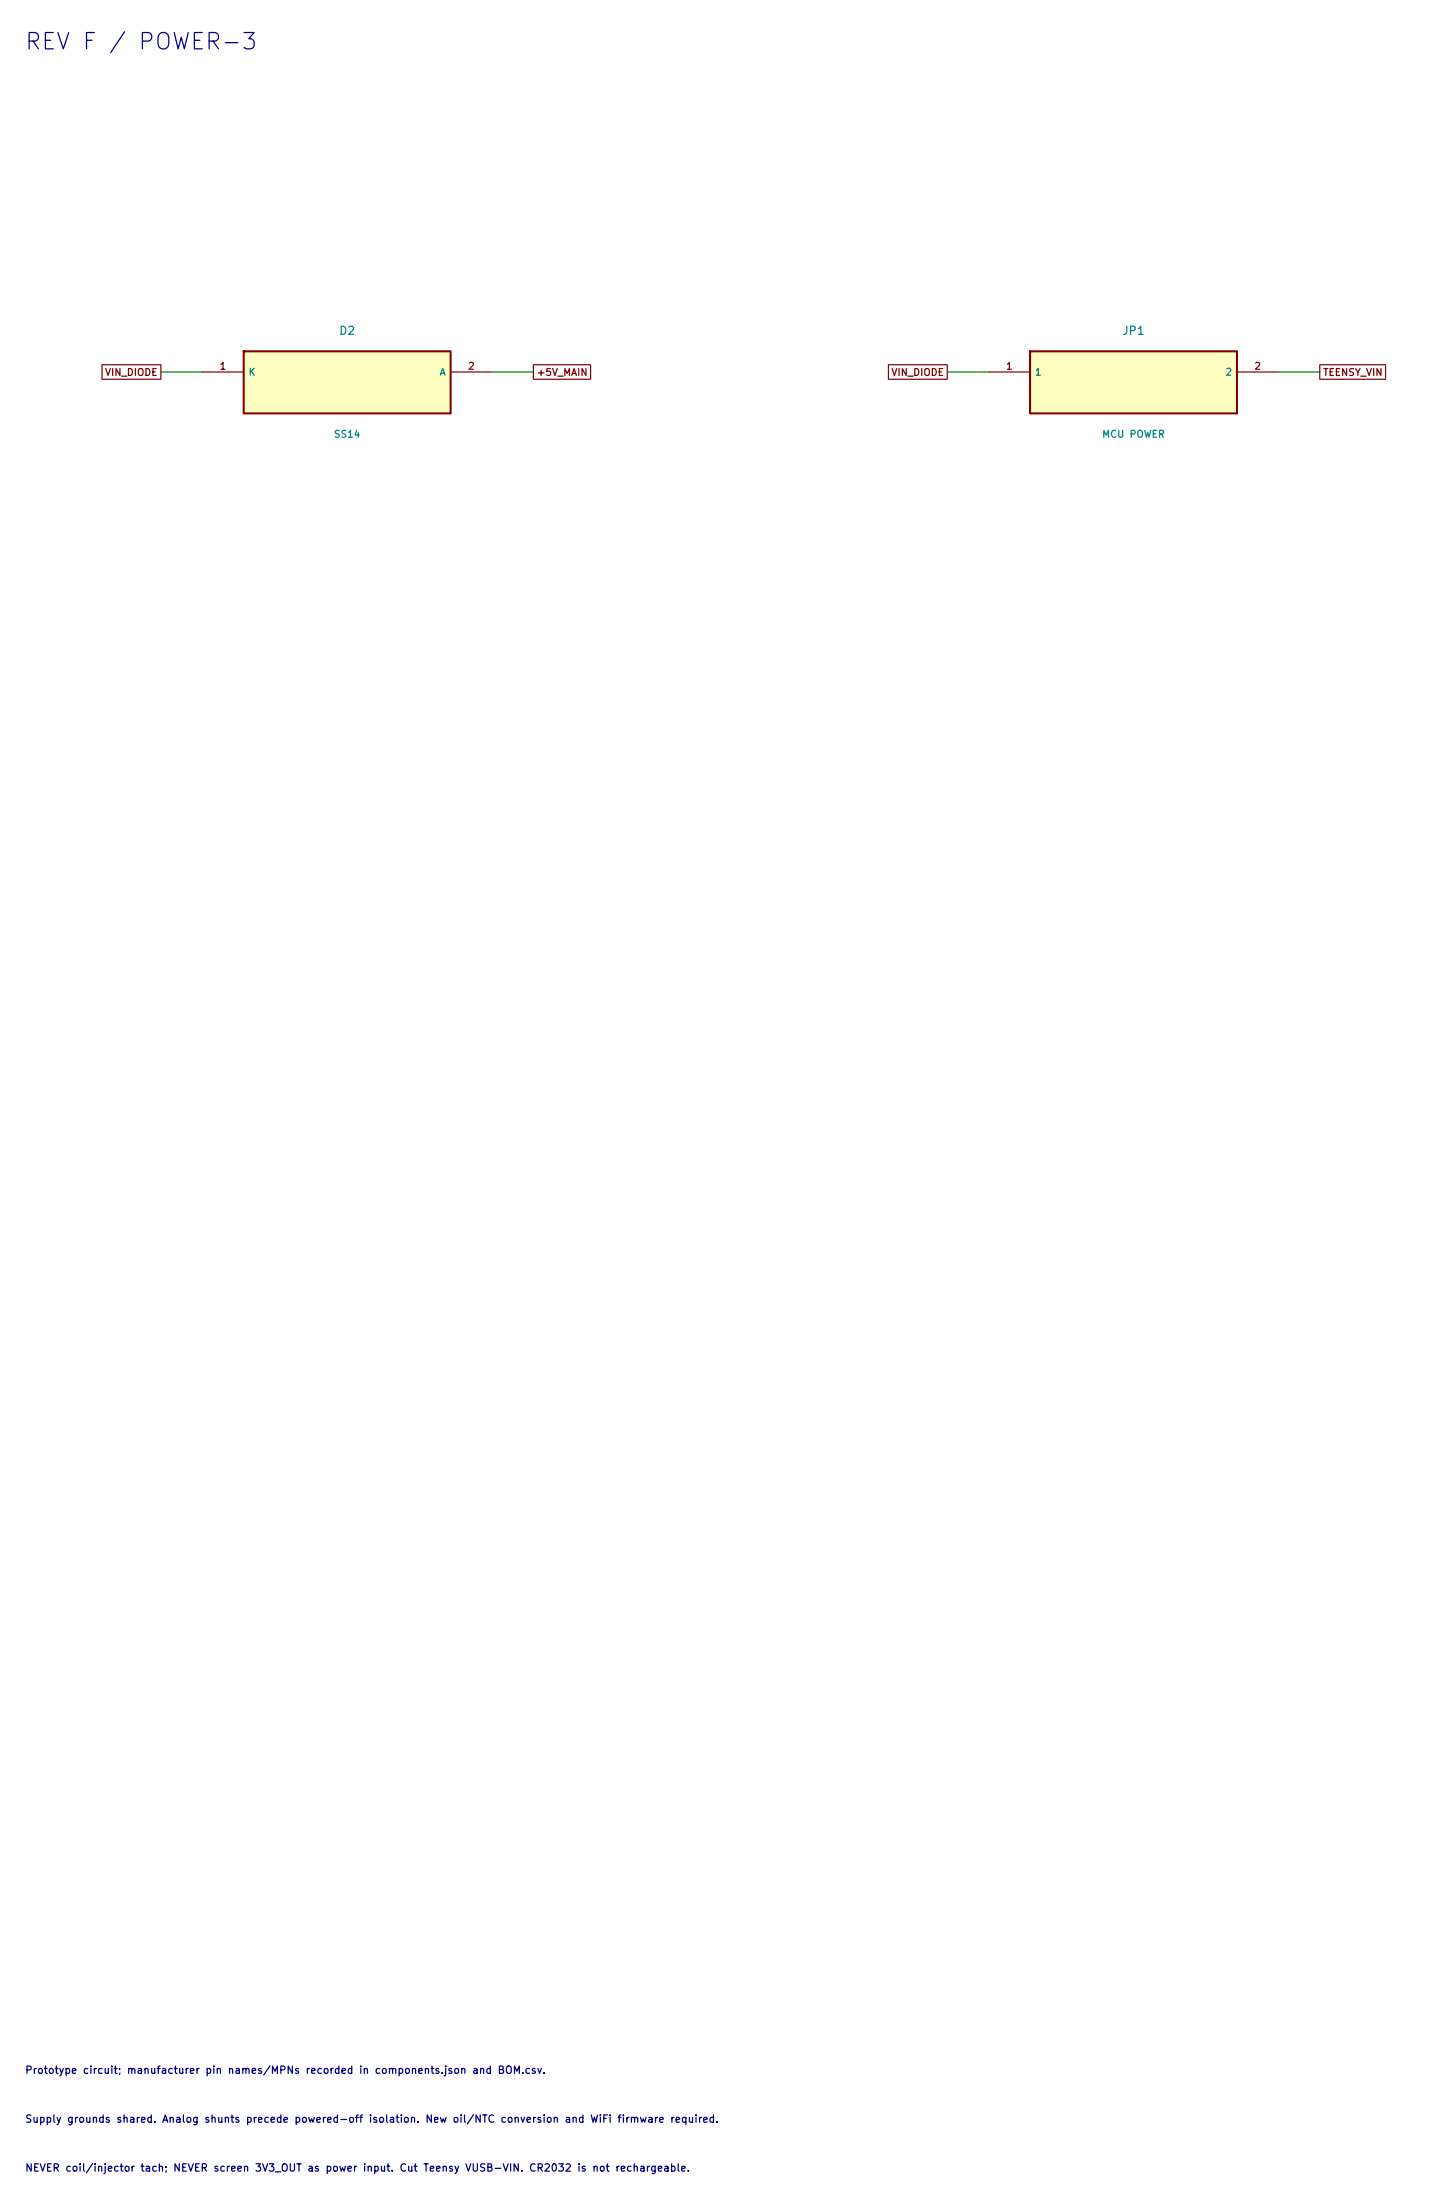
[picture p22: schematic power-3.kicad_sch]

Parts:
D2: SS14; D_SMA
JP1: MCU POWER; PinHeader_1x02_P2.54mm_Vertical

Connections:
+5V_MAIN: D2.2 (A); also elsewhere on the board
TEENSY_VIN: JP1.2; also elsewhere on the board
VIN_DIODE: D2.1 (K), JP1.1

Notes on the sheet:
REV F / POWER-3
Prototype circuit; manufacturer pin names/MPNs recorded in components.json and BOM.csv.
Supply grounds shared. Analog shunts precede powered-off isolation. New oil/NTC conversion and WiFi firmware required.
NEVER coil/injector tach; NEVER screen 3V3_OUT as power input. Cut Teensy VUSB-VIN. CR2032 is not rechargeable.

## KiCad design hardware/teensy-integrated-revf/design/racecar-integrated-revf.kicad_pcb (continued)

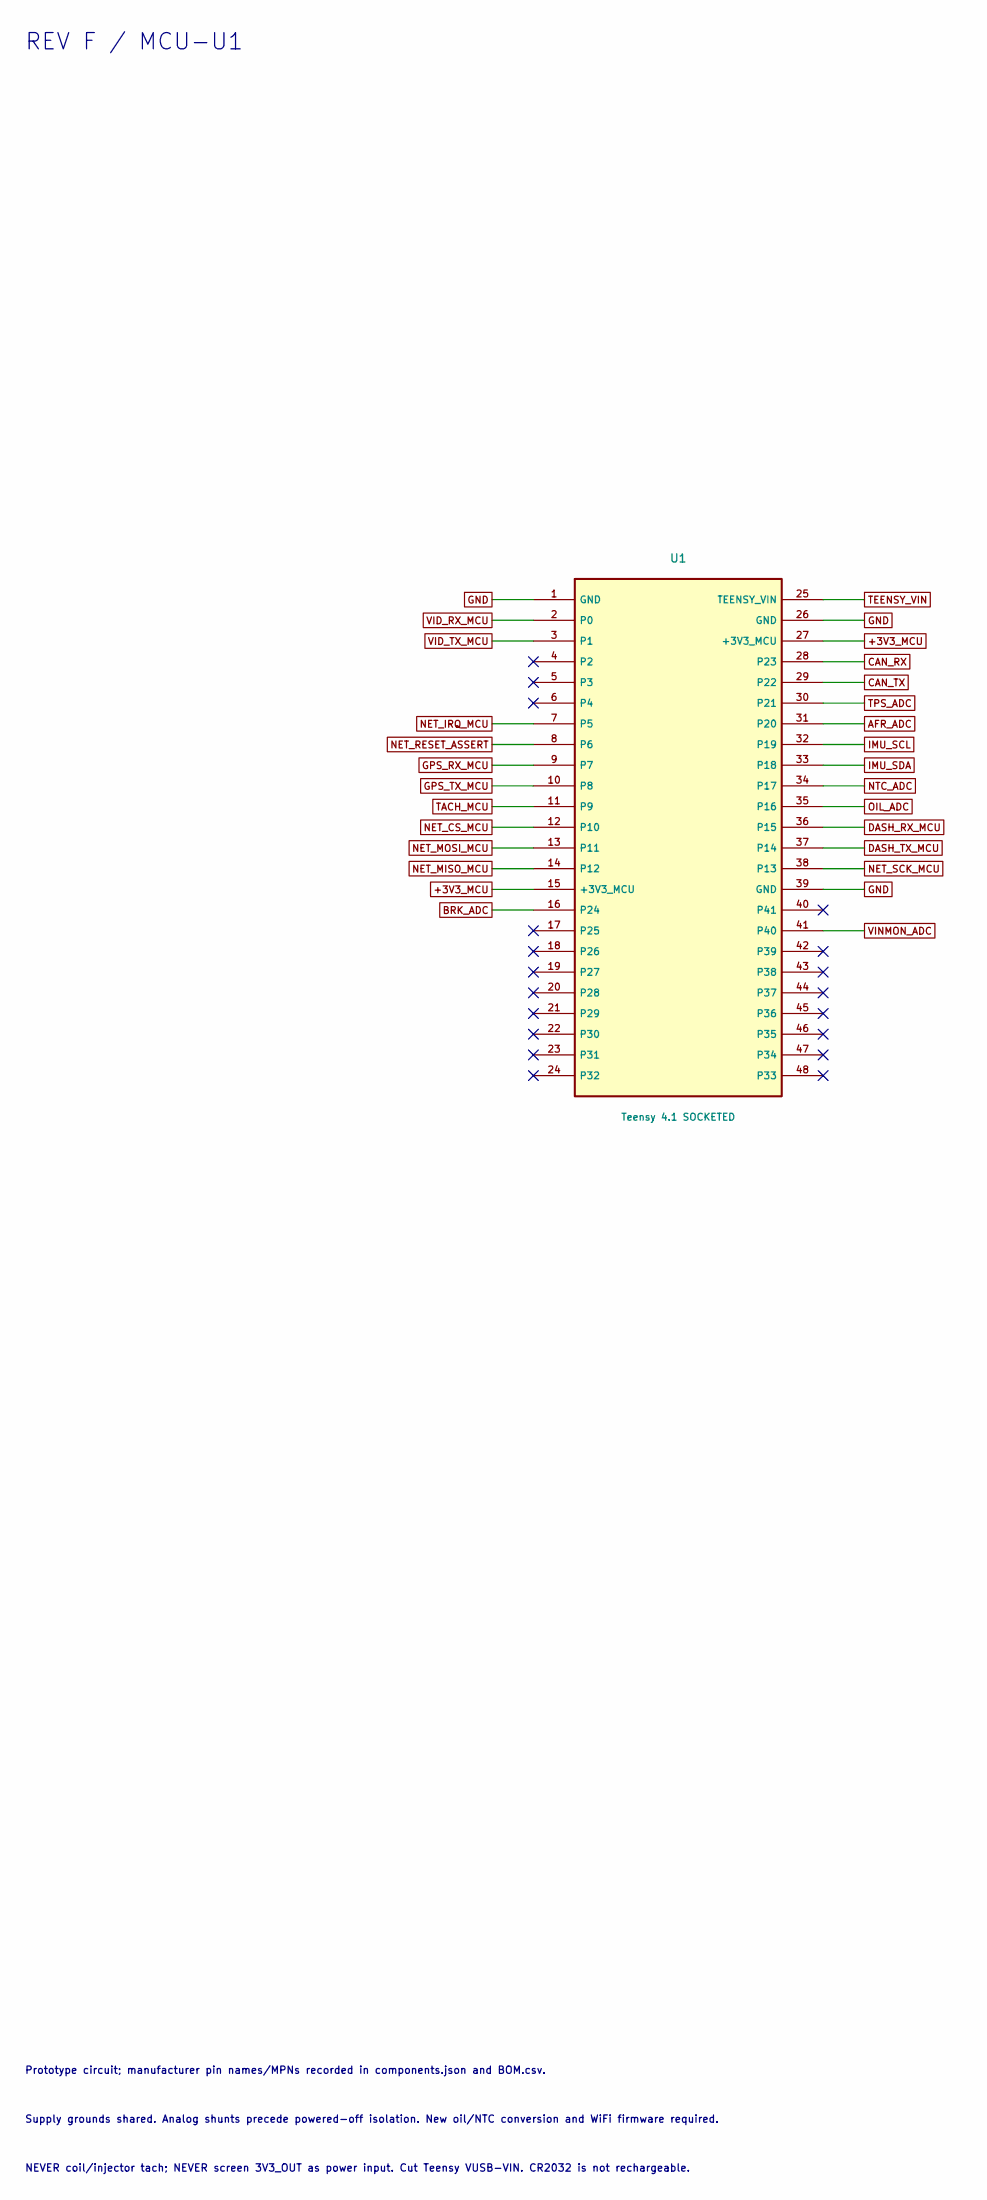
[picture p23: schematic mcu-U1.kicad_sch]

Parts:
U1: Teensy 4.1 SOCKETED; Teensy41_Socket

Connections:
+3V3_MCU: U1.15 (+3V3_MCU), U1.27 (+3V3_MCU); also elsewhere on the board
AFR_ADC: U1.31 (P20); also elsewhere on the board
BRK_ADC: U1.16 (P24); also elsewhere on the board
CAN_RX: U1.28 (P23); also elsewhere on the board
CAN_TX: U1.29 (P22); also elsewhere on the board
DASH_RX_MCU: U1.36 (P15); also elsewhere on the board
DASH_TX_MCU: U1.37 (P14); also elsewhere on the board
GND: U1.1 (GND), U1.26 (GND), U1.39 (GND); also elsewhere on the board
GPS_RX_MCU: U1.9 (P7); also elsewhere on the board
GPS_TX_MCU: U1.10 (P8); also elsewhere on the board
IMU_SCL: U1.32 (P19); also elsewhere on the board
IMU_SDA: U1.33 (P18); also elsewhere on the board
NET_CS_MCU: U1.12 (P10); also elsewhere on the board
NET_IRQ_MCU: U1.7 (P5); also elsewhere on the board
NET_MISO_MCU: U1.14 (P12); also elsewhere on the board
NET_MOSI_MCU: U1.13 (P11); also elsewhere on the board
NET_RESET_ASSERT: U1.8 (P6); also elsewhere on the board
NET_SCK_MCU: U1.38 (P13); also elsewhere on the board
NTC_ADC: U1.34 (P17); also elsewhere on the board
OIL_ADC: U1.35 (P16); also elsewhere on the board
TACH_MCU: U1.11 (P9); also elsewhere on the board
TEENSY_VIN: U1.25 (TEENSY_VIN); also elsewhere on the board
TPS_ADC: U1.30 (P21); also elsewhere on the board
VID_RX_MCU: U1.2 (P0); also elsewhere on the board
VID_TX_MCU: U1.3 (P1); also elsewhere on the board
VINMON_ADC: U1.41 (P40); also elsewhere on the board

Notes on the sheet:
REV F / MCU-U1
Prototype circuit; manufacturer pin names/MPNs recorded in components.json and BOM.csv.
Supply grounds shared. Analog shunts precede powered-off isolation. New oil/NTC conversion and WiFi firmware required.
NEVER coil/injector tach; NEVER screen 3V3_OUT as power input. Cut Teensy VUSB-VIN. CR2032 is not rechargeable.

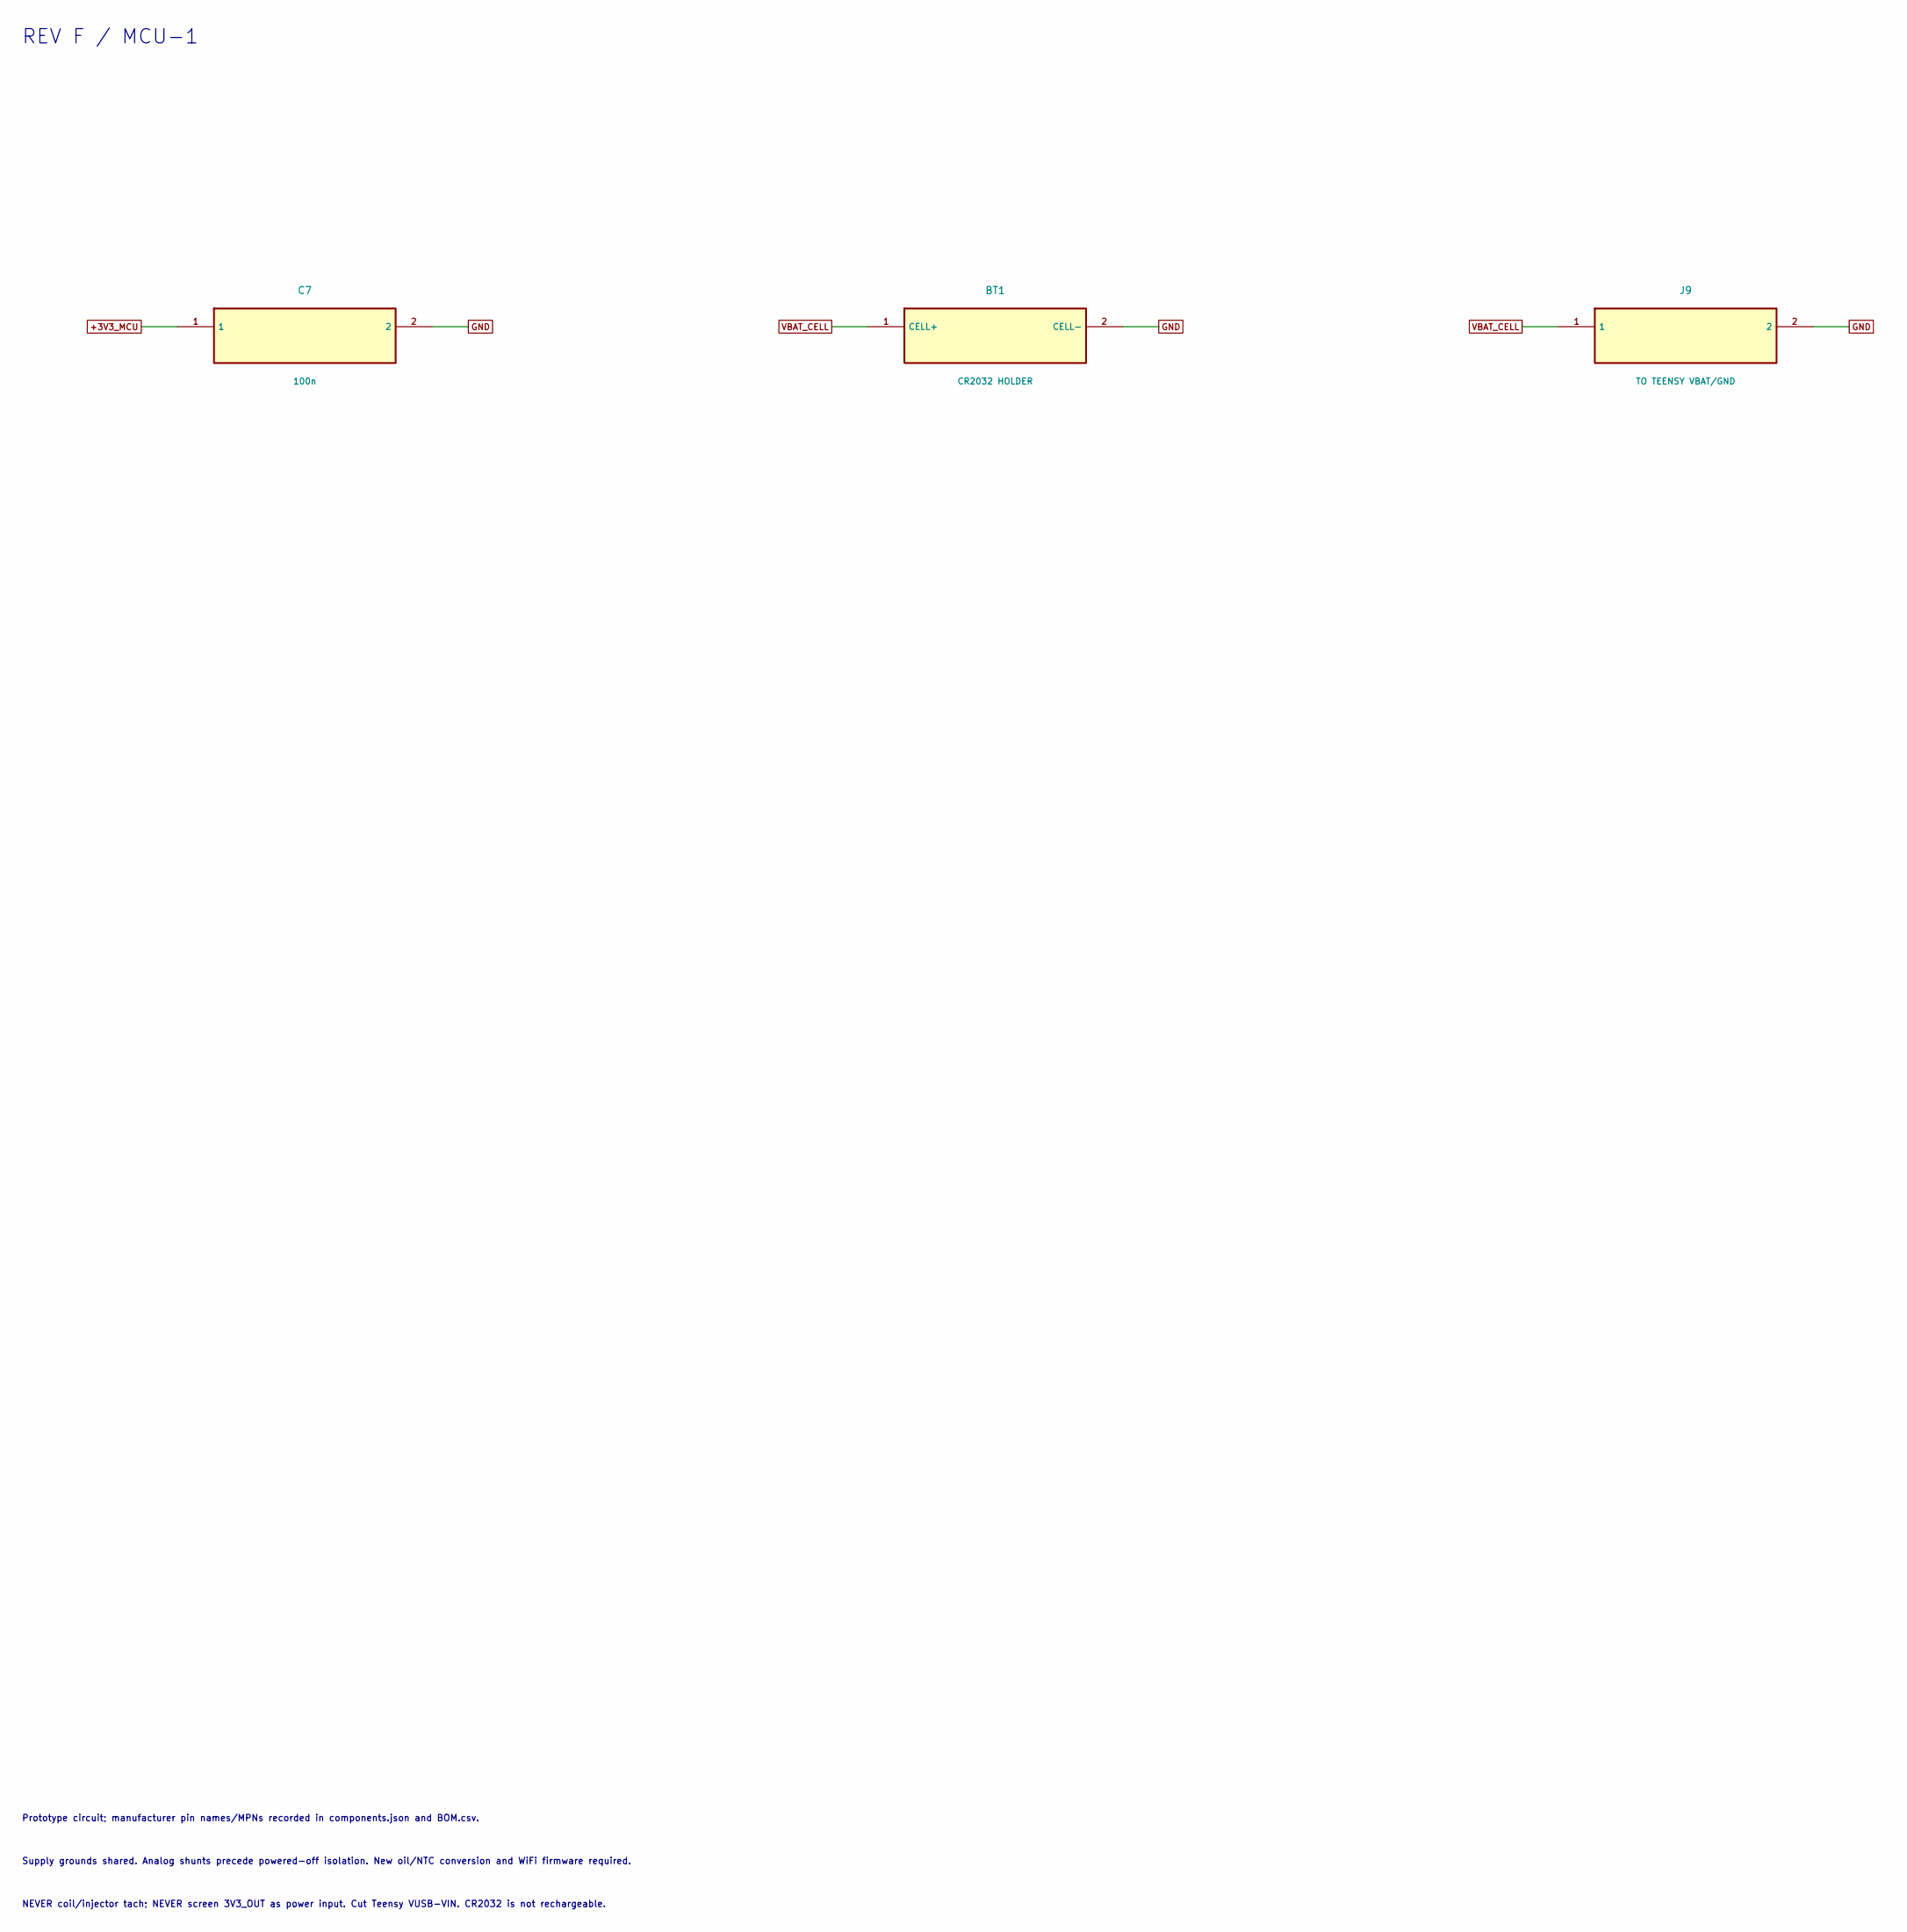
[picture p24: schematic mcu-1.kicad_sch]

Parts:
BT1: CR2032 HOLDER; BatteryHolder_Keystone_1058_1x2032
C7: 100n; C_0805_2012Metric
J9: TO TEENSY VBAT/GND; JST_XH_B2B-XH-A_1x02_P2.50mm_Vertical

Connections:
+3V3_MCU: C7.1; also elsewhere on the board
GND: BT1.2 (CELL-), C7.2, J9.2; also elsewhere on the board
VBAT_CELL: BT1.1 (CELL+), J9.1

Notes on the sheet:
REV F / MCU-1
Prototype circuit; manufacturer pin names/MPNs recorded in components.json and BOM.csv.
Supply grounds shared. Analog shunts precede powered-off isolation. New oil/NTC conversion and WiFi firmware required.
NEVER coil/injector tach; NEVER screen 3V3_OUT as power input. Cut Teensy VUSB-VIN. CR2032 is not rechargeable.




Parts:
C49, C50: 100n; C_0805_2012Metric
C51: 1u; C_0805_2012Metric
C52: 4.7n; C_0805_2012Metric
D25: NUP2105L; SOT-23
J14: CAN; TerminalBlock_Phoenix_MKDS-1,5-3-5.08_1x03_P5.08mm_Horizont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
JP2: CAN TERM; PinHeader_1x02_P2.54mm_Vertical
R58, R59: 60.4R 1%; R_0805_2012Metric
U21: TCAN1042HGV-Q1; SOIC-8_3.9x4.9mm_P1.27mm

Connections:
+3V3_MCU: C50.1, U21.5 (VIO); also elsewhere on the board
+5V_MAIN: C49.1, C51.1, U21.3 (VCC); also elsewhere on the board
CANH: D25.1 (LINE1), J14.1 (CANH), JP2.1, U21.7 (CANH)
CANL: D25.2 (LINE2), J14.2 (CANL), R59.2, U21.6 (CANL)
CAN_RX: U21.4 (RXD); also elsewhere on the board
CAN_TERM: JP2.2, R58.1
CAN_TERM_MID: C52.1, R58.2, R59.1
CAN_TX: U21.1 (TXD); also elsewhere on the board
GND: C49.2, C50.2, C51.2, C52.2, D25.3 (GND), J14.3 (GND), U21.2 (GND), U21.8 (STB); also elsewhere on the board

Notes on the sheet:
REV F / CAN-1
Prototype circuit; manufacturer pin names/MPNs recorded in components.json and BOM.csv.
Supply grounds shared. Analog shunts precede powered-off isolation. New oil/NTC conversion and WiFi firmware required.
NEVER coil/injector tach; NEVER screen 3V3_OUT as power input. Cut Teensy VUSB-VIN. CR2032 is not rechargeable.




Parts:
H1, H2, H3, H4: M3 MOUNT; MountingHole_3.2mm_M3
TP1: GND; TestPoint_THTPad_D2.0mm_Drill1.0mm
TP2: +5V_MAIN; TestPoint_THTPad_D2.0mm_Drill1.0mm
TP3: +3V3_AUX; TestPoint_THTPad_D2.0mm_Drill1.0mm
TP4: +3V3_NET; TestPoint_THTPad_D2.0mm_Drill1.0mm
TP5: +3V3_MCU; TestPoint_THTPad_D2.0mm_Drill1.0mm
TP6: CAN_TX; TestPoint_THTPad_D2.0mm_Drill1.0mm
TP7: CAN_RX; TestPoint_THTPad_D2.0mm_Drill1.0mm

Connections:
+3V3_AUX: TP3.1; also elsewhere on the board
+3V3_MCU: TP5.1; also elsewhere on the board
+3V3_NET: TP4.1; also elsewhere on the board
+5V_MAIN: TP2.1; also elsewhere on the board
CAN_RX: TP7.1; also elsewhere on the board
CAN_TX: TP6.1; also elsewhere on the board
GND: TP1.1; also elsewhere on the board

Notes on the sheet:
REV F / MECHANICAL-1
Prototype circuit; manufacturer pin names/MPNs recorded in components.json and BOM.csv.
Supply grounds shared. Analog shunts precede powered-off isolation. New oil/NTC conversion and WiFi firmware required.
NEVER coil/injector tach; NEVER screen 3V3_OUT as power input. Cut Teensy VUSB-VIN. CR2032 is not rechargeable.

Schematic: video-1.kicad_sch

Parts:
D3, D4: UART ESD; D_SOD-323
J13: PI 5 VIDEO 3V3 UART; JST_XH_B4B-XH-A_1x04_P2.50mm_Vertical
R1, R2: 1k 1%; R_0805_2012Metric

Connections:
GND: D3.2, D4.2, J13.1 (GND), J13.4 (GND); also elsewhere on the board
VID_RX_CABLE: D4.1, J13.3 (RX from Pi), R2.1
VID_RX_MCU: R2.2; also elsewhere on the board
VID_TX_CABLE: D3.1, J13.2 (TX to Pi), R1.2
VID_TX_MCU: R1.1; also elsewhere on the board

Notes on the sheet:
REV F / VIDEO-1
Prototype circuit; manufacturer pin names/MPNs recorded in components.json and BOM.csv.
Supply grounds shared. Analog shunts precede powered-off isolation. New oil/NTC conversion and WiFi firmware required.
NEVER coil/injector tach; NEVER screen 3V3_OUT as power input. Cut Teensy VUSB-VIN. CR2032 is not rechargeable.

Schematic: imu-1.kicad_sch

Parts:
C9: 100n; C_0805_2012Metric
C10: 10n; C_0805_2012Metric
C11: 2.2u; C_0805_2012Metric
R3, R4: 10k 1%; R_0805_2012Metric
U7: ICM-42670-P; InvenSense_LGA-14_2.5x3.0mm_P0.50mm

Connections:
+3V3_MCU: C9.1, C10.1, C11.1, R3.1, R4.1, U7.5 (VDDIO), U7.8 (VDD), U7.12 (AP_CS); also elsewhere on the board
GND: C9.2, C10.2, C11.2, U7.1 (AP_SDO/AP_AD0), U7.2 (RESV), U7.3 (RESV), U7.6 (GND), U7.7 (FSYNC), U7.10 (RESV), U7.11 (RESV); also elsewhere on the board
IMU_SCL: R4.2, U7.13 (AP_SCL); also elsewhere on the board
IMU_SDA: R3.2, U7.14 (AP_SDA); also elsewhere on the board

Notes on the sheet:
REV F / IMU-1
Prototype circuit; manufacturer pin names/MPNs recorded in components.json and BOM.csv.
Supply grounds shared. Analog shunts precede powered-off isolation. New oil/NTC conversion and WiFi firmware required.
NEVER coil/injector tach; NEVER screen 3V3_OUT as power input. Cut Teensy VUSB-VIN. CR2032 is not rechargeable.

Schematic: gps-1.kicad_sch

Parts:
C12, C15, C16, C17: 100n; C_0805_2012Metric
C13: 10u; C_0805_2012Metric
C14: 100pF C0G; C_0402_1005Metric
D5: RF ESD; D_SOD-882
J8: GPS SMA FEMALE; SMA_Amphenol_901-143_Horizontal
L1: 27nH RF choke; L_0402_1005Metric
R5: 10R 1%; R_0805_2012Metric
U8: NEO-M9N-00B; ublox_NEO
U9: TPS2553; SOT-23-6
U10: SN74LVC1G125; SOT-23-5

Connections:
+3V3_AUX: C12.1, C13.1, C15.1, C17.1, U8.2 (D_SEL), U8.22 (V_BCKP), U8.23 (VCC), U9.1 (IN), U9.3 (EN), U9.5 (ILIM), U10.5 (VCC); also elsewhere on the board
ANT_BIAS: C16.1, L1.2, R5.2
ANT_SWITCH: R5.1, U9.6 (OUT)
GND: C12.2, C13.2, C15.2, C16.2, C17.2, D5.2, J8.2, U8.4 (EXTINT), U8.7 (V_USB), U8.10 (GND), U8.12 (GND), U8.13 (GND), U8.24 (GND), U9.2 (GND), U10.1 (OE_N), U10.3 (GND); also elsewhere on the board
GPS_RX_AUX: U8.21 (RXD), U10.4 (Y)
GPS_TX_AUX: U8.20 (TXD); also elsewhere on the board
GPS_TX_MCU: U10.2 (A); also elsewhere on the board
RF_ANT: C14.1, D5.1, J8.1, L1.1
RF_GNSS: C14.2, U8.11 (RF_IN)

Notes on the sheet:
REV F / GPS-1
Prototype circuit; manufacturer pin names/MPNs recorded in components.json and BOM.csv.
Supply grounds shared. Analog shunts precede powered-off isolation. New oil/NTC conversion and WiFi firmware required.
NEVER coil/injector tach; NEVER screen 3V3_OUT as power input. Cut Teensy VUSB-VIN. CR2032 is not rechargeable.

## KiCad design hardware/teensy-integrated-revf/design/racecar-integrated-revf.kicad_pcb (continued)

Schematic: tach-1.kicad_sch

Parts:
C18: 1n; C_0805_2012Metric
C19, C20: 100n; C_0805_2012Metric
D6: LM4040 2.5; SOT-23
D7: PMEG2010ER; Nexperia_CFP3_SOD-123W
J3: TACH INPUT; TerminalBlock_Phoenix_MKDS-1,5-2-5.08_1x02_P5.08mm_Horizont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
Q1: MMBT3904; SOT-23
R6: 180k 1%; R_0805_2012Metric
R7: 22k 1%; R_0805_2012Metric
R8: 240k 1%; R_0805_2012Metric
R9, R12: 10k 1%; R_0805_2012Metric
R10: 2.2M 1%; R_0805_2012Metric
R11: 4.7k 1%; R_0805_2012Metric
R13: 100k 1%; R_0805_2012Metric
U11: LM2903B; SOIC-8_3.9x4.9mm_P1.27mm

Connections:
+5V_MAIN: C20.1, R8.1, R11.1, U11.8 (VCC); also elsewhere on the board
GND: C18.2, C19.2, C20.2, D6.2 (A), D6.3 (A/NC), D7.2 (A), J3.2 (RETURN), Q1.2 (E), R7.2, R9.2, R13.2, U11.4 (GND), U11.5 (IN2+); also elsewhere on the board
TACH_BASE: Q1.1 (B), R12.2, R13.1
TACH_CMP: R10.1, R11.2, R12.1, U11.1 (OUT1)
TACH_IN: J3.1 (SIGNAL), R6.1
TACH_LED_K: Q1.3 (C); also elsewhere on the board
TACH_REF: C19.1, R8.2, R9.1, U11.2 (IN1-), U11.6 (IN2-)
TACH_SENSE: C18.1, D6.1 (K), D7.1 (K), R6.2, R7.1, R10.2, U11.3 (IN1+)

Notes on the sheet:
REV F / TACH-1
Prototype circuit; manufacturer pin names/MPNs recorded in components.json and BOM.csv.
Supply grounds shared. Analog shunts precede powered-off isolation. New oil/NTC conversion and WiFi firmware required.
NEVER coil/injector tach; NEVER screen 3V3_OUT as power input. Cut Teensy VUSB-VIN. CR2032 is not rechargeable.

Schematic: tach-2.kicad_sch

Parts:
C21: 100n; C_0805_2012Metric
R14: 680 1%; R_0805_2012Metric
R15: 4.7k 1%; R_0805_2012Metric
U12: VO617A-3; SMDIP-4_W9.53mm
U13: SN74LVC2G17; SOT-23-6

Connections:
+3V3_MCU: C21.1, R15.1, U13.5 (VCC); also elsewhere on the board
+5V_MAIN: R14.1; also elsewhere on the board
GND: C21.2, U12.3 (E), U13.2 (GND); also elsewhere on the board
GPS_RX_MCU: U13.4 (2Y); also elsewhere on the board
GPS_TX_AUX: U13.3 (2A); also elsewhere on the board
TACH_LED_A: R14.2, U12.1 (LED A)
TACH_LED_K: U12.2 (LED K); also elsewhere on the board
TACH_MCU: U13.6 (1Y); also elsewhere on the board
TACH_OPTO: R15.2, U12.4 (C), U13.1 (1A)

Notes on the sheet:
REV F / TACH-2
Prototype circuit; manufacturer pin names/MPNs recorded in components.json and BOM.csv.
Supply grounds shared. Analog shunts precede powered-off isolation. New oil/NTC conversion and WiFi firmware required.
NEVER coil/injector tach; NEVER screen 3V3_OUT as power input. Cut Teensy VUSB-VIN. CR2032 is not rechargeable.

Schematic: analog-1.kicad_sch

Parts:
C22: 100n; C_0805_2012Metric
D8: LM4040 3.0; SOT-23
D9: PMEG2010ER; Nexperia_CFP3_SOD-123W
F3, F4, F5: 100mA PTC; Fuse_1206_3216Metric
J4: OIL 0.5-4.5V; TerminalBlock_Phoenix_MKDS-1,5-3-5.08_1x03_P5.08mm_Horizont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
J5: COOLANT NTC; TerminalBlock_Phoenix_MKDS-1,5-2-5.08_1x02_P5.08mm_Horizont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
J6: AEM 30-0300 ONLY; TerminalBlock_Phoenix_MKDS-1,5-2-5.08_1x02_P5.08mm_Horizont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
J11: THROTTLE 0.5-4.5V; TerminalBlock_Phoenix_MKDS-1,5-3-5.08_1x03_P5.08mm_Horizont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
J12: BRAKE 0.5-4.5V; TerminalBlock_Phoenix_MKDS-1,5-3-5.08_1x03_P5.08mm_Horizont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
R16, R17, R19, R20: 20k 0.1%; R_0805_2012Metric
R18: 1k 1%; R_0805_2012Metric

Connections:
+5V_BRK: F5.2, J12.1 (5V OUT)
+5V_MAIN: F3.1, F4.1, F5.1; also elsewhere on the board
+5V_SENSOR: F3.2, J4.1 (5V OUT)
+5V_TPS: F4.2, J11.1 (5V OUT)
AFR_CLAMP: R19.2, R20.1; also elsewhere on the board
AFR_SIGNAL: J6.1 (WHITE SIG+), R19.1
BRK_SIGNAL: J12.3 (SIGNAL); also elsewhere on the board
GND: C22.2, D8.2 (A), D8.3 (A/NC), D9.2 (A), J4.2 (RETURN), J5.2 (RETURN), J6.2 (BROWN RETURN), J11.2 (RETURN), J12.2 (RETURN), R17.2, R20.2; also elsewhere on the board
NTC_SIGNAL: J5.1 (NTC); also elsewhere on the board
OIL_CLAMP: D8.1 (K), D9.1 (K), R16.2, R17.1, R18.1
OIL_FILTER: C22.1, R18.2; also elsewhere on the board
OIL_SIGNAL: J4.3 (SIGNAL), R16.1
TPS_SIGNAL: J11.3 (SIGNAL); also elsewhere on the board

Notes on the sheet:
REV F / ANALOG-1
Prototype circuit; manufacturer pin names/MPNs recorded in components.json and BOM.csv.
Supply grounds shared. Analog shunts precede powered-off isolation. New oil/NTC conversion and WiFi firmware required.
NEVER coil/injector tach; NEVER screen 3V3_OUT as power input. Cut Teensy VUSB-VIN. CR2032 is not rechargeable.

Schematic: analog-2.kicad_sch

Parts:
C23, C24, C25: 100n; C_0805_2012Metric
D10, D12, D14: LM4040 3.0; SOT-23
D11, D13, D15: PMEG2010ER; Nexperia_CFP3_SOD-123W
R21, R24, R27: 1k 1%; R_0805_2012Metric
R22, R23, R25, R26: 20k 0.1%; R_0805_2012Metric

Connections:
AFR_CLAMP: D10.1 (K), D11.1 (K), R21.1; also elsewhere on the board
AFR_FILTER: C23.1, R21.2; also elsewhere on the board
GND: C23.2, C24.2, C25.2, D10.2 (A), D10.3 (A/NC), D11.2 (A), D12.2 (A), D12.3 (A/NC), D13.2 (A), D14.2 (A), D14.3 (A/NC), D15.2 (A), R23.2, R26.2; also elsewhere on the board
NTC_CLAMP: D12.1 (K), D13.1 (K), R22.2, R23.1, R24.1
NTC_FILTER: C24.1, R24.2; also elsewhere on the board
NTC_SIGNAL: R22.1; also elsewhere on the board
TPS_CLAMP: D14.1 (K), D15.1 (K), R25.2, R26.1, R27.1
TPS_FILTER: C25.1, R27.2; also elsewhere on the board
TPS_SIGNAL: R25.1; also elsewhere on the board

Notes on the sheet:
REV F / ANALOG-2
Prototype circuit; manufacturer pin names/MPNs recorded in components.json and BOM.csv.
Supply grounds shared. Analog shunts precede powered-off isolation. New oil/NTC conversion and WiFi firmware required.
NEVER coil/injector tach; NEVER screen 3V3_OUT as power input. Cut Teensy VUSB-VIN. CR2032 is not rechargeable.

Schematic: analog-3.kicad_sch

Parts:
C26, C27, C40: 100n; C_0805_2012Metric
D16, D21: LM4040 3.0; SOT-23
D17, D18, D22: PMEG2010ER; Nexperia_CFP3_SOD-123W
R28, R29, R49: 20k 0.1%; R_0805_2012Metric
R30, R50: 1k 1%; R_0805_2012Metric
R31: 150 1%; R_0805_2012Metric
R48: 180k 0.1%; R_0805_2012Metric
U14: LM4040 4.1; SOT-23

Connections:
+5V_MAIN: D18.2 (A); also elsewhere on the board
BRK_CLAMP: D16.1 (K), D17.1 (K), R28.2, R29.1, R30.1
BRK_FILTER: C26.1, R30.2; also elsewhere on the board
BRK_SIGNAL: R28.1; also elsewhere on the board
GND: C26.2, C27.2, C40.2, D16.2 (A), D16.3 (A/NC), D17.2 (A), D21.2 (A), D21.3 (A/NC), D22.2 (A), R29.2, R49.2, U14.2 (A), U14.3 (A/NC); also elsewhere on the board
NTC_EXC: C27.1, R31.2, U14.1 (K); also elsewhere on the board
NTC_FEED: D18.1 (K), R31.1
VINMON_CLAMP: D21.1 (K), D22.1 (K), R48.2, R49.1, R50.1
VINMON_FILTER: C40.1, R50.2; also elsewhere on the board
VIN_FUSED: R48.1; also elsewhere on the board

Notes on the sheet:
REV F / ANALOG-3
Prototype circuit; manufacturer pin names/MPNs recorded in components.json and BOM.csv.
Supply grounds shared. Analog shunts precede powered-off isolation. New oil/NTC conversion and WiFi firmware required.
NEVER coil/injector tach; NEVER screen 3V3_OUT as power input. Cut Teensy VUSB-VIN. CR2032 is not rechargeable.

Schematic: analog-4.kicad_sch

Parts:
C28, C29: 100n; C_0805_2012Metric
R32: 2.49k 0.1%; R_0805_2012Metric
U15, U16: TMUX1511; TSSOP-14_4.4x5mm_P0.65mm

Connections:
+3V3_MCU: C28.1, C29.1, U15.1 (SEL1), U15.4 (SEL2), U15.10 (SEL3), U15.13 (SEL4), U15.14 (VDD), U16.1 (SEL1), U16.4 (SEL2), U16.14 (VDD); also elsewhere on the board
AFR_ADC: U15.6 (D2); also elsewhere on the board
AFR_FILTER: U15.5 (S2); also elsewhere on the board
BRK_ADC: U16.6 (D2); also elsewhere on the board
BRK_FILTER: U16.5 (S2); also elsewhere on the board
GND: C28.2, C29.2, U15.7 (GND), U16.7 (GND), U16.12 (S4), U16.13 (SEL4); also elsewhere on the board
NTC_ADC: U15.8 (D3); also elsewhere on the board
NTC_EXC: R32.1; also elsewhere on the board
NTC_FILTER: U15.9 (S3); also elsewhere on the board
NTC_SIGNAL: R32.2; also elsewhere on the board
OIL_ADC: U15.3 (D1); also elsewhere on the board
OIL_FILTER: U15.2 (S1); also elsewhere on the board
TPS_ADC: U16.3 (D1); also elsewhere on the board
TPS_FILTER: U16.2 (S1); also elsewhere on the board
VINMON_ADC: U15.11 (D4); also elsewhere on the board
VINMON_FILTER: U15.12 (S4); also elsewhere on the board

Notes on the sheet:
REV F / ANALOG-4
Prototype circuit; manufacturer pin names/MPNs recorded in components.json and BOM.csv.
Supply grounds shared. Analog shunts precede powered-off isolation. New oil/NTC conversion and WiFi firmware required.
NEVER coil/injector tach; NEVER screen 3V3_OUT as power input. Cut Teensy VUSB-VIN. CR2032 is not rechargeable.

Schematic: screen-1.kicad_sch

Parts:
C30, C31, C32, C33: 100n; C_0805_2012Metric
D19, D20: UART ESD; D_SOD-323
J2: SCREEN J10 ONLY; TerminalBlock_Phoenix_MKDS-1,5-4-5.08_1x04_P5.08mm_Horizont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
R33, R34: 100 1%; R_0805_2012Metric
R35, R36: 47k 1%; R_0805_2012Metric
U4, U5: SN74LVC1T45; SOT-23-6

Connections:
+3V3_MCU: C30.1, C32.1, R35.1, U4.1 (VCCA), U4.5 (DIR), U5.1 (VCCA); also elsewhere on the board
+5V_SCREEN: C31.1, C33.1, J2.2 (5V OUT), R36.1, U4.6 (VCCB), U5.6 (VCCB); also elsewhere on the board
DASH_RX_5V: R34.2, U5.4 (B)
DASH_RX_CABLE: D20.1, J2.3 (RX FROM), R34.1, R36.2
DASH_RX_MCU: U5.3 (A); also elsewhere on the board
DASH_TX_5V: R33.1, U4.4 (B)
DASH_TX_CABLE: D19.1, J2.4 (TX TO), R33.2
DASH_TX_MCU: R35.2, U4.3 (A); also elsewhere on the board
GND: C30.2, C31.2, C32.2, C33.2, D19.2, D20.2, J2.1 (GND), U4.2 (GND), U5.2 (GND), U5.5 (DIR); also elsewhere on the board

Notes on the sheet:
REV F / SCREEN-1
Prototype circuit; manufacturer pin names/MPNs recorded in components.json and BOM.csv.
Supply grounds shared. Analog shunts precede powered-off isolation. New oil/NTC conversion and WiFi firmware required.
NEVER coil/injector tach; NEVER screen 3V3_OUT as power input. Cut Teensy VUSB-VIN. CR2032 is not rechargeable.

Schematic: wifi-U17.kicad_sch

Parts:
U17: ESP32-S3-WROOM-1-N8R2; ESP32-S3-WROOM-1

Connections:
+3V3_NET: U17.2 (3V3); also elsewhere on the board
GND: U17.1 (GND), U17.40 (GND), U17.41 (EP GND); also elsewhere on the board
NET_BOOT: U17.27 (GPIO0 BOOT); also elsewhere on the board
NET_CS: U17.18 (GPIO10 CS); also elsewhere on the board
NET_EN: U17.3 (EN); also elsewhere on the board
NET_IRQ: U17.22 (GPIO14 IRQ); also elsewhere on the board
NET_MISO: U17.21 (GPIO13 MISO); also elsewhere on the board
NET_MOSI: U17.19 (GPIO11 MOSI); also elsewhere on the board
NET_SCK: U17.20 (GPIO12 SCK); also elsewhere on the board
NET_UART_RX: U17.36 (GPIO44 RXD0); also elsewhere on the board
NET_UART_TX: U17.37 (GPIO43 TXD0); also elsewhere on the board

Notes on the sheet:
REV F / WIFI-U17
Prototype circuit; manufacturer pin names/MPNs recorded in components.json and BOM.csv.
Supply grounds shared. Analog shunts precede powered-off isolation. New oil/NTC conversion and WiFi firmware required.
NEVER coil/injector tach; NEVER screen 3V3_OUT as power input. Cut Teensy VUSB-VIN. CR2032 is not rechargeable.

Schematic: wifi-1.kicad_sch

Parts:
C34: 10u; C_0805_2012Metric
C35, C37: 100n; C_0805_2012Metric
C36: 1u; C_0805_2012Metric
Q2: MMBT3904; SOT-23
R37, R38, R39, R44: 10k 1%; R_0805_2012Metric
R40: 100k 1%; R_0805_2012Metric
R41, R42, R43: 33 1%; R_0805_2012Metric
R45: 47k 1%; R_0805_2012Metric
U18: SN74LVC125A; TSSOP-14_4.4x5mm_P0.65mm
U19: SN74LVC2G125; VSSOP-8_2.3x2mm_P0.5mm

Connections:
+3V3_MCU: R44.1, U19.8 (VCC); also elsewhere on the board
+3V3_NET: C34.1, C35.1, C37.1, R37.1, R38.1, U18.13 (4OE_N), U18.14 (VCC); also elsewhere on the board
GND: C34.2, C35.2, C36.2, C37.2, Q2.2 (E), R40.2, R45.2, U18.1 (1OE_N), U18.4 (2OE_N), U18.7 (GND), U18.10 (3OE_N), U18.12 (4A), U19.1 (1OE_N), U19.4 (GND), U19.7 (2OE_N); also elsewhere on the board
NET_BOOT: R38.2; also elsewhere on the board
NET_CS: R41.2; also elsewhere on the board
NET_CS_MCU: R44.2, U18.2 (1A); also elsewhere on the board
NET_CS_PRE: R41.1, U18.3 (1Y)
NET_EN: C36.1, Q2.3 (C), R37.2; also elsewhere on the board
NET_IRQ: U19.6 (2A); also elsewhere on the board
NET_IRQ_MCU: U19.5 (2Y); also elsewhere on the board
NET_MISO: U19.2 (1A); also elsewhere on the board
NET_MISO_MCU: U19.3 (1Y); also elsewhere on the board
NET_MOSI: R42.2; also elsewhere on the board
NET_MOSI_MCU: U18.5 (2A); also elsewhere on the board
NET_MOSI_PRE: R42.1, U18.6 (2Y)
NET_RESET_ASSERT: R39.1; also elsewhere on the board
NET_RESET_BASE: Q2.1 (B), R39.2, R40.1
NET_SCK: R43.2; also elsewhere on the board
NET_SCK_MCU: R45.1, U18.9 (3A); also elsewhere on the board
NET_SCK_PRE: R43.1, U18.8 (3Y)

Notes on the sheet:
REV F / WIFI-1
Prototype circuit; manufacturer pin names/MPNs recorded in components.json and BOM.csv.
Supply grounds shared. Analog shunts precede powered-off isolation. New oil/NTC conversion and WiFi firmware required.
NEVER coil/injector tach; NEVER screen 3V3_OUT as power input. Cut Teensy VUSB-VIN. CR2032 is not rechargeable.

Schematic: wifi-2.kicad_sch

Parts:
C38, C39: 100n; C_0805_2012Metric
J10: NET 3V3 UART SERVICE; PinHeader_2x03_P2.54mm_Vertical
R46, R47: 47k 1%; R_0805_2012Metric
U20: SN74LVC1G125; SOT-23-5

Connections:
+3V3_MCU: C38.1; also elsewhere on the board
+3V3_NET: C39.1, J10.2, U20.5; also elsewhere on the board
GND: C38.2, C39.2, J10.1, R46.2, R47.2, U20.1, U20.3; also elsewhere on the board
NET_BOOT: J10.5; also elsewhere on the board
NET_EN: J10.6; also elsewhere on the board
NET_IRQ: R46.1; also elsewhere on the board
NET_MISO: R47.1; also elsewhere on the board
NET_UART_EXT_RX: J10.4, U20.2
NET_UART_RX: U20.4; also elsewhere on the board
NET_UART_TX: J10.3; also elsewhere on the board

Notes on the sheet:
REV F / WIFI-2
Prototype circuit; manufacturer pin names/MPNs recorded in components.json and BOM.csv.
Supply grounds shared. Analog shunts precede powered-off isolation. New oil/NTC conversion and WiFi firmware required.
NEVER coil/injector tach; NEVER screen 3V3_OUT as power input. Cut Teensy VUSB-VIN. CR2032 is not rechargeable.


Board: 4 copper layers, 150.0 x 155.0 mm, 193 parts (0 on the bottom side), 103 nets.

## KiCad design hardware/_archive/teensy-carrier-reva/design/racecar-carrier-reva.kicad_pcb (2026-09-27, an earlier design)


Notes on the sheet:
RACECAR-35 / TEENSY CARRIER / REV A
UNVALIDATED PROTOTYPE - read README and BRINGUP before manufacture
10-20V DC -> Pololu D36V50F5 -> 5V, 5A total budget; fused 4A screen branch
Socketed Teensy; external GPS/IMU/CAN/W5500 modules. Regulator modules are hand-fitted.
Factory order: 2 layers, 1.6mm FR4, 2oz finished copper BOTH sides; electrical test required.



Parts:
C1: 100uF 50V; CP_Radial_D8.0mm_P3.50mm
C2: 470uF 10V; CP_Radial_D8.0mm_P3.50mm
C3, C4: 100nF; C_0805_2012Metric_Pad1.18x1.45mm_HandSolder
D1: SMBJ20CA INPUT TVS; D_SMB
D2: SS14 USB backfeed barrier; D_SMA
D6: GREEN 5V; LED_0805_2012Metric
F1: 5A INPUT FUSE; Fuse_Littelfuse-NANO2-451_453
F2: 4A SCREEN FUSE; Fuse_Littelfuse-NANO2-451_453
J1: 10-20V INPUT; TerminalBlock_Phoenix_MKDS-1,5-2-5.08_1x02_P5.08mm_Horizont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
JP1: MCU POWER ENABLE; PinHeader_1x02_P2.54mm_Vertical
R14: 4.7k; R_0805_2012Metric_Pad1.20x1.40mm_HandSolder
TP1: GND; TestPoint_THTPad_D2.0mm_Drill1.0mm
TP2: VIN_FUSED; TestPoint_THTPad_D2.0mm_Drill1.0mm
TP3: +5V_MAIN; TestPoint_THTPad_D2.0mm_Drill1.0mm
TP4: +3V3_AUX; TestPoint_THTPad_D2.0mm_Drill1.0mm
U2: D36V50F5 / 5V 5A budget; Pololu_D36V50F5
U3: TSR 1-2433 / AUX 3V3; Converter_DCDC_TRACO_TSR-1_THT

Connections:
+3V3_AUX: C4.1, TP4.1, U3.3 (3V3 OUT); also elsewhere on the board
+5V_MAIN: D2.2 (A), D6.2 (A), F2.1, TP3.1, U2.1 (VOUT), U2.2 (VOUT)
+5V_MCU_DIODE: D2.1 (K), JP1.1
+5V_SCREEN: C2.1 (+), F2.2; also elsewhere on the board
GND: C1.2 (-), C2.2 (-), C3.2, C4.2, D1.2, J1.2 (GND), R14.2, TP1.1, U2.3 (GND), U2.4 (GND), U2.5 (GND), U2.6 (GND), U3.2 (GND); also elsewhere on the board
LED_K: D6.1 (K), R14.1
TEENSY_VIN: JP1.2; also elsewhere on the board
VIN_FUSED: C1.1 (+), D1.1, F1.2, TP2.1, U2.7 (VIN), U2.8 (VIN)
VIN_PROTECTED: C3.1, U2.9 (VRP), U2.10 (VRP), U3.1 (VIN)
VIN_RAW: F1.1, J1.1 (+10-20V IN)

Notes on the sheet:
Power: 10-20V input / 5V / separate 3V3
UNVALIDATED PROTOTYPE. Regulator module provides 5V; PCB total 5V budget 5A, screen branch fused 4A.
SMBJ20CA + fuse is NOT ISO 7637 / ISO 16750 load-dump qualification. Add harness fuse near battery.
U3 takes VIN_PROTECTED from Pololu VRP. AUX 3V3 and Teensy 3V3 are DIFFERENT rails.
JP1 is initial-test isolation only. CUT the Teensy VUSB-VIN bridge before dual USB/carrier power.

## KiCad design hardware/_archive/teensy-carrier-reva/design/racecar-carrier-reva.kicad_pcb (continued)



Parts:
C5, C12, C13, C14, C15: 100nF; C_0805_2012Metric_Pad1.18x1.45mm_HandSolder
J4: GPS UART 3V3; JST_XH_B4B-XH-A_1x04_P2.50mm_Vertical
J5: MPU6050 I2C 3V3; JST_XH_B4B-XH-A_1x04_P2.50mm_Vertical
J6: CAN MODULE LOGIC; JST_XH_B4B-XH-A_1x04_P2.50mm_Vertical
J7: W5500 BREAKOUT; PinHeader_2x04_P2.54mm_Vertical
R10, R11: 10k; R_0805_2012Metric_Pad1.20x1.40mm_HandSolder
R12, R13: 4.7k; R_0805_2012Metric_Pad1.20x1.40mm_HandSolder
TP5: +3V3_MCU; TestPoint_THTPad_D2.0mm_Drill1.0mm
U1: Teensy 4.1 (socketed); Teensy41_Socket

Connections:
+3V3_AUX: C12.1, C13.1, C14.1, C15.1, J4.1 (3V3 OUT), J5.1 (3V3 OUT), J6.1 (3V3 OUT), J7.1 (3V3 OUT), R11.1, R12.1, R13.1; also elsewhere on the board
+3V3_MCU: C5.1, R10.1, TP5.1, U1.15 (3V3 OUT), U1.27 (3V3 OUT); also elsewhere on the board
CAN_RX: J6.4 (from CRX/R), U1.28 (GPIO 23)
CAN_TX: J6.3 (to CTX/D), U1.29 (GPIO 22)
DASH_RX_MCU: U1.36 (GPIO 15); also elsewhere on the board
DASH_TX_MCU: U1.37 (GPIO 14); also elsewhere on the board
ETH_CS: J7.3 (CS), R10.2, U1.12 (GPIO 10)
ETH_INT: J7.8 (INT), U1.7 (GPIO 5)
ETH_MISO: J7.5 (MISO), U1.14 (GPIO 12)
ETH_MOSI: J7.4 (MOSI), U1.13 (GPIO 11)
ETH_RST: J7.7 (RESET), R11.2, U1.8 (GPIO 6)
ETH_SCK: J7.6 (SCK), U1.38 (GPIO 13)
GND: C5.2, C12.2, C13.2, C14.2, C15.2, J4.2 (GND), J5.2 (GND), J6.2 (GND), J7.2 (GND), U1.1 (GND), U1.26 (GND), U1.39 (GND); also elsewhere on the board
GPS_RX_CABLE: J4.4 (from GPS TX); also elsewhere on the board
GPS_RX_MCU: U1.9 (GPIO 7); also elsewhere on the board
GPS_TX_CABLE: J4.3 (to GPS RX); also elsewhere on the board
GPS_TX_MCU: U1.10 (GPIO 8); also elsewhere on the board
IMU_SCL: J5.4 (SCL), R13.2, U1.32 (GPIO 19)
IMU_SDA: J5.3 (SDA), R12.2, U1.33 (GPIO 18)
TACH_MCU: U1.11 (GPIO 9); also elsewhere on the board
TEENSY_VIN: U1.25 (VIN); also elsewhere on the board

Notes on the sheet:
Teensy 4.1 / expansion connectors
U1 pad numbering: LEFT 1..24 and RIGHT 25..48, top to bottom viewed from above; USB at top.
External modules not integrated. J6 carries LOGIC, never attach CANH/CANL here. J7 is a custom harness.
No direct oil/coolant ADC conditioning in Rev A. Optional modules must be 3.3V logic.
Do not independently USB-power GPS while attached; it can backfeed its supply or UART.



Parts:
C6, C7, C8, C9: 100nF; C_0805_2012Metric_Pad1.18x1.45mm_HandSolder
D3, D4: PESD5V0S1BA; D_SOD-323
J2: CROWPANEL J10 ONLY; TerminalBlock_Phoenix_MKDS-1,5-4-5.08_1x04_P5.08mm_Horizont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
R1, R2: 100; R_0805_2012Metric_Pad1.20x1.40mm_HandSolder
R3, R4: 47k; R_0805_2012Metric_Pad1.20x1.40mm_HandSolder
U4, U5: SN74LVC1T45; SOT-23-6_Handsoldering

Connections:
+3V3_MCU: C6.1, C8.1, R3.1, U4.1 (VCCA), U4.5 (DIR HIGH), U5.1 (VCCA); also elsewhere on the board
+5V_SCREEN: C7.1, C9.1, J2.2 (+5V OUT), R4.1, U4.6 (VCCB), U5.6 (VCCB); also elsewhere on the board
DASH_RX_5V: R2.2, U5.4 (B (RX in))
DASH_RX_CABLE: D4.1, J2.3 (RX from panel), R2.1, R4.2
DASH_RX_MCU: U5.3 (A (RX out)); also elsewhere on the board
DASH_TX_5V: R1.1, U4.4 (B (TX out))
DASH_TX_CABLE: D3.1, J2.4 (TX to panel), R1.2
DASH_TX_MCU: R3.2, U4.3 (A (TX in)); also elsewhere on the board
GND: C6.2, C7.2, C8.2, C9.2, D3.2, D4.2, J2.1 (GND), U4.2 (GND), U5.2 (GND), U5.5 (DIR LOW); also elsewhere on the board

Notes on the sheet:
CrowPanel Advance J10: 5V power and translated UART
J2 pin3 receives screen TXD0_H; J2 pin4 drives screen RXD0_H. Direction is relative to THIS PCB.
Use the screen ADVANCE J10 5V input header. NEVER connect +5V to screen J2/HY2.0 3V3_OUT.
U4 DIR=HIGH: 3V3 A -> 5V B. U5 DIR=LOW: 5V B -> 3V3 A. Ioff/VCC isolation on translators.
UART TTL, NOT RS232/RS485. Long trunk-to-cabin cable at 921600 baud is NOT yet validated.

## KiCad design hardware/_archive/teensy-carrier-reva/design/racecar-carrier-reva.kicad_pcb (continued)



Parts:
C10: 100nF; C_0805_2012Metric_Pad1.18x1.45mm_HandSolder
C11: 1nF; C_0805_2012Metric_Pad1.18x1.45mm_HandSolder
D5: PESD5V0S1BA; D_SOD-323
J3: EXTERNAL OPTO OUTPUT; TerminalBlock_Phoenix_MKDS-1,5-2-5.08_1x02_P5.08mm_Horizont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
R5: 1k; R_0805_2012Metric_Pad1.20x1.40mm_HandSolder
R6: 4.7k; R_0805_2012Metric_Pad1.20x1.40mm_HandSolder
R7, R8: 100; R_0805_2012Metric_Pad1.20x1.40mm_HandSolder
R9: 47k; R_0805_2012Metric_Pad1.20x1.40mm_HandSolder
U6: SN74LVC2G17; SOT-23-6_Handsoldering

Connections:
+3V3_MCU: C10.1, R6.1, R9.1, U6.5 (VCC); also elsewhere on the board
GND: C10.2, C11.2, D5.2, J3.1 (GND), U6.2 (GND); also elsewhere on the board
GPS_RX_CABLE: R7.1; also elsewhere on the board
GPS_RX_FILTER: R7.2, R9.2, U6.3 (2A GPS RX)
GPS_RX_MCU: U6.4 (2Y GPS RX); also elsewhere on the board
GPS_TX_CABLE: R8.2; also elsewhere on the board
GPS_TX_MCU: R8.1; also elsewhere on the board
TACH_CABLE: D5.1, J3.2 (OPTO OUT), R5.1, R6.2
TACH_FILTER: C11.1, R5.2, U6.1 (1A TACH)
TACH_MCU: U6.6 (1Y TACH); also elsewhere on the board

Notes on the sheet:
External optocoupler and GPS input buffers
J3 accepts external optocoupler transistor output or 0-3.3V/5V logic ONLY; common GND required.
Never raw coil / primary / 12V tach. R6 pulls up to MCU 3V3; R5/C11 low-pass then Schmitt buffer.
U6 channel 2 buffers GPS RX. GPS TX series resistor does not make a 5V or RS232 interface safe.
Pin functions are explicit; block symbols use passive ERC pins. ERC is NOT an electrical safety sign-off.


Board: 2 copper layers, 130.0 x 110.0 mm, 60 parts (0 on the bottom side), 35 nets.

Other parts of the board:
H1, H2, H3, H4: M3 MOUNT; MountingHole_3.2mm_M3

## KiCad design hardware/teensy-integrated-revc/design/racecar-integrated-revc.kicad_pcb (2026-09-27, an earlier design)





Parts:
C23, C24: 100n; C_0805_2012Metric
D6, D8: LM4040 3.0; SOT-23
D7, D9: PMEG2010ER; Nexperia_CFP3_SOD-123W
F3: 100mA PTC; Fuse_1206_3216Metric
J4: OIL 0.5-4.5V; TerminalBlock_Phoenix_MKDS-1,5-3-5.08_1x03_P5.08mm_Horizont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
J5: COOLANT NTC; TerminalBlock_Phoenix_MKDS-1,5-2-5.08_1x02_P5.08mm_Horizont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
J6: AEM 30-0300 ONLY; TerminalBlock_Phoenix_MKDS-1,5-2-5.08_1x02_P5.08mm_Horizont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
R14, R15, R17, R18: 20k 0.1%; R_0805_2012Metric
R16, R19: 1k 1%; R_0805_2012Metric

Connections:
+5V_MAIN: F3.1; also elsewhere on the board
+5V_SENSOR: F3.2, J4.1 (5V OUT)
AFR_CLAMP: D8.1 (K), D9.1 (K), R17.2, R18.1, R19.1
AFR_FILTER: C24.1, R19.2; also elsewhere on the board
AFR_SIGNAL: J6.1 (WHITE SIG+), R17.1
GND: C23.2, C24.2, D6.2 (A), D6.3 (A/NC), D7.2 (A), D8.2 (A), D8.3 (A/NC), D9.2 (A), J4.2 (RETURN), J5.2 (RETURN), J6.2 (BROWN RETURN), R15.2, R18.2; also elsewhere on the board
NTC_SIGNAL: J5.1 (NTC); also elsewhere on the board
OIL_CLAMP: D6.1 (K), D7.1 (K), R14.2, R15.1, R16.1
OIL_FILTER: C23.1, R16.2; also elsewhere on the board
OIL_SIGNAL: J4.3 (SIGNAL), R14.1

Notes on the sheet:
REV C / ANALOG-1
Prototype circuit; manufacturer pin names/MPNs recorded in components.json and BOM.csv.
Supply grounds shared. Analog shunts precede powered-off isolation. New oil/NTC conversion and WiFi firmware required.
NEVER coil/injector tach; NEVER screen 3V3_OUT as power input. Cut Teensy VUSB-VIN. CR2032 is not rechargeable.

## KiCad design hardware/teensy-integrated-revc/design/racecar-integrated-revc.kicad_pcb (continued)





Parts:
C25, C26, C27: 100n; C_0805_2012Metric
D10: LM4040 3.0; SOT-23
D11, D12: PMEG2010ER; Nexperia_CFP3_SOD-123W
R20, R21: 20k 0.1%; R_0805_2012Metric
R22: 1k 1%; R_0805_2012Metric
R23: 150 1%; R_0805_2012Metric
R24: 2.49k 0.1%; R_0805_2012Metric
U14: LM4040 4.1; SOT-23
U15: TMUX1511; TSSOP-14_4.4x5mm_P0.65mm

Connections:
+3V3_MCU: C27.1, U15.1 (SEL1), U15.4 (SEL2), U15.10 (SEL3), U15.14 (VDD); also elsewhere on the board
+5V_MAIN: D12.2 (A); also elsewhere on the board
AFR_ADC: U15.6 (D2); also elsewhere on the board
AFR_FILTER: U15.5 (S2); also elsewhere on the board
GND: C25.2, C26.2, C27.2, D10.2 (A), D10.3 (A/NC), D11.2 (A), R21.2, U14.2 (A), U14.3 (A/NC), U15.7 (GND), U15.12 (S4), U15.13 (SEL4); also elsewhere on the board
NTC_ADC: U15.8 (D3); also elsewhere on the board
NTC_CLAMP: D10.1 (K), D11.1 (K), R20.2, R21.1, R22.1
NTC_EXC: C26.1, R23.2, R24.1, U14.1 (K)
NTC_FEED: D12.1 (K), R23.1
NTC_FILTER: C25.1, R22.2, U15.9 (S3)
NTC_SIGNAL: R20.1, R24.2; also elsewhere on the board
OIL_ADC: U15.3 (D1); also elsewhere on the board
OIL_FILTER: U15.2 (S1); also elsewhere on the board

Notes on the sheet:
REV C / ANALOG-2
Prototype circuit; manufacturer pin names/MPNs recorded in components.json and BOM.csv.
Supply grounds shared. Analog shunts precede powered-off isolation. New oil/NTC conversion and WiFi firmware required.
NEVER coil/injector tach; NEVER screen 3V3_OUT as power input. Cut Teensy VUSB-VIN. CR2032 is not rechargeable.

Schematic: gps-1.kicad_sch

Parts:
C13, C16, C17, C18: 100n; C_0805_2012Metric
C14: 10u; C_0805_2012Metric
C15: 100pF C0G; C_0402_1005Metric
D3: RF ESD; D_SOD-882
J8: GPS SMA FEMALE; SMA_Amphenol_901-143_Horizontal
L1: 27nH RF choke; L_0402_1005Metric
R3: 10R 1%; R_0805_2012Metric
U8: NEO-M9N-00B; ublox_NEO
U9: TPS2553; SOT-23-6
U10: SN74LVC1G125; SOT-23-5

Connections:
+3V3_AUX: C13.1, C14.1, C16.1, C18.1, U8.2 (D_SEL), U8.22 (V_BCKP), U8.23 (VCC), U9.1 (IN), U9.3 (EN), U9.5 (ILIM), U10.5 (VCC); also elsewhere on the board
ANT_BIAS: C17.1, L1.2, R3.2
ANT_SWITCH: R3.1, U9.6 (OUT)
GND: C13.2, C14.2, C16.2, C17.2, C18.2, D3.2, J8.2, U8.4 (EXTINT), U8.7 (V_USB), U8.10 (GND), U8.12 (GND), U8.13 (GND), U8.24 (GND), U9.2 (GND), U10.1 (OE_N), U10.3 (GND); also elsewhere on the board
GPS_RX_AUX: U8.21 (RXD), U10.4 (Y)
GPS_TX_AUX: U8.20 (TXD); also elsewhere on the board
GPS_TX_MCU: U10.2 (A); also elsewhere on the board
RF_ANT: C15.1, D3.1, J8.1, L1.1
RF_GNSS: C15.2, U8.11 (RF_IN)

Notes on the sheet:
REV C / GPS-1
Prototype circuit; manufacturer pin names/MPNs recorded in components.json and BOM.csv.
Supply grounds shared. Analog shunts precede powered-off isolation. New oil/NTC conversion and WiFi firmware required.
NEVER coil/injector tach; NEVER screen 3V3_OUT as power input. Cut Teensy VUSB-VIN. CR2032 is not rechargeable.

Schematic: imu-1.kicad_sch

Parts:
C9, C11: 100n; C_0805_2012Metric
C10: 10n; C_0805_2012Metric
C12: 2.2n; C_0805_2012Metric
R1, R2: 4.7k 1%; R_0805_2012Metric
U7: MPU-6050; InvenSense_QFN-24_4x4mm_P0.5mm

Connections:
+3V3_MCU: C9.1, C10.1, R1.1, R2.1, U7.8 (VLOGIC), U7.13 (VDD); also elsewhere on the board
GND: C9.2, C10.2, C11.2, C12.2, U7.1 (CLKIN), U7.9 (AD0), U7.11 (FSYNC), U7.18 (GND); also elsewhere on the board
IMU_CPOUT: C12.1, U7.20 (CPOUT)
IMU_REGOUT: C11.1, U7.10 (REGOUT)
IMU_SCL: R2.2, U7.23 (SCL); also elsewhere on the board
IMU_SDA: R1.2, U7.24 (SDA); also elsewhere on the board

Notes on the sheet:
REV C / IMU-1
Prototype circuit; manufacturer pin names/MPNs recorded in components.json and BOM.csv.
Supply grounds shared. Analog shunts precede powered-off isolation. New oil/NTC conversion and WiFi firmware required.
NEVER coil/injector tach; NEVER screen 3V3_OUT as power input. Cut Teensy VUSB-VIN. CR2032 is not rechargeable.

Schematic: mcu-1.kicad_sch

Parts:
BT1: CR2032 HOLDER; BatteryHolder_Keystone_1058_1x2032
C7, C8: 100n; C_0805_2012Metric
J7: CAN MODULE LOGIC; JST_XH_B4B-XH-A_1x04_P2.50mm_Vertical
J9: TO TEENSY VBAT/GND; JST_XH_B2B-XH-A_1x02_P2.50mm_Vertical

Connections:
+3V3_MCU: C7.1, C8.1, J7.1; also elsewhere on the board
CAN_RX: J7.4; also elsewhere on the board
CAN_TX: J7.3; also elsewhere on the board
GND: BT1.2 (CELL-), C7.2, C8.2, J7.2, J9.2; also elsewhere on the board
VBAT_CELL: BT1.1 (CELL+), J9.1

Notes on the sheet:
REV C / MCU-1
Prototype circuit; manufacturer pin names/MPNs recorded in components.json and BOM.csv.
Supply grounds shared. Analog shunts precede powered-off isolation. New oil/NTC conversion and WiFi firmware required.
NEVER coil/injector tach; NEVER screen 3V3_OUT as power input. Cut Teensy VUSB-VIN. CR2032 is not rechargeable.

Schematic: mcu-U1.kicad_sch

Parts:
U1: Teensy 4.1 SOCKETED; Teensy41_Socket

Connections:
+3V3_MCU: U1.15 (+3V3_MCU), U1.27 (+3V3_MCU); also elsewhere on the board
AFR_ADC: U1.31 (P20); also elsewhere on the board
CAN_RX: U1.28 (P23); also elsewhere on the board
CAN_TX: U1.29 (P22); also elsewhere on the board
DASH_RX_MCU: U1.36 (P15); also elsewhere on the board
DASH_TX_MCU: U1.37 (P14); also elsewhere on the board
GND: U1.1 (GND), U1.26 (GND), U1.39 (GND); also elsewhere on the board
GPS_RX_MCU: U1.9 (P7); also elsewhere on the board
GPS_TX_MCU: U1.10 (P8); also elsewhere on the board
IMU_SCL: U1.32 (P19); also elsewhere on the board
IMU_SDA: U1.33 (P18); also elsewhere on the board
NET_CS_MCU: U1.12 (P10); also elsewhere on the board
NET_IRQ_MCU: U1.7 (P5); also elsewhere on the board
NET_MISO_MCU: U1.14 (P12); also elsewhere on the board
NET_MOSI_MCU: U1.13 (P11); also elsewhere on the board
NET_RESET_ASSERT: U1.8 (P6); also elsewhere on the board
NET_SCK_MCU: U1.38 (P13); also elsewhere on the board
NTC_ADC: U1.34 (P17); also elsewhere on the board
OIL_ADC: U1.35 (P16); also elsewhere on the board
TACH_MCU: U1.11 (P9); also elsewhere on the board
TEENSY_VIN: U1.25 (TEENSY_VIN); also elsewhere on the board

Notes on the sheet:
REV C / MCU-U1
Prototype circuit; manufacturer pin names/MPNs recorded in components.json and BOM.csv.
Supply grounds shared. Analog shunts precede powered-off isolation. New oil/NTC conversion and WiFi firmware required.
NEVER coil/injector tach; NEVER screen 3V3_OUT as power input. Cut Teensy VUSB-VIN. CR2032 is not rechargeable.

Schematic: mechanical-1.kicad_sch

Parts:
H1, H2, H3, H4: M3 MOUNT; MountingHole_3.2mm_M3
TP1: GND; TestPoint_THTPad_D2.0mm_Drill1.0mm
TP2: +5V_MAIN; TestPoint_THTPad_D2.0mm_Drill1.0mm
TP3: +3V3_AUX; TestPoint_THTPad_D2.0mm_Drill1.0mm
TP4: +3V3_NET; TestPoint_THTPad_D2.0mm_Drill1.0mm
TP5: +3V3_MCU; TestPoint_THTPad_D2.0mm_Drill1.0mm

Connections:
+3V3_AUX: TP3.1; also elsewhere on the board
+3V3_MCU: TP5.1; also elsewhere on the board
+3V3_NET: TP4.1; also elsewhere on the board
+5V_MAIN: TP2.1; also elsewhere on the board
GND: TP1.1; also elsewhere on the board

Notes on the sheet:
REV C / MECHANICAL-1
Prototype circuit; manufacturer pin names/MPNs recorded in components.json and BOM.csv.
Supply grounds shared. Analog shunts precede powered-off isolation. New oil/NTC conversion and WiFi firmware required.
NEVER coil/injector tach; NEVER screen 3V3_OUT as power input. Cut Teensy VUSB-VIN. CR2032 is not rechargeable.

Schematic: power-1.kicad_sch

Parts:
C1: 100uF 50V; CP_Radial_D8.0mm_P3.50mm
C2: 470uF 10V; CP_Radial_D8.0mm_P3.50mm
C3, C5: 100n; C_0805_2012Metric
C4, C6: 10u; C_0805_2012Metric
D1: SMBJ20CA; D_SMB
D2: SS14; D_SMA
F1: 5A fuse; Fuse_Littelfuse-NANO2-451_453
F2: 4A fuse; Fuse_Littelfuse-NANO2-451_453
J1: POWER IN; TerminalBlock_Phoenix_MKDS-1,5-2-5.08_1x02_P5.08mm_Horizont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
JP1: MCU POWER; PinHeader_1x02_P2.54mm_Vertical
U2: Pololu D36V50F5; Pololu_D36V50F5
U3, U6: TSR 1-2433; Converter_DCDC_TRACO_TSR-1_THT

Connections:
+3V3_AUX: C4.1, U3.3 (VOUT); also elsewhere on the board
+3V3_NET: C6.1, U6.3 (VOUT); also elsewhere on the board
+5V_MAIN: D2.2 (A), F2.1, U2.1 (VOUT), U2.2 (VOUT); also elsewhere on the board
+5V_SCREEN: C2.1, F2.2; also elsewhere on the board
GND: C1.2, C2.2, C3.2, C4.2, C5.2, C6.2, D1.2, J1.2 (GND), U2.3 (GND), U2.4 (GND), U2.5 (GND), U2.6 (GND), U3.2 (GND), U6.2 (GND); also elsewhere on the board
TEENSY_VIN: JP1.2; also elsewhere on the board
VIN_DIODE: D2.1 (K), JP1.1
VIN_FUSED: D1.1, F1.2, U2.7 (VIN), U2.8 (VIN)
VIN_PROTECTED: C1.1, C3.1, C5.1, U2.9 (VRP), U2.10 (VRP), U3.1 (VIN), U6.1 (VIN)
VIN_RAW: F1.1, J1.1 (10-20V IN)

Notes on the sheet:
REV C / POWER-1
Prototype circuit; manufacturer pin names/MPNs recorded in components.json and BOM.csv.
Supply grounds shared. Analog shunts precede powered-off isolation. New oil/NTC conversion and WiFi firmware required.
NEVER coil/injector tach; NEVER screen 3V3_OUT as power input. Cut Teensy VUSB-VIN. CR2032 is not rechargeable.

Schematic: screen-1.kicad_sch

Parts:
C28, C29, C30, C31: 100n; C_0805_2012Metric
D13, D14: UART ESD; D_SOD-323
J2: SCREEN J10 ONLY; TerminalBlock_Phoenix_MKDS-1,5-4-5.08_1x04_P5.08mm_Horizont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
R25, R26: 100 1%; R_0805_2012Metric
R27, R28: 47k 1%; R_0805_2012Metric
U4, U5: SN74LVC1T45; SOT-23-6

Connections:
+3V3_MCU: C28.1, C30.1, R27.1, U4.1 (VCCA), U4.5 (DIR), U5.1 (VCCA); also elsewhere on the board
+5V_SCREEN: C29.1, C31.1, J2.2 (5V OUT), R28.1, U4.6 (VCCB), U5.6 (VCCB); also elsewhere on the board
DASH_RX_5V: R26.2, U5.4 (B)
DASH_RX_CABLE: D14.1, J2.3 (RX FROM), R26.1, R28.2
DASH_RX_MCU: U5.3 (A); also elsewhere on the board
DASH_TX_5V: R25.1, U4.4 (B)
DASH_TX_CABLE: D13.1, J2.4 (TX TO), R25.2
DASH_TX_MCU: R27.2, U4.3 (A); also elsewhere on the board
GND: C28.2, C29.2, C30.2, C31.2, D13.2, D14.2, J2.1 (GND), U4.2 (GND), U5.2 (GND), U5.5 (DIR); also elsewhere on the board

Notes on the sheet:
REV C / SCREEN-1
Prototype circuit; manufacturer pin names/MPNs recorded in components.json and BOM.csv.
Supply grounds shared. Analog shunts precede powered-off isolation. New oil/NTC conversion and WiFi firmware required.
NEVER coil/injector tach; NEVER screen 3V3_OUT as power input. Cut Teensy VUSB-VIN. CR2032 is not rechargeable.

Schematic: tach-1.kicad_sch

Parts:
C19: 1n; C_0805_2012Metric
C20, C21: 100n; C_0805_2012Metric
D4: LM4040 2.5; SOT-23
D5: PMEG2010ER; Nexperia_CFP3_SOD-123W
J3: TACH INPUT; TerminalBlock_Phoenix_MKDS-1,5-2-5.08_1x02_P5.08mm_Horizont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
Q1: MMBT3904; SOT-23
R4: 180k 1%; R_0805_2012Metric
R5: 22k 1%; R_0805_2012Metric
R6: 240k 1%; R_0805_2012Metric
R7, R10: 10k 1%; R_0805_2012Metric
R8: 2.2M 1%; R_0805_2012Metric
R9: 4.7k 1%; R_0805_2012Metric
R11: 100k 1%; R_0805_2012Metric
U11: LM2903B; SOIC-8_3.9x4.9mm_P1.27mm

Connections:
+5V_MAIN: C21.1, R6.1, R9.1, U11.8 (VCC); also elsewhere on the board
GND: C19.2, C20.2, C21.2, D4.2 (A), D4.3 (A/NC), D5.2 (A), J3.2 (RETURN), Q1.2 (E), R5.2, R7.2, R11.2, U11.4 (GND), U11.5 (IN2+); also elsewhere on the board
TACH_BASE: Q1.1 (B), R10.2, R11.1
TACH_CMP: R8.1, R9.2, R10.1, U11.1 (OUT1)
TACH_IN: J3.1 (SIGNAL), R4.1
TACH_LED_K: Q1.3 (C); also elsewhere on the board
TACH_REF: C20.1, R6.2, R7.1, U11.2 (IN1-), U11.6 (IN2-)
TACH_SENSE: C19.1, D4.1 (K), D5.1 (K), R4.2, R5.1, R8.2, U11.3 (IN1+)

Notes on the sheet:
REV C / TACH-1
Prototype circuit; manufacturer pin names/MPNs recorded in components.json and BOM.csv.
Supply grounds shared. Analog shunts precede powered-off isolation. New oil/NTC conversion and WiFi firmware required.
NEVER coil/injector tach; NEVER screen 3V3_OUT as power input. Cut Teensy VUSB-VIN. CR2032 is not rechargeable.

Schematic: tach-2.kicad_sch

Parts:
C22: 100n; C_0805_2012Metric
R12: 680 1%; R_0805_2012Metric
R13: 4.7k 1%; R_0805_2012Metric
U12: VO617A-3; SMDIP-4_W9.53mm
U13: SN74LVC2G17; SOT-23-6

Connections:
+3V3_MCU: C22.1, R13.1, U13.5 (VCC); also elsewhere on the board
+5V_MAIN: R12.1; also elsewhere on the board
GND: C22.2, U12.3 (E), U13.2 (GND); also elsewhere on the board
GPS_RX_MCU: U13.4 (2Y); also elsewhere on the board
GPS_TX_AUX: U13.3 (2A); also elsewhere on the board
TACH_LED_A: R12.2, U12.1 (LED A)
TACH_LED_K: U12.2 (LED K); also elsewhere on the board
TACH_MCU: U13.6 (1Y); also elsewhere on the board
TACH_OPTO: R13.2, U12.4 (C), U13.1 (1A)

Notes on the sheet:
REV C / TACH-2
Prototype circuit; manufacturer pin names/MPNs recorded in components.json and BOM.csv.
Supply grounds shared. Analog shunts precede powered-off isolation. New oil/NTC conversion and WiFi firmware required.
NEVER coil/injector tach; NEVER screen 3V3_OUT as power input. Cut Teensy VUSB-VIN. CR2032 is not rechargeable.

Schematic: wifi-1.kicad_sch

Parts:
C32: 10u; C_0805_2012Metric
C33, C35: 100n; C_0805_2012Metric
C34: 1u; C_0805_2012Metric
Q2: MMBT3904; SOT-23
R29, R30, R31, R36: 10k 1%; R_0805_2012Metric
R32: 100k 1%; R_0805_2012Metric
R33, R34, R35: 33 1%; R_0805_2012Metric
R37: 47k 1%; R_0805_2012Metric
U17: SN74LVC125A; TSSOP-14_4.4x5mm_P0.65mm
U18: SN74LVC2G125; VSSOP-8_2.3x2mm_P0.5mm

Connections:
+3V3_MCU: R36.1, U18.8 (VCC); also elsewhere on the board
+3V3_NET: C32.1, C33.1, C35.1, R29.1, R30.1, U17.13 (4OE_N), U17.14 (VCC); also elsewhere on the board
GND: C32.2, C33.2, C34.2, C35.2, Q2.2 (E), R32.2, R37.2, U17.1 (1OE_N), U17.4 (2OE_N), U17.7 (GND), U17.10 (3OE_N), U17.12 (4A), U18.1 (1OE_N), U18.4 (GND), U18.7 (2OE_N); also elsewhere on the board
NET_BOOT: R30.2; also elsewhere on the board
NET_CS: R33.2; also elsewhere on the board
NET_CS_MCU: R36.2, U17.2 (1A); also elsewhere on the board
NET_CS_PRE: R33.1, U17.3 (1Y)
NET_EN: C34.1, Q2.3 (C), R29.2; also elsewhere on the board
NET_IRQ: U18.6 (2A); also elsewhere on the board
NET_IRQ_MCU: U18.5 (2Y); also elsewhere on the board
NET_MISO: U18.2 (1A); also elsewhere on the board
NET_MISO_MCU: U18.3 (1Y); also elsewhere on the board
NET_MOSI: R34.2; also elsewhere on the board
NET_MOSI_MCU: U17.5 (2A); also elsewhere on the board
NET_MOSI_PRE: R34.1, U17.6 (2Y)
NET_RESET_ASSERT: R31.1; also elsewhere on the board
NET_RESET_BASE: Q2.1 (B), R31.2, R32.1
NET_SCK: R35.2; also elsewhere on the board
NET_SCK_MCU: R37.1, U17.9 (3A); also elsewhere on the board
NET_SCK_PRE: R35.1, U17.8 (3Y)

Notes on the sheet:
REV C / WIFI-1
Prototype circuit; manufacturer pin names/MPNs recorded in components.json and BOM.csv.
Supply grounds shared. Analog shunts precede powered-off isolation. New oil/NTC conversion and WiFi firmware required.
NEVER coil/injector tach; NEVER screen 3V3_OUT as power input. Cut Teensy VUSB-VIN. CR2032 is not rechargeable.


Board: 2 copper layers, 130.0 x 140.0 mm, 136 parts (0 on the bottom side), 76 nets.

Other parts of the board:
C36, C37: 100n; C_0805_2012Metric
J10: NET 3V3 UART SERVICE; PinHeader_2x03_P2.54mm_Vertical
R38, R39: 47k 1%; R_0805_2012Metric
U16: ESP32-S3-WROOM-1-N8R2; ESP32-S3-WROOM-1
U19: SN74LVC1G125; SOT-23-5

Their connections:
+3V3_MCU: C36.1; also elsewhere on the board
+3V3_NET: C37.1, J10.2, U16.2, U19.5; also elsewhere on the board
GND: C36.2, C37.2, J10.1, R38.2, R39.2, U16.1, U16.40, U16.41, U19.1, U19.3; also elsewhere on the board
NET_BOOT: J10.5, U16.27; also elsewhere on the board
NET_CS: U16.18; also elsewhere on the board
NET_EN: J10.6, U16.3; also elsewhere on the board
NET_IRQ: R38.1, U16.22; also elsewhere on the board
NET_MISO: R39.1, U16.21; also elsewhere on the board
NET_MOSI: U16.19; also elsewhere on the board
NET_SCK: U16.20; also elsewhere on the board
NET_UART_EXT_RX: J10.4, U19.2
NET_UART_RX: U16.36, U19.4
NET_UART_TX: J10.3, U16.37

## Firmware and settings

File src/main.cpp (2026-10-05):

// racecar-35 dash firmware — GPS + MS3Pro CAN + IMU to dash bridge
//
// Reads u-blox GNSS over Serial2 (pin 7=RX2, pin 8=TX2), the MS3Pro
// MegaSquirt ECU over CAN1 (pin 22=TX, pin 23=RX, via SN65HVD230
// 3.3V transceiver), and an MPU-6050 IMU over Wire (pin 18=SDA, 19=SCL),
// then forwards all three to the CrowPanel ESP32 dash over Serial3 (pin
// 14=TX3, pin 15=RX3 -> CrowPanel UART0).
//
// Wire format on Serial3, 115200 8N1, '\n'-terminated, line types:
//
//   GPS,<fix>,<sats>,<lat_deg>,<lon_deg>,<speed_mph>,<heading_deg>,<gps_status>
//   ENG,<rpm>,<oil_psi_x10>,<coolant_f_x10>
//   ECU,<rpm>,<clt_f_x10>,<map_x10>,<tps_x10>,<afr_x10>,<iat_f_x10>,<bat_x10>   [planned]
//   IMU,<ax>,<ay>,<az>,<gx>,<gy>,<gz>
//   SD,REC,<0|1>,<filename>,<samples>     emitted on session open/close + 1 Hz during
//   CLD,<live_ok>,<queue_depth>          emitted whenever either field changes (cloud status)
//
// Example: GPS,3,12,40.123456,-74.123456,67.5,123.4,2
//          ENG,3450,650,2185
//          ECU,3450,1850,420,150,145,720,138
//          IMU,0.02,-0.98,0.12,1.3,-0.5,0.2
//
// ECU is planned — emitted once the MS3 CAN transceiver (SN65HVD230) is wired
// to CAN1 (pin 22 TX, pin 23 RX) and FlexCAN decoding lands here. Fields are
// MS3-derived: coolant, MAP, TPS, AFR, IAT, battery. -1 in any slot means
// "MS3 doesn't broadcast / didn't broadcast yet". The dash uses these when
// settings.sensor_type == 1 (MegaSquirt); ENG fields are used when == 0 (Direct).
//
// GPS fields:
//   fix          0=None 1=DR 2=2D 3=3D 4=3D+DR 5=Time-only
//   sats         satellites in view
//   lat,lon      decimal degrees, 6 decimals
//   speed_mph    ground speed in mph, 1 decimal
//   heading_deg  heading of motion in degrees, 1 decimal
//   gps_status   0=OFF 1=RAW 2=OK 3=STALE (see gpsStatus())
//
// ENG fields:
//   rpm          integer engine RPM, derived from tach pulse frequency
//                with RPM_PULSES_PER_REV. Reports 0 when no pulses for
//                ~750 ms (engine off / wire disconnected).
//   oil_psi_x10  oil pressure in PSI * 10. Generic 5V 0.5-4.5V transducer
//                on pin A2 through a 10k/20k divider. -1 on sensor fault
//                (open or short — out-of-band voltage at the input).
//   coolant_f_x10 coolant temperature in degF * 10. NTC thermistor on
//                pin A3 with a 150 ohm pullup to 3.3V (sized for the
//                VDO 1600-22 ohm curve). -1 on open/short.
//
// IMU fields (averaged over samples since last emit):
//   ax/ay/az     accelerometer in g, 2 decimals (±2g range, 16384 LSB/g)
//   gx/gy/gz     gyroscope in deg/s, 1 decimal (±250°/s range, 131 LSB/°s)
//
// MPU-6050 mounting note: with the GY-521 board flat, component-side up,
// pins toward the rear of the car:
//   +X = forward (longitudinal, braking/accel)
//   +Y = right (lateral, right-hand turns read negative ay)
//   +Z = up (vertical)

#include <Arduino.h>
#include <Wire.h>
#include <EEPROM.h>
#include "FXUtil.h"        // FlasherX: in-application reflash for Teensy 4.x
extern "C" {
  #include "FlashTxx.h"     // low-level flash primitives (firmware_buffer_init, etc.)
}

// Compile-time firmware version. Increment via the release process when
// publishing new firmware artifacts to firmware/manifest.json on main.
// Format: "MAJOR.MINOR.PATCH" — dash compares versions as semver strings.
// Teensy version is bumped in lock-step with the dash via scripts/release.sh.
#define FIRMWARE_VERSION "0.1.171"

// Networking is WiFi-only on the CrowPanel. No SPI network device.
#include <SdFat.h>
#include "zdeflate_teensy.h"   // compress session blocks BEFORE the UART bottleneck
#include "../crowpanel-arduino/RaceDash/aem_afr.h"
#include <stdarg.h>
#include <TimeLib.h>
#include <SparkFun_u-blox_GNSS_Arduino_Library.h>
#include <FreqMeasureMulti.h>
#include <FlexCAN_T4.h>

namespace {
  HardwareSerial& GPS_SERIAL  = Serial2;            // pins 7 (RX2), 8 (TX2)
  HardwareSerial& DASH_SERIAL = Serial3;            // pin 14 (TX3) -> CrowPanel UART0 RX
  HardwareSerial& VID_SERIAL  = Serial1;            // pin 0 RX1 / pin 1 TX1 -> Pi 5 video box
  constexpr uint32_t GPS_BAUD_TARGET   = 230400;    // RAISED (v0.1.83): 25 Hz UBX-NAV-PVT
                                                    // is ~25 kbit/s; at 38400 that's ~65%
                                                    // util (no headroom -> chronic backlog
                                                    // after any loop stall = GPS STALE). At
                                                    // 230400 it's ~11% -> a 32 KB backlog
                                                    // drains in <1 s.
  constexpr uint32_t GPS_BAUD_PRIMARY  = 38400;     // SparkFun GPS-RTK boards default
  constexpr uint32_t GPS_BAUD_FALLBACK = 9600;      // u-blox factory default
  constexpr uint32_t DASH_BAUD         = 921600;   // up from 115200 — 8× faster for
                                                  // telemetry + file uploads. Both sides
                                                  // must agree; if you mix old + new
                                                  // firmware versions you'll see garbage.
  constexpr uint32_t VID_BAUD          = 115200;  // Pi 5 video box. Slow on purpose: overlay
                                                  // stats are tiny; do NOT share 921600 dash.
  // NEO-M9N supports 25 Hz max nav rate. We push that hard for high-rate
  // logging and live telemetry. M8-class modules cap at 18 Hz — drop this
  // to 18 if you ever swap chips.
  constexpr uint8_t  NAV_RATE_HZ       = 25;

  // Tach input: opto-isolated pulse on pin 9.
  //
  // IMPORTANT (T4.x): the plain `FreqMeasure` library is HARD-WIRED to pin 22
  // on the IMXRT1062 (FlexPWM4 CH0-A) and ignores any pin choice — pin 22 is
  // also our CAN1 TX, so it could never work for the opto tach. We use
  // `FreqMeasureMulti` instead, which takes a pin argument; pin 9 maps to
  // FlexPWM2_2_B and is input-capture capable. See RPM_TACH_PIN below.
  constexpr uint8_t  RPM_TACH_PIN       = 9;
  // PULSES_PER_REV depends on where the tap is taken — calibrate by reading
  // the dash at a known idle (e.g. 800 RPM should display ~800). Common
  // values for a conditioned 4-cyl ECU/cluster tach signal:
  //   2.0 = common starting point; verify against the actual ECU/cluster.
  // NEVER connect coil negative, spark or injector drive to this board.
  // Ignition-derived signals require a separate low-voltage conditioner.
  // This is only the COMPILE-TIME DEFAULT now — the live value is set from the
  // dash (Settings -> "Tach pulses/rev") via `CFG,rpmppr,<value_x10>` and held
  // in g_cfg.rpm_ppr_x10. Think of it as the divider: a tach reading 2x too
  // high needs pulses/rev = 2, 4x too high needs 4, etc.
  constexpr float    RPM_PULSES_PER_REV = 2.0f;
  constexpr uint32_t RPM_TIMEOUT_MS     = 750;      // no pulses in this window -> RPM = 0

  // CAN bus — MS3Pro "Simplified Dash Broadcasting" on 0x5E8 (1512 dec) base
  // ID at 500 kbps. Verified against the official MegaSquirt CAN Broadcast spec
  // (msextra.com) AND a real capture: frame 0x5E8 = 03 FD 00 00 05 62 FF FF
  // decoded to MAP 102.1kPa / RPM 0 / CLT 137.8F / TPS 0 (key-on, engine off).
  // TunerStudio: CAN-Bus/Testmodes -> Dash Broadcasting, Enable=On, Automatic
  // (locks base to 1512, 50 Hz). All fields big-endian.
  // Transceiver: SN65HVD230 (3.3V). CAN1 TX=pin 22, RX=pin 23.
  // Add a 120Ω termination resistor across CAN H/L at the Teensy end;
  // MS3Pro already has one built-in at the ECU end.
  constexpr uint32_t CAN_BAUD           = 500000;
  constexpr uint32_t CAN_STALE_MS       = 2000;     // no frames → reset fields to -1
  constexpr uint32_t CAN_BASE_ID        = 0x5E8;    // MS3Pro Simplified Dash base (1512)
  constexpr uint32_t CAN_BENCH_CORE_ID  = 0x700;    // RC35 bench: rpm/map/tps/TEMP/IAT
  constexpr uint32_t CAN_BENCH_AUX_ID   = 0x701;    // RC35 bench: afr/batt/oil/adv

  // ---- Oil pressure: generic 5V 0.5-4.5V transducer, 150 PSI full scale ----
  // Wired through a 10k / 20k voltage divider so the 0.5-4.5V sensor output
  // arrives at the ADC pin as 0.33-3.00V (safe for the not-5V-tolerant Teensy).
  constexpr int   AEM_AFR_ADC_PIN    = A6;          // pin 20; protected 1:2 input, NOT raw 5V
  constexpr size_t SESSION_LINE_CAP  = 640;         // serializer AND legacy upload line buffers
  constexpr int   OIL_ADC_PIN        = A2;          // physical pin 16
  constexpr float OIL_DIVIDER_RATIO  = 2.0f / 3.0f; // V_adc = V_sensor * R2/(R1+R2)
  constexpr float OIL_V_AT_ZERO_PSI  = 0.5f;        // sensor V at 0 PSI
  constexpr float OIL_V_AT_FULL_PSI  = 4.5f;        // sensor V at full scale
  constexpr float OIL_PSI_FULL_SCALE = 150.0f;      // PSI at OIL_V_AT_FULL_PSI

  // ---- Coolant temp: MH 1600-22 ohm VDO-curve NTC thermistor ----
  // 150 ohm pullup to 3.3V (sized for ~22-700 ohm working range = optimal
  // ADC resolution from 100F to 250F). Steinhart-Hart coefficients fitted
  // to the published 3-point VDO curve (100F=700R, 180F=110R, 250F=22R).
  // CALIBRATE FOR YOUR SPECIFIC SENDER: measure R at 3 known temperatures
  // (ice bath, room, boiling) and re-fit via thinksrs.com NTC calculator.
  constexpr int   COOLANT_ADC_PIN    = A3;          // physical pin 17
  constexpr float COOLANT_PULLUP_OHM = 150.0f;
  constexpr float COOLANT_VREF       = 3.3f;
  constexpr float COOLANT_SH_A       = 2.097e-3f;
  constexpr float COOLANT_SH_B       = 1.346e-4f;
  constexpr float COOLANT_SH_C       = 8.387e-7f;

  // EMA smoothing for both analog sensors. Alpha=0.2 -> ~5-sample time
  // constant at 25 Hz = ~200 ms tau. Kills the per-sample ADC jitter that
  // cheap industrial transducers exhibit without lagging real changes.
  constexpr float SENSOR_EMA_ALPHA   = 0.2f;
}

SFE_UBLOX_GNSS myGNSS;

// ---------------------------------------------------------------------------
// Inbound commands from the CrowPanel dash (Serial3 RX).
// Wire format: line-oriented, '\n'-terminated:
//   REC,<0|1>          start/stop recording
//   TRACK,<name>       set the current track name (sent right before REC,1)
//
// SD logging: on REC,1 we open /sessions/session_<unix>_<track>.ndjson and
// append one NDJSON sample per emit window (25 Hz). On REC,0 we flush +
// close. Cloud upload is always After Race (live streaming was removed): the
// session file lands in /queue/ and is uploaded after the session ends,
// dash-driven (Q,GET) or via the queue drain. Nothing POSTs mid-session.
// ---------------------------------------------------------------------------
static bool     recording_active = false;
static char     current_track[32] = "UNKNOWN";
static uint32_t session_start_ms = 0;
static uint32_t session_start_unix = 0;   // RTC epoch at REC,1 (0 if RTC unset)

// Cloud / live-stream state lives up here because closeSession() (defined in
// the SD section below) references it. Function definitions are in the cloud
// section further down.
static struct {
    char     host[64]   = "";
    uint16_t port       = 80;
    uint8_t  proto      = 0;     // 0=HTTP, 1=HTTPS (NYI), 2=FTP (NYI)
    char     email[64]  = "";
    char     api_key[64] = "";
    bool     rec_sd     = true;
    bool     rec_cl     = false;
    uint8_t  sensor_type = 0;     // 0=Direct (opto tach + ADC), 1=MegaSquirt (CAN)
    bool     aem_afr = false;    // opt-in; old hardware must not sample a floating A6
    uint16_t rpm_ppr_x10 = 20;    // tach pulses/rev x10 (20 = 2.0). Divides the
                                  // opto-tach frequency into RPM in Direct mode.
    int8_t   rpm_smooth  = 0;     // RPM display smoothing trim from the dash slider
    uint8_t  rpm_spike   = 2;     // spike filter: 0=Off 1=Mild 2=Normal 3=Strong (CFG,rpmspk)
    uint8_t  gps_filter  = 2;     // GPS drift filter: 0=Off 1=Mild 2=Normal 3=Strong (CFG,gpsflt)
                                  // (-10..+10): <0 raw/jumpy, 0 baseline, >0 smoother.
    bool     debug_enabled = false;// dash CFG,dbg_on. Default OFF (v0.1.103) —
                                  // diagnostic tool, enabled from Settings when
                                  // needed. When false, NO on-SD .dbg
                                  // health log is written for a session.
    bool     video_en = false;    // dash CFG,viden. Pi 5 video box on Serial1.
} g_cfg;
static aemafr::Reading aem_reading;   // one snapshot shared by UART and SD per emit

// ESP32-S3 dash temp, reported by the dash via the DTEMP line (heat diagnostics).
// Declared here (before handleDashCommand) so the command parser can set it.
static float dash_temp_c = -999.0f;

// BLE OBD-II data relayed by the dash (BTD,<clt_f_x10>,<iat_f_x10>,<volt_x10>,
// 1 Hz while the dongle link is up). Used as the coolant source when
// sensor_type==2 (Bluetooth) so BT coolant lands in the ENG line AND the
// recorded session NDJSON, and as the battery-volts fallback for HLTH/.dbg
// when MS3 CAN isn't connected (the ELM's ATRV reads the car battery).
static int16_t  bt_clt_f_x10 = -1;
static int16_t  bt_iat_f_x10 = -1;
static int16_t  bt_volt_x10  = -1;
static int16_t  bt_tps_x10   = -1;      // throttle % ×10 (PID 0111)
static int16_t  bt_spark_x10 = -1000;   // timing adv °BTDC ×10 (PID 010E); negative is valid — sentinel is -1000
static uint32_t bt_last_ms   = 0;
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
void loop() {
    // Debug: worst loop() PERIOD in the current 1 s window. A long period == the
    // loop stalled (SD/other), the prime suspect for GPS UART overflow -> STALE.
    {
        static uint32_t last_loop_us = 0;
        const uint32_t nu = micros();
        if (last_loop_us) { const uint32_t d = nu - last_loop_us; if (d > dbg_loop_max_us) dbg_loop_max_us = d; }
        last_loop_us = nu;
    }

    // Heartbeat LED so we can see at a glance the Teensy is alive.
    static unsigned long lastBlink = 0;
    if (!can_alt_pins && millis() - lastBlink >= 500) {   // pin 13 = CAN1 RX when CANALT
        lastBlink = millis();
        digitalWrite(LED_BUILTIN, !digitalRead(LED_BUILTIN));
    }

    // Drain commands from the dash (REC, TRACK, SDFORMAT, …) and developer
    // commands from native USB (VER?, USBFWUPDATE).
    pumpDashCommands();
    pumpVidCommands();
    videoHudTick();
    pumpUsbCommands();

    // Drain both RPM sources every loop; emitToDash() picks the active one.
    pumpTach();
    pumpCAN();
    canDiagReport();   // 1 Hz CAN health line to USB serial + dash (self-throttled)
    healthTick();      // 1 Hz temps + battery (heat/brownout diagnostics), always on

    // Periodic SD card recheck while we don't have a healthy mount (card
    // inserted after boot, or missed by SDIO at boot). Don't poke a working card.
    //
    // v0.1.145: this used to call detectSD() every 3 s, and with an EMPTY slot
    // detectSD() blocked ~25 s (see sdCardPresent) — the loop was frozen ~99 %
    // of the time. Now: a ~150 us DAT3 presence probe at 1 Hz, and the SDIO
    // controller is only touched when a card is physically detected. A card
    // that is present but refuses to init (bad/power-starved card, or one still
    // settling right after insertion) gets ONE quick begin() attempt with
    // exponential backoff 2 s -> 30 s, so even that worst case stalls the loop
    // at most ~2 s per 30 s while the dash shows the SdFat error code.
    static uint32_t last_sd_poll_ms   = 0;
    static uint32_t sd_retry_wait_ms  = 0;     // backoff for present-but-failing
    static uint32_t sd_last_try_ms    = 0;
    if ((sd_card_status == SD_CARD_NONE || sd_card_status == SD_CARD_ERROR) &&
        !recording_active &&
        millis() - last_sd_poll_ms >= 1000) {
        last_sd_poll_ms = millis();
        const SdCardStatus before = sd_card_status;
        const bool present = sdCardPresent();
        if (!present) {
            // Empty slot: cheap, no SdFat calls. Reset the backoff so a fresh
            // insertion gets an immediate mount attempt.
            sd_retry_wait_ms = 0;
            if (!sd_slot_empty) {
                // Card was just REMOVED (or a failing card pulled out).
                sd_slot_empty = true;
                sd_last_err = sd_last_data = 0;
                sd_card_status = SD_CARD_NONE;
                Serial.println(F("[sd] poll: card removed (DAT3 low)"));
                emitSdStatus();
            }
        } else if (millis() - sd_last_try_ms >= sd_retry_wait_ms) {
            sd_last_try_ms = millis();
            if (sd_slot_empty) Serial.println(F("[sd] poll: card detected (DAT3 high) — mounting"));
            const uint32_t t0 = millis();
            detectSD(/*quick=*/true);
            const uint32_t dt = millis() - t0;
            if (sd_card_status == SD_CARD_NONE) {
                // Present but won't init: back off 2 -> 4 -> ... -> 30 s.
                sd_retry_wait_ms = sd_retry_wait_ms ? (sd_retry_wait_ms * 2 > 30000 ? 30000 : sd_retry_wait_ms * 2) : 2000;
                Serial.printf("[sd] poll: init failed in %lu ms, next try in %lu s\n",
                              (unsigned long)dt, (unsigned long)(sd_retry_wait_ms / 1000));
            } else {
                sd_retry_wait_ms = 0;
            }
        }
        if (sd_card_status != before) {
            Serial.printf("[sd] poll: status %d -> %d\n",
                          (int)before, (int)sd_card_status);
            emitSdStatus();
            // Queue may have been there all along but unmountable; rescan now.
            if (sd_card_status == SD_CARD_READY) {
                scanQueue();
                emitCloudStatus();
            }
        }
    }

    // Periodic SD + cloud status heartbeat to the dash. Earlier code only
    // emitted SD,* on CHANGE, so if the dash missed an early SD,READY (UART
    // buffer race during boot, OR card came up after the initial emit) the
    // dash would stay stuck on 'no card' on its STATUS page even though the
    // Teensy was happily writing files to /queue/. Re-emitting every 5 s
    // costs ~30 bytes of UART traffic and guarantees the dash converges to
    // ground truth within seconds regardless of any lost transient.
    static uint32_t last_status_emit_ms = 0;
    if (millis() - last_status_emit_ms >= 5000) {
        last_status_emit_ms = millis();
        emitSdStatus();
        emitCloudStatus();
    }

    // Cloud upload tick — queue drainer (no-op while recording / nothing queued).
    cloudTick();

    // IMU accumulate — rate-limited internally to ~250 Hz.
    readIMU();

    // GPS health tracking — exactly one path is active at a time.
    bool freshThisCall = false;
    if (gnss_lib_ok) {
        if (myGNSS.getPVT(0)) {       // non-blocking: returns true ONLY on fresh PVT
            gnss_last_fresh_ms = millis();
            freshThisCall = true;
            dbg_fresh_1s++;           // real PVT rate for the debug health line
        }
        myGNSS.checkCallbacks();      // dispatch NAV-STATUS msss callback (reset forensics)
    } else {
        // Drain raw bytes the lib never claimed. Doesn't try to interpret —
        // we just want to know SOMETHING is on the GPS UART.
        while (GPS_SERIAL.available()) {
            (void)GPS_SERIAL.read();
            gnss_raw_bytes++;
            gnss_last_fresh_ms = millis();
        }
    }

    // Auto-recover if the PVT stream ever goes stale (esp. mid-recording).
    gpsStaleWatchdog();

    // On-SD debug health line (1 Hz, self-rate-limited; no-op when not recording).
    dbgHealth();

    // Emit cadence: on every fresh GPS PVT (== the nav rate, up to 25 Hz), BUT
    // never slower than a 25 Hz FLOOR regardless of GPS. RPM/ENG/IMU come from
    // the tach/CAN/IMU and are INDEPENDENT of GPS — the old 1 Hz fallback made
    // the dash RPM bar update only once/sec whenever GPS went stale (the
    // "RPM haywire" symptom). A steady floor keeps RPM smooth even when GPS is
    // silent; when GPS is stale the (frozen) position just repeats, which the
    // dash already renders as STALE.
    //
    // v0.1.161: floor 40 ms -> 20 ms (50 Hz). The DISPLAY was data-limited, not
    // pixel-limited: the panel repaints near 60 Hz, but every fast channel (tach
    // RPM, MS3 CAN, IMU at 250 Hz, the ADCs) was only crossing the wire 25x/s,
    // so the screen could never show anything fresher. 50 Hz matches the panel's
    // own refresh, and GPS fields simply repeat between their own 25 Hz updates.
    // ~12 KB/s on the 921600 link, still trivial.
    static unsigned long lastEmit = 0;
    const unsigned long emit_floor_ms = 10UL;   // 100 Hz floor, GPS-independent (v0.1.162)
    if (freshThisCall || millis() - lastEmit >= emit_floor_ms) {
        lastEmit = millis();
        emitToDash();
    }

    // 1 Hz GPS diagnostics for the dash GPS settings page:
    // GPSDIAG,<baud>,<lib_ok>,<pvt_age_ms>,<light_recover>,<heavy_rebegin>
    static uint32_t last_gpsdiag_ms = 0;
    if (millis() - last_gpsdiag_ms >= 1000) {
        last_gpsdiag_ms = millis();
        const uint32_t age = (gnss_last_fresh_ms == 0) ? 999999u
                             : (millis() - gnss_last_fresh_ms);
        DASH_SERIAL.printf("GPSDIAG,%lu,%u,%lu,%lu,%lu,%u\n",
                           (unsigned long)gps_baud_now, (unsigned)(gnss_lib_ok ? 1 : 0),
                           (unsigned long)age, (unsigned long)gnss_recover_count,
                           (unsigned long)gnss_reinit_count, (unsigned)gps_nav_hz);
    }
}

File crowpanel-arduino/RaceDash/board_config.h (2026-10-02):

// ===========================================================================
// board_config.h — per-panel hardware bring-up for the racecar-35 dash.
//
// The dash UI / settings / protocol / OTA logic in RaceDash.ino is identical
// across every supported panel. ONLY the RGB pin map + timing + sync
// polarities, the touch I2C pins, the backlight mechanism and the LCD reset
// mechanism differ. Those board-specific values live here, selected at
// COMPILE time via -DDASH_BOARD:
//
//   DASH_BOARD == 51  -> CrowPanel Advance 5.0" (HMI IPS, S3)    -> "crowpanel5adv"
//   DASH_BOARD == 71  -> CrowPanel Advance 7.0" (HMI IPS, S3)    -> "crowpanel7adv"
//
//   RETIRED (hardware scrapped after v0.1.146 — no longer built/published):
//   DASH_BOARD == 7   -> CrowPanel ESP32 7.0" V3.0 (Basic RGB)  -> "crowpanel7"
//   DASH_BOARD == 5   -> CrowPanel ESP32 5.0" V3.0 (Basic RGB)  -> "crowpanel5"
//   Their pin maps are kept below for reference only and are a HARD BUILD
//   ERROR unless -DDASH_ALLOW_RETIRED_BOARDS is also given.
//
// IDENTITY IS BAKED AT THE FIRST USB FLASH. We never auto-detect the panel at
// runtime (a wrong RGB-timing guess = an unrecoverable black screen). The
// binary is built for exactly one panel, so OTA can — and does — only ever
// consume the manifest entry keyed by this board's DASH_BOARD_ID.
//
// Build (both Advance panels are 16 MB modules, so FlashSize=16M):
//   5" Adv:   --build-property "compiler.cpp.extra_flags=-DDASH_BOARD=51"  FlashSize=16M
//   7" Adv:   --build-property "compiler.cpp.extra_flags=-DDASH_BOARD=71"  FlashSize=16M
//
// Sources of truth:
//   7"/5" Basic: Elecrow CrowPanel V3.0 course file gfx_conf.h (CrowPanel_70 /
//                CrowPanel_50). 7" freq_write kept at our field-proven 15 MHz.
//   5" Advance:  Elecrow CrowPanel-Advance-5 repo, example V1.2_and_V1.3
//                (LovyanGFX_Driver.h + main.cpp). N16R8, OPI PSRAM, GT911 on
//                15/16, backlight via an I2C coprocessor at 0x30.
//   7" Advance:  Elecrow CrowPanel-Advance-7 repo. Its LovyanGFX_Driver.h is
//                the SAME shared "..._4_3_5_0_7_0" file as the 5" Advance —
//                identical RGB pin map, porches, polarities, PSRAM framebuffer,
//                GT911 pins and 0x30 coprocessor (verified 2026-09 across every
//                V1.0/V1.2/V1.3-1.5 example + factory source). Only the board id
//                differs; the 7" glass may want its own pclk — see the note.
// ===========================================================================
#pragma once

#ifndef DASH_BOARD
#define DASH_BOARD 71  // default to the 7" ADVANCE if the build flag is absent
#endif

// The Basic panels are retired hardware. Refuse to build them by accident —
// a Basic image flashed onto an Advance = dead touch + garbled RGB.
#if (DASH_BOARD == 7 || DASH_BOARD == 5) && !defined(DASH_ALLOW_RETIRED_BOARDS)
#error "DASH_BOARD 7/5 (CrowPanel Basic) are RETIRED. Build 51 (5\" Advance) or 71 (7\" Advance). Define DASH_ALLOW_RETIRED_BOARDS to override."
#endif

// Backlight is GPIO 2 PWM on the Basic V3.0 panels; the Advance drives it over
// I2C instead (see DASH_IS_ADVANCE). Declared for all; unused on the Advance.
#define DASH_PIN_BL GPIO_NUM_2

// ---------------------------------------------------------------------------
#if DASH_BOARD == 7
// ---------------------------------------------------------------------------
#define DASH_BOARD_ID   "crowpanel7"
#define DASH_BOARD_NAME "crowpanel-7.0"
#define DASH_IS_ADVANCE 0

#define DASH_PIN_D0  GPIO_NUM_15   // B0
#define DASH_PIN_D1  GPIO_NUM_7    // B1
#define DASH_PIN_D2  GPIO_NUM_6    // B2
#define DASH_PIN_D3  GPIO_NUM_5    // B3
#define DASH_PIN_D4  GPIO_NUM_4    // B4
#define DASH_PIN_D5  GPIO_NUM_9    // G0
#define DASH_PIN_D6  GPIO_NUM_46   // G1
#define DASH_PIN_D7  GPIO_NUM_3    // G2
#define DASH_PIN_D8  GPIO_NUM_8    // G3
#define DASH_PIN_D9  GPIO_NUM_16   // G4
#define DASH_PIN_D10 GPIO_NUM_1    // G5
#define DASH_PIN_D11 GPIO_NUM_14   // R0
#define DASH_PIN_D12 GPIO_NUM_21   // R1
#define DASH_PIN_D13 GPIO_NUM_47   // R2
#define DASH_PIN_D14 GPIO_NUM_48   // R3
#define DASH_PIN_D15 GPIO_NUM_45   // R4

#define DASH_PIN_HENABLE GPIO_NUM_41
#define DASH_PIN_VSYNC   GPIO_NUM_40
#define DASH_PIN_HSYNC   GPIO_NUM_39
#define DASH_PIN_PCLK    GPIO_NUM_0
#define DASH_FREQ_WRITE  15000000   // field-proven on our 7" V3.0 (vendor uses 12 MHz)

#define DASH_HSYNC_FRONT_PORCH 40
#define DASH_HSYNC_PULSE_WIDTH 48
#define DASH_HSYNC_BACK_PORCH  40
#define DASH_VSYNC_FRONT_PORCH 1
#define DASH_VSYNC_PULSE_WIDTH 31
#define DASH_VSYNC_BACK_PORCH  13

#define DASH_HSYNC_POLARITY  0
#define DASH_VSYNC_POLARITY  0
#define DASH_PCLK_ACTIVE_NEG 1
#define DASH_DE_IDLE_HIGH    0
#define DASH_PCLK_IDLE_HIGH  0

#define DASH_TOUCH_SDA      19
#define DASH_TOUCH_SCL      20
#define DASH_TOUCH_ROTATION ROTATION_INVERTED
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

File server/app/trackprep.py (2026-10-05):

"""Track geometry pre-render — turn "a line we drove" into a real track.

The 3D drive view (/track3d) can only draw what it knows: a constant-width
ribbon around the driven line. This module bakes, per TRACK (on demand, cached),
what the world actually knows about that track, so the render can show its real
shape, its real width and its real surroundings:

  centreline   from OUR sessions (the line the car drove) or from OpenStreetMap
               (`highway=raceway` ways, which also carry a `width` tag on some
               circuits) — whichever is available
  WIDTH        measured from SATELLITE IMAGERY, not guessed: perpendicular
               brightness/colour profiles along the centreline find the paved
               corridor (asphalt + painted kerbs) and report the true left/right
               distance to its edge, station by station
  elevation    AWS's keyless "terrarium" DEM (and, when the session carries
               `alt_m`, that wins — it is what the car actually saw)
  texture      the satellite mosaic itself, baked to one image so the 3D view
               can drape the REAL asphalt, kerbs, run-off and grass on the
               ground with no tile fetching at view time

Everything is keyless (OSM Overpass, Esri World Imagery, AWS + USGS terrain) and cached
under RACECAR_DATA_DIR so a track is prepared once and then just read.

CLI:
    python3 -m app.trackprep --list-tracks
    python3 -m app.trackprep --osm "Shenandoah Circuit" --track "Summit Point Shenandoah"
    python3 -m app.trackprep --session /data/sessions/u/1714_Summit.ndjson --track "..."
    python3 -m app.trackprep --line line.json --track "My Track"     # [[lat,lon],...]
"""
from __future__ import annotations

import io
import json
import math
import os
import pathlib
import re
import tempfile
import threading
import time
import urllib.parse
import urllib.request
from typing import Iterable, Optional

try:                                  # Pillow/numpy are the only real deps
    import numpy as np
    from PIL import Image
except Exception:                     # pragma: no cover - reported by the caller
    np = None
    Image = None

UA = "racecar-35-trackprep/0.2 (+https://racecar.api.blueuc.com)"
ESRI = ("https://server.arcgisonline.com/ArcGIS/rest/services/"
        "World_Imagery/MapServer/tile/{z}/{y}/{x}")
TERRARIUM = "https://s3.amazonaws.com/elevation-tiles-prod/terrarium/{z}/{x}/{y}.png"
OVERPASS = [
    "https://overpass-api.de/api/interpreter",
    "https://overpass.kumi.systems/api/interpreter",
    "https://overpass.private.coffee/api/interpreter",
]
M_PER_DEG_LAT = 111320.0
TILE = 256


def _require_deps() -> None:
    if np is None or Image is None:
        raise RuntimeError("trackprep needs Pillow and numpy (see app/requirements.txt)")


def slugify(track: str) -> str:
    s = re.sub(r"[^a-z0-9]+", "-", (track or "").lower()).strip("-")
    return s or "track"


# ---------------------------------------------------------------------------
# web-mercator helpers
# ---------------------------------------------------------------------------
def lon_to_x(lon: float, z: int) -> float:
    return (lon + 180.0) / 360.0 * (TILE << z)


def lat_to_y(lat: float, z: int) -> float:
    r = math.radians(max(-85.05112878, min(85.05112878, lat)))
    return (1.0 - math.asinh(math.tan(r)) / math.pi) / 2.0 * (TILE << z)


def x_to_lon(x: float, z: int) -> float:
    return x / (TILE << z) * 360.0 - 180.0


def y_to_lat(y: float, z: int) -> float:
    n = math.pi - 2.0 * math.pi * y / (TILE << z)
    return math.degrees(math.atan(math.sinh(n)))


def metres_per_px(lat: float, z: int) -> float:
    return 156543.03392804097 * math.cos(math.radians(lat)) / (1 << z)


def _get(url: str, timeout: float = 45.0, data: Optional[bytes] = None) -> bytes:
    req = urllib.request.Request(url, data=data, headers={"User-Agent": UA})
    with urllib.request.urlopen(req, timeout=timeout) as r:
        return r.read()


def _cache_get(path: pathlib.Path) -> Optional[bytes]:
    try:
        if path.exists() and path.stat().st_size > 0:
            return path.read_bytes()
    except OSError:
        return None
    return None


def _cache_put(path: pathlib.Path, blob: bytes, min_bytes: int = 64) -> None:
    if len(blob) < min_bytes:            # placeholder / error tile
        return
    try:
        path.parent.mkdir(parents=True, exist_ok=True)
        tmp = path.with_suffix(path.suffix + ".tmp")
        tmp.write_bytes(blob)
        tmp.replace(path)
    except OSError:
        pass
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

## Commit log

2026-05-15 Initial commit: two-MCU dash for racecar-35
    Trunk-side Teensy 4.1 handles GPS (u-blox NEO-M9N @ 25 Hz), tach pulse
    input, MPU-6050 IMU, oil PSI + coolant temp ADCs, W5500 ethernet, and
    built-in SDIO. Cabin-side CrowPanel ESP32-S3 V3.0 renders the dash UI,
    settings, on-screen keyboards, and GPS-driven track picker.
    Bidirectional UART between the two boards carries telemetry (GPS, ENG,
    IMU, TIME, ETH, SD) and dash-issued control (REC, TRACK, TZ, SDFORMAT,
    SETTIME).
    See CLAUDE.md for architecture, WIRING.md for pin-by-pin connections.
    [PanelTest.ino, gfx_conf.h, main.cpp]
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2026-05-16 Phase B + C: cloud upload pipeline + dash CFG sync
    Teensy (src/main.cpp):
    - CFG,<key>,<value> parser \u2014 receives cloud settings from dash
    - httpPost() primitive: POST + headers + chunked file streaming, blocking
    with short timeouts (800 ms connect, 1.5 s response)
    - Live streamer: 2 KB RAM buffer, flushes /stream every 200 ms during a
    Live-mode recording. Failure marks session for queue-on-close.
    - After-race POST: closeSession() POSTs whole file to /upload, deletes
    on 2xx, moves to /queue/ on failure.
    - /queue/ walker: oldest-first, one per 10 s when link up + idle, deletes
    on 2xx, leaves for next pass on failure.
    - HTTP headers: X-API-Key, X-User-Email, X-Session-Id, X-Track-Na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
    [main.cpp]
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2026-05-16 Phase 1: Internet mode (Ethernet/WiFi) + FIRMWARE_VERSION + dash WiFi NTP
    CrowPanel (RaceDash.ino):
    - New SettingId rows at top of settings: ST_INET_MODE, ST_WIFI_SSID,
    ST_WIFI_PASS, ST_WIFI_STATUS (last 3 hidden when mode=Ethernet).
    - New SettingRow::INFO kind for read-only display rows (WiFi status).
    - INET_MODE_NAMES = { 'Ethernet', 'WiFi' }; default 0 (Ethernet).
    - Settings struct: internet_mode (uint8), wifi_ssid[33], wifi_pass[64].
    - NVS keys inet/wssid/wpass; persisted via load/saveSettings.
    - WiFi state machine (WS_OFF/CONNECTING/CONNECTED/FAILED) — declared at
    top of TU per the auto-prototyper rule; tick from loop() at 1 Hz.
    - WS_CONNECTED kicks ESP32 SNTP (configTime, 3 serve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
    [main.cpp]
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2026-05-16 Upload progress modal + cancel-until-reboot
    While the Teensy is uploading a file (after-race POST or queue drain),
    the dash now pops a full-screen blocking modal:
    | |
    | +-----------------------------------------+ |
    | | Uploading session | |
    | | session_1714942567_LimeRock.ndjson | |
    | | | |
    | | [================ ] | |
    | | 12.3 / 19.8 MB 62% | |
    | | | |
    | | [ CANCEL ]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
    [main.cpp]
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2026-05-16 Release v0.1.3 + Teensy: ADC pulldown for disconnected oil/coolant pins
    Teensy (main.cpp):
    - pinMode(OIL_ADC_PIN, INPUT_PULLDOWN) and same for COOLANT_ADC_PIN.
    Floating ADC pins were drifting into the 'valid' 0.5-4.5 V band and
    reporting plausible but fake PSI / coolant readings. Internal pulldown
    forces a disconnected pin to ~0 V so the per-channel fault detector
    (oil: v_sensor < 0.3 V; coolant: raw <= 4) trips reliably and the
    Teensy emits -1, which the dash renders as '---'.
    - External sensor circuits (oil 10k/20k divider, coolant 150 \u03a9 pullup)
    have source impedance much stiffer than the ~50 k\u03a9 internal pulldown
    so they dominate when wired: <5% calibration shift, a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
    [main.cpp]
2026-05-16 STATUS: show dash + teensy firmware versions with mismatch button
    - Teensy emits 'VER,teensy,<version>' at boot AND in reply to 'VER?'.
    - Dash sends 'VER?' on its own boot and whenever the STATUS page opens
    so the value can't be silently stale from a missed boot announcement.
    - New FIRMWARE section bottom-left of STATUS:
    DASH v0.1.4
    TEENSY v0.1.0 (in dark-grey '...' if not received yet)
    MATCH [OK | MISMATCH | ...waiting] (color-coded)
    - When the two firmwares differ, a green 'Resolve version mismatch'
    button appears bottom-right of STATUS. Tap opens the OTA modal.
    (Today that only updates the CrowPanel; Phase 2b will forward the
    Teensy .hex over UART so one t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
    [main.cpp]
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2026-05-16 Phase 2b Commit 2: Dash downloads + UART-forwards teensy.hex (v0.1.6)
    Wires the actual end-to-end Teensy OTA. When the user taps 'UPDATE NOW'
    in the OTA modal:
    1. If Teensy needs update (manifest teensy.version > current teensy_fw_version):
    - HTTPS GET firmware/teensy41-dash.hex
    - 'FWUPDATE' over UART -> wait up to 3s for 'FW,READY,<size>' ack
    - Stream the raw .hex body to Serial (UART0 = dash<->Teensy)
    in 256 B chunks, progress bar at ~2.5 Hz
    - State transitions to TEENSY_WAITING: 12 s pause for Teensy
    flash_move() + reboot
    - 'VER?' is sent; we verify the reply matches manifest version
    2. If CrowPanel needs update (or only CrowPanel): same as befo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
    [main.cpp]
2026-05-16 Phase 2b Commit 3 (bugfixes): FSEC check, CFG c1, parseVerLine echo
    Three bugs that conspired to make the first Phase 2b OTA fail:
    1. lib/FlasherX/FXUtil.cpp: update_firmware_noprompt had a bogus FSEC
    check for IMXRT1062 (Teensy 4.x). Upstream FlasherX deliberately skips
    that check for T4.x because the chip has no FSEC concept \u2014 it's a
    Kinetis/T3.x feature. My copy added it with the wrong expected value
    (0xFFFFFFFF) AND the wrong address (running flash, not staged buffer).
    It failed on every OTA before flash_move() got called, leaving the
    Teensy on the old firmware. Fixed by gating the FSEC check on
    #if defined(KINETISK) || defined(KINETISL) like upstream.
    2. src/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
    [main.cpp]
2026-05-16 Phase 2b fix: 32KB Teensy UART RX buffer + better FlasherX diagnostics
    Root cause of the v0.1.6 -> v0.1.7 Teensy OTA failure:
    - Teensy DASH_SERIAL RX buffer was 2 KB (~22 ms of slack at 921 600 baud)
    - FlasherX flash_write_block() does a 4 KB sector erase whenever the staged
    image crosses a sector boundary, stalling the read loop ~25-100 ms
    - At 921 600 baud, 25-100 ms = 2.3-9.2 KB streaming in while we can't read
    - 2 KB buffer overflows, losing chars MID-LINE on whatever record happens
    to be in flight
    - Next hex line fails parse_hex_line() -> FlasherX aborts before
    flash_move() -> Teensy stays on old firmware -> dash reports
    'teensy reports v0.1.6, expected v0.1.7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
    [main.cpp]
2026-05-16 Phase 2b fix: per-line ACK protocol kills UART corruption
    Prior approaches \u2014 32 KB Teensy RX buffer, smaller dash TX chunks \u2014 still
    saw mid-stream byte loss / partial-line corruption / merged-line garbage
    during the high-throughput hex transfer over 921 600 baud UART. Pattern
    was random and unpredictable, suggesting signal-integrity issues on cheap
    jumper wires + sustained back-to-back transmission with no breathing room.
    Replaced raw byte streaming with per-line ACK:
    Dash side (otaDoTeensyUpdate):
    - Read one Intel HEX line from HTTPS body into a buffer
    - Write line + '\n' to UART, Serial.flush()
    - Wait up to 2 s for 'A\n' or 'FW,ERR,*' from Teensy
    - Repeat for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
    [main.cpp]
2026-05-16 Phase 2b fix v2: pre-buffer teensy.hex into PSRAM before forwarding
    Per-line ACK at 921 600 baud is reliable in principle, but the dash also
    needs to NOT be reading from HTTPS during the slow ACK-paced forward
    loop. The total transfer takes 30-60 s, and GitHub's raw CDN closes
    the HTTPS connection from idleness during that window \u2014 we saw 'teensy
    hex: ran out of stream at 51628 / 524284 B' (~10% through).
    Fix: download the full .hex into PSRAM first (fast, ~3 s for 512 KB
    over WiFi), close the HTTPS connection, THEN do the ACK-paced UART
    forward to the Teensy at our leisure. The CrowPanel has 8 MB PSRAM
    (PSRAM=opi in the FQBN) so a 512 KB buffer is trivial.
    New flow in otaDoTeensyUpda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
    [main.cpp]
2026-05-16 Release v0.1.11: quiet CrowPanel OTA flash path
    The dash update path was still writing flash directly from the HTTPS stream
    while also repainting the OTA modal. During Update.write() flash erases/writes,
    the RGB panel scan-out could catch intermediate draw states and produce hard
    screen flashing.
    Fix CrowPanel self-update path to mirror the Teensy-hex path:
    - Download full crowpanel-dash.bin into PSRAM first.
    - Close HTTPS before touching the OTA partition.
    - Show progress during the download phase only.
    - Switch once to APPLYING, draw the modal once, then perform Update.write()
    from PSRAM in 4 KB chunks with NO LCD redraws during flash writes.
    - Reboot as before after Update.end(true).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
    [main.cpp]
2026-05-16 Release v0.1.12: robust Teensy OTA reboot verifier
    Teensy self-flashing was succeeding, but the dash could still show a false
    failure ('teensy didn't come back — reflash via USB') because the verifier
    waited a fixed 12 seconds, then sent one VER? and only listened for ~2 seconds.
    The wait begins before flash_move() has necessarily finished moving the image
    and rebooting, so a successful update could be reported as failed.
    Fix the OTA wait state:
    - Poll VER? every second for up to 60 seconds.
    - Use a persistent non-blocking UART line parser so short read timeouts can't
    consume/split the VER,teensy,<version> response.
    - Accept optional leading 'v' in version strings.
    - Continue to the Cro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
    [main.cpp]
2026-05-16 Release v0.1.13: OTA verifier test build
    This is intentionally a small release after v0.1.12's robust Teensy OTA
    reboot verifier landed.
    The previous .11 -> .12 update was still driven by the v0.1.11 dash, so it
    could still show the old false failure ('teensy didn't come back') even though
    FlasherX successfully updated the Teensy. The .12 -> .13 update is the first
    real end-to-end test of the new verifier:
    - VER? polled every second for up to 60s
    - persistent UART line parser during reboot wait
    - optional leading 'v' accepted in version strings
    - useful timeout diagnostics if the Teensy genuinely doesn't report target
    No intentional functional changes beyond the version bump/artifact refr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
    [main.cpp]
2026-05-16 Release v0.1.14: start Teensy verifier after FW commit marker
    The .12/.13 verifier still timed out in one real test: the dash began its
    60-second reboot/version wait immediately after the final Intel HEX line ACK.
    That is too early. After EOF, FlasherX still validates the staged image, emits
    FW,COMMITTING, then runs flash_move(); the successful reboot can happen after
    that original 60-second window. The observed behavior matched this exactly:
    first attempt timed out still seeing the old Teensy version, then a second
    check saw the Teensy already updated and skipped straight to the dash update.
    Fixes:
    - After the final line ACK, wait up to 15s for FW,COMMITTING before entering
    the reboot/ve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
    [main.cpp]
2026-05-16 Release v0.1.15: avoid stale Teensy version and don't block after commit
    Field testing showed two distinct OTA verifier problems:
    1. After a false Teensy failure, retrying did not go directly to the dash
    update. The dash still had a stale cached Teensy version, so it believed
    the Teensy needed flashing again until a later VER line refreshed state.
    2. Once FlasherX has accepted the image and emitted FW,COMMITTING, failing
    the entire combined update solely because the dash missed a later VER line
    is the wrong UX. At that point flash_move() has been entered; if the dash
    cannot see the post-reboot VER quickly, continue to the CrowPanel update
    and let the final STATUS page re-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
    [main.cpp]
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2026-05-16 Release v0.1.17: stop reporting unverified Teensy commits as success
    Field testing of v0.1.15/v0.1.16 showed that treating FW,COMMITTING as
    sufficient proof was too optimistic. The dash could report completion even
    though the subsequent STATUS page re-queried the Teensy and still saw the old
    firmware version.
    Fix:
    - Keep FW,COMMITTING as useful evidence that FlasherX accepted the image and
    entered flash_move(), but do not fake teensy_fw_version to the target.
    - If a CrowPanel update is also pending, continue to update the dash, then let
    final STATUS be the source of truth.
    - If this was a Teensy-only update and the target VER is not observed, show an
    honest 'teensy commit unverified'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
    [main.cpp]
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2026-05-16 Release v0.1.19: verify direct Teensy USB FlasherX path
    Local test result before this release:
    - Started from matched v0.1.18.
    - Temporarily bumped Teensy source to v0.1.19 and built locally.
    - Pushed .pio/build/teensy41/firmware.hex over native Teensy USB CDC using
    scripts/teensy_usb_ota.py and the new USBFWUPDATE command.
    - Teensy responded FW,READY, ACKed all 11720 HEX lines, emitted FW,COMMITTING,
    rebooted, and then reported VER,teensy,0.1.19.
    - Transfer phase over USB took about 2 seconds.
    This proves the FlasherX/update_firmware_acked core path and flash_move() work
    when fed over reliable USB. Remaining failures are therefore isolated to the
    CrowPanel->Teensy UART OTA path/timing/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
    [main.cpp]
2026-05-16 Release v0.1.20: be silent on UART during Teensy commit window
    Direct USB testing confirmed FlasherX + flash_move + the per-line ACK protocol
    all work over a reliable link (USB CDC). The remaining CrowPanel->UART->Teensy
    OTA failures are therefore in the UART side of the protocol or its timing.
    One likely contributor: after FW,COMMITTING the dash immediately starts polling
    VER? once per second while the Teensy is physically inside flash_move()
    rewriting its own program flash. Every byte arriving on Teensy UART during
    that window fires an RX interrupt and can perturb the FlexSPI flash sequence.
    - After receiving FW,COMMITTING the dash now stays completely silent on UART
    for an 8s q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
    [main.cpp]
2026-05-16 Release v0.1.21: verify OTA artifact sha256 vs manifest
    Symptom from v0.1.19 -> v0.1.20 testing:
    - Teensy update succeeded (.20).
    - Dash update modal showed progress all the way through, no error, dash
    rebooted, but came back at the OLD version (.19) anyway.
    Root cause: raw.githubusercontent.com's CDN can serve a fresh manifest.json
    while the .bin/.hex artifact endpoint is still on a stale edge cache from the
    previous release. We then download the OLD bin under the NEW version number,
    write it to the OTA partition, and reboot into 'the new image' that is
    actually the old image.
    Fix: parse the sha256 from manifest.json for both crowpanel and teensy
    entries. After downloading each artifact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
    [main.cpp]
2026-05-16 Release v0.1.22: WiFi-via-dash cloud uploads, HTTPS default, test mode
    Phase 3 / cloud upload routing:
    - New UART protocol 'WUP,*' for forwarding NDJSON session files from Teensy to
    Dash over UART. Dash buffers in PSRAM, then HTTPS-POSTs to /upload on the
    configured cloud endpoint using the same headers the Ethernet path uses
    (X-API-Key, X-User-Email, X-Session-Id, X-Track-Name).
    - Per-line 'U' ACK protocol keeps UART throughput safe across PSRAM appends.
    - Dash exposes WUP,READY / WUP,NACK,<reason> / WUP,RESULT,OK|FAIL.
    - closeSession() and drainOneQueued() now route via cloudUploadFile() which
    dispatches to Ethernet httpPost() in inet=0 (Ethernet) mode, and to
    wupForwardFile() in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
    [main.cpp]
2026-05-16 Release v0.1.23: 25 Hz test-mode emit + cloud server stub
    Field testing of v0.1.22's test mode showed the synthetic data was only
    emitting at 1 Hz: emitToDash() only fires when getPVT() returns fresh data
    OR every 1000 ms as a heartbeat. With no real GPS connected the test mode
    path fell into the 1 Hz heartbeat and the dash UI looked frozen.
    Fix: when test_mode_active is true, drop the emit interval to 40 ms so the
    synthetic GPS / RPM / IMU samples stream at 25 Hz, matching the real-GPS
    cadence. The dash page redraws at ~50 Hz so element-level changes now
    animate at 25 Hz (>= 15 Hz target).
    Also lands the FastAPI cloud receiver under server/:
    - POST /upload (whole-file AfterRace, overwrit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
    [main.cpp]
2026-05-16 Release v0.1.24: NJMP Thunderbolt synthetic track in test mode
    Replace the earlier placeholder circle near Lime Rock with a realistic
    NJ Motorsports Park - Thunderbolt Raceway polyline so test mode produces
    data that looks like an actual lap.
    - 18 waypoints traced around Thunderbolt's 2.25 mi / 14-turn layout.
    Coordinates roughly correct, geometry hand-tuned. Easy to refine the
    trace by editing lat/lon/mph/lat_g entries in NJMP_THUNDERBOLT[].
    - Per-waypoint target speed (55 mph in T1, up to 150 mph at end of front
    straight) and signed lateral G (positive = right turn).
    - Speed, position, and lateral G linearly interpolate between adjacent
    waypoints so accel into a brake zone and bac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
    [main.cpp]
2026-05-16 Release v0.1.25: cap dash page redraw to 25 Hz to reduce screen tearing
    At 25 Hz Teensy telemetry, the dash was repainting the big dynamic elements
    (speed digit, RPM bar, ENG/GPS strings) up to twice per fresh telemetry frame
    because the dash redraw was running at 50 Hz. Any repaint that landed
    mid-LCD-scan produced a visible tear on those large screen areas.
    Drop the PAGE_DASH redraw cadence from 20 ms (50 Hz) to 40 ms (25 Hz) so each
    fresh sample is rendered exactly once. This doesn't eliminate tearing
    entirely (that needs sprite-buffer or page-flip on vsync, deferred), but
    roughly halves the tear events per second and makes the screen feel calmer.
    Other pages keep their original cadence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
    [main.cpp]
2026-05-16 Release v0.1.26: integer-only MPH on dash + slight inward shift
    Two related polish changes:
    1. Always render speed as integer MPH. The previous code switched to %.1f
    when speed was < 100, which made '99.9' visually wider than '100': the
    decimal point eats a full character cell at Font7 size 4. Result was that
    two-digit speeds came uncomfortably close to the right panel edge while
    three-digit speeds had plenty of room.
    2. Shift the speed centre from x=600 to x=580 (-20 px) and tighten the
    bg-pad width from 400 to 360. With max-3-digit width the value is now
    centred inside the 400-760 band with ~20 px clear of the right edge.
    Cache change: replace ld.spd_x10 (mph*10 fixed-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
    [main.cpp]
2026-05-16 Release v0.1.27: sprite-buffer the dash page's tearing-prone regions
    At 25 Hz Teensy emit, the visible tear-prone elements were exactly the big
    ones: the Font7-size-4 speed digit, the wide RPM bar, the Font4 sensor lines.
    Painting them directly into the panel framebuffer while the LCD scans top to
    bottom produces a visible tear during the per-element draw window.
    Fix: maintain a PSRAM-backed LGFX_Sprite for each of those regions:
    - spr_rpm_bar 756 x 76 inside the static RPM bar border
    - spr_rpm_text 110 x 26 RPM number below the bar
    - spr_speed 360 x 200 huge centred MPH digits (biggest offender)
    - spr_temp/psi/afr 240 x 38 Font4 sensor value lines
    Each f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
    [main.cpp]
2026-05-16 Release v0.1.28: 50 Hz dash redraw + sprite-buffer remaining dash regions
    Now that the biggest tearing-prone elements (speed, RPM bar, sensor lines)
    are sprite-buffered (v0.1.27), restore the dash page redraw rate to 50 Hz.
    The conditional-repaint logic already short-circuits when no cached value
    changed, so the extra ticks cost nothing but keep alert flashes smooth.
    Also expand sprite coverage to the remaining dynamic dash regions:
    - spr_rec_badge REC indicator + queue: N message
    - spr_fix, spr_sats, spr_gps right-column GPS info
    - spr_pred, spr_lap middle-column lap timer
    - spr_track_name active track label
    - spr_recbtn START/S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
    [main.cpp]
2026-05-16 Release v0.1.29: manual UPLOAD button + immediate queue drain
    Add a dash-page UPLOAD button so the user can trigger queued-session
    upload immediately instead of waiting for the next 10 s cloudTick walker.
    Dash side:
    - New button at (210, 155, 180, 70), between START and the speed digit.
    - Visible only when (!recording) && (cloud_queue_depth > 0).
    - Tap sends 'QUEUE,DRAIN' over UART.
    - Sprite-buffered (spr_upbtn) to match the rest of the dash dynamic regions.
    - Label: 'UPLOAD' (Font4) over '<N> file(s)' (Font2). Repaints only on a
    composite tag of (visible | queue_count).
    Teensy side:
    - New command handler for 'QUEUE,DRAIN' that sets drain_queue_now = true.
    - cloudTick() now skips the 10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
    [main.cpp]
2026-05-16 Release v0.1.30: fix compile, periodic SD recheck, gate TESTSTART, upload diagnostics
    v0.1.29 published a stale binary because my one-line bash chain ran git
    add/commit/push regardless of the release.sh exit code. The actual issue was
    a compile error in v0.1.29's handleDashTap: it referenced 'ld' before that
    file-scope global was declared. Fix: drop the cache-invalidation line; the
    next CLD,* line from the Teensy refreshes the button state naturally.
    Two unrelated bugs were colluding to make 'no data uploaded' look like one
    issue:
    1. SDIO can miss a card on boot, especially if the card was inserted while
    the Teensy was already powered. detectSD() ran exactly once at setup() so
    reboot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
    [main.cpp]
2026-05-16 Release v0.1.31: surface upload failure reason, disable auto-upload, gate UPLOAD button
    User feedback from v0.1.30:
    - 'Where does it say the error for uploading? it's still failing.'
    - 'SD card has to be unplugged and replugged in quite often.'
    - 'Also disable the auto upload. Only display the UPLOAD button if we have
    WIFI and we are NOT recording a session.'
    Changes:
    Teensy:
    - emitUploadDone() accepts an optional reason string and emits
    'UPLOAD,DONE,FAIL,<reason>' so the failure cause reaches the dash UI.
    - wupForwardFile() and httpPost() set last_upload_err on every failure path:
    'no WUP,READY (dash silent)', 'WUP NACK,<reason>', 'ACK timeout at line N',
    'no POST result from dash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
    [main.cpp]
2026-05-16 Release v0.1.32: more aggressive SD detect + visible error code on dash
    User reports: SD card shows 'No Card' after reboot even though card is
    physically present and was working before. Existing 4-attempt 50ms retry
    in v0.1.31 isn't enough for their card + slot combo.
    SD detection:
    - detectSD() retries bumped to 8 mount attempts + 4 raw-card probes with
    100 ms delays. Worst-case ~1.2 s budget per detect call.
    - Polling cadence stays at 3 s while status is NONE / ERROR (v0.1.31).
    - When the FAT mount fails, snapshot the SdFat error code (e.g. 0x14 =
    card init timeout, 0x06 = CMD8 fail) and include it in:
    a) USB serial: '[sd] detect FAILED err=0x.. data=0x..'
    b) wire: 'SD,N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
    [main.cpp]
2026-05-16 Release v0.1.33: dash -> Teensy DBG relay + WUP diagnostics
    The v0.1.32 modal reported 'FAIL: no WUP,READY (dash silent)' which means
    the Teensy emitted WUP,START and the dash never replied with READY or NACK
    within 5 s. To diagnose without a USB-attached serial monitor on the dash
    (its UART0 is the bridge to Teensy), add a debug relay channel:
    Dash: Serial.printf("DBG,<text>\n"); // goes to Teensy UART
    Teensy: if line starts with 'DBG,' -> Serial.printf("[dash-dbg] %s\n");
    // -> USB CDC console
    Then sprinkle DBG lines on the WUP path so `pio device monitor` on the
    Teensy USB shows exactly what the dash is doing:
    - D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
    [main.cpp]
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
